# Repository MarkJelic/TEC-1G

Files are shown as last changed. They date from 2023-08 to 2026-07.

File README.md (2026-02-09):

## File Links
| File | Description | Version |
|---|---|---|
| [Errata](./Errata.md) | <b>*CRITICAL:*</b> The latest Errata announcements. **Read BEFORE assembly!** | 2/jun/2024 |
| [Assembly Instructions](./Documentation/Assembly/Readme.md) | Instructions on putting the TEC-1G together | 0.2 |
| [Component Overlay](./TEC-1G_Component_Overlay_v1-21.pdf) | Searchable PDF for component placement. | 1.21 |
| [Parts List](./TEC-1G_PartsList_v1-5.pdf) | (Out of date. Needs updating. Use with caution. Always follow schematic.) | 1.5 |
| [BOM Sourcing](./files/TEC-1G_BOM_v1.5.xlsx) | (Out of date. Needs updating. Use with caution. Always follow schematic.) | 1.5 |
| [Schematic](./TEC-1G_Schematic_v1-22.pdf) | See what makes the TEC-1G tick. | 1.22 |
| [PCB Gerbers](./TEC-1G_Gerbers_v1-50_SigEd.zip) | Gerbers of the PCB so you can print your own! | 1.50 |
| [Monitors / ROMs](./ROMs/) | Download and burn the ROMs for your TEC-1G from this link! | 1.6 |
| [MON3 User Guide](./MON3_User_Guide_v1-6.pdf) | The comprehensive User Guide to MON3 | 1.6 |
| [TEC Deck](./TEC-Deck/) | The TEC Deck has multiple Cards that add major functionalityto the TEC-1G! | 1.2 |
| [GPIO Modules](./GPIO/) | See what modules can be attached to the GPIO connector on the LHS of the TEC-1G | 1.0 |
| [TEC Expander](./Expander/) | The Expander finally has the 8x8 LED Array... And it's in RGB! | 1.0 |

## News & Developments

We have added a new section to the GitHub that agregates all the news and new items for the TEC-1G. [Follow this link](https://github.com/MarkJelic/TEC-1G/tree/main/News) for all the latest info.

# TEC-1G Introduction

TEC-1G - A Z80 based single board computer.

The TEC-1G is a direct descendant of the Talking Electronics Computer, known as the TEC-1, which was first published by the Australian electronics hobbyist magazine ["Talking Electronics"](https://www.talkingelectronics.com/te_interactive_index.html) (or simply TE), between 1981 and 1991.

The TEC-1 was developed as a learning computer, designed to teach the basics of how a microprocessor works at the fundamental hardware and software level, and offered the ability to create and run simple programs in Z80 machine code. TE magazine covered the TEC-1 in six installments, known as "Issue 10" to "Issue 15". These magazines can be downloaded freely from the TEC-1 GitHub, located at [tec1group/TE-Magazines](https://github.com/tec1group/TE-Magazines)

Interest in the TEC-1 declined following the winding down of TE through the 1990's, which reflected a general decline in electronics as a hobby in Australia. This, coupled with interest in more advanced 'single chip' microcontrollers saw TEC-1's put aside and the world moved on.

The TEC-1 was revived around 2018 with a release of a reproduction PCB and related peripherals on the Internet. Retro computing has become quite popular of late, and so a an active TEC community has (re)formed through [Facebook](https://www.facebook.com/groups/tec1z80) with new hardware designs, enhanced versions and various expansion options being offered by various contributors within the community.

The 1G builds on both the TEC-1's base and recent history to modernize the overall design, address various design limitations and integrate many of the excellent add-ons into to a single PCB for the first time.

The TEC-1G remains true to the original TE design goals: it is is built using only simple through-hole TTL logic chips so it is easily built and understood by the hobbyist. For the first time, the TEC-1G will also be fully free and open source, in both its hardware and software. The TEC-1G is the ultimate TEC-1!

The 1G has been developed by Mark Jelic with the input of the original designers, John Hardy and Ken Stone, ex-TE staff member Craig Hart, along with contributions from community members Brian Chiha and Ian McLean. Finally, the 1G has also been produced with the blessing of Colin Mitchell, Talking Electronics owner.

## Major Features

- Full TEC-1 hardware and software compatability; runs all previous MONitors without modification
- Flexible memory options; 32K RAM, 16k ROM in default configuration. Up to 64k RAM + 16k ROM supported.
- Support for multiple configuration options and memory types from 2k to 32k memory devices
- RAM write protection for improved software development
- Shadow Memory and bank switching capabilities
- 20x4 LCD screen as primary display device
- Diagnostic & LED bar indicator for system state
- Z80A CPU running at 4.0MHz; 'slow' clock support for older monitors retained
- Full QWERTY MATRIX keyboard & joystick options
- Upgraded key options for onboard hex keypad; supports Gateron Low Profile switches with optional backlighting, as well as standard 12mm tactile buttons
- Improved RESET circuit for reliable start up and system stability
- USB B or 9-12v AC/DC power sources
- Serial interface using an optional FTDI/FT232 adaptor for USB communication with a PC or terminal
- Future support for SD card mass storage interface
- Native Z-80 expansion bus connectors supporting a full range of peripherals
- 'TEC-Deck' expansion connectors for future daughterboards
- 'TEC Expander' port for compatability with existing TEC peripherals
- HALT status LED

## More Documentation [Coming Soon™](/Documentation/readme.md)

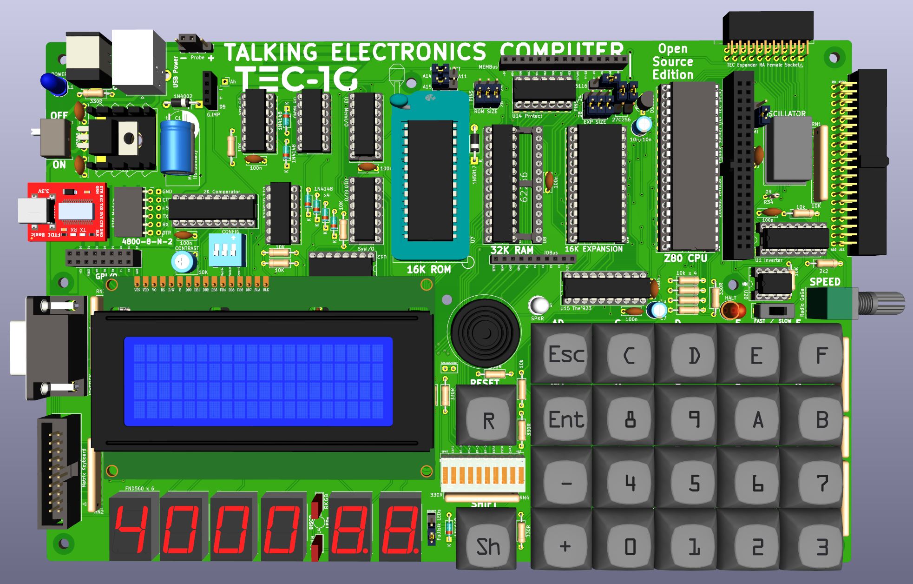
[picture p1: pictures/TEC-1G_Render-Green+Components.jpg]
TEC-1G Render - Gateron Keys


I'd like to thank PCBWay for sponsoring the ongoing development of modules that are being added to the TEC-1G ecosystem. I'm impressed how proactive they are in finding projects like this one and encourage and foster such development. Thank you, PCBWay!

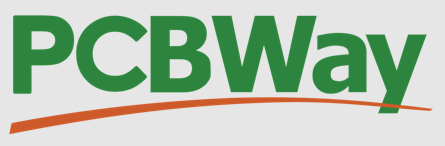
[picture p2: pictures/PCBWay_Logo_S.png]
PCBWay Logo


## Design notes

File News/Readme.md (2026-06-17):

# TEC-1G News
--------------------------------------------------------
## TMS9918 Video Card in Beta Testing (15/Jun/2026)
A video card based on the TMS9918 that sits on the TEC-Deck connectors has entered Beta. "Damian Damian" built it up quick smart and after some cutting and bodging, was able to show a couple of demos.
Check it out on this Facebook post:

https://www.facebook.com/share/v/1BiCaWHnK5/

More details can be had here where you can download the Gerbers and print your own PCB:

https://github.com/MarkJelic/TEC-1G/tree/main/TEC-Deck/TMS9918_Video

Kits for this add-on have not been planned for, at this stage.

--------------------------------------------------------
## 4Layer Version of Main PCB in Testing (21/May/2026)
The first ever 4 layer version of the TEC-1G PCB has arrived and going through testing.

Features include:
 - ability to use either through-hole or SMD versions of components like resistors, capacitors, diodes, transistors and IC sockets.
 - Four layers of copper, two of which are inside the PCB and a ground planes to provide shielding.
 - Thinner tracks and optomised routing since the GND traces are all but gone to the inner GND copper pour.

Once testing is complete, users will have the choice of the original 2 layer PCB which has proven to be pretty noisy for any audio amplfication, or the new 4 layer PCB, which does cost more, but has improved noise suppression.

Longer term plans include providing kits that have all the SMD components pre-installed, in the hopes of cutting the build time down from 3-4 hours, down to 20-30 minutes.

--------------------------------------------------------
## Official TEC-1G 3D Printable Case (10/March/2026)
The official TEC-1G case is made available. Purchase it in digital form for printing on your own #D printing machine or buy it on the Tindie Store which includes the brass heat insets.

https://www.tindie.com/products/tec1/tec-1g-official-case/

--------------------------------------------------------
## Update to Signature Edition PCB Released! (10/Feb/2026)
The Signature Edition PCB has been updated to v1.5 with a few minor quality of life (read: less soldering) changes.

https://www.facebook.com/groups/tec1z80/permalink/2288069601702076

--------------------------------------------------------
## Multi-Tasking on the TEC-1G! (27/Oct/2025)
Brian Chiha releases a video showing the TEC-1G doing effective multi-tasking!

https://youtu.be/tMYGlYO3v9U

--------------------------------------------------------
## A new version of the Tactile Matrix Keyboard! (19/Aug/2025)
A new version of the Tactile Matrix Keyboard has been release to give the user a better typing experience and move the connector to the side so that cable tangles are a thing of the past.  Stickers have also been developed and are available to buy on Tindie.

https://www.tindie.com/products/tec1/tec-1g-matrix-tactile-keyboard/

--------------------------------------------------------
## Signature Edition Gerbers Released! (15/Mar/2025)
The Signature Edition of the TEC-1G PCB is the final version of the TEC-1G PCB to be released.
The Gerbers can now be downloaded from the root directory of the Repo.

--------------------------------------------------------
## ODE to TEC-1G Song! (12/Mar/2025)
Ken Stone has applied his masterful Musical and AI-Wrangling skills to turn John's poem into a catchy song!

https://github.com/MarkJelic/TEC-1G/blob/main/News/ODE_to_TEC-1G_by_John_Melville_(Ken_Stone).m4a

--------------------------------------------------------
## ODE to TEC-1G by John Melville (11/Mar/2025)
John has penned a brilliant poem about the 1G. Check it out:

https://github.com/MarkJelic/TEC-1G/blob/main/News/Ode_to_1G.md

--------------------------------------------------------
## TEC-1G RGB 8x8 Display (10/Mar/2025)
The first add-on ever developed for the original TEC-1 was an LED 8x8 Matrix Display. 40 years later and the same idea has had new life breathed into it with a full colour RGB module in the tidiest PCB yet design for the 1G, that allows for up to 3 modules chained together. Check the details at<br>

https://github.com/MarkJelic/TEC-1G/tree/main/Expander/8x8

--------------------------------------------------------
## TEC-1G Font Identified! (24/Jun/2024)
The mystery of which font goes into making the iconic TEC-1G logo has been solved by James Elphick.  At first we thought it might have been Posterama 1984 but that is owned by one of the oldest font foundry, Monotype.  James soon found a very close competitor in Montserrat-Alt1 and it is an Open Font typeface.  So in aligning with our ethos, we must have used the Open Source version and we have copied it to this GitHub, in the \Assets folder off the root:<br>

https://github.com/MarkJelic/TEC-1G/tree/main/Assets

--------------------------------------------------------
## Fullisik Mechanical Matrix Keyboard Released! (18/Jun/2024)
Designed by James Elphick, following the design of the Tactile Matrix keyboard, the new Fullisik Mechanical Matrix Keyboard goes on sale today, and is sold out befor the weekend is done! Looks and feels fantastic.

--------------------------------------------------------

## MON3 version 1.5 (7/Jun/2024)
Monitor3 has been upgraded to version 1.5 by Brian Chiha. Get all the details here:<br>
https://github.com/MarkJelic/TEC-1G/tree/main/ROMs/MON3

--------------------------------------------------------
## 7 Segment Bezel by "Fred Nichols" (3/May/2024)

Now this is really cool! Fred Nichols has created a 3D printable Bezel that sits over the 7 segment displays. He has kindly released the STL files so you can download it and print it yourself or get a shop to do that for you. Either way, it makes the TEC-1G look really fancy! [Click on this link](https://github.com/turbo-gecko/TEC/tree/main/3D%20Printing/7%20Seg%20Bezel) to take you to his GitHub!

7Seg Bezel 3 Piece Lit

--------------------------------------------------------
## Dedicated TEC-1G Video Channel Launched (27/Apr/2024)
Yes, we know the documentation isn't complete, and even if it were, there are many amongst us that don't do well learning anything by reading text on a screen. Some of us (raises hand) are visual learners and so videos work well for seeing how things are put together.

And that is exactly what the channel will be about. We will announce new upcoming products, have demos of peripherals available for the TEC-1G, highlight any really cool code released by you, the users, and have documentary type videos showing exactly how any board is put together.

We look forward to your feedback and let us know what you would like to see.

https://www.youtube.com/@TEC-1G

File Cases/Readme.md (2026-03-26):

# Cases, Enclosures and Stands

Sick of having you TEC-1G lying on the cold hard bench, with all your tools and parts shorting the underside?

Want to display your beautiful TEC-1G in the best light possible so your friends and family will go "Ooh" and "Ahh" at your cleverness?

Have a 3D printer that has you wondering what you can do with it?

Question no more and pick your favourite design below, download the STL file and elevate your TEC-1G to the height it deserves!

## Stands & Cases Links
| File | Description | Preview |
|---|---|---|
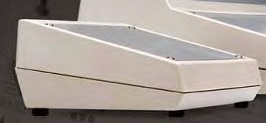
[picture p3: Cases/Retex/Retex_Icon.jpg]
Retex
| [Retex](./Retex/Readme.md) | The original case for the TEC-1 works on the TEC-1G and is still available! |  |
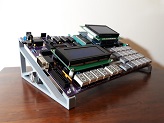
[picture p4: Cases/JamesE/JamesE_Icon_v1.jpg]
JamesE
| [JamesE](./JamesE/Readme.md) | A pair of Stands to elevate your TEC-1G to new heights |  |

If you have the superior brain-power required to create 3D models and have designed something for the TEC-1G,
why not share it with the greater community? You will get your own dedicated page on this GitHub, with full credit to you,
and a permenant place in the history of the TEC-1G. Get in touch with us via our [Facebook Forum](https://www.facebook.com/groups/tec1z80).

### NEWS FLASH:
There is now an OFFICIAL TEC-1G 3D printable case that looks the bees knees and can hold the UPS Battery Pack, as well!
Purchasable as both the physical, printed item delivered to your door, or as a Digital Download for personaly printing.
https://www.tindie.com/products/tec1/tec-1g-official-case/

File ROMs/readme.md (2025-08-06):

## File Links
| File | Description | Version |
|---|---|---|
| [Monitor 3](./MON3/) | The new main Monitor for the TEC-1G written by Brian Chiha| 1.6 |
| [Diagnostics](./DIAGs/) | Test the functionality of your TEC-1G, by Craig Hart | 1.1 |
| [BMON](./BMON/) | Run the first monitor that Brian Chiha adapted for the TEC-1 | 1.3 |
| [MON-1B](./MON1/) | The original, hand-coded monitor for the TEC-1 by John Hardy | 16K |

# ROMs for the TEC-1G

The file list above gives you links to the individual monitors that you can quickly copy to an NVRAM chip
and pop them into the TEC-1G, without having to play around with the ROM size switches.

You can also download the "combined images" that include:
 - 32k has MON-3 and DIAGs
 - 64k has MON-3, DIAGs and MON-1B. (16K is left blank for upgrades.)

## Older ROMs

The TEC-1G is perfectly backward compatible with previous monitors and the 2k/4k ROMs they came on.
To use an old TEC-1 ROM, since they were burnt to either a 2k or 4k ROM in a 24pin package, you simply plug the 24 pin ROM into the upper part of 28pin ZIF socket. See the picture below.
ROM_Select

To enable the 1G to use a 24 pin chip (in either the ROM ZIF, or in the EXPAND socket) you need to set the three Chip Size jumpers appropriately. Move all three jumpers to the top positions for 24 pin chips, and have the jumpers down for 28 pin chips.

The Hi/Lo switch works the same as the original TEC-1, allowing you to select the top half or bottom half of a 4k or 32k ROM.

The images for the 2k / 4k ROMs can be found here on GitHub, but since the 1G now has the space for 32k & 64k ROM chips, we have recompiled the old monitors into 16K file sizes that allows for easy "combining" on burners like the GQ-4x4.

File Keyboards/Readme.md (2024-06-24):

# Keyboards for the TEC-1G

## History
The TEC-1 came out in 1983 and I eagerly built it, and coded many of the samples and even made my own maze game all entered by hand on, lets face it, the crappy mushy keyboard with the terrible layout. 

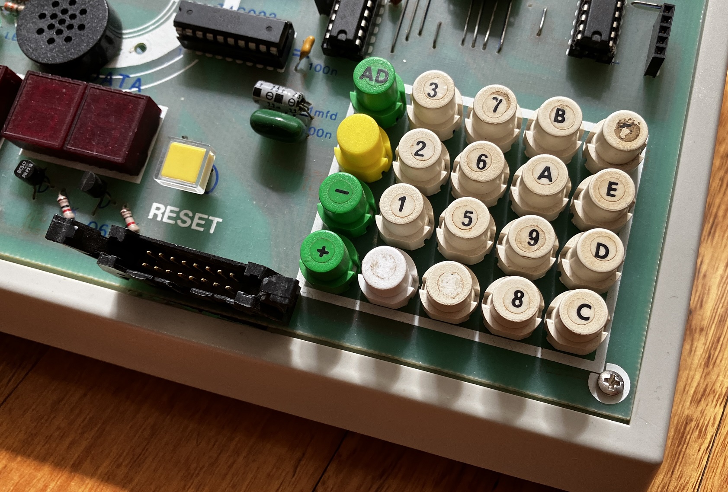
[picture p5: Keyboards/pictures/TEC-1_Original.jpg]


I didn't stand for it for too long before I made my own keyboard out of full sized keys, and hacked in a connector on the motherboard. Still only in hex, but man it made a difference!

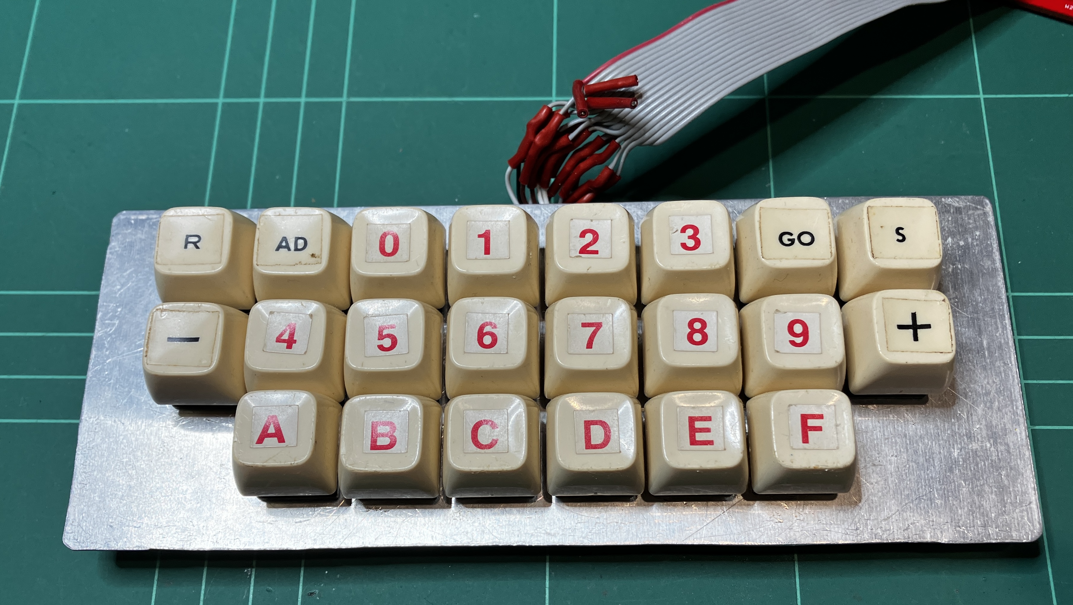
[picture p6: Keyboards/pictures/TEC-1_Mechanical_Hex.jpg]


Fast forward 40 years and the TEC-1G was NOT going to have crappy keys any longer! Discussions with another Keyboard officiando, Ian McLean came to making space on the TEC-1G motherboard to fit full-zized mechanical keys.  We chose to use the Gateron Low Profile 2.0 keys as they were a lot less obtrusive compared to the normal Cherry MX keys. Unfortunately the footprint of the Gateron Low Profiles is NOT the same as a standard MX key, so keep that in mind when buying your key switches.

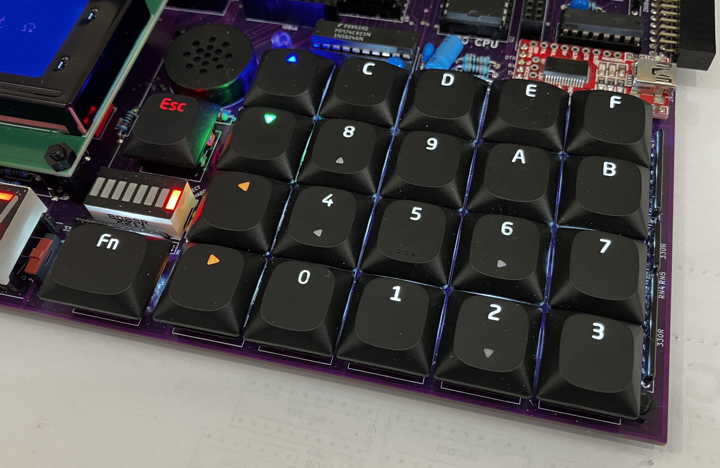
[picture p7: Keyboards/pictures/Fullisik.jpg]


You can purchase the Gateron LP Switches [direct from the Gateron site](https://www.gateron.com/products/gateron-ks-33-low-profile-switch-set?VariantsId=10265).

# QWERTY Keyboards
The TEC-1 never had a full qwerty keyboard option so with the TEC-1G development in mind, I set about finding a suitable interface and keyboard schematic that could be easily integrated into the TEC-1 and fit onto the base motherboard.

## Matrix Interface
The [Matrix Interface](https://github.com/MarkJelic/TEC-1_Hardware/tree/master/Z80Bus/Keyboard) made for the TEC-1 was essentially incorproated into the design of the TEC-1G. More details and code samples can be found on that page.

## The Tactile Keyboard
I created the Tactile version of the Matrix Keyboard that accepted 6mm and 12mm little tactile keys which aren't terrible and relatively cheap. You can get more details of how it was developed, and how to assemble it, [here](./Tactile/)

## The Mechanical Keyboard
The mechanical version of the matrix keyboard has been finished. Details, [here](./Mechanical/)

## Where to Buy
The Tactile Matrix Keyboard Kit can be found on the Tindie Store:  (https://www.tindie.com/products/tec1/tec-1g-matrix-tactile-keyboard/)

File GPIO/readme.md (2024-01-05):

# TEC-1G GPIO Connector

## Expansion Modules available for the GPIO Connector
| Module | Description | Version |
|---|---|---|
| [GPIO Protoboard](./Protoboard/) | The protoboard gerbers & design files - Use as a Template!  | 1.1 |
| [GPIO SD Card](./SD-Card/) | Micro SD-Card interface, as well as a general purpose 8Bit input/output board | 1.2 |
| [GPIO RTC](./RTC/) | Real Time Clock and Parameter RAM  | 1.1 |
| [GPIO Printer](./Printer/) | Parallel Printer Interface, and a general purpose 8Bit input/output board  | 1.1 |

Adding General Purpose Input/Output capabilities to the TEC-1G, easily.



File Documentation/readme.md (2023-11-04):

[Assembly Instructions](./Assembly/Readme.md)

# Full Documentation - Coming Soon™

When designing the TEC-1G, several principals were kept foremost in mind:

1. Must remain compatible with the Talking Electronics TEC family. Older MONitors must run, unchanged, on the new hardware.
2. Existing peripherals must work, where sensible to do so*. Peripherals such as the DAT board, RAM stack & Crystal Oscillator are now part of the base design, as is the MON select switch. The 8x8 LED display, speech module, relay driver board, and the input output module all work.
3. Must address design limitations inherent in older models e.g. memory wrap, lack of IO port selects, elminate 'flying wires', use robust connectors, offer modern interfacing and expansion options.
4. Must remain simple to understand. This forbade the use of fancy custom chips. Everything is built from simple 74xx series logic, that can be understood at the fundamental level.
5. Through-hole construction to be retained. Must be buildable by a hobbyist without specialist tools.
6. Must enable modern software development - adequate RAM, PC serial link, full QWERTY keyboard are must-haves.
7. Existing TEC software should run with as litte alteration as possible.
8. The whole machine will be produced under an open source licence, freely distributable. Source code, schematics, gerbers etc. will all be made available and fully documented. This represernts the first time TEC system software has been freely distributed.
9. The classic, look, feel, operation and overall "vibe" of the TEC heritage must remain obvious. This heritage has informed the PCB layout, for example.

We think we have achieved these goals and produced a TEC that will offer much more value and usability today, compared to the rather limited original machine.

> We decided not to support the EPROM burner or NVRAM add-ons. EPROMs are now largely replaced with EEPROMS and dedicated programmers like the TL866 are cheap and readily available, and do a much better job. The printer/plotter module no longer has the plotter hardware avilable. NVRAM can be plugged directly into the 1G, however we have not allowed for battery backup at this time. 

## Major Features

- Full TEC-1 hardware and software compatability; runs all previous MONitors without modification
- Flexible memory options; 32K RAM, 16k ROM in default configuration. Up to 64k RAM + 16k ROM supported.
- Support for multiple configuration options and memory types from 2k to 32k memory devices
- RAM write protection for improved software development
- Shadow Memory and bank switching capabilities
- 20x4 LCD screen as primary display device
- Diagnostic & LED bar indicator for system state
- Z80A CPU running at 4.0MHz; 'slow' clock support for older monitors retained
- Full QWERTY MATRIX keyboard & joystick options
- Upgraded key options for onboard hex keypad; supports Gateron Low Profile switches with optional backlighting, as well as standard 12mm tactile buttons
- Improved RESET circuit for reliable start up and system stability
- USB B or 9-12v AC/DC power sources
- Serial interface using an optional FTDI/FT232 adaptor for USB communication with a PC or terminal
- Future support for SD card mass storage interface
- Native Z-80 expansion bus connectors supporting a full range of peripherals
- 'TEC-Deck' expansion connectors for future daughterboards
- 'TEC Expander' port for compatability with existing TEC peripherals
- HALT status LED

## Documentation Files

[Circuit Functional Description](Functional%20Description.md)

[Z80 IO Ports](ioports.md)

[Memory Map](memmap.md)

[Expansion and Device Connectors](connectors.md)

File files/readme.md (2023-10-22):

General store of files, including ones that are "archived" (like the schematic) to have a history of changes over time.

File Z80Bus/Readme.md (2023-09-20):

# Z80Bus Expansion Options for the TEC-1G

With the release of the Z80Bus Standard, including the KiCAD footprints and Gerbers so people can print their own Z80Bus system board, modules for the TEC-1 can very quickly and easily be developed that allow the USER to choose how they wish to connect the modules to their machines.

Boards designed with the innovative <b>IDC<sup>2</sup></b> connector footprint allow the user to choose to go hippie and continue to use ugly IDC cables with a Vertical IDC Box Header, or with a Right Angled Box Header, they have the ultimate in freedom to connect using IDC cables, <b>Quick-Connect<sup>®</sup></b> direct to the TEC-1, or using the <b>X4 System</b> and have multiple expansions boards all working in unison.

## [Z80Bus X4 Board](X4/Readme.md)
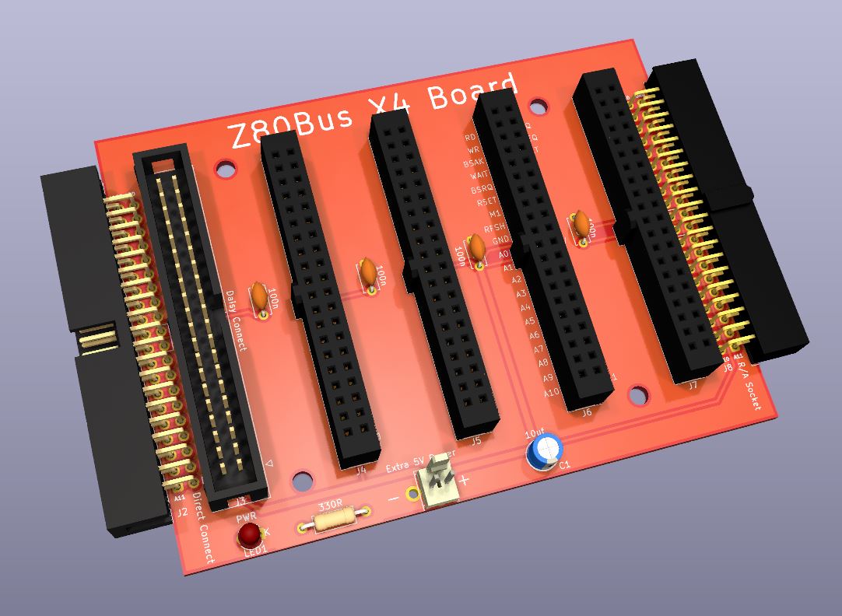
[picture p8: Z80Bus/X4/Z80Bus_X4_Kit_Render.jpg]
Render


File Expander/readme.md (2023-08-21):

# TEC Expander

The easy way to attach your favourite expansions.



## Coming Soon™
- 8x8 LED Matrix

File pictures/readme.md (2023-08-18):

Pictures of renders, prototypes and assembled versions of the TEC-1G.

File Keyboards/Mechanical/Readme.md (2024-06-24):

## Fullisik Mechancial Matrix QWERTY Keyboard

Designed by James Elphick

## File Links
| File | Description | Version |
|---|---|---|
| [BOM](TEC-1G_MechMatrix_BOM_v1.0.xlsx) | Bill of Materials |1.0|
| [Assembly Instructions](TEC-1G_Mechanical_Matrix_Keyboard_Build_Guide.docx) | Instructions on putting the keybaord together | 1.0 |

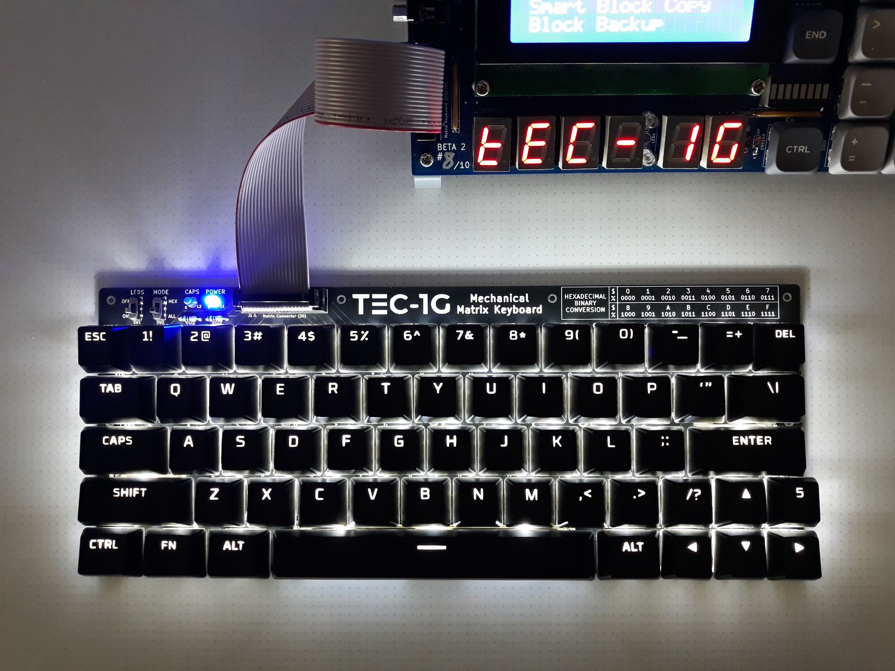
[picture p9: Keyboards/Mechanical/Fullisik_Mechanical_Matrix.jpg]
Mechanical Matrix


Kit is available on Tindie: https://www.tindie.com/products/tec1/tec-1g-matrix-mechanical-keyboard/

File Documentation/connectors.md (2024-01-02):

# TEC-1G Connectors
This is a list of TEC-1G expansion port connectors and their respective pin-outs.

A note on PCB connector orientation markings. Pin 1 is identified as the pin that is not within the solid connector outline on the silkscreen, but instead has a small L on one corner, or is individually outlined. Pin 1 also has a square solder pad, the other pins are round. Lastly, the label of the connector (eg. J1) is usually placed as close as possible to Pin 1.

## J1 - Z80 Bus Vertical Connector
Follows the Z80 CPU pinout i.e. pin 1 - A11, pin 2 - A12, etc. Except for one small difference; Pin 28 is NOT the usual Refresh pin, since that function is largely not used in any modernised Z80 computers. Pin 28 has instead been repurposed for the use of the GLCD as an Inverted RD line from the Z80. 

## J2 - Z80 Bus Horizontal Connector
Follows the Z80 CPU pinout i.e. pin 1 - A11, pin 2 - A12, etc.  This connector should ideally be a female connector to allow for direct connection of expansion cards, or the X4 Expansion Board, and IDC cables can still be connected if the user desires.

## J3 - TEC Expander
This 20 pin port is an extension of the 16 pin IO port of the Southern Cross Computer. Any peripherals made for the SCC can be plugged into the left (first 16) pins and work as intended.

The extra 4 pins have been added so peripherals like the Speech Board can be re-implemented fully, using only a single connector.

1 - +5v  
2- /RESET  
3 - 8x8 Port 05h select  
4 - 8x8 Port 06h select  
5 - Port F8h select  
6 - Port F9h select  
7 - GND  
8 - GND  
9 - D4  
10 - D3  
11 - D5  
12 - D2  
13 - D6  
14 - D1  
15 - D7  
16 - D0  
17 - /WR  
18 - /WAIT  
19 - CLK  
20 - /INT  

## J4 - MATRIX Keyboard
This port is for connecting the external Matrix Keyboard & Joysticks.

## J5 - FTDI
FTDI offers two options - pins orientated left-to-right, and right-to-left. This is because there are two common types of FTDI module - fit the connector that suits your type of FTDI module. Pin orientations are clearly maked on the PCB silkscreen.

DTR - not used<br>
RX - Receive Data<br>
TX - Transmit Data<br>
+5v - not used<br>
CTS - not used<br>
GND - Common Ground<br>

## J6 - IObus
Schematic Rev 1.6+

1 - GLCD-07 - Inverted Port 07h select - Reserved for future Graphical LCD<br>
2 - /PORT-F8 - Port F8h select<br>
3 - /PORT-F9 - Port F9h select<br>
4 - /PORT-FA - Port FAh select<br>
5 - /PORT-FB - Port FBh select<br>
6 - /PORT-FC - Port FCh select<br>
7 - /PORT-FD - Port FDh select<br>
8 - CART - CARTridge Detect<br>
9 - GIMP - General Input<br>
10 - /GLCD-07 - Port 07h select - Reserved for future Graphical LCD<br>

Ports F8h to FDh are free for any use by the user. Note that Ports F8h and F9h are also available on the TEC Expansder Connector.

## J7 - MEMbus
Schematic Rev 1.6+

1 - +5v
2 - /MS8 - Memory Bank 3 Select - does not observe SHADOW<br>
3 - /ROM_CS - Observes SHADOW - First 2K and Bank 3<br>
4 - /SHADOW<br>
5 - /MS2 - Memory Bank 0 Select - does not observe SHADOW<br>
6 - /MS4 - Memory Bank 1 Select - does not observe SHADOW<br>
7 - /RAM_CS - Observes SHADOW - Banks 0 and 1 only<br>
8 - PROTECT<br>
9 - /MS6 - Memory Bank 2 Select - does not observe SHADOW<br>
10 - EXPAND<br>
11 - FF-D3 - System Latch bit 3<br>
12 - FF-D4 - System Latch bit 4<br>
13 - FF-D5 - System Latch bit 5<br>
14 - FF-D6 - System Latch bit 6<br>
15 - GND<BR>

## J8 - G.INPUT
1 - GND<br>
2 - +5v<br>
3 - G.INPUT signal - SIMP-3 bit 5<br>

## J9 - JOYSTICK
The joystick port adheres to the ATARI joystick standard, supporting two fire buttons.

1 - Up<br>
2 - Down<br>
3 - Left<br>
4 - Right<br>
5 - <br>
6 - Button A<br>
7 - Button B<br>
8 - Common<br>
9 - <br>

## J10 - GPIO
This is where the SD Card, Real Rime Clock, and General Input/Output cards will be stacked.

## PROBE
This set of connectors have a 2 pronged purpose; The outer male pins are for connecting Oscilloscope or Multimeter probes to, for measuring and testing purposes. The pair of inner pins, fitted with a 2-pin female header, is used for alternate power delivery, as well as a power take-off point for the boards connected to the J10 - GPIO connector.

## LCD1
Connector for a standard HD44780 LCD display. TEC-1G expects a 20x4 display, but any HD44780 based screen will work.

1 - GND  
2 - +5v  
3 - Contrast (10k trimpot)  
4 - RS (A7)  
5 - R/W (RD)  
6 - E  
7 - D0  
8 - D1  
9 - D2  
10 - D3  
11 - D4  
12 - D5  
13 - D6  
14 - D7  
15 - Backlight A  
16 - Backlight K (GND)  

# Connector <-> IO Port assignment
This chart shows which Z-80 I/O port select lines are available on each I/O connector.

| Connector | 05h | 06h | F8h | F9h | FAh | FBh | FCh | FDh | FEh | FFh |
| -- | -- | -- | -- | -- | -- | -- | -- | -- | -- | -- |
| IObus |  -- | -- | YES | YES | YES | YES | YES | YES | -- | -- |
| TEC Expander |  YES | YES | YES | YES | -- | -- | -- | -- | -- | -- |
| GPIO |  -- | -- | -- | -- | -- | YES | YES | YES | -- | -- |
| TEC-1G |  -- | -- | -- | -- | -- | -- | -- | -- | YES* | YES* |

\* Used on the TEC-1G mainboard internally. Not available for expansion boards.

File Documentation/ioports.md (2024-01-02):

# TEC-1G Z80 I/O Ports

The following technical documentation describes the general layout of the TEC-1G's Z80 CPU I/O ports, as accessed by the IN and OUT instructions.

If you are looking for physical pinouts of the TEC-1G port connectors, please refer to other documentation from the index.

## TEC-1 Compatable IO Ports

** Note that the IO port decoder chip for ports $00 to $07 does not check bit D7 - hence I/O ports $00 to $07 are also available as ports $80 to $87. This is for various 2-port devices like the LCD and GLCD, as well as older model TEC compatability.

### Port 00 - Keyboard data input
 - bits 0-4 - binary keypressed value from the 74c923 chip
 - bit 5 - Shift key status
     - 0 = Shift Key Pressed  
 - bit 6 - not connected
 - bit 7 - not connected

### Port 01 - 7-seg display select & speaker output
 - bits 5-0 selects each 7-segment display, bit 5 = left, bit 0 = right
 - bit  6 - FTDI serial output
 - bit  7 - speaker output

### Port 02 - 7-seg segment select output
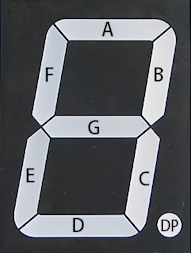
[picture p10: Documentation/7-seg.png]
7-Seg display segment layout


 - bit 0 - segment a
 - bit 1 - segment f
 - bit 2 - segment g
 - bit 3 - segment b
 - bit 4 - decimal point
 - bit 5 - segment c
 - bit 6 - segment e
 - bit 7 - segment d

### Port 03 - General SIMP Input
 - bit 0 - config bit 0 - Matrix
     - Matrix keyboard enabled for use in MON-3
 - bit 1 - config bit 1 - Protect
     - Memory protection enabled in MON-3
 - bit 2 - config bit 2 - Expand
     - Indicates which half of a 32k memory device installed in Bank 2, MON-3 should enable by default
 - bit 3 - EXPAND
     - Indicates which half of a 32k memory device installed in Bank 2 is presently selected
 - bit 4 - CART
     - 0 = a ROM/RAM cartridge is installed. Read from IOBUS connector
 - bit 5 - GIMP
     - General purpose input-bit, connected to G.INPUT pin
 - bit 6 - KDA
 -   - 0 = 74c923 key is pressed
 - bit 7 - FTDI serial input

### Port 04 - LCD Display command
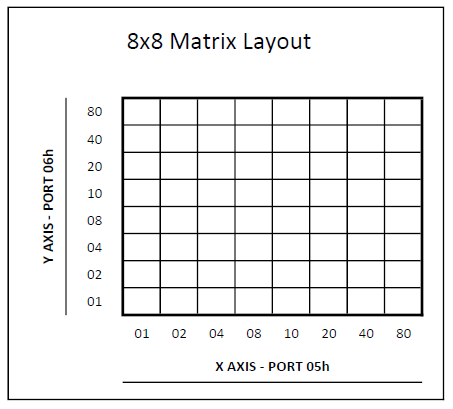
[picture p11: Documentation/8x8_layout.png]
8x8 display port layout

 - bits 0-7 - LCD command register

### Port 84h - LCD Display data
 - bits 0-7 - LCD data register

### Port 05 - 8x8 X axis display latch
X axis

Bit 0 is the left most column

### Port 06 - 8x8 Y axis display latch
Y axis

Bit 0 is the bottom most row

### Port 07 - GLCD port
 - Reserved for future 128x64 Graphic LCD

** Ports $80 to $87 are duplicates of ports $00 to $07.

## TEC-1G New Ports
These are new additions to the 1G, not found in previous TEC models.

### Port FCh - GPIO Real Time Clock
Reserved for DS1302 RTC chip

### Port FDh - GPIO SD Card
Default port for SD Card adaptor

### Port FEh - Matrix Keyboard Input
** This port is used to read the state of the matrix keyboard, to determine if a key is being pressed or not. See the section on the Matrix keyboard for more details on how to use port FEh correctly.

 - bits 0-7 - key state

### Port FFh - System Latch
** This register defaults to $00 at power-on and reset.
** this is a write-only register, however key status bits can be read from the SIMP input port to determine the current system configuration state.

** Each bit of this port is also represented on the LED STATUS bar, with bit 0 being rightmost. Note that bit 0, being active low, will be lit at power-on and reset.

 - bit 0 - /SHADOW
     - 0 = Shadow enabled. The first 2k of ROM at $C000 is also mapped to $0000 - $07FF for backwards compatibility with old MONitors.
     - 1 = Shadow disabled. The full 32k of RAM is avlilable from $0000 to $7FFF
 - bit 1 - PROTECT
     - 0 = RAM memory operates as normal read/write memory
     - 1 = Bank 1 of RAM memory ($4000 to $7FFF) is write-protected
 - bit 2 - EXPAND
     - controls which half of a 32k memory device installed in Bank 2 is presently selected. Defaults to the lower half at power on
 - bit 3 - FF-D3 - The next 4 bits are most likely going to be used for Paged Memory expansion, allowing for up to 512k extra memory.
 - bit 4 - FF-D4 - But they are open to be used as users see fit when designing TEC Decks.
 - bit 5 - FF-D5 - Possible Paged Memory use.
 - bit 6 - FF-D6 - Possible Paged Memory use.
 - bit 7 - CAPS
     - This bit relates to the Matrix keyboard
     - 0 - Caps lock is OFF
     - 1 - Caps lock is ON

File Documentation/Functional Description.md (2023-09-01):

# TEC-1G Functional Description

Also known as "how it works".

When designing the TEC-1G, several principals were kept foremost in mind:

1. Must remain compatible with the Talking Electronics TEC family. Older MONitors must run, unchanged, on the new hardware.
2. Existing peripherals must work, where sensible to do so*. Peripherals such as the DAT board, RAM stack & Crystal Oscillator are now part of the base design, as is the MON select switch. The 8x8 LED display, speech module, relay driver board, and the input output module all work.
3. Must address design limitations inherent in older models e.g. memory wrap, lack of IO port selects, elminate 'flying wires', use robust connectors, offer modern interfacing and expansion options.
4. Must remain simple to understand. This forbade the use of fancy custom chips. Everything is built from simple 74xx series logic, that can be understood at the fundamental level.
5. Through-hole construction to be retained. Must be buildable by a hobbyist without specialist tools.
6. Must enable modern software development - adequate RAM, PC serial link, full QWERTY keyboard are must-haves.
7. Existing TEC software should run with as litte alteration as possible.
8. The whole machine will be produced under an open source licence, freely distributable. Source code, schematics, gerbers etc. will all be made available and fully documented. This represernts the first time TEC system software has been freely distributed.
9. The classic, look, feel, operation and overall "vibe" of the TEC heritage must remain obvious. This heritage has informed the PCB layout, for example.

We think we have achieved these goals and produced a TEC that will offer much more value and usability today, compared to the rather limited original machine.

> We decided not to support the EPROM burner or NVRAM add-ons. EPROMs are now largely replaced with EEPROMS and dedicated programmers like the TL866 are cheap and readily available, and do a much better job. The printer/plotter module no longer has the plotter hardware avilable. NVRAM can be plugged directly into the 1G, however we have not allowed for battery backup at this time. 

# Hardware Design Building Blocks

The TEC-1G can be broken up into several sections or *building blocks*, and each considered individually as to how it plays its role in the overall system.

Together, each building block forms the complete TEC-1G. Some building blocks such as the Matrix Keyboard are optional whilst others are essential.

If your 1G does not work, check each section in the order given below.

A special diagnostic ROM is being produced to assist wih problem solving if your 1G doesn't work correctly when first built. Much like the Commodore 64 'Dead Test' cartridge, the diagnostics software will produce a useful output even wthout any RAM, keyboard chips or the LCD fitted. This will allow for easier troubleshooting and also gives a degree of insight into the machine's operation.

## Power Supply

The TEC-1G is designed to be powered by an external USB +5v source; a USB-B socket for power only, is therefore provided. A classic TEC-1 style linear 7805 based power supply has also been provided, however its use is depreciated.

Power is switched automatically from USB to linear using a switch built into the linear power input socket BJ1 - as long as a plug is inserted into BJ1, linear power mode is selected. BJ1 is centre positive, in keeping with the most common standard for small DC plugpacks.

**The TEC-1G is also designed for DC power input only.** D0, the 1N4002 power diode, is only designed to protect against reverse polarity, and not to act as an AC rectifier.

The power on/off switch and indicator LED complete the power supply section.

Note that we strongly suggest a heatsink on the 7805 and some monitoring of its temperature. The 1G has more chips to power vs. a classic TEC-1, so the current consumption will be higher. The 1G PCB is also more crammed full of goodness so there is also less space for copper fill heatsinking as well. Reducing the input voltage from 12v to 8v or 9v will lower the 7805 temperature noticably.

It is suggested that a drop-in 7805 equivilant switching regulator be considered if USB power is not viable.

The Probe connector supplies power for a logic probe, and serves as the GND hookup point for an oscilloscope or multimeter. Probe can also be used as a feed-in source of an external +5v supply if the 1G is to be powered by an external source.

## CPU Clock Generation

CPU Clock is generated either by a crystal oscillator module, or the classic TEC-1 variable speed oscillator, built around U1, a 4049 hex inverter.

Clock mode is selectable with slide switch SW2 - Slow being TEC-1 variable clock, and FAST being the Crystal module. The selected signal is fed to the Z80 on pin 6, and can be checked with a logic probe or oscilloscope.

MON-3 is written with a 4.0MHz crystal in mind - which is the maximum clock speed of the Z80A CPU. This speed defines the FTDI serial baud rate, 7-seg scanning rate, sound note pitch and duration, etc.

The 1G has not been tested above 4.0MHz but should work OK at up to 8MHz with a Z80H CPU; however FTDI serial, timing etc. will be affected.

## CPU RESET Signal

The traditional R-C network for CPU RESET is offered as standard, however the option exists for using a dedicated power monitor/reset chip - the Dallas DS1233. Further more, the latch chips that rely on the RESET are now driven by a buffered RESET signal, provided by U5D.

RESET is active low, so the signal should be low when the RESET button is pressed, and high at all other times. Reset is fed to pin 26 of the Z80, and via U5D to pin 1 of the 74xx273 latches U13, U16 and U17.

## Z80 CPU

The Z80 CPU, U2, is configured identially to the TEC-1 and is quite conventionally set up. Any Z80 rated to at least 4.0MHz will work - NMOS or CMOS types both work, so Z80A, Z80B, Z80H, Z84C00x parts in 40-pin 5v DIP package, are fine.

An LED - L2 has been added to the HALT signal as an aid to troubleshooting and to provide and easy to monitor output for debugging purposes. the HALT LED should normally NOT light up duing MON-3 opreration.

The programmer can insert HALT opcodes where possible program trouble exists, and if the LED comes on, you can know that program flow reached a HALT point. Pressing a 74c923 key typically resumes program flow. This can be handy for quickly troubleshooting conditional JPs, for example.

## IO Decoders

U10 duplicates the TEC-1's traditional 74LS138 IO decoder, decoding IO ports 00 to 07. However the 1G has the addition of a diode OR-gate formed from D3,D4,D5, D6 and R12. The OR-gate ensures that no unwanted IO address wrap-around occurs. 

U11a and U12 work to decode IO address range F8h to FFh, in support of new onboard peripherals and future expansion.

## Memory Decoder & Memory Managment Unit

### Memory Address Decoders

U3 acts as a memory address decoder, providng select lines for eech 16k memory block.

D1, D2 and R11 form a NOR gate to create a select signal to the MMU indicating the bottom 32k is being accessed.

U4 acts as a 7-input comparitor, detecting if the bottom 2k of memory is being accessed: A11 to A15 must be all low, but only when /SHADOW is also active (also low). This signal is used as another input to the MMU.

If /SHADOW is low, U4 outputs (on pin 19) a low whenever memory in the first 2k 000h to 07ffh is accessed. If /SHADOW is high, the output is always high.

### Memory Management Unit (MMU)

U5A, B & C and U6 A, B & D form a simple MMU controlling the Bank 0, 1 and 3 /Chip Select lines for the memory chips U7 and U8.

Note that Bank 2 is not part of the MMU and appears at address 8000h to BFFFh at all times.

<Insert MMU truth table here>

## Memory Protection

U14 detects memory writes to bank 1 in combination with the PROTECT signal, and either passes or blocks the /WR signal to the RAM chip.

If PROTECT is high, /WR is held high when bank 1 is accessed. If /PROTECT is low, /WR is passed to the memory chip normally.

## ROM and RAM

U7 is the system ROM containing MON-3 or any earlier TEC monitor. This can be any (E)EPROM from 2k to 32k in size, and it is mapped to bank 3 at all times; the first 2k is also mapped to the start of bank 0 (0000h to 07FFh) when shadow is active.

The ROM SIZE Jumpers map the various address lines and the Hi/Low switch allows for TEC-1 Hi/Lo (MON1B/2) selection when a 4k 2732 chip is used; when a 32k chip is used it selects which half of the chip is mapped into Bank 3 (the other half of the chip is inaccessible).

If burning your own ROM, place older monitors at the start of the ROM, from 0000h onwards, so that they will be SHADOWed to 0000h.

U8 is the primary system ram, mapped to banks 0 and 1, and subject to the above SHADOW and PROTECT controls.

U9 is the expansion memory socket, and is mapped always into bank 2. Any memory chip from 8k to 32k can be fitted here; if a 32k chip is fitted then bankswitching using the EXTEND signal selects which half of the memory is mapped into bank 2 (the other half is inaccessible ; flip EEXTEND to ge tto the other half).

EXTEND has no affect if a memory device of less than 32k in size is fitted at U9, or if U9 is left vacant.

## HexPad Encoder

This part of the 1G is unchanged from the TEC-1. The 74c923 scans a matrix of 20 keys and generates a high on KDA when a key is pressed. Keyboard support is also identical to the TEC-1 with DAT board - bit 6 of port 03h holds keypressed status, thus allowing software polled keybord support. for this reason, the famous JMON resistor is not required.

Shift key support functions identially to the TEC-1, with bit 5 of port 00 reading a 0 when Shift is pressed, and a 1 if not.

Fulisik LEDs is a new feature of the 1G - if using Gateron keyswitches, LEDs can be fitted to backlight the keys; JP5 controls the backlights on/off. Resistor packs RN4, RN5, RN6 and 330R resistors R5 and R15 complete the LED current limiting. Refer to the assembly guide for suggested LED colours for each switch.

Note that RN4,5,6 & R5 and 15 can be omitted if not using backlighting.

## 7 Segment Display Unit

This unit is also largely unchanged from the TEC-1.

Latch chips U16 and U17 drive the 7 segment displays in a software-driven, scanned fashion. Each individual display is briefly selected and it's segments illuminated. After a brief pause, software then moves to the next display and repeats the process until all are lit. A loop repeats the whole sequence for as long as required. The illusion of constantly lit displays relies on a fast scanning speed and human persistance of vision. 

U17 drives the individual segments, whilst U16 selects the digits and also drives the speaker and FTDI Serial Transmit.

A simple transistor buffer ensures each display has an equal brightness level; no current limiting resistors are required as the output current of the latch chips is not sufficient to over-drive the LEDs.

The speaker features an LED to indicate when a sund is being produced, and can also act as a simple visual status indicator when driven by software.

A new 1G featue, is that pin 1 of the latch chips is driven by the buffered RESET signal. This ensures the displays start up blank, and also blane when RESET is pressed.

## LCD Connector

The 1G uses a similar interface idea to the TE DAT board, with support for any HD44780 chipset based LCD screen. However, we have settled on using a 40x4 display instead of the DAT's 16x2. The larger size screen offers more display space and these days is less expensive than the original 16x2's were in the 1990's.

Backlight power is also supplied, but can be disbled by cutting a marked trace on the rear of the 1G PCB. 'solder blob' pads have been provided to restore power if you wish to un-do this decision later - just solder the pads back together with a small blob of solder.

At the design level, the 1G inverts the CPU's /RD signal to generate the R/W signal for the LCD. This results in more favourable timing vs. the DAT board's use of an R-C network and the /WR signal. The LCD is more reliably detected and less prone to corruption using this method. We borrow one spare 4049 inverter gate from U1 for this purpose.

MON-3 will work with ANY size LCD e.g. 16x1, 16x2, 20x2 etc. but we strongly suggest that a 40x4 is used to obtain full functionality.

JMON will work with a 16x2 or 40x4 connected, with no issues. The HD44780 chipset is designed such that it's memory layout is identical regardless of the physical screen size.

## System Latch Port

A new 1G feature, is the system latch. It is an 8-bit write-only port that supplies 8 individual control signals to various parts of the 1G mainboard. The system latch is reset to 00h on power up or RESET.

U13 - 74xx273 provides the System Latch functionality and is written to at IO port FFh

The System latch controls /SHADOW,  PROTECT and EXPAND signls, as well as Caps Lock status for the Matrix keyboard. The status of the System Latch is reflected at all times in hardware by the STATUS LED Bar. Note that bit 0 is active low.

MON-3 routines manage the latch for you, however you can write to port FFh direclty if so desired.

## System Input Port

Another enhanced 1G feature, is the System Input port. Like the System Latch, it is an 8 bit port, however this port is read-only.

U18 - 74xx373 provides the Input port functionality and is readable from IO port $03

The Sytem Input port is used to read the status of the critical bits of the System Latch, as well as read the config dipswitch, G.INPUT and FTDI Serial Receive bits, and to detect the presence of a Cartridge (future feature).

## FTDI Port

The FTDI port acceps a standard FTDI module (purchased separately) that converts TTL signals from the 1G into RS-232, or, USB. This provides a simple software driven interface to a PC or a terminal, for data transfer or creating a 'dumb terminal'.

FTDI replaces JMON's tape routines as a backup system; MON-3 supports data transfer using Intel HEX format files and can also provide a full blown RS-232 serial terminal interface.

FTDI speed is limited to 4800bps as it is entirely software-driven and also relies on a 4.0MHz CPU clock for timing purposes. FTDI will not work with the TEC-1 slow clock.

## Matrix Keyboard and Joystick

Also new to the 1G, is a software scanned full QWERTY keyboard and two button joystick port.

U19 - 74xx245 buffers(not latches!) the keyboard matrix and is readable at IO port FEh; the matrix is scanned by use of a clever trick using the Z80 OUT (C),A instruction. In reality that instruction also places the contents of the B register onto A8-A15, creating effectively a 16 bit port.

Transistor buffers Q8 through Q15 buffer the address lines into the matrix, and any pressed key transmits that signal into U19 latch. note that a keypress is read as a 0 in any bit. Resistor arrays RN2 and RN3 ensure the no-pressed state is read as a logic 1.

The matrix connector also has facility for the Caps Lock signal to light a LED, and the Reset signal for an external reset switch.

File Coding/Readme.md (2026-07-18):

# Development Options for the TEC-1G

If you are wanting to get the most out of your TEC-1G, then just playing with other people's software isn't all there is to it.

The whole purpose of the TEC-1, from it's inseption, was to be a "learning computer", that would teach the user how computers work, 
and how to take full control of them. Knowing how to put the hardware together is one part of the process, but learning how to 
program the TEC-1 is even more important, as it is with any computer system. Without software, the computer is just a hunk 
of metal and plastic that won't do anything.

## Common Terminology and Tools
1. $\color{green}{\textsf{Code Editor}}$ 
2. $\color{green}{\textsf{Assembler}}$ 
3. $\color{green}{\textsf{Serial Terminal}}$ 

You create your code in the $\color{green}{\textsf{Code Editor}}$ like you do any text file, but of course it needs to be formatted in the correct way, and you must use the language the Z80 will understand. Once you have your program all typed in, you convert the (relatively) human-readable Assembler Code into the bytes of Machine Code that the Z80 actually understands. This conversion is done by the $\color{green}{\textsf{Assembler}}$ which it saves these bytes into the Intel .HEX file format on your hard drive. Inside the .HEX file is just text, but it has some aditional information like where in memory are the bytes it holds to be placed in the TEC-1G. The last task is to transfer that HEX file using a $\color{green}{\textsf{Serial Terminal}}$ via a USB cable to the TEC-1G.

## Code Editor

You can use just about anything as your code editor, as Z80 Assembly language is nothing more than a text file but with a .Z80 or .ASM file extension. So you could, if you like to suffer, use Notepad or TextEdit or even Word... But there are much better alternatives out there and dispite Microsoft trying really hard to ruin it, VS Code is a preferred option amongst many coders in many programming languages.

One of the best parts of VS Code are the myriad of Extensions available for it, and the ones we want are:
- Z80 Assembly by Imanolea. This colours your code to make it more readable, AKA Syntax Highlighting.<br>
<br>
- Z80 Macro-Assembler by mborik. A great helper for when you assemble your code.<br>
<br>

## Assembler

This is where the options really broaden out and everyone will have a favourite and it will be the hill they die on! It also very much depends on which OS platfrom you are on, as most are not cross-platform and many only have Windows binaries, which is disapointing.

In an effort to simplify and unify this piece of the puzzle, so that code that is released on this site can be compiled on any platform, we have chosen to standardise on using ASM80. This compiler can be used in any Internet Browser on any platform by visiting www.asm80.com

It has an integrated Code Editor as well, but it won't take you long to realise this is a slow and cumbersome way to develop code and upload it to the TEC-1G.

Thankfully the developer has released the assembler engine as a Node.js applicaiton which means that ANY platform should be able to install it and then use it from the command line. This means it can be integrated into VS Code as a command line assembler that you can initiate with a single keystroke. Detailed instructions for each of the three main platforms are below.

CoolTerm Download

Please consider donating to the ASM80 project so development can continue.

## Serial Terminal

This is yet another polarising piece of the puzzle with everyone having their favorites but in an effort to make it possible for the community to help each other, we have chosen to support [CoolTerm](https://www.freeware.the-meiers.org) because once again, it is available on all the major plaforms.

The Serial Terminal Software allows you to send and receive files to and from the TEC-1G via the USB cable connected to the FTDI module.

## Pick Your Poison
So all three key ingredients (Editor, Assembler and Terminal) are available on all three platforms, but of course each takes a slightly different way to install it. Below are the detailed Installation instructions for each major Desktop Platform.  If any of the links are broken, please let us know, and in the meantime use AI to find the corrected/moved links.

## MacOS
*Code Editor* <br>
VS Code is downloaded from: https://code.visualstudio.com/Download<br>
Install it as per normal by finding it in your **Downloads** folder, double click and then simply drag the VS Code app into your **Applications** folder. (You gotta love how easy MacOS makes it!)

*Assembler - Part 1* <br>
Install Node.js: https://nodejs.org/en/download<br>
You can try the manual installation instructions but the Prebuilt version simplifies the process. Simply select your platform and type of processor and then select the "MacOS Installer (.pkg)". This will download the installer to your Downloads folder. Double click on it to start the install process.

At the end it will pop up is message:
"Make sure that /usr/local/bin is in your $PATH."  You do that in the **Terminal** with a simple command:

```console
echo $PATH
```
Search for '/usr/local/bin' and if it is there, you are golden. If not, ask Grok how to add it in.

*Assembler - Part 2* <br>
Now that Node.JS is installed, it is very easy to install the actual ASM80 Assembler. Keep **Terminal** open and enter in this command:

```console
sudo npm install -g asm80
```
It will ask you for your Mac password. Enter it to continue.  Once it is finished, test that it is working by entering:
```console
asm80 --help
```

*Serial Terminal* <br>
CoolTerm is is cross platform and easy to install on the Mac. Download it here: https://www.freeware.the-meiers.org/<br>
Open the DMG in your **Downloads** folder, drag and drop it into your **Applications** folder. Easy peasy.

### Linux
*Code Editor*<br>
Download the VS Code binary from:  https://code.visualstudio.com/Download <br>
Follow these instructions: https://code.visualstudio.com/docs/setup/linux <br>
Which tells you to:
1. Go to Downloads folder and Right Click blank area and select "Open in Terminal"
2. Enter "sudo apt install ./<filename.deb>"  (Yes, you really do have to put in the dot and the slash)
3. It will ask you for your password. Enter it to complete the install.
4. Open the Mint Menu and type "VS" to find VS Code. Right Click and "Add to Panel" so it is easy to find and Start.
5. Once VS Code is installed and running, add in the Extensions.

*Assembler*<br>
Install Node.JS - https://nodejs.org/en/download/package-manager<br>
- installs nvm (Node Version Manager)<br>
curl -o- https://raw.githubusercontent.com/nvm-sh/nvm/v0.39.7/install.sh | bash<br>
- download and install Node.js (you may need to restart the terminal)<br>
nvm install 20<br>

*Serial Terminal* <br>
Download CoolTerm from: https://www.freeware.the-meiers.org/<br>
Extract All to the Downloads folder. Go into that folder and then "Open in Terminal"<br>
Type in:  <br>
sudo mkdir /usr/bin/CoolTerm   (you will be asked for your password)<br>
sudo cp * /usr/bin/CoolTerm -r -f<br>
Close the Terminal window. Browse to the folder /usr/bin/CoolTerm<br>
Double click "coolterm" program<br>
Dialogue box asking to set preferences comes up. Do so (I did) or select Defaults.<br>
Once running, go to Mint Menu, type in "Cool". Right click on menu item and select "Add to Panel"<br>

### Windows
One day I'll get around to writing this bit, but I don't use Windows any more, so hopefully you can work it out or someone will do a PR and update this section. The VS Code part should be easy, as should CoolTerm. The tricky one might be installing ASM80 as a command line application, but I'm sure Google/Grok/YouTube can point you in the right direction. Take a look at the instructions below for Mac or Linux and they will be similar.

## Configuration

Each one of the above programs will need a little bit of tweaking and configuration to make it just the little bit easier to use. Let's go in the order of least to most tinkering, starting with ASM80.

For this, there really is only the task of checking that is is installed correctly

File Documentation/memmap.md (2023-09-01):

# TEC-1G Memory Map

## Hardware Memory System

The TEC-1G supports an extremely flexible memory map, which can be broken down into four major blocks or *Banks*, each 16k in size.

### Memory Banks

Bank 0 - $0000 to $03FF - 16k RAM with first 2k over-shadowed by the first 2k of bank 3 at power-up

Bank 1 - $4000 to $7FFF - 16k RAM which can be PROTECT write-protected

Bank 2 - $8000 to $BFFF - 16k Uncommitted. Can be ROM or RAM with EXPAND page switching. Future Cartridge port space.

Bank 3 - $C000 to $FFFF - 16k MON-3 ROM or other MONitor ROM (out of a possible 32k chip, that can be manually switched between hi/lo halves of 32k)

The above memory map is fully compatible at power-on with the TEC-1; therefore all older MONitors that run from a 2K EPROM (e.g. BMON, JMON, MON-2 and MON-1B) will all work without modification.

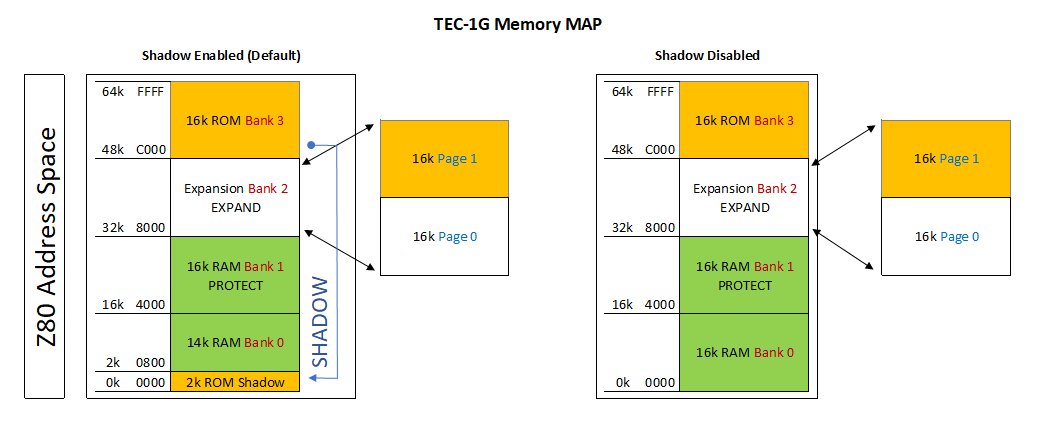
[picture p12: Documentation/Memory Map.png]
TEC-1G Memory Map Diagram


### Recommended Memory Configuration

The 'default' assumed configuration for a newly built TEC-1G, is:

- U7: 32k MON-3 ROM chip fitted. ROM Bank 3
- U8: 32k RAM fitted RAM Banks 0 and 1
- U9: left empty. Bank 2 unoccupied

Note that U7 can also accept a TEC-1 2k or 4k ROM with any previous MONitor if you wish to run older software.

### Memory Banks - Special Features

Each memory bank has certain unique special features, which are described below.

#### SHADOW Memory - Bank 0

To maintain TEC compatibility, the first 2K of Bank 0 is, at power on or RESET, is over-shadowed by the first 2k of bank 3. Hence, the first 2k of ROM appears at both $0000 and $C000 simultaneously.

Shadow can be turned off via the System Latch, giving a continuous 32k of RAM across banks 0 and 1.

#### PROTECT RAM Write Protect - Bank 1
Bank 1 by default behaves as normal RAM memory at power on and RESET.

By setting the PROTECT bit of the System Latch, Bank 1 can be made READ-ONLY. This allows a degree of protection for software or data in RAM against memory corruption due to e.g. buffer overflow, stack crash, etc.

If the Protect dip-switch is set by the user, MON-3 will set PROTECT when user code is launched, and un-select PROTECT while MON-3 is running. This allows seamless memory protection with no change to user code.

PROTECT is designed for programmers while developing code, to work in a 'safe' space and not loose your work while debugging.

#### EXPAND Page Switching & Cartridge - Bank 2
Bank 2 supports installing a RAM or ROM chip of up to 32k in size in the U9 position. However, because Bank 2 is only 16k in size, only half of a 32k chip can appear in Bank 2 at any time.

The highest address line of the 32k chip (A14) can be toggled using the System Latch under software control, to select which half of the chip appears in bank 3. Software is free to switch between chip halves at any time.

This software-selectable memory-chip control is also known in 1G language, as *page switching*.

It is planned that a 'game cartridge' type system will be made available for the TEC-1G - plugging in a cartridge will place it's onboard ROM in Bank 2, and on power up the cartridge's ROM code will execute instead of MON-3. *This is a future planned additon - more details will be added as this future project is developed further, and are of course subject to change.*

** If the device in U9 is 16k or less in size, or U9 is empty, EXPAND has no effect.

#### ROM Lo/Hi - Bank 3
The MON-3 MONitor ROM is designed to remain permanently fitted in bank 3. MON-3 provides system control and utility routines that user software can call upon using a standard software interface, or API.

To support a 32k ROM chip (or, a TEC-1 4k ROM), a ROM Lo/Hi swich is provided at SW6. This selects the upper or lower half of a 32k or 4K ROM chip, just like on the TEC-1.

** Note that the ROM SIZE jumpers must be set for the intended type of ROM chip - 24 pin (2k/4k) or 28 pin (8k to 32k).

### MON-3 Variables Memory Space

MON-3 sets aside $1000 bytes (2K0 of RAM from $0800 to $0FFF, for its internal purposes such as display buffering, keyboard state etc.

The contents of this RAM area are checked at startup, and if found to be corrupt or missing, overwritten with safe defaults. If a checksum test passes, the memory is left intact, meaning user settings and selections can survive a RESET.

## ROM Memory space

All of Bank 3 between $C000 and $FFFF is set aside as ROM space, and is occupied by MON-3 and associated software included in the ROM image (demos, games, etc)

## User Memory Space

User Program Memory occupies Bank 1, starting at $4000 and ending at $7FFF - providing 16k of write-Protected RAM. The PROTECT signal is used to write-protect the RAM memory space, but can be turned off in MON-3 by config dipswitch, and controlled by user software if so desired. Mon-3's default location for editing program code is $4000. This replaces the prior use of $0800 or $0900 in earlier monitors.

MON-3 variables and Stack are located in Bank 0 between $0800 and $0FFF. This area should not be accessed by user programs, however if corrupted, MON-3 will reload default values upon reset, to ensure that MON-3 can always restart to a usable condition. Earlier monitors placed the stack at undocumented locations. With MON-3, you always know where your stack is.

The Z80 'zero page' interupt vectors and MON-3 core startup code are located between $0000 and $07FF. This memory space can be configired as RAM and altered by software to support advanced features such as Z80 INT interrupt support, however newcomers to the TEC-1G should consider this memory area 'off limits'.

The balance of Bank 0 is user RAM memory space, located between $1000 and $3FFF. This space is suggested for use as user variables, data buffers and the like.

| Bank | Address | Size | Purpose |
|---|---|---|---|
| Bank 3 | $C000 | 16k |MON-3 ROM |
| Bank 2 | $8000 | 16k | EXPAND space - unoccupied |
| Bank 1 | $4000 | 16k | Protected User RAM - program code, constants |
| Bank 0 | $1000 | 12k | Unprotected User RAM - variables & data |
| Bank 0 | $0800 | 2k | MON-3 Variables & Stack |
| Bank 0 | $0000 | 2k | MON-3 Shadow ROM |

The TEC-1G ofers a more mature programmer's model, with Code and Data separated into their own distinct memory areas. PROTECT further assists programmers by ensuring your hard-entered code is not destroyed by an errant software bug. PROTECT works automatically and does not normally need any user program code to function.

## Other Memory Map Notes

U9 can accept an up to 32k ROM or RAM chip to extend system capacity via Bank 2. Note that future planned add-ons may also use Bank 2.

If a further 32k RAM chip is fitted to U9, the TEC-1 can support a full 64k of RAM, however only 48k is accessible without using EXPAND bankswitching.

## A note on CP/M

Careful consideration was given to the question of whether the TEC-1G should be able to run CP/M, or not.

It was decided NOT to <b>specifically</b> aim for CP/M compatability, for a number of reasons:

- There are many Z80 based CP/M machines on the market. The 1G should not simply become another Z80 'textbook design'. If you want a CP/M box, there are plenty to choose from. The TEc-1G isn't intended to be one of them
- CP/M is an advanced OS generally requring disk drives, terminals, a full 64k of RAM + additional bankswitched memory, and calls for a greater user skillset, both to get up and going, and to use effectively. This is contrary to the design goal of simplicity and ease of understanding
- Any attempt to do CP/M "well" would end up in so many compromises that the design goal of staying true and compatible with the TEC-1 family would be lost
- CP/M would not be practically usable on a hex keypad and 4-line LCD in any case

Having said all that, there is likely no reason that CP/M could not be adapted for the 1G, and we would certainly welcome any attempt to do so. We leave this as "An exercise left up to the reader" as so many good textbooks like to say.

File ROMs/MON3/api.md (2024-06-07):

# MON-3 API guide

### Please view the User Guide for updated API calls.  This document will not be maintained by the mon3 author.

## General Conventions
C register - holds API Call number.

Executing an RST 10H opcode calls the API.
```
        ld c,[API Call Number]
        rst 10H
```
- Any parameters are passed in the A, B, DE and/or HL registers, depending on the requirements of each call.

- Results are returned in various registers and/or by altering memory as shown within each call.

Note: if a register is marked as destroyed - that means the value of the register is altered in an undefined manner by the API call, and thus should not be relied upon to contain any specific value after the API call runs.
```
    Some Examples:

        ;Produce a short Beep from the speaker
        ld c,3      ;beep call number
        rst 10H

        ;Display the letter 'G' on the LCD Screen
        ld c,14     ;charToLCD call number
        ld a,"G"    ;parameter
        rst 10H

        ;Wait for a period of time
        ld c,33     ;timeDelay call number
        ld hl,3000H ;parameter
        rst 10H
```
---
## API Calls list - MON-3 1.0 (BC23-10 ROM Image)

| Routine | Call Number | Hex Number | MON-3 Version Supported |
| --- | :--: | :--: | :---: |
| [_softwareID](#_softwareid) | 0 | 00H | BC23-10 |
| [_versionID](#_versionid) | 1 | 01H | BC23-10 |
| [_preInit](#_preinit) | 2 | 02H | BC23-10 |
| [_beep](#_beep) | 3 | 03H | BC23-10 |
| [_convAToSeg](#_convatoseg) | 4 | 04H | BC23-10 |
| [_regAToASCII](#_regatoascii)  | 5 | 05H | BC23-10 |
| [_ASCIItoSegment](#_asciitosegment) | 6 | 06H | BC23-10 |
| [_stringCompare](#_stringcompare) | 7 | 07H | BC23-10 |
| [_HLToString](#_hltostring) | 8 | 08H | BC23-10 |
| [_AToString](#_atostring) | 9 | 09H | BC23-10 |
| [_scanSegments](#_scansegements) | 10 | 0AH | BC23-10 |
| [_displayError](#_displayerror) | 11 | 0BH | BC23-10 |
| [_LCDBusy](#_lcdbusy) | 12 | 0CH | BC23-10 |
| [_stringToLCD](#_stringtolcd) | 13 | 0DH | BC23-10 |
| [_charToLCD](#_chartolcd) | 14 | 0EH | BC23-10 |
| [_commandToLCD](#_commandtolcd) | 15 | 0FH | BC23-10 |
| [_scanKeys](#_scankeys) | 16 | 10H | BC23-10 |
| [_scanKeysWait](#_scankeyswait) | 17 | 11H | BC23-10 |
| [_matrixScan](#_matrixscan) | 18 | 12H | BC23-10 |
| [_joystickScan](#_joystickscan) | 19 | 13H | BC23-10 |
| [_serialEnable](#_serialenable) | 20 | 14H | BC23-10 |
| [_serialDisable](#_serialdisable) | 21 | 15H | BC23-10 |
| [_txByte](#_txbyte) | 22 | 16H | BC23-10 |
| [_rxByte](#_rxbyte) | 23 | 17H | BC23-10 |
| [_intelHexLoad](#_intelhexload) | 24 | 18H | BC23-10 |
| [_sendToSerial](#_sendtoserial) | 25 | 19H | BC23-10 |
| [_receiveFromSerial](#_receivefromserial) | 26 | 1AH | BC23-10 |
| [_sendAssembly](#_sendassembly) | 27 | 1BH | BC23-10 |
| [_sendHex](#_sendhex) | 28 | 1CH | BC23-10 |
| [_genDataDump](#_gendatadump) | 29 | 1DH | BC23-10 |
| [_checkStartEnd](#_checkstartend) | 30 | 1EH | BC23-10 |
| [_menuDriver](#_menudriver) | 31 | 1FH | BC23-10 |
| [_paramDriver](#_paramdriver) | 32 | 20H | BC23-10 |
| [_timeDelay](#_timedelay) | 33 | 21H | BC23-10 |
| [_playNote](#_playnote) | 34 | 22H | BC23-10 |
| [_playTune](#_playtune) | 35 | 23H | BC23-10 |
| [_playTuneMenu](#_playtunemenu) | 36 | 24H | BC23-10 |
| [_getCaps](#_getcaps) | 37 | 25H | BC23-10 |
| [_getShadow](#_getshadow) | 38 | 26H | BC23-10 |
| [_getProtect](#_getprotect) | 39 | 27H | BC23-10 |
| [_getExpand](#_getexpand) | 40 | 28H | BC23-10 |
| [_setCaps](#_setcaps) | 41 | 29H | BC23-10 |
| [_setShadow](#_setshadow) | 42 | 2AH | BC23-10 |
| [_setProtect](#_setprotect) | 43 | 2BH | BC23-10 |
| [_setExpand](#_setexpand) | 44 | 2CH | BC23-10 |
| [_stringToSerial](#_stringtoserial) | 45 | 2DH | BC24-14 |
| [_RTCAPI](#_rtcapi) | 46 | 2EH | BC24-14 |
| [_menuPop](#_menuPop) | 47 | 2FH | BC24-14 |
| [_toggleCaps](#_togglecaps) | 48 | 30H | BC24-14 |
| [_random](#_random) | 49 | 31H | BC23-11 |
| [_setDisStart](#_setDisStart) | 50 | 32H | BC23-12 |
| [_getDisNext](#_getDisNext) | 51 | 33H | BC23-12 |
| [_getDisassembly](#_getDisassembly) | 52 | 34H | BC23-12 |
| [_matrixScanASCII](#_matrixScanASCII) | 53 | 35H | BC23-12 |
| [_parseMatrixScan](#_parseMatrixScan) | 54 | 36H | BC24-15 |
| [_LCDConfirm](#_LCDConfirm) | 55 | 37H | BC24-15 |
| [_getGLCDTerm](#_getglcdterm) | 56 | 38H | BC24-15 |
| [_setGLCDTerm](#_setglcdterm) | 57 | 39H | BC24-15 |

Future MON-3 versions may introduce additional API calls - therefore code using calls not present in version MON-3 1.0 should first call _versionID to determine that the MON-3 version supports the calls being made.

----
### _softwareID 
Get Software ID String
```
Input: nothing
Return: HL = Pointer to SOFTWARE ASCIIZ String
Destroys: none
```
### _versionID
Get Version Number and Version String
```
Input: nothing
Return: HL = Pointer to Release ASCIIZ String
        BC = Release major version number
        DE = Release minor version number
Destroys: none
```
BC contains the binary value for the design year. MON-3 1.0 returns 07E7H for the year 2023. Future versions should carry the year of release.
DE contains the binary value for the design revision. MON-3 1.0 returns 0003H for design revison 3. Future versions should increment this value.
The ASCIIZ string is a concatenation of the above values. MON-3 1.0 returns "2023.03",0
### _preInit
Performs a hard boot, as if the TEC-1G had just been powered on. Returns to MON-3 in default state.

### _beep
Makes a short beep tone
```
Input: nothing
Destroys: A
```
### _convAToSeg
Convert register A to Seven Segment
```
Inputs: A = byte to convert
        DE = address to store segment values (2 bytes)
Destroys: BC
```
### _regAToASCII
Convert register A to ASCII. IE: 2CH -> "2C"
```
Input: A = byte to convert
Output: HL = two byte ASCII string
Destroys: A
```
### _ASCIItoSegment
ASCII to Segment.  Converts an ASCII character to Seven Segment character
```
Input: A = ASCII character
Return: A = Segment character or 0 if out of range
Destroys: none
```
### _stringCompare
Compare two string
```
Input: HL = source pointer
       DE = target pointer
       B = #bytes to compare (up to 256)
Output: Zero Flag Set = compare match
Destroys: HL, DE, A, BC
```
### _HLToString
Convert HL to ASCII string. IE: 2CH -> "2C"
```
Input: HL = value to convert
       DE = address of string destination
Output: DE = address one after last ASCII entry
Destroys: A
```
### _AToString
Convert register A to ASCII string
```
Input: A = byte to convert
       DE = address of string destination
Output: DE = address one after last ASCII entry
Destroys: A
```
### _scanSegements
Multiplex the Seven Segment displays with the contents of DE
```
Inputs: DE = 6 byte location of segment data
Destroys: A, B
```
### _displayError
Display ERROR on the 7Segs and wait for key press
```
Input: none
Destroys: all
```
### _LCDBusy
LCD busy check.  Checks the LCD busy flag and loops until LCD isn't busy
```
Input: nothing
Destroys: none
```
### _stringToLCD
ASCII string to LCD.  Writes a string to the current cursor location on the LCD
```
Input: HL = ASCII string terminated with zero byte
Destroys: A, HL (moves to end of list)
```
### _charToLCD
ASCII character to LCD.  Writes one character to the LCD at the current cursor location
```
Input: A = ASCII character
Destroys: none
```
### _commandToLCD
Command to LCD.  Sends an LCD instruction to the LCD
```
Input: B = Instruction byte
Destroys: none
```
### _scanKeys
Universal Key input detection routine. Supports HexPad and Matrix. Does not wait for a key press - returns immediately.
```
Return: A = key value (if following are met)
    zero flag set if a key is pressed
    carry flag set if press detected of a new key
    carry flag not set for key pressed and held
Destroys: DE if using Matrix Keyboard
```
### _scanKeysWait
Generic Key input detection routine. Supports HexPad and Matrix. Waits until a key is pressed.
```
Return: A = key value (if following are met)
    zero flag set if key is pressed
Destroys: DE if using Matrix Keyboard
```
### _matrixScan
Key scan routine for the Matrix Keyboard.  This routine detects up to two key presses at the same time.  Key values stored in DE.  Routine must be called repetitively.
```
Input: None
Output: E = Key pressed between 00H-3FH (0-64)
        D = Second key, FF=no key, 00=shift, 01=Ctrl, 02=Fn
        zero flag set if a key is pressed or combination valid
```
### _joystickScan
Joystick port scan routines.  This routine will return a value based on the movement / button of the joystick or any combination: IE: UP+DOWN = 03H, Routine must be called repetitively.
```
Input: None
Output: A = Joystick return value between 00H-5FH (0-95)
      01H = Up        10H = Fire 2
      02H = Down      20H = Comm2 (Pin 9)
      04H = Left      40H = Fire 1
      08H = Right     80H = Fire 3
        zero flag set if no joystick value returned
Destroys: none
```
### _serialEnable
Activates the BitBang serial port for serial transfer.  Disco LED's glow blue to indicate ready status.
```
Input: none
Destroys: A
```
### _serialDisable
Deactivates the BitBang serial port for serial transfer.  Disco LEDs turn off.
```
Input: none
Destroys: A
```
### _txByte
Bit Bang FTDI USB transmit routine.  Transmit one byte via the FTDI USB serial connection.  It assumes a UART connection of 4800-8-N-2.
```
Input: A = byte to transmit
Output: nothing
Destroys: none
```
### _rxByte
Bit Bang FTDI USB receive routine.  Receive one byte via the FTDI USB serial connection.  It assumes a UART connection of 4800-8-N-2.  Note routine will wait until a bit is detected.
```
Input: nothing
Return: A = byte received
Destroys: none
```
### _intelHexLoad
Load an Intel Hex file via the FTDI USB serial connection.  Displays file progress on the segments and PASS or FAIL at the end of the load.  Intel Hex file format is a string of ASCII with the following parts:
```
:10200000210621CD7D20CD98203A00213C320021AF <- EXAMPLE LINE
```
| MARK | LENGTH | ADDRESS | RECORD TYPE | DATA | CHECKSUM |
| :-: | :--: | :----: | :--: | :---: | :--: |
|:|10|2000|00|210621CD7D20CD98203A00213C320021|AF|

MARK is a colon character, LENGTH is the number of DATA bytes per line,  ADDRESS is the 2 byte address of where the data is to be stored.  RECORD TYPE is 00 for Data and 01 for EOF.  DATA is the bytes to be stored.  CHECKSUM is the addition of all bytes in the one line modulo 256, and taking the two's compliment.
```
Input: nothing
Output: nothing
Destroys: HL,DE,BC,A
```
### _sendToSerial
SIO Binary Dump.  Transfer data on the TEC to a serial terminal.  From and To address data is needed and input.
```
Input: 2 byte from address = Stored in RAM at address 08C0H
       2 byte to address = Stored in RAM at address 08C2H
Destroys: A,HL,DE,BC
```
### _receiveFromSerial
SIO receive binary data.  Receive binary data from FTDI.  From and To address data is needed and input.
```
Input: 2 byte from address = Stored in RAM at address 08C0H
       2 byte to address = Stored in RAM at address 08C2H
Destroys: A,HL,DE,BC
```
### _sendAssembly
Send Assembly instructions to the serial port.  Print out code disassembly.  Receive binary data from FTDI.  From and To address data is needed and input.
```
Input: 2 byte from address = Stored in RAM at address 08C0H
       2 byte to address = Stored in RAM at address 08C2H
Destroys: A,HL,DE,BC
```
### _sendHex
Send a traditional HEX dump as text to the serial terminal.  Upto 16 bytes are displayed per line.    From and To address data is needed and input.
```
Input: 2 byte from address = Stored in RAM at address 08C0H
       2 byte to address = Stored in RAM at address 08C2H
Destroys: A,HL,DE,BC
```
### _genDataDump
Generate data dump in ASCII.  Print Address and then C number of bytes
```
Input: B = number of bytes to display
       HL = start address of data dump
       DE = address of string destination
Output: DE = zero terminated address one after last ASCII entry
          IE: "4000: 23 34 45 56 78 9A BC DE",0
Destroys: A, HL (moves to next address after last byte)
```
### _checkStartEnd
Check start and end address difference.
```
Input: HL = address location of START value
       HL+2 = address location of END value
Output: HL = start address
        BC = length of end-start
        Carry = set if end is less than start
Destroys: DE
```
### _menuDriver
Menu driver for external applications.  Creates a selectable custom menu.  Keys: Go = Select menu item, AD = Exit Menu, +/- = Navigate menu
```
Input: HL = Pointer to Menu configuration. (See Note)
Destroys: A, HL

Note: Menu configuration is as follows.  All strings are ZERO terminated!
<Menu Entries>, <Menu Text Title>, [<Menu Text Label>, <Menu Routine Address>]+
  EG: .db 2                 ;Two menu items
      .db "Games",0         ;Menu title
      .db "TEC Invaders",0  ;Text and Routine
      .dw invaders
      .db "TEC Maze",0      ;Text and routine
      .dw maze
```
### _paramDriver
Parameter data entry driver.  Creates a list of editable two byte parameters.  Keys: Go = Continue, AD = Exit, +/- = Navigate, 0-F = enter values
```
Input: HL = Pointer to Parameter configuration. (See Note)
Note: Parameter configuration is as follows.  All strings are ZERO terminated!  Parameter text can be no longer than 14 characters
<No. of Entries>, <Parameter Title Text>, [<Param Text Label>, <Param RAM Address>]+
  EG: .db 3                         ;Three parameters
      .db "= Enter Parameters =",0  ;Parameter title
      .db "Start Address:",0        ;Text and Address
      .dw COPY_START
      .db "End Address:",0          ;Text and Address
      .dw COPY_END
      .db "Dest. Address:",0        ;Text and Address
      .dw COPY_DEST
```
### _timeDelay
A 16 bit delay routine.
```
Input: HL = delay amount
Destroys: none
``` 
### _playNote
Play a note.  Play a note with a given frequency and wavelength
```
Input: HL = frequency (01-7F)
       B = wavelength (00-FF)
Destroys: HL, BC, A
```
### _playTune
Play a series of notes.  To play a note use a reference between 01H and 18H.  Where 01H is the lowest and 18h is the highest.  Use 00H to make a pause and any value greater then 18H to exit.

Note reference table is as follows:
|Note |Value|
|-----|-----|
|  G  | 01H |
|  G# | 02H |
|  A  | 03H |
|  A# | 04H |
|  B  | 05H |
|  C  | 06H |
|  C# | 07H |
|  D  | 08H |
|  D# | 09H |
|  E  | 0AH |
|  F  | 0BH |
|  F# | 0CH |
|  G  | 0DH |
|  G# | 0EH |
|  A  | 0FH |
|  A# | 10H |
|  B  | 11H |
|  C  | 12H |
|  C# | 13H |
|  D  | 14H |
|  D# | 15H |
|  E  | 16H |
|  F  | 17H |
|  F# | 18H |

```
Input: DE = Address of first note
Destroys: A,B,DE,HL
```
### _playTuneMenu
Play tune routine above but address of notes is set via a parameter menu.
### _getCaps
Get Caps lock state
```
Input: none
Output: A = caps lock state; 0 = off, 80H = on
```
### _getShadow
Get SHADOW state
```
Input: none
Output: A = shadow state; 0 = off, 01H = on
```
### _getProtect
Get PROTECT state
```
Input: none
Output: A = protect state; 0 = off, 02H = on
```
### _getExpand
Get EXPAND state
```
Input: none
Output: A = expand state; 0 = off, 04H = on
```
### _setCaps
Set Caps lock state
```
Input: A = Desired caps lock state; 0 = off, 80H = on
Destroys: A
```
### _setShadow
Set Shadow state
```
Input: A = Desired shadow state; 0 = off, 01H = on
Destroys: A
```
### _setProtect
Set Protect state
```
Input: A = Desired protect state; 0 = off, 02H = on
Destroys: A
```
### _setExpand
Set Expand state
```
Input: A = Desired expand state; 0 = off, 04H = on
Destroys: A
```
### _toggleCaps
Toggle Caps Lock state
```
Input: none
Destroys: A
```
### _random
Generate a Pseudo Random number between 00-FF
```
Input: none
Output: A = random byte
Destroys: B
```
### _setDisStart
Set Disassembly start address.  Set the first address for disassembly output 
```
Input: HL = start address
Output: none
Destroy: none
```
### _getDisNext
Get Disassembly next address.  The new start address for the next output.  
```
Input: none
Output: HL = start address
Destroy: none
```
### _getDisassembly
Generate Disassembly line.  Must call setDisStart prior.  Only need to call setDisStart once as the next address is automatically increased.
```
Input: none
Output: HL = pointer to disassembly ASCII, zero terminated
Destroy: none
```
### _matrixScanASCII
Convert the output of the matrixScan routine to ASCII.  matrixScan returns values between 0 and 64, these represent key presses on the keyboard.  This routine will convert the output of matrixScan DE, to the actual key pressed in ASCII.  If key doesn't map to an ASCII character then the matrix key value is returned.
```
Input: DE = value return from matrixScan.
   E = key, D = Secondary key
Output: A = key pressed in ASCII
Destroy: BC, HL
```
---
## Breakpoints and Debugger

Executing an RST 30H opcode calls the built-in Debugger. The message CPU bP is also displayed on the 7-seg displays to indicate that a Breakpoint is active.

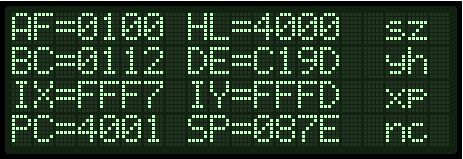
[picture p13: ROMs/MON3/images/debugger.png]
Debugger Screenshot


As this is a single-byte (opcode F7H), it becomes very simple to insert this opcode into your program wherever a breakpoint is needed. Later on the opcode can be removed or simply replaced with NOP (opcode 00H) when no longer required.

The debugger shows the state of the primary Z80 registers and the flags. If the flag letter is a capital, the flag is set; if lower case, flag is clear. x and y represent the two undefined bits of the flags register. Flags are shown in register-bit-order, bit 7 (sign) down to bit 0 (Carry).

| Letter | Flag |
| - | ---- |
| s | Sign |
| z | Zero |
| y | (undefined) |
| h | Half Carry |
| x | (undefined) |
| p | Parity/Overflow |
| n | Add/Subtract |
| c | Carry |

At this time the Z80 alternate registers (AF', BC' etc.) are not shown, this feature may be added in a future MON-3 release.

### Debugger navigation keys

**GO** key exits the debugger and returns to the next instruction.

**ADDR** key exits the debugger and returns to MON-3.

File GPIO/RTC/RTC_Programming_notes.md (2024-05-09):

# DS1302 Clock, Calendar and PRAM notes for Programmers

The DS1302 register set presents certain ambiguous choices, which this document seeks to clarify, as well as to document the format of the PRAM area.

## RTC Clock and Calendar

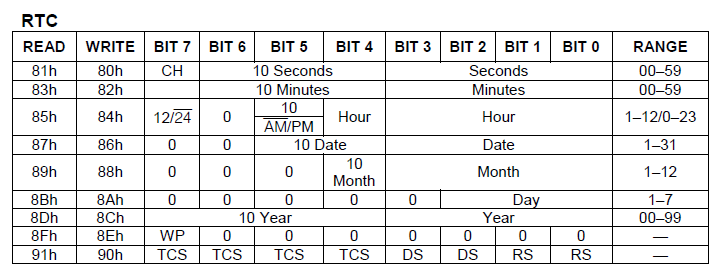
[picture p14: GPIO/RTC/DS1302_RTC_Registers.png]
DS1302 RTC egisters!


---

When initially accessing the DS1302, Register 8Eh needs to be written with the value 00h. Until this is done, the DS1307 is considered read-only and no changes can be made. Set bit 7 to a 1 to write-protect the DS1302.

Similarly, register 90h should be written with 00h to suit the hardware design of the GPIO RTC board (no trickle charging).

---

The TEC-1G supports both 12 and 24 hour time formats. The register layout makes this a little difficult to understand; this is how it works.

The hours are either 01..12 (12 hour) or 00..23 (24 hour).

Bit 7 of the hour register is a 1 if 12 hour mode is selected
bit 5 of the hour register is a 1 if it is PM (12 hour mode), or part of the hour (24 hour mode)

---

The Year register only supports 2 digits with value range of 00 too 99; hence only a 100 year span is available. This means that a 'base year' needs to be added to the Year value read from the RTC, to arrive at a Calendar year.

TEC-1G designers have determined that 2000 will be the base year. Hence, **CalendarYear = 2000 + RTCYear**

| DS1302 Year | Calendar Year |
| :--: | :----: |
| 00 | 2023 |
| 01 | 2024 |
| 02 | 2025 |
| .. | .... |
| 99 | 2122 |

We wish future TEC-1G users all the best in resolving what happens in 2122 :)

---

The day of week register supports the range 1 to 7; as we know however the actual day that corresponds to any given date varies based on time zone. Therefore, the DS1302 simply incrmeents this value at midnight, but has no knolwege of timezones or what is 'correct'.

TEC-1G designers have followed ISO8601 which defines Moday as the first day of the week. Therefore:

Day 1 = Monday

....

Day 7 = Sunday

---

# PRAM Memory

The DS1302 has 31 bytes of static RAM, which the TEC-1G Designers have named the **P**aramemter **RAM**, or PRAM for short.

Part of the PRAM is set aside for MON3's use. 14 User Bytes are free for software authors to put to any use they see fit.

| PRAM Byte | Purpose |
| :--: | ----- |
|01| Fn-1 Editing Address |
|03| Fn-2 Editing Address |
|05| Fn-3 Editing Address |
|07| Quick Backup - Start address |
|09| Quick Backup - End address |
|11| Quick Backup - Destination address |
|12| Mon3 Reserved |
|13| Mon3 Reserved |
|14| Mon3 Reserved |
|15| Mon3 Reserved |
|16| User Byte |
|17| User Byte |
|18| User Byte |
|19| User Byte |
|20| User Byte |
|21| User Byte |
|22| User Byte |
|23| User Byte |
|24| User Byte |
|25| User Byte |
|26| User Byte |
|27| User Byte |
|28| User Byte |
|29| User Byte |
|30| User Byte |
|31| nnh - Checksum (Two's compliment of MON3 controlled bytes) |

The Checksum is used to verify that the PRAM contents used by MON3 are valid and not corrupted.

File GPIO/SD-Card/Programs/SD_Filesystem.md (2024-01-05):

# SD Card File System Structure - TEC-FS

The TEC-FS disk format / file system is proprietory to the TEC and not compatible with FAT or CP/M. This was done for simplicity and efficiency; it is very complex to implement a full file system; this "minimal" system TEC-FS is more than adequate for normal use in saving, loading and managing files.

The file system will work on any "block" type device that supports 512 byte sectors. The initial implementation has been built around SD cards, however there is no reason that CompactFlash could not also work, for example. We will use the term "SD Card" here, but any block device applies equally.

The file system requires around 8 megabytes of total storage -- modern SD Cards of course hold many gigabytes; therefore most of the card's space is "unused".

Note: This code is written for "type 02" or SDHC cards. Using very, very old SD cards (<2Gb) is not supported. A 16Gb SD card can be purchased for around ten to fifteen dollars. Attempting to support older cards simply does not make good sense.

## Basic Features
- Supports up to 128 files per SD card
- Any file length (up to maximum supported)
- Maximum of 64k in any single file
- Can save & load any contiguous area of TEC memory
- up to 20 character filenames
- Files are date/timestamped (future feature, requires GPIO RTC card)

## Disk Structure
The disk structure is designed to keep minimal compatability with windows computers, such that if the SD Card is plugged into a PC, nothing "bad" will happen to either the PC or the data. At this stage, inserting the SD card will prompt Windows to format the SD - simply choose cancel.

Files are also stored (starting) at fixed sector locations. This makes the need for a PC style FAT not necessary - it is not as efficient, but as noted earlier we are using only a tiny percentage of available space, in any case.

| Sector  | Purpose  |
| --- | --- |
| 0 | MBR |
| 63 | not used |
| 64..79  | FCB |
| 80..127 | not used |
| 128 | file #1  |
| 256 | file #2  |
| 384 | file #3  |
| 512 | File n |

## MBR Structure
The signature is used to verify that the SD Card is formatted to suit TEC-1G/MON3.

| offset | length | Field | Type | Value |
| --- | --- | --- | --- | --- |
| 0 | 6 | signature | string | "TEC-1G" |
| 6 | 20 | volume label | ASCIIZ | "SD Card Storage 000",0 |
| 26 | 7 | date & time | DS1302 | 00,00,01,01,01,01,00 |
| 33 | 1 | filename sectors | binary | 16 |
| 34 | 412 | spare | binary | all 00 |
| 446 | 64 | partiton table | binary | all 00 |
| 510 | 2 | signature | binary | 55 AA |
| | 512 | total bytes | | |

## FCB Structure
An FCB is a File Control Block - used to keep track of each file's attributes.

A start address of FFFF indicates the file is not in use.

Table Version is to be incremented as new FCB parameters are added, so future software can identify the save version accordingly.

The expand byte is for future use - indicates if the EXPAND memory is what has been saved. An Expand save would be 32k; TEC bank 2/Expand=0 followed by TEC bank 2/Expand=1

| offset | length | File FCB entry | Type | Value |
| --- | --- | --- | --- | --- |
| 0 | 20 | Filename | ASCIIZ | "FILE NUMBER 0000000",0 |
| 20 | 2 | start address | binary | FFFFh |
| 22 | 2 | length | binary | 0000h |
| 24 | 1 | expand | binary | 0 |
| 25 | 7 | date & time | DS1302 | 00,00,01,01,01,01,00 |
| 32 | 4 | start SD Sector  | binary | 00000000 |
| 36 | 2 | \# of SD Sectors | binary | 0000 |
| 38 | 25 | spare | binary | all 00 |
| 63 | 1 | table version | binary | 00 |
| | 64 | total bytes | | |

## The Math
512 bytes per sector - SD Cards (and virtually all block based storage media) all support this sector size by default.

1 MBR sector

64 bytes per FCB Entry; 512/64 = 8 FCBs per sector

128 files per device

128/8 = 16 FCB sectors required

64k per file (maximum)

64k/512 = 128 sectors per file (maximum)

63+48=111 spare sectors

total storage capacity required: 1 + 63 + 16 + 48 + (128*128) = 16512 sectors needed

** just over 8Mb of space required **

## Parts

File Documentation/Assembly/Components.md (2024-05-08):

# Components and Identifiers

## The RGB LEDs
The long leg of the RGB LED is the Cathode.<br>
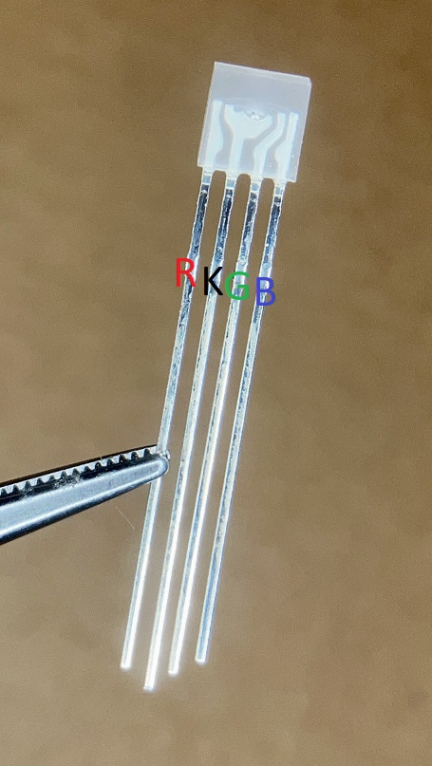
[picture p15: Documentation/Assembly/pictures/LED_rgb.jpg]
RGB LED
<br>

## Standard LEDs
The short leg is the Cathode.<br>
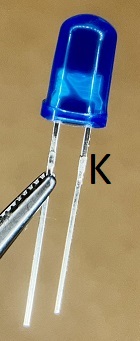
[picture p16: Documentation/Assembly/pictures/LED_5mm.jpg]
Standard LEDs
<br>

## Network Resistors
The leg with the DOT above it is pin 1. The numbers after it give you the resistance value.<br>
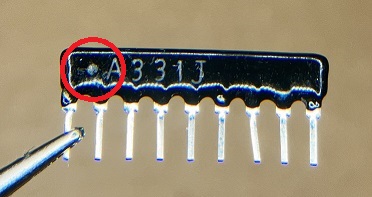
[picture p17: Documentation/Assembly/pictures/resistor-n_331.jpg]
<br>

## Diodes
Diodes of all kinds have a solid band printed around one end. This indicates the Cathode. (I think of the band as the upright of the letter K)<br>
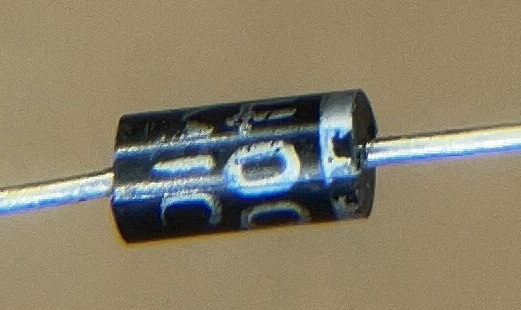
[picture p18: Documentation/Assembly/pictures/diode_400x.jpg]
<br>

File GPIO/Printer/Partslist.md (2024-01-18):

# TEC-1G GPIO Parallel Printer Port
### Parts List

| QTY | Part # | Description |
|---|---|---|
| 1 | PCB | TEC-1G GPIO Printer Port PCB |
| 1 | 74HCT32 | Quad OR Gates |
| 1 | 74HCT245 | Octal 3-State Buffer |
| 1 | 74HCT373 | Octal Transparent Latch |
| 1 | 100n | Capacitor |
| 1 | 14 pin | DIP Socket |
| 3 | 20 pin | DIP Socket |
| 1 | 2x8 pin | Long Legged Female Header |
| 1 | 1x2 pin | Long Legged Female Header |
| 1 | 10K x 9 pin | Resistor Network |
| 1 | 330R | Resistor |
| 1 | 3mm LED | Green |
| 1 | 2x10pin | Female Header, Horizontal |
| 1 | 25pin D-Type | Parallel Port Connector |
| 2 | 12mm Standoff | M3 Nylon |
| 1 | Screw | M3 Nylon |
| 1 | Nut | M3 Nylon |

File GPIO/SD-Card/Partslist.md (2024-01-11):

# TEC-1G GPIO SD-Card & 8Bit Input/Output
## Parts List
### Base Parts
| QTY | Part # | Description |
|---|---|---|
| 1 | PCB | TEC-1G GPIO SD-Card Printed Circuit Board |
| 1 | 74HCT32 | Quad OR Gates |
| 1 | 74HCT245 | Octal Buffer |
| 1 | 74HCT273 | Octal D-Type Latch with Clear |
| 1 | 100n | Capacitor |
| 1 | 330R | Resistor |
| 1 | LED | 3mm RED |
| 1 | 14 pin | DIP Socket |
| 2 | 20 pin | DIP Socket |
| 1 | 2x8 pin | Long Legged Female Header |
| 1 | 1x2 pin | Long Legged Female Header |
| 1 | 2x3 pin | 6pin header for selecting Port # (Port $FD for SD Card Use) |
| 1 | Jumper | Port Selection Jumper |
| 2 | 12mm Standoff | M3 Nylon |
| 1 | Screw | M3 Nylon |
| 1 | Nut | M3 Nylon |

Depending on how you wish to use the GPIO, here are the additional parts.

### Additional for use as general 8 Bit Input/Output board
| QTY | Part # | Description |
|---|---|---|
| 2 | 10 pin Female Header Socket, Horizontal | Used to plug in both input and output devices. |
* Two are supplied in the Kit.

### Additional for use as Micro SD Card drive
| QTY | Part # | Description |
|---|---|---|
| 1 | SD Module | Two sorts can be accomodated. See notes below. |
| 1 | 10 pin Female Header Socket, Horizontal | *Optional, to see activity while using SD Card |

Two types of Micro SD Card modules can be used on this board. One is from Sparkfun #13743 (Red module, beliow)
and the other is a generic module found on eBay (in Blue), etc.

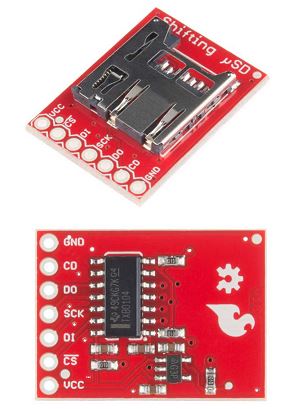
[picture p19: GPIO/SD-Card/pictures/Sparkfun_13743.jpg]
Sparkfun Module
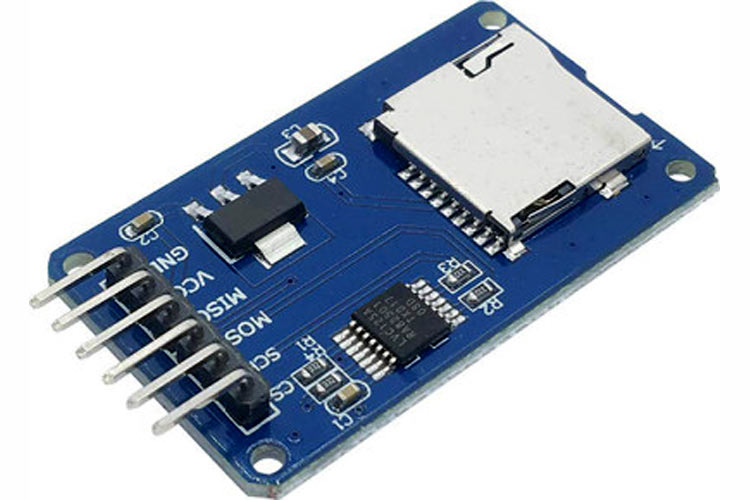
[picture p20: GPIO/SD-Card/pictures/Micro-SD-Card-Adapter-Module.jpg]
generic Module


* The generic module is supplied in the Kit.

Kits can be purchased from [Tindie](https://www.tindie.com/products/tec1/tec-1g-micro-sd-card-general-inputoutput-kit/)

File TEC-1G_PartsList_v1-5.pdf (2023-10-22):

### Version 1.5

Qty | Reference | Value | Description | Notes
1 | PCB | TEC-1G
7 | R1, R5, R9, R13, R14, R18, R33 | 330R | 1/4 watt metal film 1% Resistor 330R
3 | R2, R15, R31 | 2k2 | 1/4 watt metal film 1% Resistor 2k2
14 R10-R12, R26- | R30, R32 | 10k | 1/4 watt metal film 1% Resistor 10k
8 | R16, R19-25 | 1k | 1/4 watt metal film 1% Resistor 1k
1 | R17 | 100R | 1/4 watt metal film 1% Resistor 100R
1 | R34 | 0R | 1/4 watt metal film 1% Resistor 0R OR wire link
2 | RN1, RN3 | 10k | SIP9 8 resistor network 10k
1 | RN2 | 4k7 | SIP9 8 resistor network 4k7
3 | RN4, RN5, RN7 | 330R | SIP9 8 resistor network 330R | RN5 and RN7 only required if mounting Fulisik LEDs
1 | RN6 | 330R | SIP5 4 resistor network 330R | RN6 only required if mounting Fulisik LEDs for Gateron MX LP key switches
1 | VR1 | 500k | Potentiometer, cermet 500k
1 | VR1/SW13 | 500k | SPST switching potentiometer, horizontal | Optional switched horizontal mount pot for Radio GaGa
1 | VR2 | 10k | Potentiometer, cermet, 10k
1 | C1 | 1000uF Electro | Polarised radial electrolytic capacitor, pitch 5.0mm
3 | C2, C3, C6 | 100n | Unpolarised decoupling capacitors, pitch 5.0mm
1 | C4 | 100p | Unpolarised ceramic capacitor, pitch 5.0mm
1 | C5 | 10n | Unpolarised decoupling capacitors, pitch 5.0mm | Only use 10n if using DS1233 power/reset management IC
1 | C5 | 10uF Electro | Polarised radial electrolytic capacitor, pitch 5.0mm | Only use 10u if NOT using DS1233 power/reset management IC
9 | DC1-DC9 | 100n | Unpolarised decoupling capacitors, pitch 5.0mm
1 | C7 | 1uF Electro | Polarised radial electrolytic capacitor, pitch 2.5mm
1 | BAR1 | 8/10 segment BAR graph | LED Bar Graph 8 or 10 segment block | Note: Standard 8 Bar LEDs are NOT wired as required. Check schematic for Pinouts.
6 | DIG1-DIG6 | FND560 | 7 Segment LED, FND560 compatible | Common Cathode
1 | D0 | 1N4001-7 | 100V 1A General Purpose Rectifier Diode, DO-41 | Can be any from 1N4001 to 1N4007
7 | D1-D7 | 1N4148 | 100V 0.15A standard switching diode, DO-35
1 | L5 | 5mm LED | Speaker indicator, 5mm white LED | DO NOT mount Speaker indicator LED if using 10 segment Status LED bar
1 | L1 | 5mm LED | Power indicator, 5mm blue LED
1 | L2 | 5mm LED | Halt indicator, 5mm red LED | DO NOT mount Halt indicator LED if using 10 segment Status LED bar
2 | L3, L4 | 5mm RGB LED | "Disco LEDs", 5mm RGB LED (Round or Rectangular) | Use either round or rectangular RGB leds. Common Cathode
1 | PM1 | DS1233 | Power Monitor & Reset, TO-92 | This is optional but recommended.
8 | Q1-Q8 | BC547 | 0.1A Ic, 45V Vce, Small Signal NPN Transistor, TO-92
8 | Q9-Q16 | BC557 | 0.1A Ic, 45V Vce, PNP Small Signal Transistor, TO-92
1 | SD1 | 1N5817 | 20V 1A Schottky Barrier Rectifier Diode
1 | X1 | 4MHz XTAL | 4 Mhz Crystal Oscillator Package (8 or 14 DIP)
1 | REG1 | L7805 | Positive 1.5A 35V Linear Regulator | Output 5V, TO-220
1 | LCD1 | HD44780 20x4 Char LCD | 20x4 Character LCD, HD44780 compatible
1 | U1 | CD4049 | Hex inverter
1 | U2 | Z80A | Z80 CPU >= 4MHz
3 | U3, U10, U12 | 74HCT138 | 3 to 8 Decoder, active low
1 | U4 | 74HCT688 | 8-input comparator
1 | U5 | 74HCT86 | Quad 2-input XOR
2 | U6, U14 | 74HCT00 | Quad 2-input NAND
1 | U7 | 27c512/28c256/27c256 | UV/E EPROM 256Kb (32k), or UV 512Kb (64k), DIP-28
1 | U8 | MC62256 | 256kB (32k x 8) static RAM, DIP-28 wide or skinny
| U9 | Various | Memory expansion socket
1 | U11 | 74HCT30 | 8-input NAND
3 | U13, U16, U17 | 74HCT273 | 8-bit D-Type flip-flop with reset
1 | U15 | MM74C923 | 20-key encoder
1 | U18 | 74HCT373 | 8-bit latch, tri-state
1 | U19 | 74HCT245 | Octal bus tranceivers, tri-state
1 | U20 | MAX4544 | SPDT Analog switch | Analog switch only required if using Radio Ga Ga switched potentiometer
1 | FTDI Module | FTDI Module | USB to UART USB 2.0 UART Interface Module
1 8 pin or 14 pin DIP crystal socket
1 8 pin DIP socket
4 14 pin DIP socket
4 16 pin DIP socket
7 20 pin DIP socket
2 28 pin skinny DIP socket 2 28 pin DIP socket
1 28 pin ZIF socket
1 40 pin DIP socket
1 | BJ1 | Power Jack | DC Barrel Jack with an internal switch
1 | HS1 | Heatsink | TO-220 Heatsink
1 | J1 | Z80Bus_Socket | IDC 40pin Female Socket, vertical
1 | J2 | Z80Bus_Socket | IDC 40pin Female Socket, horizontal
1 | J3 | TEC Expander | Female connector, 02x10, horizontal
1 | J4 | Matrix Keyboard | IDC Male Header, 02x10, vertical
2 | J5 | FTDI_Module | Female connector, 01x06, vertical
1 | J6 | IOBus | Female connector, 01x10, vertical
1 | J7 | MEMBus | Female connector, 01x15, vertical
1 | J8 | G.Inp | Female connector, 01x04, vertical
1 | J9 | Joystick | 9-pin male D-SUB connector
1 | J10 | TEC GPIO | Female connector, 02x08, vertical
1 | USB1 | USB_B_OST_USB-B1HSxx | USB Type B connector | *See important notes on USB1 below
1 | J14 | GPIO Power | Pin Header, 01x02, vertical
2 | J15 | Test Points | 2x Male Jumper pins
1 | JP1 | Jumper, 3 pin | Shunted, Default "KB" (KB/HALT)
1 | JP2 | Jumper, 2 pin | Speaker jumper, Pin Header, 01x02, vertical | Only use speaker jumper pins if severing "Groundwalker" board link
7 | JP3 - JP9 | Jumper, 3 pin | 3 Pin Header (EPROM/Expansion size select)
11 | JP1-JP9, SW5 | 2 pin jumper shunts | To bridge the option selected
1 | LCD1 | LCD Header | Female connector, 01x16, vertical

## TEC-1G Parts List

1 | SP1 | Speaker | 8 ohm mini speaker
1 | SW1 | Power | DPDT Right Angled Slide Switch
1 | SW2 | Speed | SPDT Slide Switch | Only use SW2 if NOT using Radio Ga Ga analog switch and switched potentiometer
2 | SW3, SW4 | ROM Hi/Lo | SPDT Micro Slide Switch or Shunted 3 Pin Jumpers
2 | SW5 | Expansion ROM 27c256/Other | 2x 3 Pin Headers or Micro DPDT Slide Switch
1 | DIP1 | CONFIG | 3x DIP Switch SPST switch
Tactile switch key pad option
22 | MX0 - MX21 | Key Switches | 12mm tactile key switches
22 | | Key Caps | 12mm tactile key caps
Gateron MX LP mechanical switch key pad option
22 | MX0 - MX21 | Key Switches | Gateron MX low profile key switches
22 | MX0 - MX21 | Key Caps | Any key caps with Cherry MX compatible stems
17 | | Key Switch LEDs | Fulisik LEDs - White | Fulisik LEDs option only for Gateron MX LP mechanical key switches
2 Fulisik LEDs - Yellow
1 Fulisik LEDs - Green
1 Fulisik LEDs - Blue
1 Fulisik LEDs - Red
1 | SW6 | Fulisik Switch | Shunted, Default "ON" (Fulisik LEDs)

NOTE
Items highlighted in yellow are optional components.
Whilst IC sockets are optional they are recommended. It is highly recommended that at least sockets are installed for the Z80 CPU, ROM, RAM, and Expansion sockets.

*IMPORTANT NOTES ON USB1 - CAUTION!
The TEC-1G is more demanding on power than previous models, mostly due to its increased complexity and chip count.
A larger LCD with backlight, higher LED count on board, eg. if using Fulisik LEDs, and the optional GLCD with backlight also contribute to the increased power demand.
1. If using USB1 for power, you must install the DC Barrel Jack, or short two of the three pads on the board with a link
under where the power jack would mount. i.e. the two non-earthed connection points for the DC power jack.
2. Testing during the beta phase has found that most USB Chargers do not deliver enough current to satisfy the TEC-1G!
If using a USB-B socket for power, you must ensure that the USB power supply you are using can comfortably deliver 1.5A. Also note that most USB Chargers by default will limit there current delivery well below there rated current capacity!
The first signs of power delivery issues particularly with USB power will be corruption and instability on the 20x4 LCD display.

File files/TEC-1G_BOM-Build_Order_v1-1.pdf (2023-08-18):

## (Yellow = Optional)

Qty | Reference | Value | Description
| Step 1 Test Power Switchover (DC to USB) and Distribution
1 J13 | | USB_B_OST_USB-B1HSxx | USB Type B connector (Omit if using Barrel Jack only.)
1 BJ1 | | Power Jack | DC Barrel Jack w/ internal switch (join pins 2-3 if USB only)
1 D0 | | 1N4002 | 100V 1A General Purpose Rectifier Diode, DO-41 (Omit if USB only)
2 C2, C3 | | 100n | Unpolarised decoupling capacitors, pitch 5.0mm
1 L1 | | 5mm LED | Power indicator, Blue
1 REG1 | | L7805 (TO-220) | 5V Linear Regulator (Not required if using only USB power)
1 R1 | | 330R | 1/4 watt metal film 1% Resistor
1 SW1 | | Slide Switch | SPDT Slide or Toggle Switch

TEST

| Step 2 If Using mechanical keys with LED under-lighting
21 | 1.8mm LED | White | Shift key, and alpha numeric keys
2 1.8mm LED | | Yellow | Plus / minus keys
1 1.8mm LED | | Red | Reset key
1 1.8mm LED | | Green | GO key
1 1.8mm LED | | Blue | AD key
2 RN4, RN6 | | 330R | SIP9 8 resistor network
1 RN5 | | 330R | SIP5 4 resistor network
1 JP5 | | Jumper, 3 pole | Shunted, Default "ON"

TEST

| Step 3 Test Soldering Skillz & Clock
7 D1 - D7 | | 1N4148 | 100V 0.15A standard switching diode, DO-35
5 R5, R9, R14, R15, R19 | | 330R | 1/4 watt metal film 1% Resistor
1 R2 | | 2k2 | 1/4 watt metal film 1% Resistor
13 | R3 - R8, R10 - R12, R26 - R30 | 10k | 1/4 watt metal film 1% Resistor
2 R16, R31 | | 2K2 | 1/4 watt metal film 1% Resistor
7 R17, R20 - R25 | | 1K | 1/4 watt metal film 1% Resistor
1 C9 | | 100n | Unpolarised decoupling capacitors, pitch 5.0mm
1 C4 | | 10u/10n | 10u if no DS1233 / 10n with Power Manager
1 C6 | | 100p | Unpolarised decoupling capacitors, pitch 5.0mm
1 C10 | | 10u | Polarised radial electrolytic capacitor, pitch 2.5mm
5 X1, U5, U6, U11, U14 | | Socket | 14 pin DIP Socket
4 U1, U3, U10, U12 | | Socket | 16 pin DIP Socket
7 U4, U13, U15, U16, U17, U18, U19 | | Socket | 20 Pin Socket
1 U8 | | Socket | 28 pin skinny DIP Socket
1 U9 | | Socket | 28 pin wide DIP Socket
1 U7 | | Socket | 28 pin ZIF socket
1 U2 | | Socket | 40 pin DIP socket
1 X1 | | ACO-400MHz | 4 Mhz Crystal Oscillator Package (8 or 14 DIP)
2 SW2, SW6 | | Slide Switch | SPDT Slide or Toggle Switch

TEST

## TEC-1G Bill of Materials - In Build Order

LED lights up and confirm output at all power IC pads measure 5v with multimeter.

Re-Confirm output at all power IC pads measure 5v with multimeter, and check Pin 6 of Z80 for Clock Signal

Test Fulisik LEDs light up and switch off with JP5.

## (Yellow = Optional)

Qty | Reference | Value | Description
| Step 4 Test Soldering Skillz, Part 2
1 BAR1 | | Status BlinkenLites | LED Bar Graph 8 segment block
1 C9 | | 100n | Unpolarised capacitor, pitch 5.0mm
1 C4 | | 10u/10n | 10u if no DS1233 / 10n with Power Manager
1 C6 | | 100p | Unpolarised capacitor, pitch 5.0mm
1 C10 | | 10u | Polarised radial electrolytic capacitor, pitch 2.5mm
10 | DC1 - DC10 | 100n | Unpolarised decoupling capacitors, pitch 5.0mm
1 HS1 | | Heatsink | TO220 Horizontal (Only required with many peripherals)
1 JP3 | | Jumper, 3 pole | Shunted, Default "KB"
1 L2 | | 3mm LED | HALT indicator, Red
1 L3 | | 5mm LED | Speaker indicator, White
1 LCD1 | | LCD Header | Female connector, 01x16, vertical
1 PM1 | | DS1233 | Power Monitor & Reset, TO-92 (C4 is 10n if this is installed)
7 Q1 - Q7 | | BC547 | 0.1A Ic, 45V Vce, Small Signal NPN Transistor, TO-92
8 Q8 - Q15 | | BC557 | 0.1A Ic, 45V Vce, PNP Small Signal Transistor, TO-92
1 R18 | | 100R | 1/4 watt metal film 1% Resistor
1 RN1 | | 47K | SIP9 8 resistor network
1 RN7 | | 330R | SIP9 8 resistor network (Status BlinkenLites)
1 SD1 | | 1N5817 | 20V 1A Schottky Barrier Rectifier Diode
1 SP1 | | Speaker | 8 ohm
3 SW3, SW4, SW5 | | Jumper, 3 pole | 3 Pin Header with Shunt (EPROM size select)
1 SW8 | | CONFIG | 3x DIP Switch, Single Pole Single Throw (SPST) switch
1 VR1 | | 100K | Potentiometer, small, vertical
1 VR2 | | 10K | Potentiometer, small, vertical
1 C1 | | 1000U | Polarised radial electrolytic capacitor, pitch 5.0mm

## TEC-1G Bill of Materials - In Build Order

TEST

| Step 5 For TEC-1G Expandability, include the following
1 J1 | | TEC Deck Connector | IDC 40pin Female Socket, vertical
1 J2 | | Z80Bus Connector | IDC 40pin Female Socket, horizontal
1 J3 | | TEC Expander | Female Socket, 2x10, horizontal
1 J5 | | FTDI Module | Female Socket, 1x06, horizontal
1 J6 | | IOBus | Female Socket, 1x10, vertical
1 J7 | | MEMBus | Female Socket, 1x15, vertical
1 J8 | | GIMP Connector | Female Socket, 1x03, vertical
1 J12 | | GPIO Card Mount | Female Socket, 2x08, vertical
1 J14 | | GPIO Power | Female Socket, 1x02, vertical
2 J15 | | Test Points | Male Jumper Pin, 1x01, vertical
1 RN2 | | 4.7k | SIP9 8 resistor network
1 RN3 | | 10k | SIP9 8 resistor network
1 J11 | | Joystick | 9-pin male D-SUB connector
1 J4 | | Matrix Keyboard | IDC Male Header, 02x10, vertical

TEST

Power Cycle Test. Check power LED lights up.

Ensure all sockets are plumb and square. Solder 1 pin, check and adjust. Solder 2nd pin. Check and adjust. Solder rest of pins

## (Yellow = Optional)

Qty | Reference | Value | Description
| Step 6 Insert all chips
1 U1 | | CD4049 | Hex inverter
1 U2 | | Z80A | Z80 CPU with min clock 4Mhz
3 U3, U10, U12 | | 74HCT138 | Decoder 3 to 8 active low outputs
1 U4 | | 74HCT688 | 8 input comparator
1 U5 | | 74HCT86 | Quad 2-input XOR
1 U6 | | 74HCT00 | Quad 2-input NAND gate
1 U14 | | 74HCT00 | Quad 2-input NAND gate (memory protection)
1 U7 | | 27C256 or 28C256 | UV/E EPROM 256Kb (32K x 8), DIP-28
1 U8 | | MC62256 | 256Kb (32K x 8), DIP-28, wide or skinny
1 U11 | | 74HCT30 | 8-input NAND
3 U13, U16, U17 | | 74HCT273 | 8-bit D Flip-Flop, reset
1 U15 | | MM74C923 | 20-key encoder
1 U18 | | 74HCT373 | 8-bit Latch, 3-state outputs
1 U19 | | 74HCT245 | Octal BUS Transceivers, 3-State outputs (Matrix keyboard)
6 DIG1 - DIG6 | | FND560 | 7 Segment Display (suggest using pin sockets for these)

## TEC-1G Bill of Materials - In Build Order

TEST

| Step 7 Finishing UI Elements
22 | MX0 - MX21 | Key Switches | 12mm Tactile or Gateron MX (Low Profile, preferred)
1 LCD | | LCD | 20 x 4 Character LCD Module

TEST

| Step 8 For Serial Communications
1 FTDI Module
| Step 9 For extra ROM/RAM
1 U9 | | 2k, 4k, 8k, 16k or 32k | EXTRA ROM/RAM (optional)

Fire the TEC-1 up. Should get a beep and text on the LCD. Welcome to the TEC-1G!!

Fire the TEC-1 up. Should get a beep and numbers on the 7 segment digits. Welcome to the TEC-1D.

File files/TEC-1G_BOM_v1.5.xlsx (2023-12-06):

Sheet: TEC-1G_BOM_v1.4
TEC-1G Bill of Materials |  |  |  | Version 1.5
Part No. | Part | Description | Supplier | Supplier/Manufacter No. | Supplier Description | Supplier No. | AUD each | Qty | AUD Total | Notes
Resistors
R1, R5, R9, R13, R14, R18, R33 | 330R | 1/4 watt metal film 1% Resistor 330R | Mouser | MF1/4DCT52R3300F | Metal Film Resistors - Through Hole 1/4W 330 ohm 1% | 660-MF1/4DCT52R3300F | $0.18 | 7 | $1.25
R2, R15, R31 | 2k2 | 1/4 watt metal film 1% Resistor 2k2 | Mouser | MF1/4DCT52R2201F | Metal Film Resistors - Through Hole 1/4W 2.2K ohm 1% | 660-MF1/4DCT52R2201F | $0.23 | 3 | $0.68
R3, R4, R6-R8, R10-R12, R26-R30, R32 | 10k | 1/4 watt metal film 1% Resistor 10k | Mouser | MF1/4CCT52R1002F | Metal Film Resistors - Through Hole 10K 1% 50PPM | 660-MF1/4CCT52R1002F | $0.26 | 14 | $3.65 | *Bulk pricing on 10+ from Mouser
R16, R19-25 | 1k | 1/4 watt metal film 1% Resistor 1k | Mouser | MF1/4DCT52R1001F | Metal Film Resistors - Through Hole 1Kohms 1% 100PPM | 660-MF1/4DCT52R1001F | $0.21 | 8 | $1.69
R17 | 100R | 1/4 watt metal film 1% Resistor 100R | Mouser | MF1/4DCT52R1000F2 | Metal Film Resistors - Through Hole 100ohms 1% 100PPM | 660-MF1/4DCT52R1000F | $0.23 | 1 | $0.23
R34 | 0R | 1/4 watt metal film 1% Resistor 0R OR wire link | Mouser | 603-MF0207FTE52-0R | Metal Film Resistors - Through Hole 0 Ohms 600 mW 1 % | 603-MF0207FTE52-0R | $0.21 | 1 | $0.21
Resistor Networks
RN1, RN3 | 10k | SIP9 8 resistor network 10k | Mouser | 4609X-101-103LF | Resistor Networks & Arrays 9pins 47Kohms Bussed | 652-4609X-1LF-10K | $0.71 | 2 | $1.43
RN2 | 4k7 | SIP9 8 resistor network 4k7 | Mouser | 4609H-101-472LF | Resistor Networks & Arrays 9pins 4.7Kohms Bussed | 652-4609X-1LF-4.7K | $0.63 | 1 | $0.63
RN4, RN5, RN7 | 330R | SIP9 8 resistor network 330R | Mouser | 4609X-101-331LF | Resistor Networks & Arrays 9pins 330 OHMS Bussed | 652-4609X-1LF-330 | $0.74 | 3 | $2.23
RN6 | 330R | SIP5 4 resistor network 330R | Mouser | 4605X-101-331LF | Resistor Networks & Arrays 5pins 330 OHMS Bussed | 652-4605X-1LF-330 | $0.50 | 1 | $0.50
Variable Resistors
VR1 | 500k | Potentiometer, cermet 500k | Mouser | 3362H-1-504LF | Trimmer Resistors - Through Hole 1/4"SQ 500KOHMS 10% 0.5WATTS | 652-3362H-1-504LF | $2.87 | 1 | $2.87
VR1 (optional) | 500k | Potentiometer, horizontal, PCB Mount | AliExpress | RK097N | RK097N 500K Audio Amplifier Sealed Linear Volume Potentiometer Resistor 15mm Shaft 3 pins | https://www.aliexpress.com/item/1005002466299305.html?scm_id=1007.40000.327270.0&scm-url=1007.40000.327270.0 | $4.81 | 1 | $4.81 | *Comes in pack of 5, only 1 required
VR1/SW11 (optional - Radio Ga Ga) | 500k | SPST switching potentiometer, horizontal, PCB Mount | AliExpress | RV097NS | RV097NS Potentiometer 500K With A Switch Audio 5Pin Shaft 15mm Amplifier Sealing | https://www.aliexpress.com/item/1005003523748492.html | $3.65 | 1 | $3.65 | *Comes in pack of 5, only 1 required
VR2 | 10k | Potentiometer, cermet, 10k | Mouser | 3362H-1-103LF | Trimmer Resistors - Through Hole 1/4"SQ 10KOHMS 10% 0.5WATTS | 652-3362H-1-103LF | $3.03 | 1 | $3.03
Capacitors
C2, C3, C6 | 100n | Unpolarised decoupling capacitors, pitch 5.0mm | Mouser | K104K15X7RF53H5 | Multilayer Ceramic Capacitors MLCC - Leaded 0.1uF 50volts 10% X7R 5mm LS | 594-K104K15X7RF53H5 | $0.26 | 3 | $0.78
C4 | 100p | Unpolarised ceramic capacitor, pitch 5.0mm | Jaycar | RC5324 | 100pF 50VDC Ceramic Capacitors (x2) | RC5324 | $0.38 | 1 | $0.38 | *Comes in pack of 2, only 1 required
C5 | 10n | Unpolarised decoupling capacitors, pitch 5.0mm | Mouser | K103K10X7RF53H5 | Multilayer Ceramic Capacitors MLCC - Leaded 10000pF 50V 10% X7R 5mm LS | 594-K103K10X7RF53H5 | $0.29 | 1 | $0.29
DC1-DC9 | 100n | Unpolarised decoupling capacitors, pitch 5.0mm | Mouser | K104K15X7RF53H5 | Multilayer Ceramic Capacitors MLCC - Leaded 0.1uF 50volts 10% X7R 5mm LS | 594-K104K15X7RF53H5 | $0.26 | 9 | $2.33
Polarised Capacitors
C1 | 1000uF Electro | Polarised radial electrolytic capacitor, pitch 5.0mm | Mouser | UVK1E102MPD1TD | Aluminium Electrolytic Capacitors - Radial Leaded 1000uF 25 Volts 20% | 647-UVK1E102MPD1TD | $1.15 | 1 | $1.15
C5 | 10uF Electro | Polarised radial electrolytic capacitor, pitch 5.0mm | Mouser | ECA-1CM100 | Aluminium Electrolytic Capacitors - Radial Leaded 10uF 16V | 667-ECA-1CM100 | $0.32 | 1 | $0.32
C7 | 1uF Electro | Polarised radial electrolytic capacitor, pitch 2.5mm | Mouser | 50YXJ1M5X11 | Aluminium Electrolytic Capacitors - Radial Leaded LOW IMPEDANCE ELECTROLYTIC CAPACITORS | 232-50YXJ1M5X11 | $0.39 | 1 | $0.39
Semiconductors
BAR1 | 8 segment BAR graph (see note 1) | LED Bar Graph 8 segment block - Status Blinkenlights | AliExpress | B8R | LED Display 8 Segment Bar Graph Red | https://www.aliexpress.com/item/32914669443.html | $3.93 | 1 | $3.93 | CAUTION: 8 bar LEDs often have a different pin configuration than what's required! Note: First LED must be on pins 1&16 NOT 1&2.
BAR1 (optional) | 10 segment BAR graph | LED Bar Graph 10 segment block - Status Blinkenlights | Jaycar | ZD1704 | DIL LED Bar Graph - 10 x Red LEDS | ZD1704 | $2.95 | 1 | $2.95
DIG1-DIG6 | FND560 | 7 Segment LED, FND560 compatible | Jaycar | ZD1855 | FND500/LTS543R/S505RWB Common Cathode 7 Segment Display | ZD1855 | $3.50 | 6 | $21.00
D0 | 1N4002 | 100V 1A General Purpose Rectifier Diode, DO-41 | Mouser | 1N4002-T | Rectifiers 1A 100V | 583-1N4002-T | $0.34 | 1 | $0.34
D1-D7 | 1N4148 | 100V 0.15A standard switching diode, DO-35 | Mouser | 1N4148 | Diodes - General Purpose, Power, Switching 100V Io/200mA | 512-1N4148 | $0.16 | 7 | $1.13
L1 | 5mm LED | Power indicator, 5mm blue LED | Jaycar | ZD0185 | Blue 5mm LED 350mcd Round Diffused | ZD0185 | $0.95 | 1 | $0.95
L2 | 3mm LED | Halt indicator, 3mm red LED | Jaycar | ZD0100 | Red 3mm LED 40mcd Round Diffused | ZD0100 | $0.30 | 1 | $0.30
L3, L4 | 5mm RGB LED (see note 2) | "Disco LEDs", 5mm RGB LED | LEDsales | 5MM_RGB_WC_CC_14MIL | Big chip water clear 4 pin 5mm RGB LED - common cathode | 5MM_RGB_WC_CC_14MIL | $0.40 | 2 | $5.80 | https://www.ledsales.com.au/index.php?main_page=product_info&cPath=148_187&products_id=2764
L3, L4 (optional) | 5mm RGB LEDS Rectangular | "Disco LEDs", RGB LED Rectangular | AliExpress | SONGXIN Light | LEDs 255 Diode RGB LED Diffused Common CATHODE Square 2*5*5mm | https://www.aliexpress.com/item/4001163157378.html | $4.84 | 2 | $4.84 | *Comes in pack of 50 but only 2 required
L5 | 5mm LED | Speaker indicator, 5mm white LED | Jaycar | ZD0190 | White 5mm LED 4000mcd Round Clear | ZD0190 | $1.15 | 1 | $1.15
PM1 | DS1233 | Power Monitor & Reset, TO-92 | Mouser | DS1233-15+ | Supervisory Circuits 5V EconoReset | 700-DS1233-15 | $2.92 | 1 | $2.92
Q1-Q8 | BC547 | 0.1A Ic, 45V Vce, Small Signal NPN Transistor, TO-92 | Mouser | BC547B | Bipolar Transistors - BJT NPN 45V 100mA HFE/45 | 512-BC547B | $0.71 | 8 | $5.70
Q9-Q16 | BC557 | 0.1A Ic, 45V Vce, PNP Small Signal Transistor, TO-92 | Mouser | BC557B | Bipolar Transistors - BJT BJT, TO-92, 45V, 100mA, PNP | 637-BC557B | $0.39 | 8 | $3.11
SD1 | 1N5817 | 20V 1A Schottky Barrier Rectifier Diode | Mouser | 1N5817 | Schottky Diodes & Rectifiers Vr/20V Io/1A | 511-1N5817 | $0.52 | 1 | $0.52
X1 | 4MHz XTAL | 4 Mhz Crystal Oscillator Package (8 or 14 DIP) | Mouser | ECS-100AX-040 | Standard Clock Oscillators DIP-14 5V 4MHz | 520-TCF400-X | $4.97 | 1 | $4.97
REG1 | L7805 | Positive 1.5A 35V Linear Regulator, Output 5V, TO-220 | Jaycar | ZV1505 | 7805 +5V 1A Voltage Regulator TO-220 | ZV1505 | $1.95 | 1 | $1.95
LCD1 | HD44780 20x4 Char LCD | 20x4 Character LCD, HD44780 compatible | Mouser | LCD-20x4B | Display Development Tools 20X4 CHARACTER BLUE LCD W/BACKLIGHT | 992-LCD-20X4B | $29.08 | 1 | $29.08
Integrated Circuits
U1 | CD4049 | Hex inverter | Mouser | CD4049UBE | Buffers & Line Drivers Hex Inverting | 595-CD4049UBE | $1.13 | 1 | $1.13 | Do NOT use Fairchild part. TI part as listed is reliable.
U2 | Z80A | Z80 CPU >= 4MHz | Mouser | Z84C0010PEG | Microprocessors - MPU 10MHz CMOS CPU XTEMP | 692-Z84C0010PEG | $14.21 | 1 | $14.21
U3, U10, U12 | 74HCT138 | 3 to 8 Decoder, active low | Mouser | SN74HCT138N | Encoders, Decoders, Multiplexers & Demultiplexers Line Decoder | 595-SN74HCT138N | $1.23 | 3 | $3.69
U4 | 74HCT688 | 8-input comparator | Mouser | CD74HCT688E | Logic Comparators 8-Bit Magnitude | 595-CD74HCT688E | $1.57 | 1 | $1.57
U5 | 74HCT86 | Quad 2-input XOR | Mouser | CD74HC86E | Logic Gates Quad 2 Input XOR | 595-CD74HC86E | $1.44 | 1 | $1.44
U6, U14 | 74HCT00 | Quad 2-input NAND | Mouser | SN74HCT00N | Logic Gates Quad 2-Input NAND | 595-SN74HCT00N | $1.18 | 2 | $2.36
U7 | 27c256 | UV 256K (32k x 8) EPROM, DIP-28 | Jaycar | FM27C256 | Jaycar: 27C256 256K (32K x 8) Eprom IC | ZZ8471 | $14.95 | 1 | $14.95
U8 | MC62256 | 256kB (32k x 8) static RAM, DIP-28 wide or skinny | Mouser | AS6C62256-55PCN | SRAM 256K, 2.7-5.5V, 55ns 32K x 8 Asynch SRAM | 913-AS6C62256-55PCN | $5.73 | 1 | $5.73
U9 (optional) | Various (see note 4) | Memory expansion socket
U11 | 74HCT30 | 8-input NAND | Mouser | CD74HCT30E | Logic Gates 8-Input NAND | 595-CD74HCT30E | $0.88 | 1 | $0.88
U13, U16, U17 | 74HCT273 | 8-bit D-Type flip-flop with reset | Mouser | SN74HCT273N | Flip-Flops Octal w/ Clear | 595-SN74HCT273N | $1.52 | 3 | $4.56
U15 | MM74C923 | 20-key encoder |  |  |  |  |  | 1
U18 | 74HCT373 | 8-bit latch, tri-state | Mouser | SN74HCT373N | Latches Tri-St Octal D-Type | 595-SN74HCT373N | $2.53 | 1 | $2.53
U19 | 74HCT245 | Octal bus tranceivers, tri-state | Mouser | SN74HCT245N | Bus Transceivers Tri-State Octal Bus | 595-SN74HCT245N | $1.17 | 1 | $1.17
U20 | MAX4544 | SPDT Analog switch | Mouser | MAX4544CPA+ | Analogue Switch ICs Low-Voltage, Single-Supply Dual SPST/SPDT Analog Switches | 700-MAX4544CPA | $4.55 | 1 | $4.55
FTDI Module | FTDI Module | USB Bridge, USB to UART USB 2.0 UART Interface Module | Digikey | 284 | USB Bridge, USB to UART USB 2.0 UART Interface Module | 1528-1644-ND | $23.93 | 1 | $23.93
IC Sockets
 |  | 8 pin or 14 pin DIP crystal socket | Jaycar | PI6454 | 14 Pin Gold Insert Machined Pin IC Socket | PI6454 | $1.65 | 1 | $1.65
 |  | 8 pin DIP socket | Jaycar | PI6500 | 8 Pin Production (Low Cost) IC Socket | PI6500 | $0.45 | 1 | $0.45
 |  | 14 pin DIP socket | Jaycar | PI6501 | 14 Pin Production (Low Cost) IC Socket | PI6501 | $0.50 | 4 | $2.00
 |  | 16 pin DIP socket | Jaycar | PI6502 | 16 Pin Production (Low Cost) IC Socket | PI6502 | $0.55 | 4 | $2.20
 |  | 20 pin DIP socket | Jaycar | PI6504 | 20 Pin Production (Low Cost) IC Socket | PI6504 | $0.65 | 7 | $4.55
 |  | 28 pin skinny DIP socket | Jaycar | PI6510 | 28 Pin Production (Low Cost) IC Socket | PI6510 | $0.95 | 2 | $1.90
 |  | 28 pin DIP socket | Jaycar | PI6507 | 28 Pin Production (Low Cost) IC Socket | PI6507 | $0.95 | 2 | $1.90
 |  | 28 pin ZIF socket | Jaycar | PI6483 | ZIF Sockets - 28 Pins | PI6483 | $5.95 | 1 | $5.95
 |  | 40 pin DIP socket | Jaycar | PI6508 | 40 Pin Production (Low Cost) IC Socket | PI6508 | $1.20 | 1 | $1.20
Switches, Jumpers, Connectors
BJ1 | Power Jack | DC Barrel Jack with an internal switch | Mouser | CON-SOCJ-2155 | DC Power Connectors Power Jack/Connector 2.1mm x 5.5mm | 992-CON-SOCJ-2155 | $1.62 | 1 | $1.62
HS1 | Heatsink | TO-220 Heatsink | Digikey | 507302B00000G | HEATSINK TO-220 2.5W LOW PROFILE | HS115-ND | $0.49 | 1 | $0.49
J1 | Z80Bus_Socket | IDC 40pin Female Socket, vertical | Digikey | SFH11-PBPC-D20-ST-BK | 40 Position Header Connector 0.100" (2.54mm) Through Hole Gold | S9200-ND | $3.18 | 1 | $3.18
J2 | Z80Bus_Socket | IDC 40pin Female Socket, horizontal | Digikey | SFH11-PBPC-D20-RA-BK | 40 Position Header Connector 0.100" (2.54mm) Through Hole, Right Angle Gold | S9208-ND | $3.94 | 1 | $3.94
J3 | TEC Expander | Female connector, 02x10, horizontal | Digikey | SFH11-PBPC-D10-RA-BK | 20 Position Header Connector 0.100" (2.54mm) Through Hole, Right Angle Gold | S9205-ND | $2.27 | 1 | $2.27
J4 | Matrix Keyboard | IDC Male Header, 02x10, vertical | Mouser | TSS-110-02-S-D | Headers & Wire Housings .100" Shrouded Elevated Terminal Strip | 200-TSS11002SD | $9.64 | 1 | $9.64
J5 | FTDI_Module | Female connector, 01x06, vertical |  | ** | ** Female 1x connectors can be made from cutting back 40pin female header strips to fit | HM3230 | $2.95 | 2 | $5.90
J6 | IOBus | Female connector, 01x10, vertical |  | ** | ** Available from Jaycar: HM3230 @ $2.95 each x 2 will cover all 5 connectors marked with **
J7 | MEMBus | Female connector, 01x15, vertical |  | **
J8 | G.Inp | Female connector, 01x04, vertical |  | **
J9 | Joystick | 9-pin male D-SUB connector | Mouser | 182-009-113R161 | D-Sub Standard Connectors 9P Male Right Angle inside ground straps | 636-182-009-113R161 | $3.71 | 1 | $3.71
J10 | TEC GPIO | Female connector, 02x08, vertical | Digikey | PPTC082LFBN-RC | 16 Position Header Connector 0.100" (2.54mm) Through Hole Tin | S7076-ND | $1.61 | 1 | $1.61
USB1 (see note 5) | USB_B_OST_USB-B1HSxx | USB Type B connector | Mouser | 897-43-004-90-000000 | USB Connectors TYPE B SINGLE 43 PLATING | 575-8974349 | $2.75 | 1 | $2.75
J14 | GPIO Power | Pin Header, 01x02, vertical |  | * | * Pin headers and jumper pins can be made by cutting back a 40 pin header terminal strips | HM3212 | $1.45 | 1 | $1.45
J15 | Test Points | 2x Male Jumper pins |  | * | * Available from Jaycar: HM3212 @$1.45 each. Two will cover 6 parts entries marked with * |  |  | 2
JP1 | Jumper, 3 pin | Shunted, Default "KB" (KB/HALT) |  | * |  | 2223-MSS-102559-14A-D-ND |  | 1
JP2 | Jumper, 2 pin | Speaker jumper ("Groundwalker"), Pin header, 01x02, vertical |  | * |  |  |  | 1
JP3 - JP9 | Jumper, 3 pin | 3 Pin Header (EPROM/Expansion size select) |  | * |  |  |  | 7
JP1-JP9, SW5 | 2 pin jumper socket | 2-pin jumpers (EPROM/Expansion size select, Spkr, Kb/Halt) | Digikey | SPC02SYAN | 2 (1 x 2) Position Shunt Connector Black Closed Top 0.100" (2.54mm) Gold | S9001-ND | $0.15 | 11 | $1.65
LCD1 | LCD Header | Female connector, 01x16, vertical |  | ** |  |  |  | 1
SP1 | Speaker | 8 ohm mini speaker | Mouser | CVS-1708 | Speakers & Transducers Speakers | 490-CVS-1708 | $5.01 | 1 | $5.01
SW1 | Power | DPDT Right Angled Slide Switch | AliExpress | SK-22F39(SK-22F24) | 2P2T 2-Gear Handle Height 5mm Toggle Switch 6-Pin Without Fixed Pin Horizontal Sliding Switch | https://www.aliexpress.com/item/1005005956548601.html | $6.84 | 1 | $6.84 | *Comes in pack of 10, only 1 required
SW2 | Speed | SPDT Slide Switch | Digikey | SLW-1276864-4A-D | Slide Switch SPDT Through Hole | 2223-SLW-1276864-4A-D-ND | $1.28 | 1 | $1.28
SW3, SW4 | ROM Hi/Lo | SPDT Micro Slide Switch | Digikey | MSS-102559-14A-D | SPDT Micro Slide Switch | 2223-MSS-102559-14A-D-ND | $1.40 | 2 | $2.80
SW5 | Expansion ROM 27c256/Other | 2x 3 Pin Headers |  | * |  |  |  | 2
SW5 (optional) | Expansion ROM 27c256/Other | Micro PCB mount DPDT Slide Switch | Digikey | JS202011CQN | Slide Switch DPDT Through Hole | 401-2001-ND | $0.97 | 1 | $0.97
DIP1 | CONFIG | 3x DIP Switch, Single Pole Single Throw (SPST) switch | Jaycar | SM1013 | 3-Way DIL Switch | SM1013 | $2.25 | 1 | $2.25
MX0 - MX21 | Key Switches | 12mm tactile key switches | Digikey | PTS125SJK73-2 LFS | Tactile Switch SPST-NO Top Actuated Through Hole | CKN9142-ND | $0.65 | 22 | $14.19 | Bulk pricing on 10+ @ $0.645 each
 | Key Caps | 12mm tactile key caps | Digikey | B32-1360 | Square Tactile Switch Cap White Slip On | SW259-ND | $0.54 | 22 | $11.90
Keypad option - Gateron MX low profile mechanical keys
MX0 - MX21 | Key Switches | Gateron MX LP key switches | Gateron | KS-33 | Gateron KS-33 Low Profile 2.0 Mechanical Switch Set (Red) (x 35) | KS-33 | $21.98 | 1 | $21.98 | Gateron sell a 35 key set, of which 22 are required
 |  |  |  |  |  |  |  |  |  | https://www.gateron.com/products/gateron-ks-33-low-profile-20-switch-set?VariantsId=10706
 | Key Switch LEDs (option) | Fulisik LEDs | AliExpress |  | 100PCS/lot 1.8mm LED Diode Light Diffused Assorted Kit Green Blue White Yellow Red | https://www.aliexpress.com/item/1005004999517487.html | $5.56 | 1 | $5.56 | Mixed pack of 100 option provides enough of every colour required
 | Key Switch LEDs | Fulisik LEDs - White |  |  |  |  |  | 17
 |  | Fulisik LEDs - Yellow | Digikey | LTL-709Y | Yellow 588nm LED Indication - Discrete 2.1V Radial | 160-1085-ND | $0.63 | 2 | $1.26
 |  | Fulisik LEDs - Green | Digikey | LTL-709L | Green 561nm LED Indication - Discrete 2.1V Radial | 160-1086-ND | $0.81 | 1 | $0.81
 |  | Fulisik LEDs - Blue |  |  |  |  |  | 1
 |  | Fulisik LEDs - Red | Digikey | LTL-709E | Red 623nm LED Indication - Discrete 2V Radial | 160-1084-ND | $0.63 | 1 | $0.63
SW6 | Fulisik Switch | Shunted, Default "ON" (Fulisik LEDs) | Digikey | MSS-102559-14A-D | SPDT Micro Slide Switch | 2223-MSS-102559-14A-D-ND | $1.31 | 1 | $1.31
Parts to source | Part | Description | Qty
U15 | MM74C923 | 20-key encoder | 1 |  |  | Approx. | $10.00
 | Key Caps | For Gateron MX LP mechanical keypad option only* | 22 |  |  | Approx. | $30.00
 |  | * Must be low profile keycaps with Cherry MX compatible stems. Double shot key caps with translucent characters preferred for Fulisik LED illumination. |  |  |  | Total cost: 12mm tactile keypad option |  |  | $321.10 | *Total costs will be lower due to duplication with optional parts. Final cost will depend on parts options chosen.
NOTES |  |  |  |  |  | Total cost: Gateron MX mechanical keypad option |  |  | $356.56
1. BAR1 | Can be 8 segment Bar LED or 10 segment Bar LED. Caution: 8 segment bar LEDs are often not wired in the correct configuration! If using 10 segment bar LEDs, which are easier to obtain, DO NOT mount Halt and Speaker LEDs!
2. L3, L4 | Can be round or rectangular 5mm RGB LEDS. Both options provided. Round RGB LEDs easier to obtain from major suppliers.
3. U7 | ROMs for current monitors can be of type 27c256 (available from Jaycar), 28c256 (getting hard to source), or 27c512 (only available via Schenzen markets). Also supports older 2/4K ROMS 2716 and 2732A for old TEC monitors.
4. U9 (Various) | Expansion socket is optional to populate. Recommend 32k NVRAM option (e.g. Dallas DS1230Y) for saving work. Can also hold RAM or ROM - 6116, 62256, 2716, 2732A, 27c256 or 28c256.
5. USB1 | It is recommended NOT to use the USB connector for power supply and will be deleted from future versions of the PCB, as it interferes with GPIO boards mounted above it.
**Shipping is not included in parts cost from major suppliers, as free shipping can be obtained if your order is of enough value. Shipping included for AliExpress items, RGB LEDs, and Gateron LP key switches only.

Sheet: Document History
Document History
Date | Action | Board Revision | Description | Author
2023-08-03 | Initial BOM Released | Beta 1 | Initial short form BOM released to TEC-1 Z80 Computer Group for pre-release parts list. | Mark Jelic
2023-08-11 | Detailed BOM Prepared | Beta 1 | To source components and provide an easy list to order from for everyone not buying a full kit. | Ian McLean
 |  |  | Inspiration comes from the BOM supplied with the Amiga 500++ reproduction board.
 |  |  | Suppliers kept to a minimum, only major suppliers (Mouser, Digikey and Jaycar).
 |  |  | All parts checked and in stock from respective suppliers at time of Detailed BOM release.
 |  |  | Cheapest prices used within reason of not doing a prohibitively exhaustive search.
 |  |  | i.e. Cheaper prices may be found!
2023-08-12 | Checked | Beta 1 | Detailed BOM draft checked for errors and omissions. | Mark Jelic
 |  |  | Cheaper micro slide switches from Digikey.
 |  |  | Better suited toggle slide switches for SW1, SW2, SW6.
 |  |  | Change SW3, SW4, SW5 (ROM select) from micro slide switches to jumpers.
 |  |  | (Micro slide switches wont fit on layout).
 |  |  | Add 2-pin jumpers for ROM select to BOM.
 |  |  | Add Gateron MX keys and Fulisik LEDs option.
2023-08-12 | Updated | Beta 1 | Detailed BOM updated with changes from Mark Jelic. | Ian McLean
2023-08-13 | Detailed BOM Released | Beta 1 | Detailed BOM v1 released to TEC-1 Z80 Computer Group. | Ian McLean
2023-08-14 | Change C10 from 10uF -> 1uF | Beta 1 | On the original TEC this cap was changed from 1u to 10u when the crystal oscillator board was | Mark Jelic
 |  |  | installed to introduce an approx 100ms delay between when a key was pressed on the keypad
 |  |  | and when the 74C923 generated an NMI to the CPU. This was to prevent key bounces at faster
 |  |  | clock speeds.
 |  |  | However, it has been discovered through testing that newer faster responding tactile keys and
 |  |  | now especially with super responsive mechanical keys that a noticeable delay is introduced when
 |  |  | a key is pressed. This delay was not noticeable on the old original round push button keys.
 |  |  | Changed back to 1u to remove the delay. Key bounce is unlikely to be as much an issue with
 |  |  | modern responsive keys and tactile switches.
2023-08-14 | Updated BOM Released | Beta 1 (5 boards released to testers) | Updated detailed BOM v1.1 released to TEC-1 Z80 Computer Group | Ian McLean
2023-09-02 | Updated BOM Prepared | Beta 2 | Updated BOM to v1.2. Changes made for Beta 2 board release | Ian McLean
2023-09-26 | Changes to BOM | Beta 2 | Updated BOM to v1.3. Changes made to BOM through beta2 testing | Ian McLean
 |  |  | 1. Mistake in resistor numbering. R15 was listed twice, first instance should be R14. | With thanks to:
 |  |  | 2. U20 analog switch part number changed from TS5A3159DCKR to TS5A3159DBVRE4. | Mark Jelic
 |  |  | Original part is an SC-70-6 package but the footprint on the board is for a SOT-23-6. | Craig Hart
 |  |  | Seeing as a SOT-23-06 was intended in the first place, the footprint remains and the part has | James Elphick
 |  |  | been changed to a suitable equivalent, and much easier to solder SOT-23-6 package!
 |  |  | 3. The 8 bar status led BAR1 was an incorrect part. Through testing it was dicovered that 8 bar LEDs
 |  |  | commonly sold through major suppliers do not conform to the same internal pin layout.
 |  |  | The part in the BOM is a now 10 bar as they are available, where as 8 bar with the correct
 |  |  | configuration are not easily available. It means leaving off two LEDs hanging off to one side.
 |  |  | 4. RN1 changed from 47k to 10k. It was discovered through testing that weaker 47k pullups on the
 |  |  | data lines was causing issues on the D5 data line, where the shift key is connected. This issue
 |  |  | only affects one older monitor, mon-2, in 2K mode, with fast clock and the LCD not attached.
2023-10-09 | Final Production BOM Prepared | Production | Updated BOM to v1.4 for production release. Changed made from Beta2 -> Production: | Ian McLean
 |  |  | 1. ROM jumpers configured to allow 64K 27c512 for ROM socket. | With thanks to:
 |  |  | 2. ROM jumpers changed to allow for proper support of 27c256 in both ROM and expansion sockets. | Mark Jelic
 |  |  | 3. ROM jumper added to allow 6116 RAM in expansion socket | James Elphick
 |  |  | 4. Analog switch changed from SOT23-6 to DIP8 MAX4544 package after issues with clock signal | Dev Team
 |  |  | cross-talk in beta testing with SMD analog switch. | Beta testers
 |  |  | 5. 8 bar status LED changed to allow option of easier to obtain 10 bar status LED
 |  |  | 6. Resistor R33 added to lower brightness on RGB LEDs
 |  |  | 7. R34 added for future testing with analog switch - to be jumpered initially or 0R resistor fitted.
 |  |  | 8. Optional speaker on/off jumper added
 |  |  | 9. L3, L4 RGB LEDS part change to cheaper local supplier. These also follow the correct pinout for
 |  |  | the TEC-1G, which is RKGB. The previous part from Mouser, HV-5RGB60, used the pinout BKRG.
 |  |  | 10. Final component renumbering

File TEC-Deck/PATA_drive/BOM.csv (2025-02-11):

Reference | Value | Notes
D1 | 3mm Red LED
J1 | 02x20 Female Header | 2.54mm Pitch, Long Pins
J2 | 02x22 Male Header | 2.00mm Pitch (IDE)
J3 | 01x10 Female Header | 2.54mm Pitch, Long Pins
J4 | 01x15 Female Header | 2.54mm Pitch, Long Pins
J5 | 02x07 Male Header | 2.54mm Pitch
R1,R3 | 10K
R2 | 330R
R4,R5 | 1K
U1 | 74HCT08 | http://www.ti.com/lit/gpn/sn74HCT08
U2,U6 | 74HCT574 | http://www.ti.com/lit/gpn/sn74HCT574
U3 | 74HCT139 | http://www.ti.com/lit/gpn/sn74HCT139
U4 | 74HCT32 | http://www.ti.com/lit/gpn/sn74HCT32
U5 | 74HCT74 | http://www.ti.com/lit/gpn/sn74HCT74
U7 | 74HCT245 | http://www.ti.com/lit/gpn/sn74HCT245
U8 | 74HCT138 | http://www.ti.com/lit/gpn/sn74HCT138
IC Sockets | DIP-14 | x3
IC Sockets | DIP-16 | x2
IC Sockets | DIP-20 | x3
Connector | 02x22 2mm IDC Cable | 2mm Pitch Connectors and Ribbon
Connector | PATA to USB 2.0 | https://www.ebay.com.au/itm/195287884573
HDD | PATA Drive | https://www.ebay.com.au/itm/151955808319
For Compact Flash instead of a hard drive use:
Connector | CF to IDE | https://www.ebay.com.au/itm/395749524762
Adaptor | CF to USB 3.0 | https://www.ebay.com.au/itm/373440358351
CF | CF Card | https://www.ebay.com.au/itm/305537726616

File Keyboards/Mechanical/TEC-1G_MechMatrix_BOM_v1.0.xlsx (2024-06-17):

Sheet: Cherry
TEC-1G Mechanical Matrix Keyboard (Cherry) Bill of Materials |  |  |  | Version 1.0
Part No. | Part | Description | Supplier | Supplier/Manufacter No. | Supplier Description | Supplier No. | AUD each | Qty | AUD Total | Notes
PCB
PCB | Keyboard PCB | Matrix Mechanical Keyboard for TEC-1G - PCB Only | mjelic - Ebay | - | - | - | $20.00 | 1 | $20.00
Resistors
R1, R2 | 330R | 1/4 Watt Metal Film 1% Resistor 330R | Mouser | MF1/4DCT52R3300F | Metal Film Resistors - Through Hole 1/4W 330 ohm 1% | 660-MF1/4DCT52R3300F | $0.22 | 2 | $0.44 | Order QTY of 10 costs $0.77
Semiconductors
L1, L2 | 3mm LED | Power Indicator and Caps Lock Indicator | LEDSales | 3mmBLUE5000 | Blue 3mm Superbright LED 5000mcd Round Clear | 3mmBLUE5000 | $0.15 | 5 | $0.75 | Minimum order QTY of 5 1.8mm LEDs may be substituted
Switches, Jumpers, Connectors
MX1 - MX60 | Key Switch | Cherry MX 5-Pin Linear/Tactile/Clicky Switch (**Note 1) | PC Case Gear | 6925758625166 | Akko Cream Blue Pro V3 Switches 45 Pack (Tactile) | 6925758625166 | $19.00 | 2 | $38.00
STB1 - STB3 | Stabiliser | Cherry-Compatible PCB Screw-In Stabilisers | PC Case Gear | 6925758616515 | Akko Screw-In Stabiliser White | 6925758616515 | $15.00 | 1 | $15.00 | 2 x 2U and 1 x 6.25U required from this pack
J1 | Matrix Keyboard | IDC Male Header, 02x10, Vertical | Mouser | BHR-20-VUA | Headers & Wire Housings 20P Straight Header | 737-BHR-20-VUA | $0.64 | 1 | $0.64
KC1 - KC60 | Key Caps | Cherry Stem Compatible Shinethrough Keycaps | PC Case Gear | GLO-KC-ABS-USKIT-B | Glorious ABS Doubleshot V2 Keycaps Black | GLO-KC-ABS-USKIT-B | $39.00 | 1 | $39.00 | Any Cherry-compatible keycap set may be substituted
Optional LED lighting
R3 - R64 | 330R | 1/4 Watt 0805 SMD 5% Resistor 330R (**Note 2) | Mouser | RK73B2ATTD331J | Thick Film Resistors - SMD 1/4 Watts 330ohms 5% | 660-RK73B2ATTD331J | $0.01 | 100 | $1.40 | QTY of 62 required, strongly recommend order QTY of 100
L3 - L64 | 1.8mm LED | FullisikTM Backlight LEDs | LEDSales | 1.8WHT | White Superbright 1.8mm LED | 1.8WHT | $0.12 | 100 | $12.00 | QTY of 62 required, strongly recommend order QTY of 100 Part number for white LED provided but other colours including red, blue, green or yellow may be substituted
SW1, SW2 | LED Switch | FullisikTM LED Lighting Power/Mode Switches | Mouser | EG1271A | E-Switch SPDT Slide Switch 30VDC 0.3A | 612-EG1271A | $1.37 | 2 | $2.74
 |  |  |  |  |  | Total cost: Standard Cherry MX |  |  | $113.83
NOTES |  |  |  |  |  | Total cost: Cherry MX + optional LED lighting |  |  | $129.97
1. MX1 - MX60 | 5-pin switches are HIGHLY recommended as they are self-aligning. LED builds require compatibility with 1.8mm LEDs (installed on top-side or underside) and shine-through switch housing.
2. R3 - R64 | SMD SOLDERING REQUIRED IF NOT PRE-POPULATED! Advanced skills required if using standard soldering iron. Hotplate or hot-air soldering with SMD solder paste is preferred method.
**Shipping is not included in parts cost from major suppliers, as free shipping can be obtained if your order is of enough value.

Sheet: Gateron
TEC-1G Mechanical Matrix Keyboard (Gateron LP) Bill of Materials |  |  |  | Version 1.0
Part No. | Part | Description | Supplier | Supplier/Manufacter No. | Supplier Description | Supplier No. | AUD each | Qty | AUD Total | Notes
PCB
PCB | Keyboard PCB | Matrix Mechanical Keyboard for TEC-1G - PCB Only | mjelic - Ebay | - | - | - | $20.00 | 1 | $20.00
Plate
Plate | Keyboard Plate | Matrix Mechanical Plate for TEC-1G | mjelic - Ebay | - | - | - | $20.00 | 1 | $20.00
Resistors
R1, R2 | 330R | 1/4 Watt Metal Film 1% Resistor 330R | Mouser | MF1/4DCT52R3300F | Metal Film Resistors - Through Hole 1/4W 330 ohm 1% | 660-MF1/4DCT52R3300F | $0.22 | 2 | $0.44 | Order QTY of 10 costs $0.77
Semiconductors
L1, L2 | 3mm LED | Power Indicator and Caps Lock Indicator | LEDSales | 3mmBLUE5000 | Blue 3mm Superbright LED 5000mcd Round Clear | 3mmBLUE5000 | $0.15 | 5 | $0.75 | Minimum order QTY of 5 1.8mm LEDs may be substituted
Switches, Jumpers, Connectors
GL1 - GL60 | Key Switch | Gateron KS-33 Low Profile Linear/Tactile/Clicky Switch | PC Case Gear | ACCNPLPSWRD | Gateron Low-Profile 2.0 Switch Set Lubed 100 Pack Red (NuPhy) | ACCNPLPSWRD | $39.00 | 1 | $39.00 | Can be Gateron KS-33 linear, tactile or clicky switch
STB1 - STB3 | Stabiliser | Gateron Low Profile PCB Screw-In Stabilisers | GATERON Official Store - Aliexpress | 4-2U 1-6.25U | GATERON Low Profile Stabilizer Plated Mounted Black Customized 6.25u 2u Low Profile Switch DIY Hotswap Available For Keyboard | 4-2U 1-6.25U | $18.26 | 1 | $18.26 | 2 x 2U and 1 x 6.25U required from this pack
J1 | Matrix Keyboard | IDC Male Header, 02x10, Vertical | Mouser | BHR-20-VUA | Headers & Wire Housings 20P Straight Header | 737-BHR-20-VUA | $0.64 | 1 | $0.64
KC1 - KC60 | Key Caps | Gateron Low Profile Compatible Shinethrough Keycaps | N/A | N/A | N/A | N/A | $40.00 | 1 | $40.00 | TBA, estimated price
Optional LED lighting
R3 - R64 | 330R | 1/4 Watt 0805 SMD 5% Resistor 330R (**Note 1) | Mouser | RK73B2ATTD331J | Thick Film Resistors - SMD 1/4 Watts 330ohms 5% | 660-RK73B2ATTD331J | $0.01 | 100 | $1.40 | QTY of 62 required, strongly recommend order QTY of 100
L3 - L64 | 1.8mm LED | FullisikTM Backlight LEDs | LEDSales | 1.8WHT | White Superbright 1.8mm LED | 1.8WHT | $0.12 | 100 | $12.00 | QTY of 62 required, strongly recommend order QTY of 100 Part number for white LED provided but other colours including red, blue, green or yellow may be substituted
SW1, SW2 | LED Switch | FullisikTM LED Lighting Power/Mode Switches | Mouser | EG1271A | E-Switch SPDT Slide Switch 30VDC 0.3A | 612-EG1271A | $1.37 | 2 | $2.74
 |  |  |  |  |  | Total cost: Standard Gateron LP |  |  | $139.09
NOTES |  |  |  |  |  | Total cost: Cherry MX + optional LED lighting |  |  | $155.23
1. R3 - R64 | SMD SOLDERING REQUIRED IF NOT PRE-POPULATED! Advanced skills required if using standard soldering iron. Hotplate or hot-air soldering with SMD solder paste is preferred method.
**Shipping is not included in parts cost from major suppliers, as free shipping can be obtained if your order is of enough value.

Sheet: Document History
Document History
Date | Action | Board Revision | Description | Author
2024-06-11 | Initial BOM Released | Production Rev 1 | Initial BOM released for Revision 1 board. | James Elphick

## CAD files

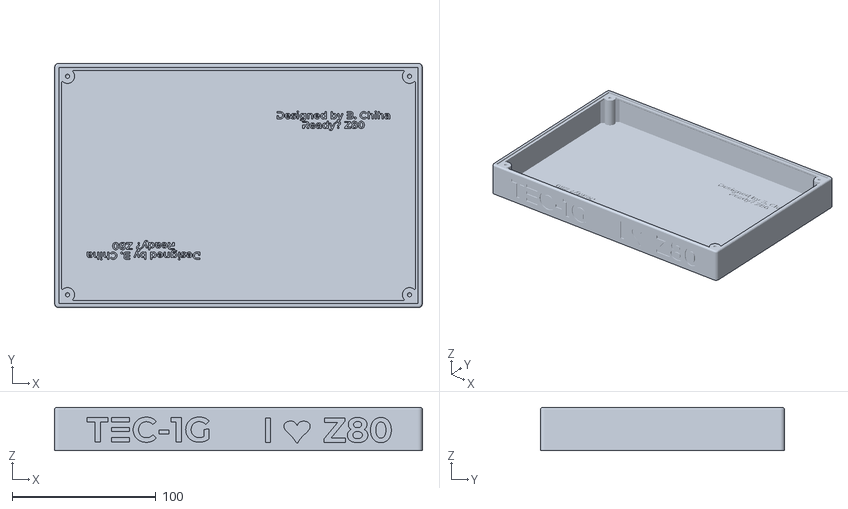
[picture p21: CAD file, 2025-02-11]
Cases/BrianC/TEC-1G_Box_Full.stl
256.0 x 170.0 x 30.0

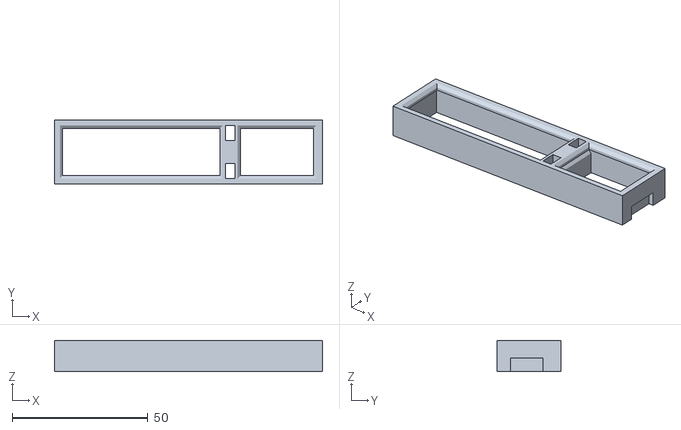
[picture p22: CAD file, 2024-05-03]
Cases/7Segs/TEC-1G_7Seg-Bezel-LightCutout.stl
98.8 x 23.5 x 11.5

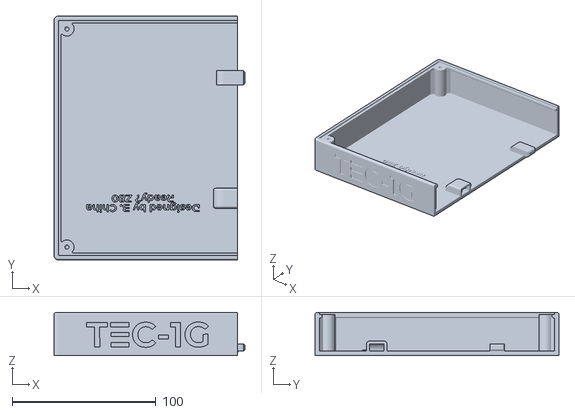
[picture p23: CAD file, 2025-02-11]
Cases/BrianC/TEC-1G_Box_Half.stl
133.0 x 170.0 x 30.0

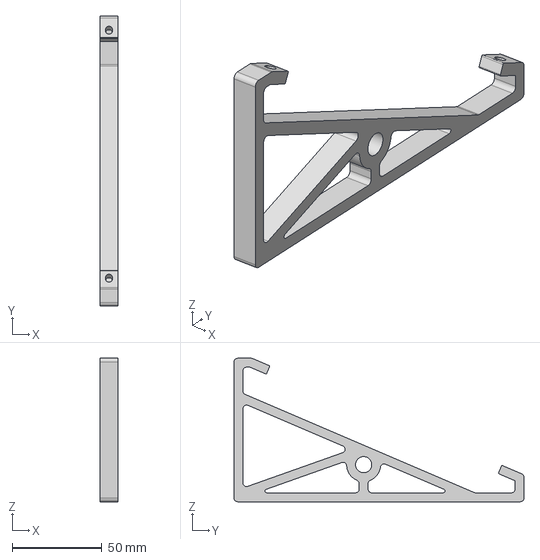
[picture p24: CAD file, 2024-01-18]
Cases/JamesE/JamesE_TEC-1G-Stands_v1.step
10.0 x 161.7 x 80.0 mm

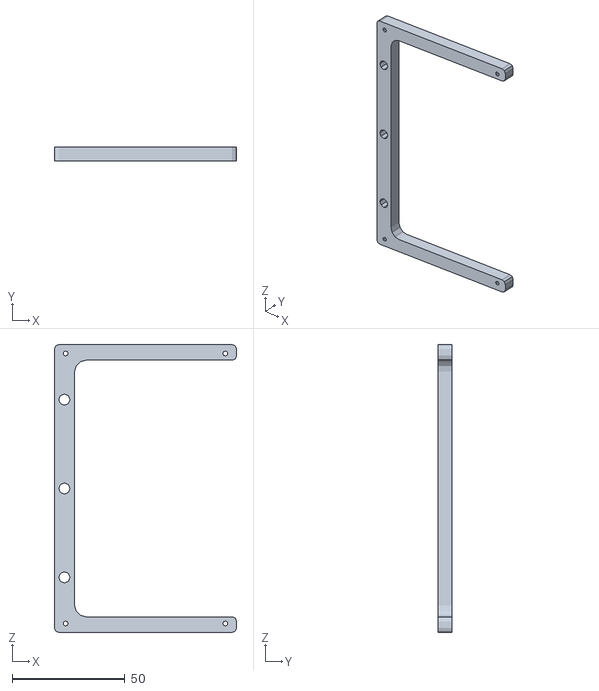
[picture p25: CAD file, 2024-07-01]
Keyboards/Mechanical/JamesE_PlateStand_LHS.stl
81.0 x 6.40 x 128.0

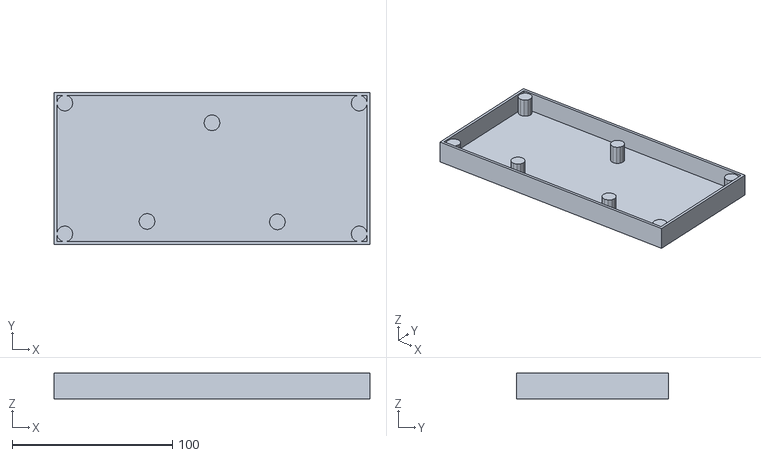
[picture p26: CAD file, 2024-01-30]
Keyboards/Tactile/Charlie_12mm_Matrix_Keyboard_Case_v1.stl
197.0 x 95.0 x 16.0

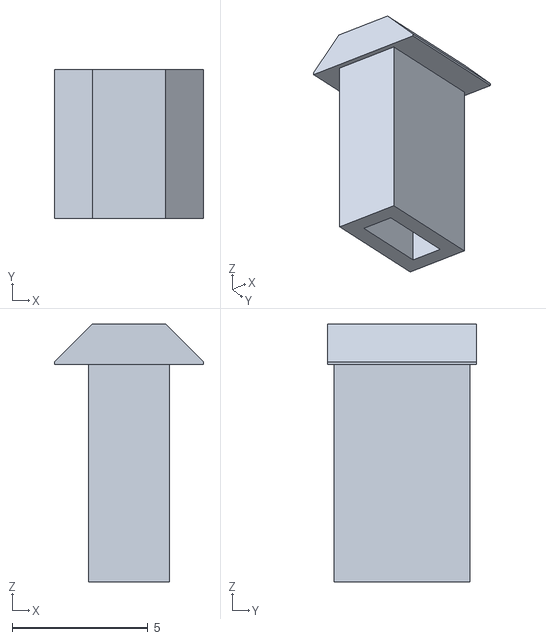
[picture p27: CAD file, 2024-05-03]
Cases/7Segs/TEC-1G_7Seg-Bezel-LightPipe.stl
5.50 x 5.50 x 9.50

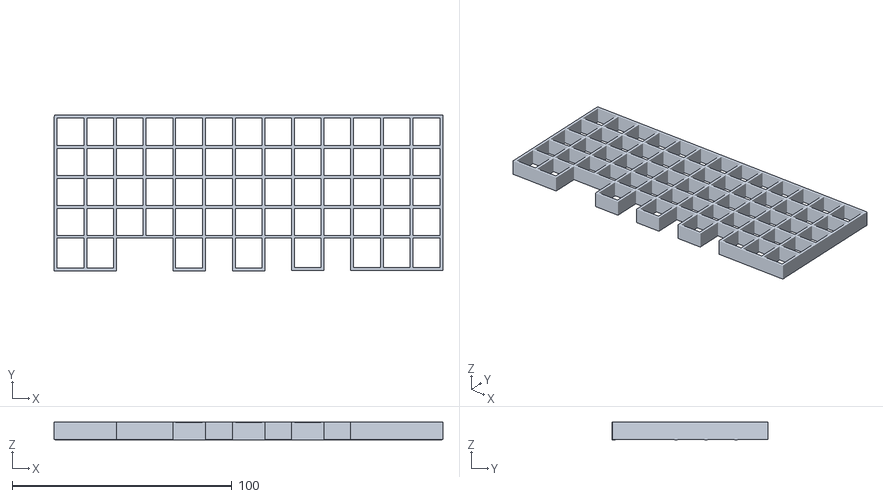
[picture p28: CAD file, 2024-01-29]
Keyboards/Tactile/12mm_Matrix_Frame_v1-0.stl
177.2 x 71.2 x 8.05

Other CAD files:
Cases/JamesE/JamesE_TEC-1G-Stands_v1.stl

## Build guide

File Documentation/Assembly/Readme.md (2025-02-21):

# Assembly Instructions
The following is a compiled set of instructions for assembling the TEC-1G, along with tests you should do along the way to ensure you have a successful build.

Building the 1G is not complex, but it should not be rushed and there is an ideal order of assembly. Allow yourself at least 6 hours to go through all the soldering and tests.

The parts are all readily available through many suppliers as detailed in the Bill of Materials, but there will also be a Kit available for purchase on eBay, **Coming Soon®**

## 1. [Required and Suggested Tools and Materials](./Tools.md)
This part is obvious and you probably have everything you need if you have an interest in this kind of hobby.

## 2. [Compononents & Identifiers](./Components.md)
Some components can be hard to identify, and most are critical in the orientation required to install them. Here is a quick overview.

## 3. [The Power Circuit](./Power.md)
The most critcal part of any circuit is stable power, so this is the next part we focus on so that all the subsequesnt soldering you do can be tested for shorts and the like.

## 4. [The Fullisik Keyboard](./Fullisik.md)
If you have opted to have the most luxurious typing experince ever designed for a Z80 SBC, and want to have the maximum amount of envy from all the other hobbyist plebs, then you will have opted for the Fullisik Mechanical Keyboard, bro!  The very pretty but fiddly little LEDs need to be installed and tested first.

If you have opted for the pedestrian-level keyboard using the 12mm Tactiles, then this step can be skipped, with the keys (both Tactile and Mechanical) soldered on last.

## 13. [Jumpers & Switches](./Jumpers+Switches.md)
Skipping ahead a little... You've finished soldering it all up, and you want to power it on... But what do all the Jumpers and Switches do?

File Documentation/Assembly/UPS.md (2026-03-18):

## Powering the TEC-1G with a UPS Battery Pack

Late in 2025, we found a great little UPS battery pack that with just two lithium batteries, 
was able to power the 1G, with all lights and sounds blazing, for up to 6 hours! The UPS uses a USB-C
cable to charge it and passes power through as well, so you have no need for a 9v power pack. The UPS
supplies a very smooth 5V direct to the power rails, so you don't even need a regulator or heatsink.

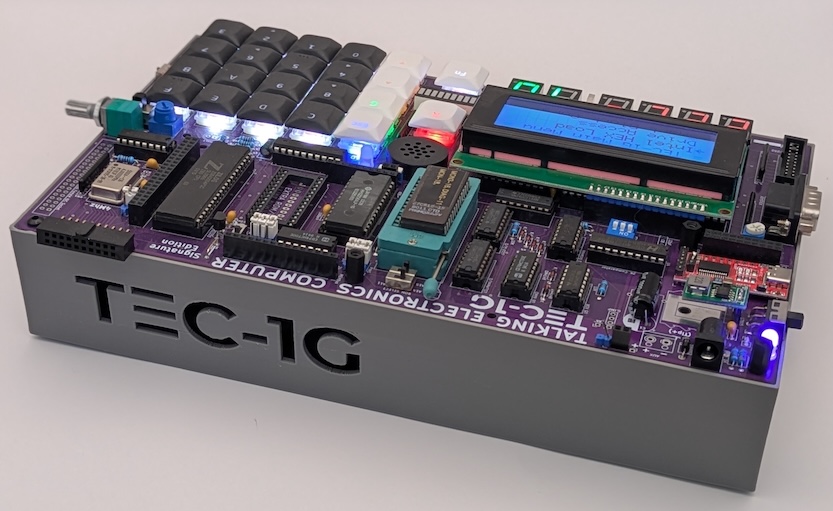
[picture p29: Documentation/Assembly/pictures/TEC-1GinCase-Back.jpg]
Portable TEC-1G


Oh, and did I mention that it makes your TEC-1G totally portable!  Couple it with the Official TEC-1G
3D Printed Case, and you have one very slick Z80 machine.

Here are the links to the Tindie Store if you want to get your hands on either product.
https://www.tindie.com/stores/tec1/

The UPS kit is a very simple one, with the UPS module that manages all the smarts of converting USB-C
into a smooth 5v, charging the two 3.7v lithium batteries, and continuing to supply power 
even if the USB-C cable is pulled out! The kit also comes with a couple of JST conectors 
so you can disconnect the Battery Pack safely if needed, and lastly comes with a bunch of 
standoffs to mount the UPS to the main PCB and have a balancing leg of standoffs on the other corner.

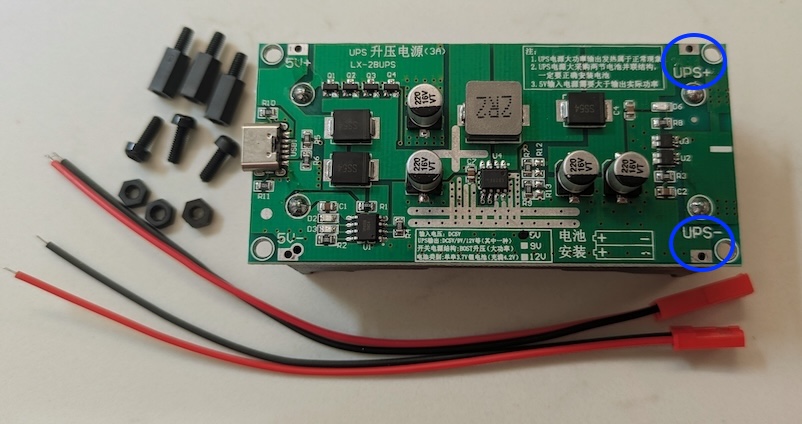
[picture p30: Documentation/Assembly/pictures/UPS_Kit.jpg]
UPS Kit


Please note that if you are installing this into the official TEC-1G Case, you don't need the
standoffs as the UPS is mounted inside the case, not to the PCB directly. The JST connectors
make it easy to have either of the mounting options.

Speaking of those connectors, you solder one of those (I use the Male on the supply and 
Female on the Device, being the 1G) is to the rectangular solder pads to the right of the Battery Pack pcb,
just next to the mounting holes, marked as UPS+ (red wire) and UPS- (black wire). These are circled in blue
in the picture above. No other connections to the UPS are required, other than the USB-C cable to 
charge up the batteries.

### Installation Guide

From version 1.2 Signature Edition of the PCB, there is a dedicated set of solder points
you use for the UPS, but previous boards can also make use of it, but you have to solder it to
a different location. The important thing to remember is that you have to be able to switch
the power off, and that means the power connections of the UPS have to be before the power switch.

For PCBs that had the (failed) USB-A connection, you can use the pads as shown in the picture. 
Pin 1 for Positive and Pin 4 for Ground.

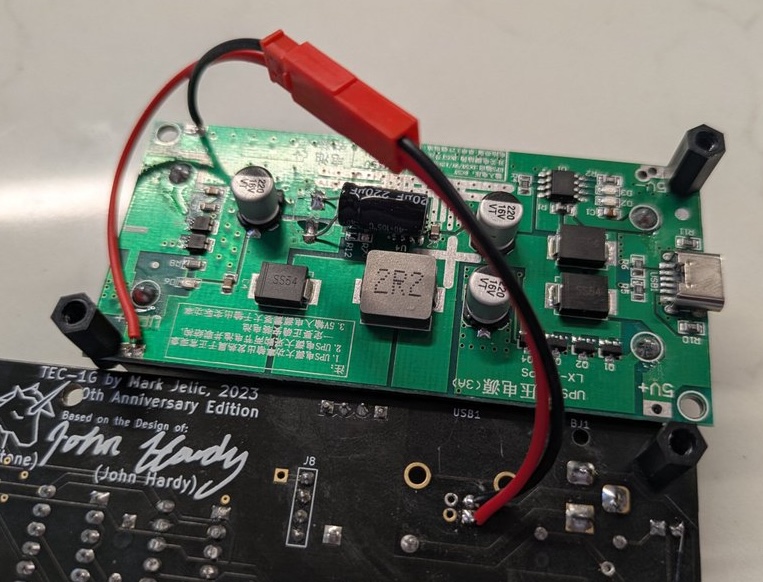
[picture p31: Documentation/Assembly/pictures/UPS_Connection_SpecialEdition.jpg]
Special Edition


** More to come. But this should get most people going **

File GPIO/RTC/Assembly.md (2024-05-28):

# TEC-1G GPIO RTC Assembly Instructions

Coming Soon®...

But while you wait, you can watch the Build Video on YouTube: https://www.youtube.com/watch?v=rAuSyqJuico
Its a long video but the important part is the last 5 minutes, about Initialising the RTC.

https://youtu.be/rAuSyqJuico

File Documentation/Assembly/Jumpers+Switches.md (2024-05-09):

# TEC-1G - Jumpers & Switches

## EPROM - Pin 1
Make sure Pin 1 of the EPROM (whether it is the 28 or the 24 pin package) is situated at the bottom Right.<br>
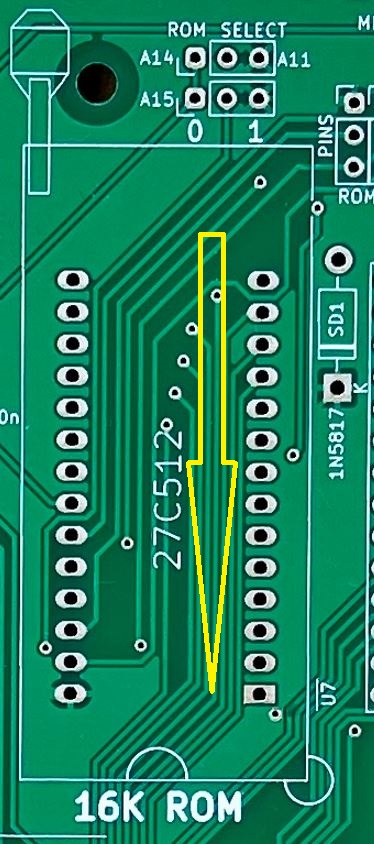
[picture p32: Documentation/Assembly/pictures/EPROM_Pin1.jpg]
EPROM ZIF Socket
<br>

## EPROM Jumpers
The highlighted positions (three jumpers down on the "28 pin") will configure the chip to run MON3. Use the A14 and A15 switches/jumpers to switch between the monitors.<br>
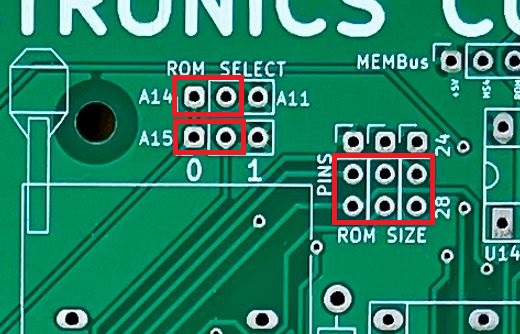
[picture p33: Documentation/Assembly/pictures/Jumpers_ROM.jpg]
EPROM
<br>

## EXPAND Jumpers
For 32K chips like the 62256 or the upcoming 32K FRAM, the highlighted jumpers or switches need to be set.<br>
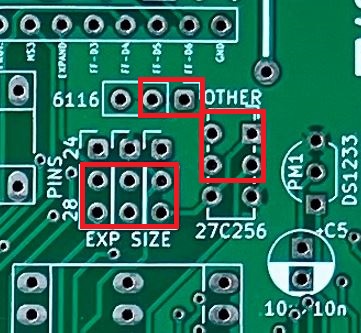
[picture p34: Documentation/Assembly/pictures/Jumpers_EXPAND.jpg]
EXPAND
<br>

## NMI Jumper & Wire Link
To enable the 923 doing an NMI (as done in MON1 and MON2), this jumper needs to connect pins as highlighted. Also, don't forget the wire link you need for clock signal.<br>
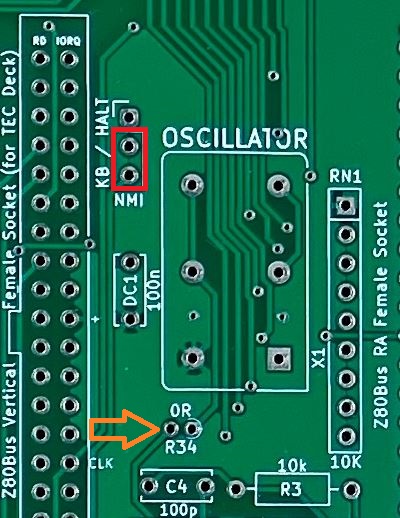
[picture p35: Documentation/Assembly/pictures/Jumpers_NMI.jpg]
NMI
<br>

## Speed Switch
You CANNOT have both the SPEED switch and the Max4544 chip installed.<br>
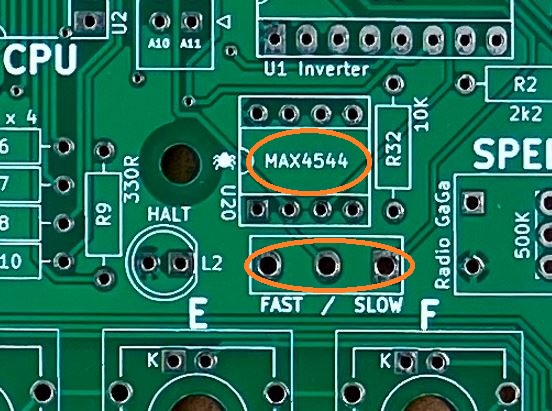
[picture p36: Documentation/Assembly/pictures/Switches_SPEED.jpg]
Speed
<br>

## Speaker Jumper & LEDs<br>
No need to place a shunt on the Groundwalker jumper, unless you have cut the track on the bottom of the PCB.<br>
You CANNOT have a 10Bar LED for the Status LEDs, and have the individual Speaker and Halt LEDs installed. It's one or the other. If you want the individual LEDs, use the 8Bar provided in the kit, or use a 10Bar and cut the legs off the outside ones.<br>
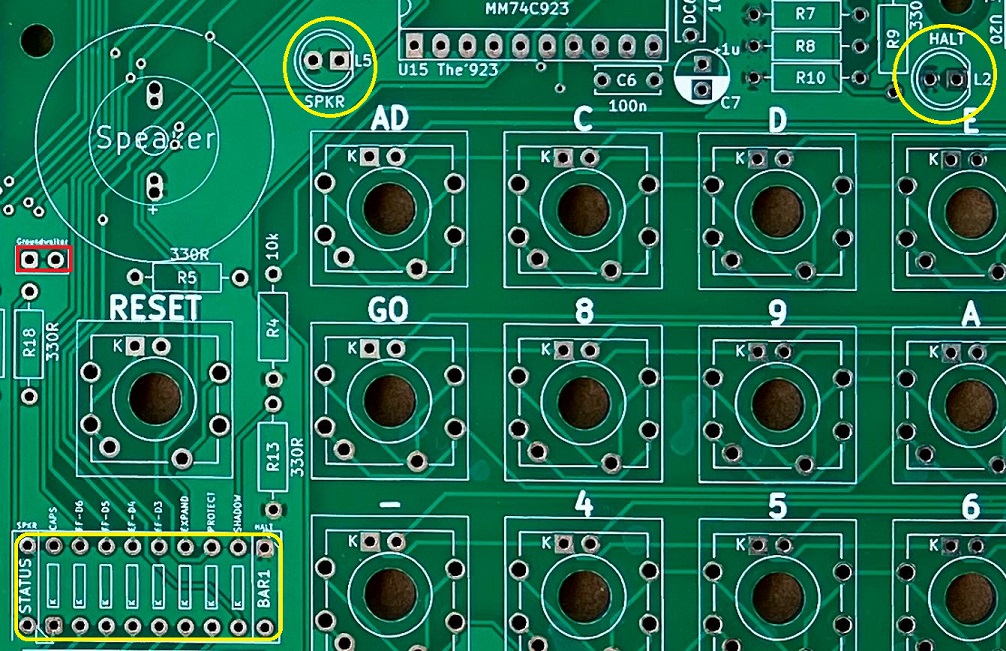
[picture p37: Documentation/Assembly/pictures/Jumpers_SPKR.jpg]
<br>

## Config Switch
These are the recommended settings. These are explained in the MON3 User Guide.<br>
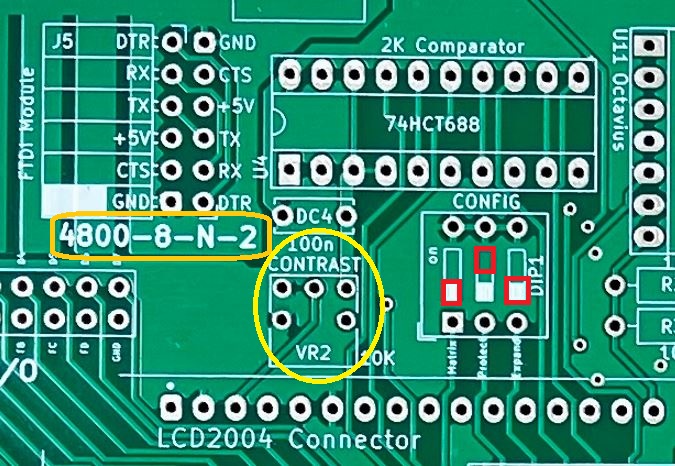
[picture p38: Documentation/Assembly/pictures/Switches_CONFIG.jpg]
<br>

## G.IMP
Shorting the highlighted pins makes the Break Point routine skip through as if you pressed the Go button.<br>
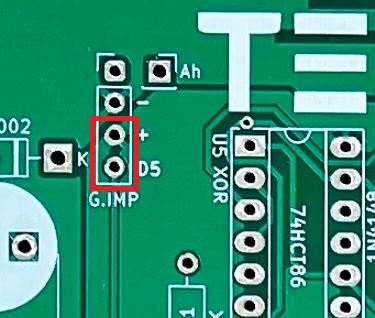
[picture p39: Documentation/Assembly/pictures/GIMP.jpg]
GIMP
<br>

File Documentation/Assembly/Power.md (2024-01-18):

# Assembly Instructions

## 3. The Power Delivery Circuit
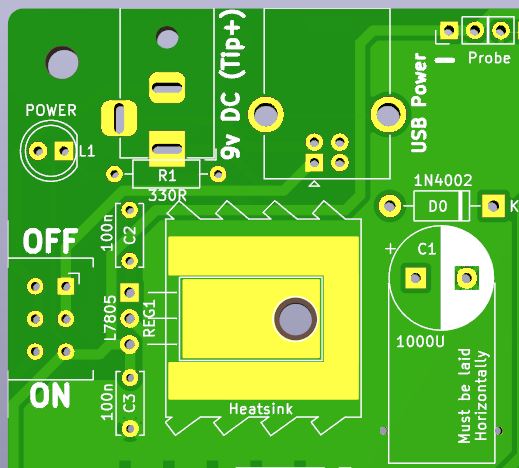
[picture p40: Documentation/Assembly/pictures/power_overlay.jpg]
Overlay
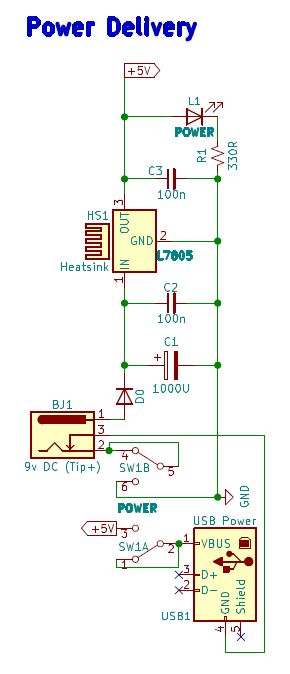
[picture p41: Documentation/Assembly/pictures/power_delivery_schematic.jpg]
Schematic
 

With only nine (9) components to install in this section, this may seem too short to write up separately, but this is one of the most crucial parts of the build.
Here is the list of parts you need:

| Ref# | Part | Value |
|---|---|---|
| BJ1 | Barrel Jack | Socket 2.1mm|
|SW1 | Power Switch | DPDT Slide|
|D0 | Rectifying Diode | 1N4001-7|
|C1 | Electrolytic Capacitor | 1000uf|
|C2 | Smoothing Capacitor | 100n|
|C3 | Smoothing Capacitor | 100n|
|REG1 | 5V Regulator | L7805|
|R1 | Resistor | 330R|
|L1 | Power LED | Blue 5mm|
|USB1 | USB-B Socket | (Optional - See Notes Below)|

As with any building (the real ones we live in), you must have a solid foundation that you can rely on and be 100% certain is the bedrock of your build; so it is the same with a proper power circuit that is tested to work and delivers power correctly to where it needs to go and not where it shouldn't.

### The 7805 Regulator
The TEC-1G, as with most other Z80 machines of the time, works on a single 5v power supply. We could get a power pack and feed 5v directly into system, but those are not always easy to come by and you might find you have a 9v pack instead. Accidentally plug one of those in and you can kiss goodbye any number of chips. Hence, since the first days of the TEC-1, they have had a 5v regulator by means of the 7805.

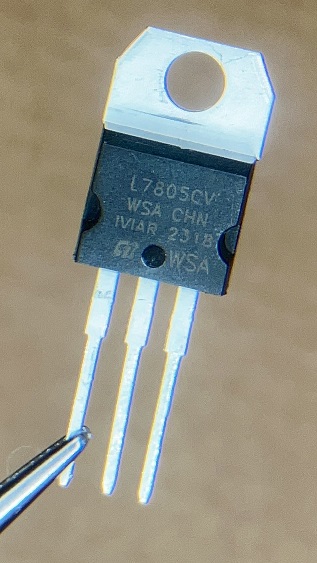
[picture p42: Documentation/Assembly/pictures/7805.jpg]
7805 5v Regulator


These regulators work very reliably, up to 1.0 to 1.5 amps as long as you have edequate heat dispersal. They can generate quite a bit or heat if put them under heavy load or have to deal with a high input voltage. But they also need a high enough input voltage before they operate correctly. So overall, they are not very efficient and can make a lot of heat that did cause problems with enclosed systems like the ZX Spectrum.

To help with heat disipation, the TEC-1G has a largish flow of copper on the top of the board that will help in that regard. Make sure you use some heatsink compound (nowhere near as much as in the photo; half that would have been enough) between the board to make a better thermal contact. Then use a 3mm bolt and nut to secure it to the board.

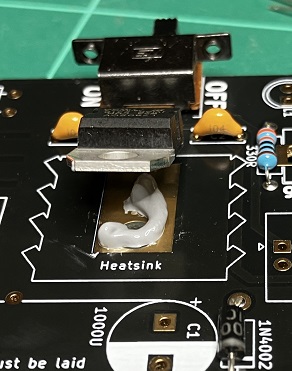
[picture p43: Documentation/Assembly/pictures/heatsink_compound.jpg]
Too much heatsink compound!


When the full build is complete, keep an eye (finger) on the heat coming off the 7805 and if it is too warm to the touch, try decreasing your input voltage (minimum 7v) or you can also insert a small heatsink between the 7805 and the board. Again, use heatsink compound on any surface that touches and needs to tranfer heat, and bolt it tightly together.

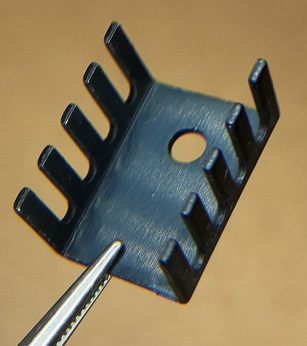
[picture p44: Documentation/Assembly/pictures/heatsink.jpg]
Heatsink


### Buck Regulators
Now there is a new kid on the block that might be of interest and if you find the heat coming off the 7805 and heatsink is too great (you should be able to keep your finger comfortably on the regulator for at least 3 seconds) then you may want to try a "Buck Regulator". These operate at much higher efficiency (something you may want to keep in mind if you ever run the TEC-1G off batteries) of around 95%, generate next to no heat at all and are available in 1A to 3A in small form factors that are no bigger than the 7805. Worth the $5 or so you will pay for one.

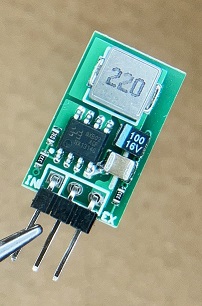
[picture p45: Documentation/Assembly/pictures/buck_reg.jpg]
Buck Regulator


### Build Order

As with Any PCB assembly, start with the components with the least height, so that when you flip the board over to actually solder, gravity is helping keep the component pressed against the board. Don't forget to use the "One Pin Method" if you have OCD like me. (Don't judge me!)
1. Solder in the 330 ohm resistor
   
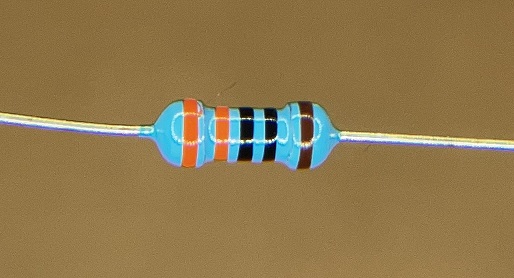
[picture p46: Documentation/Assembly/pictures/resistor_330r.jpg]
330ohm Resistor


2. Next comes the Rectifying Diode. Make sure you orient this the right way, lining up the band on the diode to the band indicated on the board. Get this wrong and the diode will block rather than pass through any power. (This diode also protects the TEC-1G from accidental reverse polarity plugs.)

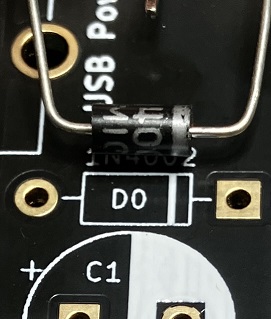
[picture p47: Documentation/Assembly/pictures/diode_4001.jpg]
4001_Diode


3. The L7805 regulator is next. You need to bend the pins 90 degress (just where the pins get skinny) so that the hole in the upper metal tab lines up with the hole in the PCB. After it is soldered in place, add a small dab of heatsink compound and bolt it down the PCB. If you have the heatsink, add that in later in the build, as one of the last things due to the height it adds to the board. Don't forget to add heatsink compound to both the heatsink surfaces then bolt it all together. Clean up any excess compound with a tissue.

4. Solder in the two little 100n (104) smoothing capacitors.

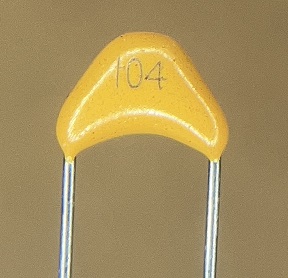
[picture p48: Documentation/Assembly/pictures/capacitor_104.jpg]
Smoothing Capacitor4001_Diode


5. The Power Switch can be next. Make sure you press it in firmly before begenning to solder.

6. The Blue LED can go next, keeping in mind the orientation of the Cathode.

Blue LED

7. Next on the height line is the large 1000uf electrolytic capacitor. Keep in mind there is a polarity which has to be followed, and in this case, the capacitor has to be laid over horizontally, to keep it low enough to allow GPIO boards to be installed over the top of that section of the PCB.

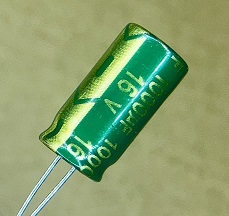
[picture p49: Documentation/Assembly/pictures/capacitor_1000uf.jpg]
1000uf


8. Then the Barrel Jack socket can go in next. Don't skimp on the solder at this item, as it has to sustain power jacks being pushed and pulled out of it.

9. Last of all, the optional USB-B connector which is not supplied in the TEC-1G Kit. Read on...

### Testing
Time to crack out the multimeter!

If you have a Bench Power Supply, it would be good to use that as your power source so you can monitor how much power usage is being drawn through the 7805. If you don't, that's fine, you can still do all the tests with just a multimeter.

First up, switch her on and see if the Blue Power LED comes on. If it doesn't, check your power supply for orientation on the barrel jack. The Tip needs to be positive and the voltage really needs to be 7.5v minimum.

Leaving the power on, do some spot checking of the voltage at various ICs around the board (you will need to look up which pin is GND and which is +5v) as well as brushing the probe along non-power pins to see if there are any spurious connections to pins that should not have power.

This sort of "Testing the Power" needs to be done at the end of any big soldering session, to ensure you have not inadvertently made any shorts and the power is still stable.

The last test is to leave the board powerted up for 30 minutes or so and see if the 7805 gets warm. With just one little LED running, the 7805 should remain totally cool. Once you have all the chips installed and running, monitoring the heat of the 7805 is wise.

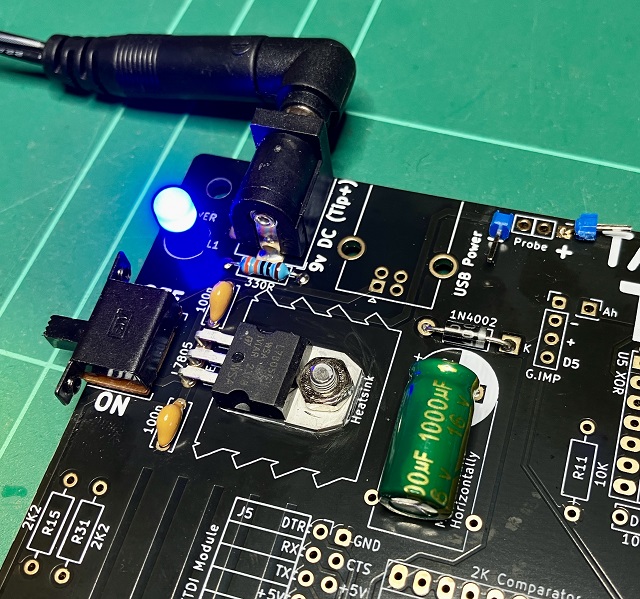
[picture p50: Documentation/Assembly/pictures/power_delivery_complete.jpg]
Power Delivery


### The USB-B Connector

Who doesn't have a USB port within 1m of them at any given moment in 2023? Not many in this day and age and thus it simply makes sense that rather than wasting time in soldering the parts listed above, you just use a pretty ubiquitous USB cable to plug directly into the TEC-1G and away you go, right?

During testing of the BETA boards, it was found that the current draw the 1G pulls exceeds what most USB ports are designed or willing to give, which caused very erratic behaviour on the 1G. In fact, the USB-B socket was very close to being removed.

If you are to use the USB-B socket as a power delivery, remember there is NO SUPPORT for this method AND if you accidentally get the polarity of voltage wrong, there is NO PROTECTION for your components at all. You best know what you are doing!

(EDIT: In the next release of the PCB, we have decided to remove the USB Socket and replace it with a generic terminal bock so the likes of the 8x8 can be powered from the motherboard. It is suggested to NOT install a USB Socket.)

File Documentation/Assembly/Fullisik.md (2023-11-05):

# Assembly Instructions

## 2. The Fullisik Keyboard
So you've opted for the top of the line, sexiest keyboard to ever grace a Single Board Computer. I don't blame you. 
Back when the TEC-1 was... just a 1... I bought the kit from Talking Electronics and it came with the spongiest, most
unresponsive and bouncy keys I had ever had the misfortune of touching.

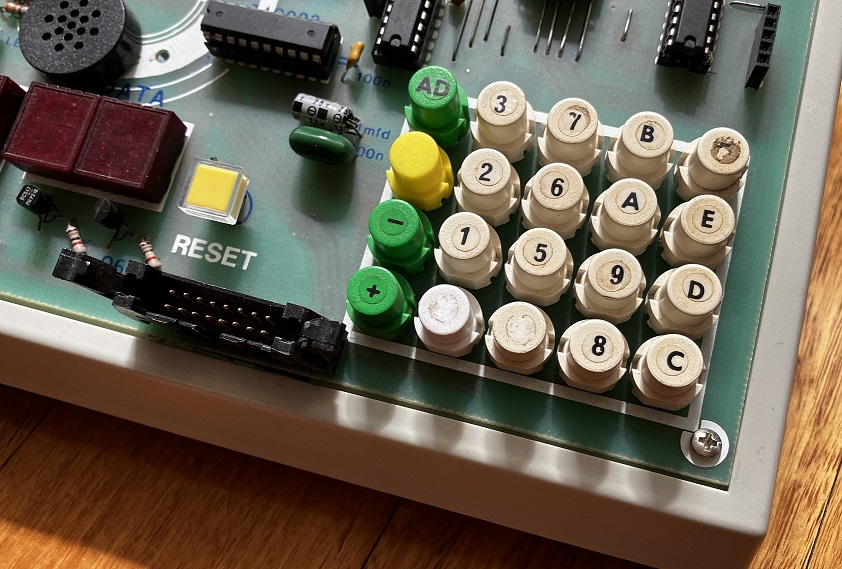
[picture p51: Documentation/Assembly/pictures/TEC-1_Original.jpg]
Original TEC-1 Keyboard


It took me about 13.2 seconds to decide that this would not do and set about making a mechanical keyboard of my own, all the way back then.

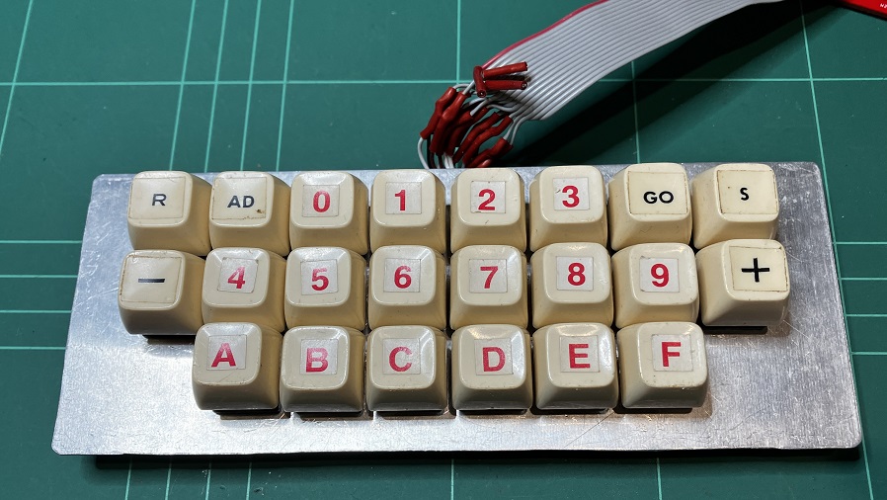
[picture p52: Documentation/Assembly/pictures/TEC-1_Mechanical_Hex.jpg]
TEC-1 Mechanical Keys


When designing the TEC-1G, there was no way I would go backwards from what I had back in 1983, so of course I had to add under-body LEDs to make it Fully Sick, bro!

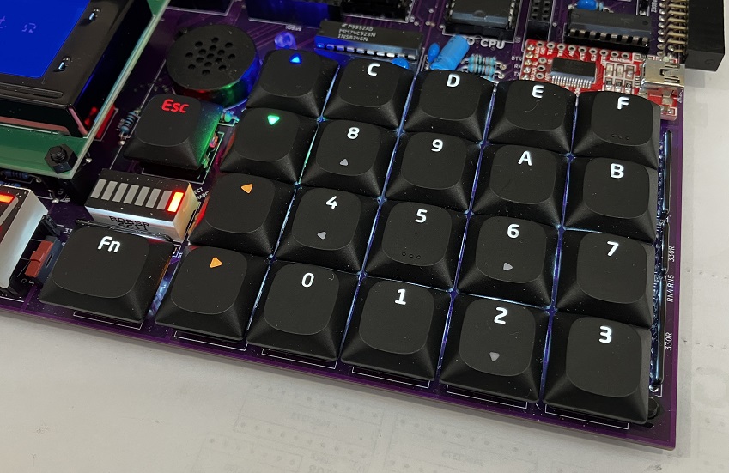
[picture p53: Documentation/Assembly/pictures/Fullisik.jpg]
TEC-1G is Fullisik


OK, enough history... Onto the assembly...

---

### Step 1. Power Supply
You might as well crack out the bench power supply early as you will be needing it very shortly.
Set it to 5.0 volts and connect it to the Probe connector at the top left of the board. You might want to do as I did
and solder in two temporary pins to allow easy connection with alligator clips. Power up your Power Supply and make sure
there are no shorts and that you do indeed have the correct polarity coming out of the supply.

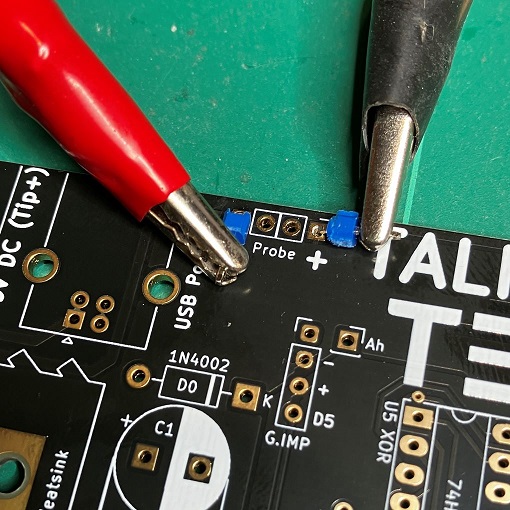
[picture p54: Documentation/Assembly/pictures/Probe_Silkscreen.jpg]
Silkscreen Error


(Note that on the Anniversary Editions of the board, the silkscreen is incorrect as well as other issues.
See the Errata page for things you need to do to the board **BEFORE** starting assembly.)

### Step 2. Soldering
There are two 330 ohm Resistors that are connected to the tiny 1.8mm LEDs, one (R5) above the Reset switch
and the other (R14) to the right of the Shift (Function) key.  These need to be soldered in first.

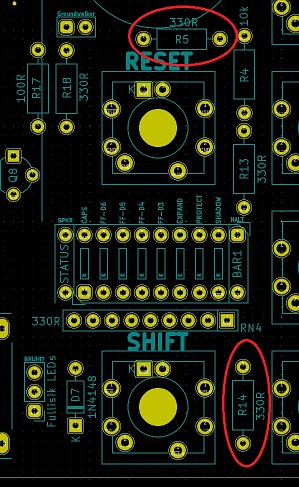
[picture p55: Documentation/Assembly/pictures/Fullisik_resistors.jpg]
Resistor Locations
 330ohm Resistors

Once you have the resistors soldered in place, you can solder in the tiny LEDs, of which the orientation of them is critical!
On the PCB there is a small K and the solder pad is square. This indicates where the Cathode of the diode should go.
Which is the Cathode on those tiny LEDs? The short leg is the Cathode and the other way you can tell is
the larger metal part inside the plastic lens is usually the Cathode.

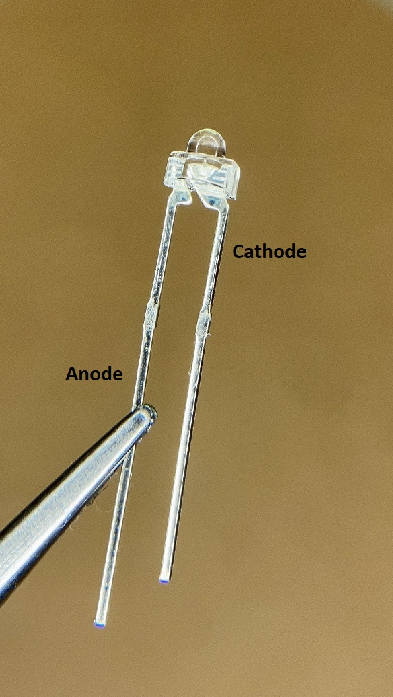
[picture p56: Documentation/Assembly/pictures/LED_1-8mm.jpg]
1.8mm LEDs


These little things can be tricky to get plumb and square to the PCB, which is a must, as the Gateron Low Profile
keys have to slip over the LEDs to sit flat. So this is the best time for me to give you my technique for
soldering all components. I call it my One Pin Method.

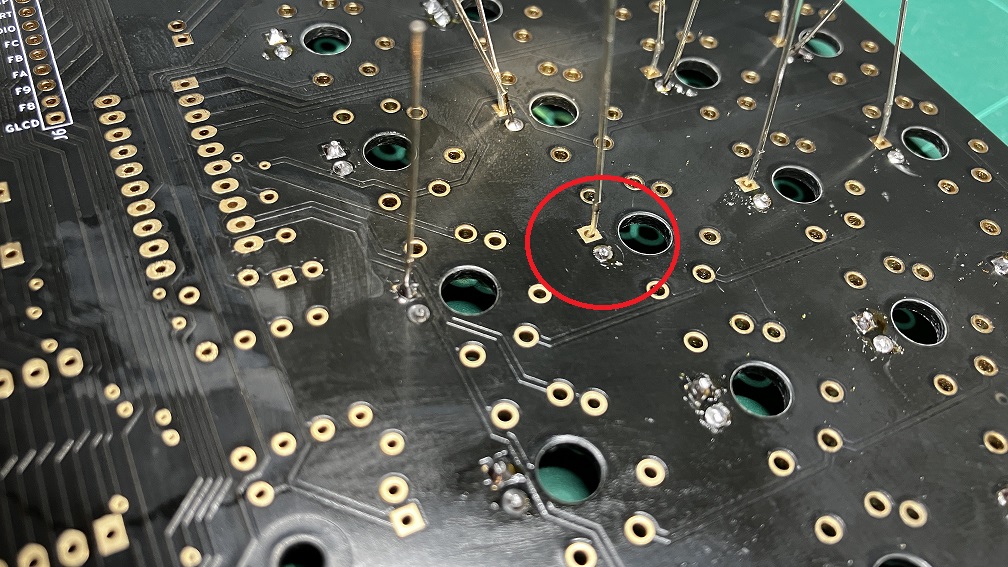
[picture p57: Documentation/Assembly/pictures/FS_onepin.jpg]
One Pin Method


### One Pin Method of Soldering (for the OCD in all of us)
```
When you insert a through-hole component, I always bend the legs out a little
to keep the item in place while I flip the board over. Once flipped though,
if you have followed the Golden Rule of "lowest components first" then
the component should be pressed down to the PCB fairly well, so you can straighten
one of the legs that you will solder first. Go ahead and do so.

**BUT**... Do not solder the other leg, just yet. Now you have to do some gymnastics
with the board. (And I'll try to make a video of this at some point.)

Flip the board over and you will likely see the component you just soldered
the single leg of is often NOT sitting flush with the PCB, or in the case of these
micro LEDs, it may be leaning over in the X or Y axis.

What you need to do is then turn the PCB on its edge, so that you can push
(with your finger of your non-soldering hand) on the component that is askew,
WHILE you touch on the one soldered pin/pad, just enough to melt it and allow you
to move the component in place; either making it flat to the PCB
or lining up the micro LED to be upright and square. You may need to repeat this a few times
to get it right. Practice makes perfect.

Once you have it perfect (and feel free to do a trial fit on an actual key over the LED)
then you can solder the other pin(s) of the components to get a perfect, OCD-free finish.
```
I use a RED coloured LED for the Reset button, and a WHITE coloured one for the Function key.

The final thing to install before testing is the micro slide switch. Once again, use the One Pin Method to 
make sure the switch is straight and perpendicular. (Unfortunately this breaks the Golden Rule of soldering
because it is taller than the components you will be installing, soon. Oh well, rules are made to be broken, right?)

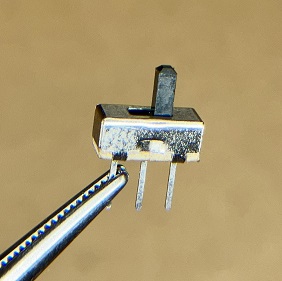
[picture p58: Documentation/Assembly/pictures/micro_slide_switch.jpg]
Micro Switch


### Step 3. Testing!
Do a quick test by connecting your bench power supply, to ensure you have the correct resistors selected,
and the polarity of the LEDs correct. Flick the Fullisik switch and if they light up, NICE!
If not, check your power first, then check the soldering on those four components, and lastly, 
you might still have flipped the LED around. Desolder it carefully, flip them around and solder them again.
Test it again. Keep checking everything until you get the result below.

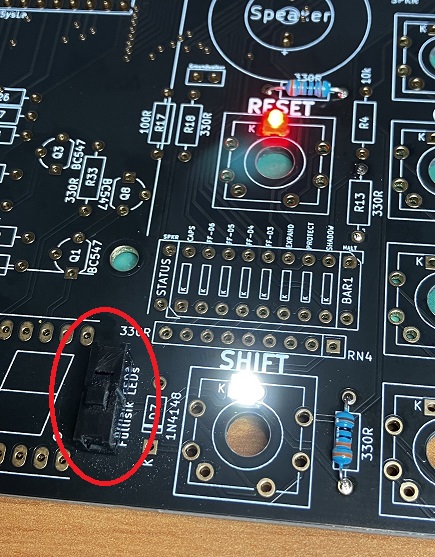
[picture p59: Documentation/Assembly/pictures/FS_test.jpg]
Test #1


### Step 4. More Soldering
All the rest of the LEDs can now be soldered in, again, being careful with the orientation of the Cathode 
and fussy about the alignment of positioning of the LEDs and ensuring the keys can slip over them.

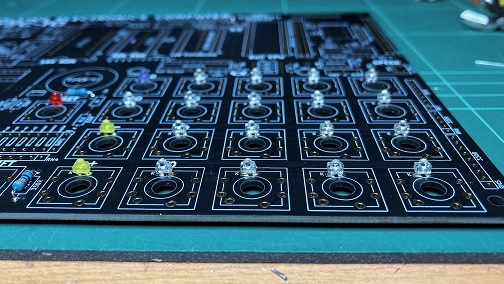
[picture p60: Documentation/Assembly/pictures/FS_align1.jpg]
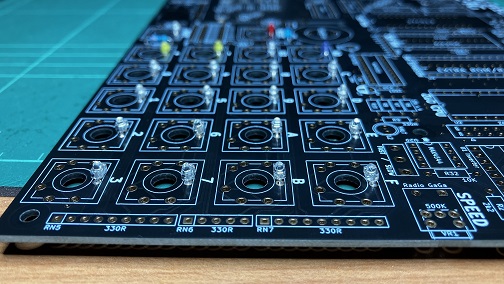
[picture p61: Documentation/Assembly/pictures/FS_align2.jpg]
 

I suggest doing them one column at a time, for sanity's sake.  White LEDs for the alphanumeric keys,
Yellow for the Plus (right) and Minus (left) keys. Green for GO (Enter) and Blue for AD (ESC).

With all those done, the Resistor Networks need to go in last. Use the ones printed with 331 (330 ohms) on them.
The end that has the dot on it is the end that is Pin 1, marked on the PCB silkscreen with a square around the pin.

330ohm Resistor Network

Use the One Pin Method, tacking in one pin of the network, lining it up
(they like to flop around) and then soldering the rest of the pins.

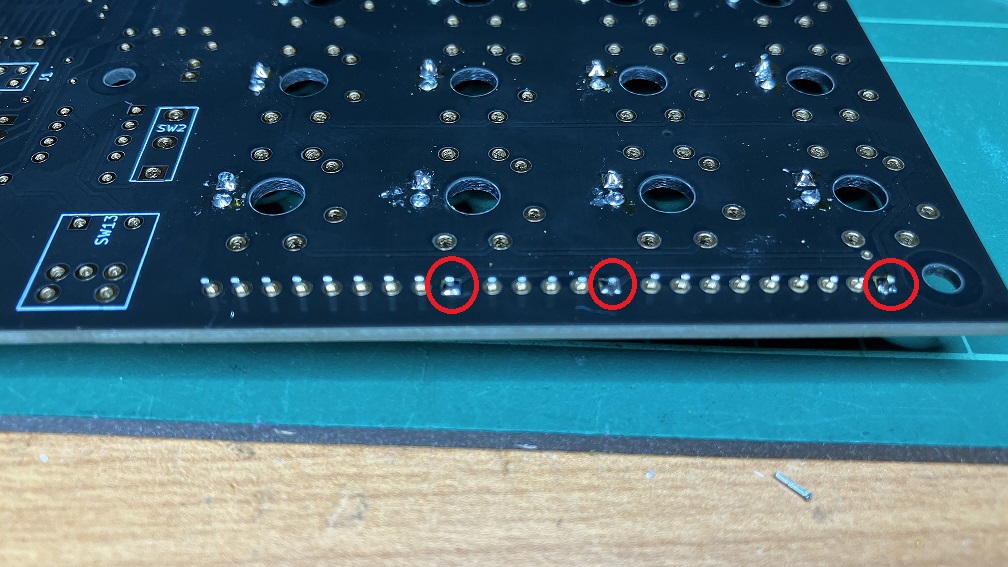
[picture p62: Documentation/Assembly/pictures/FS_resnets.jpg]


### Step 5. More Testing
With all the soldering for this section complete, connect up your bench power supply again, and flick the Fullisik
switch on. You should get a warm sensation in your stomach, and a cheesy grin on your face, knowing
you have made the world a better place, by making it Fullisik, Bro!

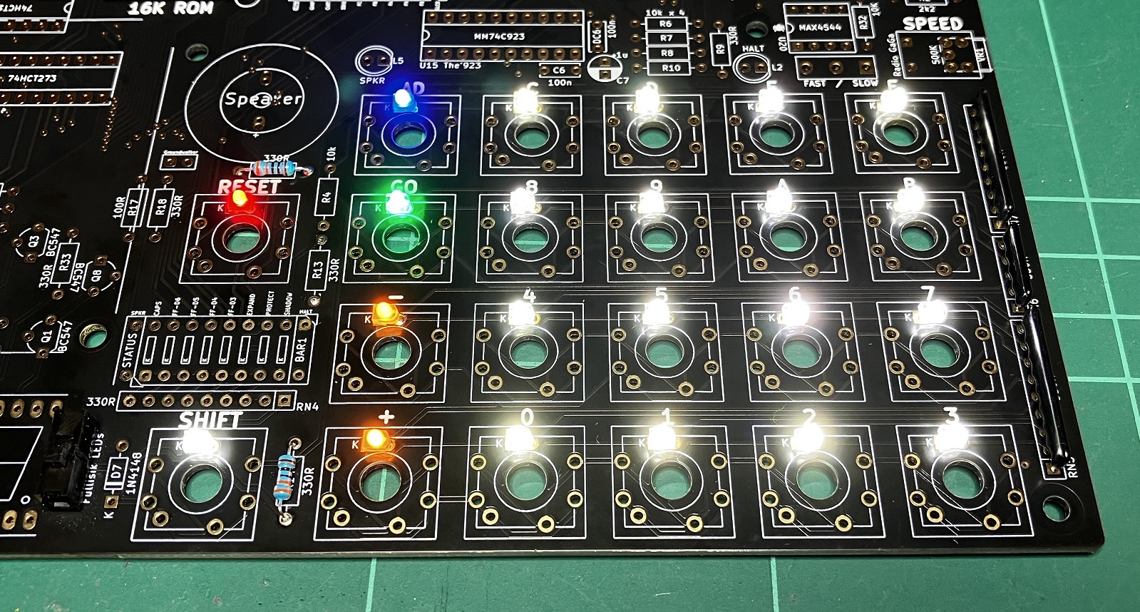
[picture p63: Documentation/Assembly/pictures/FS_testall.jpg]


---

OK, looking great! Now let's get onto [The Power Circuit](./Power.md)

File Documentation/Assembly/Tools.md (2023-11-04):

# Assembly Instructions

## 1. Required and Suggested Tools and Materials
Essential to making the TEC-1G is a good, fine-tipped soldering iron, preferably one you can control the temperature of. Try to keep the temperature under 350°C.
Make sure you have a damp sponge or a brass tip cleaning ball to keep your soldering iron clean and shiny.

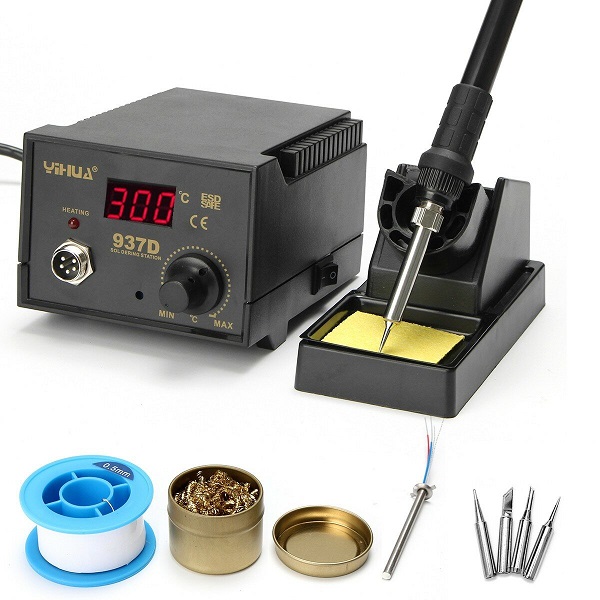
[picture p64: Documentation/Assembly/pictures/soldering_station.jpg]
Soldering Station


Fine solder, between .5 to .75mm with a resin flux core is ideal. Many health conscious would like to use lead-free solder but I find this doesn't flow as well as leaded.

Whether you're young or old, a magnifiying light make the precise soldering required a little easier.

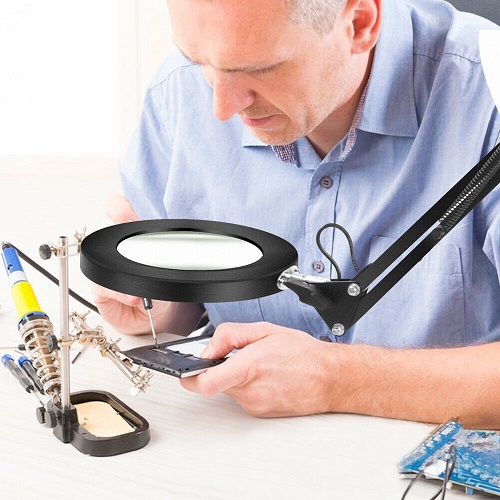
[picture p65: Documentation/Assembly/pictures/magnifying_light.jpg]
Magnifying Light


Some people swear by proper silicone soldering mats with an anti-static strap, but I've never had one and never fried anything. 

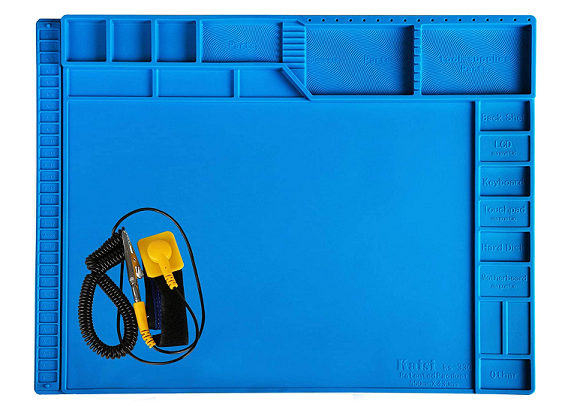
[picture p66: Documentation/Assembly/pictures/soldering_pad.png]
Soldering_Pad
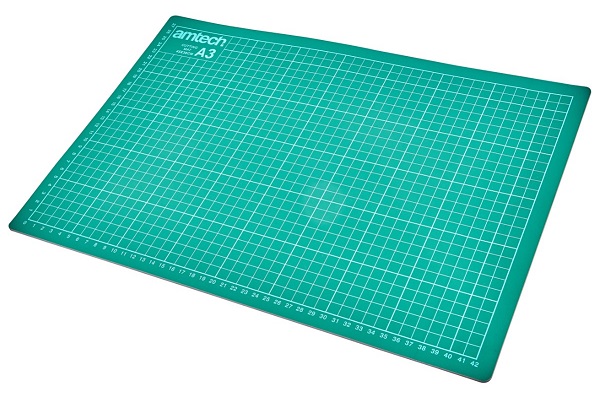
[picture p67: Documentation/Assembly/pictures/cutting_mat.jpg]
Cutting Mat
 

But protecting the surface of your bench is a good idea, so I use one of those green cutting mats that every YouTuber seems to have to have.

We're all human and as such make mistakes, so it's good to have a solder sucker, or better, a desoldering station handy.

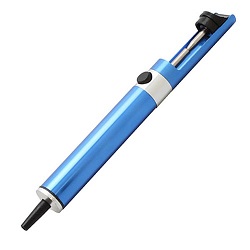
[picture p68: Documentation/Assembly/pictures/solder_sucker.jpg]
Solder Sucker
 De-Soldering Station

And finally for testing, you will need an inexpensive multimeter.

Multimeter

---

With all those tools in hand, let's assemble [The Fullisik Keyboard](./Fullisik.md)

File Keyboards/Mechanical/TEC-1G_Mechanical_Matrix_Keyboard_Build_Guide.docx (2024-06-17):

IMPORTANT: Never make ANY assumptions about parts or the build process! Read through this doc first before making any build plans!!

Mechanical Keyboard Overview

The TEC-1G Mechanical Matrix Keyboard is electrically compatible with the Tactile Matrix Keyboard design while adding both mechanical switches (including full-sized stabilised Space, Enter and Shift keys) for comfortable typing and LED lighting circuits for customisation. It also features two Reset switches wired in series to prevent accidental resets.


The PCB can be built into two very different configurations:

1) Cherry-MX switches with Cherry screw-in stabilisers and optional LED lighting, or

2) Gateron Low-Profile (LP) plate-mounted switches with plate-mounted Gateron L.P. stabilisers and optional LED lighting.

Both of these variants have separate sections to highlight important warnings and build advice. Please read the respective section for the version you plan to build.

1. Cherry Variant

The Cherry variant is a more standard and affordable mechanical keyboard, designed to be built with:

- Any 5-pin(**Note 1.1) Cherry-compatible mechanical switch (tactile, linear or clicky)
- Cherry-compatible PCB screw-in stabilisers
- Any Cherry-compatible keycap set

Most off-the-shelf mechanical keyboards are Cherry-compatible, allowing users to borrow keycaps from other keyboards for more customisation and cost reduction.

NOT ALL CHERRY (OR CHERRY CLONE) SWITCHES ARE COMPATIBLE WITH THROUGH-HOLE LEDS!! Here are some examples of switch variations that may affect LED compatibility. Note that the first two switches won’t work because they are designed strictly for use with SMD LEDs only:


(NOTE: 3-pin switches shown, but the comparison here is regarding LED compatibility)

The appropriate build steps for a Cherry variant keyboard are:

1. Solder on the R3 – R64 0805 SMD resistors on the back of the PCB (ONLY if adding the optional LEDs).

NOTE: This is preferably done with a hotplate or hot-air station. However if using a standard soldering iron, this is done by holding the SMD resistor with tweezers and dabbing solder on one end, then soldering the other end when it is securely held in place.

2. Solder in the two through-hole resistors, matrix 20-pin connector and LED Power/Mode switches.
3. PRO TIP: Test all your LEDs now! By applying +5V/GND to the board, you can one-by-one loosely position each LED in place and check they lights up. Put them aside and don’t solder them just yet! Also use this technique to verify that the SMD resistors and mode switches are all working properly.
4. Position and solder all switches EXCEPT the Shift, Enter and Space switches (which coincidentally use stabilisers).
5. Screw in the stabilisers(**Note 1.2).
6. Use the stabilised keycaps to locate and solder in the Shift, Enter and Space switches. This is to ensure these switches are aligned properly and don’t have “sticking” issues.
7. Solder in the through-hole LEDs from the top side of the switches.
8. Plug in the keyboard and check that the switches and LED lights are working.
9. Finally, add the complete keycap set.

**NOTE 1.1 – 3-pin switches may be substituted however they are very difficult to position individually due to intentionally very wide design tolerances.

**NOTE 1.2 – Lubricating your stabilisers is optional, but can significantly reduce rattle. Some stabilisers may be supplied with inadequate lubricant, or even none at all. Many guides are available online that discuss what lube is most suitable and how to apply it. Even if your keyboard is already built, screw-in stabilisers can be easily removed and lubed afterwards.

2. Gateron Low-Profile Variant

The Gateron LP variant is a higher-end low profile keyboard, designed to be built with:

- Gateron KS-33 low profile switches (tactile, linear or clicky)
- Gateron low profile plate-mounted stabilisers
- The TEC-1G mechanical matrix keyboard plate (specifically for Gateron LP variant)
- Gateron LP compatible keycaps

Users MUST be aware that the Gateron LP variant is both higher cost and more difficult to build/repair, as such it is less suitable for beginners, however it provides the benefits of a low-profile design and a higher-end plate-mounted typing experience.

The appropriate build steps for a Gateron LP variant keyboard are:

1. Remove the PCB stabiliser cutouts by clipping the mousebites and removing the inserts as shown. This mod is done so that the stabiliser housings can protrude through the PCB (test fitting as shown to check clearances is recommended).


2. Solder on the R3 – R64 0805 SMD resistors on the back of the PCB (ONLY if adding the optional LEDs).

NOTE: This is preferably done with a hotplate or hot-air station. However if using a standard soldering iron, this is done by holding the SMD resistor with tweezers and dabbing solder on one end, then soldering the other end when it is securely held in place.


3. Solder in the two through-hole resistors, matrix 20-pin connector and LED Power/Mode switches.
4. PRO TIP: Test all your LEDs now! By applying +5V/GND to the board, you can one-by-one loosely position each LED in place and check they lights up. Put them aside and don’t solder them just yet! Also use this technique to verify that the SMD resistors and mode switches are all working properly.
5. Clip the three plate-mount Gateron LP stabilisers into the plate.

NOTE – The stabilisers will not be coming back out again after this step!!! It is highly recommended that you do any stabiliser modifications (including lubricating) BEFORE the plate is in position over the PCB. Once the switches are soldered, the stabilisers are no longer accessible without desoldering at least the stabilised switch.

6. Solder in one switch (with LED) at each corner to hold the plate into its final position.
7. Doing one LED + switch at a time, snap in and solder each switch into position.

NOTE – Solder all switches EXCEPT the Shift, Enter and Space switches (which use stabilisers).

8. Install the stabilised keycaps and solder in the Shift, Enter and Space switches. This is to ensure these switches are aligned properly and don’t have “sticking” issues.
9. Plug in the keyboard and check that the switches and LED lights are working.
10. Finally, add the complete keycap set.

Pro Tips For Best Results:

- Top-mounted LEDs are more effective at making keycap characters shine bright. Under-switch LEDs will still work but the contrast isn’t as strong.
- Spend plenty of time making sure the switches are aligned perfectly before soldering, since any slight rotation will become obvious with the keycap clearances.
- Cheap keycaps often have very inconsistent clearances, which can still make the keys look misaligned even if the switches are perfectly aligned.

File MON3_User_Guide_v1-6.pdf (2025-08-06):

## User Guide


By Brian Chiha v1.6

Mon3 (Talking Electronics Computer Monitor version 3) is custom-built for the TEC-1G Single Board Z80 Computer. Mon3 is the heart of the TEC-1G. It brings the hardware to life. Consider it an Operating System that provides the ability to program the TEC. The monitor is jam-packed with features, designed for beginners who are just learning to code Z80 and rich enough for the advanced software developer.

## Table of Contents

The version of this document matches the monitor's binary file version. IE: Version 1.2 of this document is for file MON3-1G_BC23-12.bin. The 12 at the end of the file is the version number.

## Basic Operation

With the monitor loaded into the ROM socket and all the jumpers set correctly for the ROM used. Turn the TEC on. If it loads, a welcome banner will be displayed on the LCD, and a short tune will be heard.

## Cold Reset

When the TEC turns on after being powered down, a Cold Reset occurs. A Cold Reset signified with the display of the welcome banner and a short tune. A Cold Reset will configure the Monitor for first-time use after powering it on. It will default Monitor variables and configure the LCD for first use.

If the TEC isn’t responding normally or something “weird” is occurring, a manual Cold Reset can be performed. Programs loaded in RAM will be retained when a manual Cold Reset is done. To do a manual Cold Reset, while pressing and releasing the RESET key, hold the Fn key down. The distinctive LCD Banner and music tone will indicate that the Cold Reset was successful. A manual Cold Reset on the HexPad will still work if the Matrix Keyboard is in use.

## Warm Reset

A Warm Reset occurs when pressing and releasing the RESET key. A warm reset returns the TEC to its initial editing location on a Cold Reset. It's a quick way to go back to the start of a code block or break code execution.

## Main Menu

A menu is provided on the LCD screen to help navigate some of the built-in routines within the monitor. The menu will appear on a Cold Reset.

Navigating the menu should be intuitive. Press the Plus or Minus keys to scroll down and up. Press GO to run the selected routine. A right-facing Arrow indicates which menu item is currently selected. Something that might not be obvious is how to exit the menu and change into Data Entry mode. This is achieved by pressing the AD key. Once this is known, it's hard to forget it. Menus can be nested up to 3 deep. Pressing the AD key will exit to the parent menu or enter Data Entry mode if at the main menu.


The current items on the menu are:

Menu Text | Description
Intel HEX Load | Receive data in Intel Hex File format via the FTDI connector
Drive Access | Catalog and load files from PATA or SD Card Expansion boards. Save and restore the session.
Smart Block Copy | Move a block of code AND update all 2-byte addresses that are within the block
Block Backup | Move a block of code
Export Z80 Assembly | Display Z80 Assembly to a Serial terminal via the FTDI connector
Export Raw Data | Send binary data via the FTDI connector

Export Hex Dump | Display a 16-byte per line HEX dump to a Serial terminal via the FTDI connector
Import Binary File | Receive data in binary format via the FTDI connector
Music Routine | Play musical notes at a given address
Settings | Update monitor settings
Credits | Display the people who made the TEC-1G

## Intel HEX Load

Intel created a text file format that contains information on loading bytes into memory. When this routine is run, the TEC seven segments will go blank and wait for a file to be received. This is done via the FTDI connector and serial terminal. When data is transmitted, the rightmost segment will illuminate in a pattern. This indicates data is being read. Once the file has fully loaded, the letters “PASS” will display on the seven segments. This means that the load was successful. Press any key to exit. If the segments display the word “FAIL”, then there is something wrong with the file or your serial connection.

## Drive Access

With a PATA drive or Micro SD card expansion boards installed, access the files on the drive and load them to the TEC. For more information refer to the Hard Drive Access section for detailed usage information.

## Smart Block Copy

This clever routine shifts a program from one memory location to another and changes all absolute jumps and calls. Memory pointers are also altered if the memory pointers are within the start and end address of the program being relocated. Any reference to a location outside the start and end range is not altered.

The block copy treats Data bytes as instructions and might change data bytes. IE: .db C3, 23, 01 could be seen as a JP 0123 instruction.

When this routine is run, it will ask for a START, END and DESTINATION address. Type in the 16-bit address via the HEX PAD and use the Plus or Minus keys to change the selected parameter. Press GO to run the routine.

Here is an example of copying 4000H-4009H to location 2000H

Original | After Copy
4000 11 09 40 LD DE,4009 4003 E7 RST 20 4004 FE 13 CP 13 4006 C2 00 40 JP NZ,4000 4009 C9 RET | 2000 11 09 20 LD DE,2009 2003 E7 RST 20 2004 FE 13 CP 13 2006 C2 00 20 JP NZ,2000 2009 C9 RET

## Block Backup

This routine simply copies a data block from one address location to another. No bytes are altered during this copy routine.. This routine is useful to copy data reference tables, like music data, for the music routine.

When this routine is run, it will ask for a START, END and DESTINATION address. Type in the 16-bit address via the HEX PAD and use the Plus or Minus keys to change the selected parameter. Press GO to run the routine.

Here is an example of copying 4000H-4009H to location 2000H

Original | After Copy
4000 11 09 40 LD DE,4009 4003 E7 RST 20 4004 FE 13 CP 13 4006 C2 00 40 JP NZ,4000 4009 C9 RET | 2000 11 09 40 LD DE,4009 2003 E7 RST 20 2004 FE 13 CP 13 2006 C2 00 40 JP NZ,4000 2009 C9 RET

## Export Z80 Assembly

If the TEC is connected to a serial terminal via an FTDI to USB adaptor, code that is stored or written on the TEC can be disassembled and sent to the terminal. This is a great way to view the code that is on the TEC in a readable format and could be passed into a Z80 compiler on a PC.

When this routine is run, it will ask for a START and END address. Type in the 16-bit address via the HEX PAD and use the Plus or Minus keys to change the selected parameter. Press GO to run the routine.

Here is an example of its output.
4000 3E 3F | LD A,3F
4002 D3 01 | OUT (02),A
4004 3E 04 | LD A,04
4006 D3 02 | OUT (02),A
4008 CF | RST 08
4009 C9 | RET

## Export Raw Data

This routine will send TEC binary data to a serial connection. It’s a way to save code written on the TEC to a PC. As binary data is being sent, the data can only be properly viewed through a HEX file viewer or HEX dump routine.

When this routine is run, it will ask for a START and END address. Type in the 16-bit address via the HEX PAD and use the Plus or Minus keys to change the selected parameter. Press GO to run the routine.

## Export Hex Dump

This routine displays binary data in a readable format to a serial terminal connected via an FTDI to USB adaptor. It will display up to 16 bytes per line.

When this routine is run, it will ask for a START and END address. Type in the 16-bit address via the HEX PAD and use the Plus or Minus keys to change the selected parameter. Press GO to run the routine.

Here is an example of its output.

C100: 31 80 08 21 00 40 CD FC C5 AF D3 05 D3 06 DB 03 C110: 47 E6 10 C2 00 80 3A 9F 08 E6 04 0E 01 B1 D3 FF C120: 32 9D 08 78 E6 02 32 9E 08 3A 9D 08 E6 01 28 0B C130: 21 00 C0 11 00 00 01 00 01 ED B0 21 00 40 22 86 C140: 08 22 A0 08 DB 03 0F 38 06 DB 00 E6 20 18 08 CD

## Import Binary File

This routine will upload a binary file from a PC onto the TEC via an FTDI to USB adaptor. This is the opposite of the Export Raw Data routine and will load binary data to a given address on the TEC.

When this routine is executed, it will ask for a START and END address. This address range must match the size of the binary file being sent. Type in the 16-bit address via the HEX PAD and use the Plus or Minus keys to change the selected parameter. Press GO to run the routine. The TEC will wait for data to be received and will end when END-START+1 bytes are received.

## Music Routine

Use this routine to play some notes to the TEC speaker. It is based on John Hardy’s Mon1 routine adjusted for a 4 MHz clock speed. The routine uses similar input codes, making it suitable for existing tunes to be used.

When this routine is executed, it will ask for a START address of the music data—type in the 16-bit address via the HEX PAD. Press GO to run the routine.

Two octaves are playable. Here is a reference to the note code and its musical note. A Pause is represented by 00, and any other note code that isn’t listed will exit the routine.

Note | Code | Note | Code | Note | Code | Note | Code
G | 01 | C# | 07 | G | 0D | C# | 13
G# | 02 | D | 08 | G# | 0E | D | 14
A | 03 | D# | 09 | A | 0F | D# | 15
A# | 04 | E | 0A | A# | 10 | E | 16
B | 05 | F | 0B | B | 11 | F | 17
C | 06 | F# | 0C | C | 12 | F# | 18

The following page contains examples tunes that can be typed in a played

Bealach
06, 06, 0A, 0D, 06, 0D, 0A, 0D, 12, 16, 14, 12, 0F, 11, 12, 0F 0D, 0D, 0D, 0A, 12, 0F, 0D, 0A, 08, 06, 08, 0A, 0F, 0A, 0D, 0F 06, 06, 0A, 0D, 06, 0D, 0A, 0D, 12, 16, 14, 12, 0F, 11, 12, 0F 0D, 0D, 0D, 0A, 12, 0F, 0D, 0A, 08, 06, 08, 0A, 06, 12, 00, 1F

Angels On High
0F, 0F, 0F, 0F, 0F, 0F, 12, 12, 12, 12, 12, 10, 0F, 0F, 0F, 0F 0F, 0F, 0D, 0D, 0F, 0F, 12, 12, 0F, 0F, 0F, 0D, 0B, 0B, 0B, 0B 0F, 0F, 0F, 0F, 0F, 0F, 12, 12, 12, 12, 12, 10, 0F, 0F, 0F, 0F 0F, 0F, 0D, 0D, 0F, 0F, 12, 12, 0F, 0F, 0F, 0D, 0B, 0B, 0B, 0B 12, 12, 12, 12, 14, 12, 10, 0F, 10, 10, 10, 10, 12, 10, 0F, 0D 0F, 0F, 0F, 0F, 10, 0F, 0D, 0B, 0D, 0D, 0D, 06, 06, 06, 06, 06 0B, 0B, 0D, 0D, 0F, 0F, 10, 10, 0F, 0F, 0F, 0F, 0D, 0D, 00, 00 00, 12, 12, 12, 12, 14, 12, 10, 0F, 10, 10, 10, 10, 12, 10, 0F 0D, 0F, 0F, 0F, 0F, 10, 0F, 0D, 0B, 0D, 0D, 0D, 06, 06, 06, 06 06, 0B, 0B, 0D, 0D, 0F, 0F, 10, 10, 0F, 0F, 0F, 0F, 0D, 0D, 0D 0D, 0B, 0B, 0B, 0B, 0B, 0B, 0B, 0B, 00, 00, 00, 00, 00, 00, 1F

TEC-1G with 3D printed stand and supports. Credit: Gerald M Eberhardt


## Settings

The settings allow the user to configure the monitor. Powering off the TEC will return these settings to their default state. Some settings will be retained if an RTC Add-on board is connected with battery backup.

- Toggle Key Beep - Turn the keypress ‘beep’ indication on or off.
- Set Baud Rate - Modify the Baud rate for serial transmission.
- Toggle GLCD Term - Use the GLCD (if fitted) as a terminal
- Toggle Address Inc - Turn the automatic address increase after a byte has been keyed on or off.
- Configure RTC - Set Time/Date of RTC (if RTC Add-on is connected).
- Reset RTC & PRAM - Reset RTC for initial use and initialise NVRAM.
- Toggle EXPAND - software controlled the expansion socket to toggle between lower and upper 16Kb memory for a 32Kb ROM/RAM chip.

## Credits

Display the people who developed and tested the TEC-1G
- Mark Jelic - Designer of the TEC-1G
- Brian Chiha - Mon3 Programmer 🥚
- Craig Hart - TECnical Expert
- Ian McLean - Tester and QA
- James Elphick - Tester and QA
- John Hardy & Ken Stone - The original designers


## Memory Map

The table below outlines how the full 64Kb of address space is allocated on the TEC-1G.

Address | Contents | Type
0000H-00FFH | Reserved for Z80 instructions | RAM
0100H-07FFH | PATA/SD Drive area or Free RAM | RAM
0800H-087FH | Reserved for Hardware Stack | RAM
0880H-0FFFH | Reserved for Monitor RAM | RAM
1000H-3FFFH | Free RAM | RAM
4000H-7FFFH | Free RAM (Protected) | RAM
8000H-BFFFH | Expansion Socket | RAM/ROM
C000H-FFFFH | Monitor ROM | ROM

Some things to be considered are:
- Any RAM location can be updated, but it is highly recommended not to update Monitor Reserved RAM locations. This can/will cause undesirable effects on the running of the TEC. A Cold Reset will restore the TEC to its default running state (hopefully).
- The address range between 4000H-7FFFH is a special area that can be made READ ONLY. This is called a Protected area. Protect mode can be switched on using the configuration 3-DIP switch. If protect is enabled and code is being executed. No RAM update can be done in this range. This feature is designed to protect keyed-in code from being inadvertently erased by a rogue routine.
- The Expansion Socket on the TEC can have a 32Kb ROM or RAM inserted. Only 16Kb can be accessed at one time. To switch between high and low memory use the Expand switch on the configuration 3-DIP switch. The switch can also be overridden in software by toggling the Expand flag in the Settings menu or pressing Fn-E.
- If the monitor ROM is a legacy monitor, IE: Mon1, Mon2, JMon or BMon, The address range 0000H-07FFH will be READ ONLY and will emulate the same addressing that is used for that particular ROM. Shadow mode will be active by default and will be indicated by an illuminated LED segment on the system latch BAR component.

## Data Entry Mode

Data Entry Mode allows the user to enter Z80 Op Codes directly into the TEC. To access Data Entry Mode from the Main Menu, simply press the AD key. In this mode, the 4 left seven-segment displays will show the current editing address, and the 2 right segments will display the byte at that address.


Address | Data

The decimal place LED on the segments indicates which part, Address or Data, is currently enabled for direct updates. In the picture above, the dots are on the Data segments.

The initial starting address is 4000H. This address was chosen as it's within the Protect RAM area.

## Basic Operation

To update a byte at an address, simply use the 0-F keys on the keypad. After the byte has been entered, by default when the next byte is keyed, the current editing address will automatically move to the next address location. This saves the user from pressing the Plus key after each byte is added. This option can be switched off in the Settings menu.

To navigate to another address, press the Plus or Minus key. Or press the AD key. When using the AD key, the decimal place dots will move to the address segments, indicating that the address field is updatable. Key a new 16-bit address using the 0-F keys. Press the AD key to move back to data updating mode.

And finally, to execute code, navigate to the address where the code starts and press the GO key. Protect mode will be honoured if switched on. If the code ends with a RET instruction (C9), execution will cleanly exit back to the monitor. The LCD screen will display the code start address while running.

One thing to note is that while data is being entered, the decimal place LED on the data segments will change from displaying two lights to one. The one light will indicate which Nibble (half byte) has been entered. This will help know if the whole byte has been entered or not.

If a mistake is made during data entry and the byte is to be re-entered. To stop the address from automatically incrementing, press the AD key twice. This will reset the Nibble counter and allow a new byte to be entered.

If any key is held down, after a short period, the key will automatically repeat. This is mostly useful while holding down the Plus or Minus key to quickly move to a new address. But can also be used to populate memory with 00 or FF or anything else.

## LCD Screen

In Data Entry Mode, the LCD Screen will display 12 bytes of data. 4 bytes before the current editing location and 8 bytes from the current editing location. These bytes are displayed in groups of 4 (3 lines). A right arrow indicates the byte at the current editing location.

Displayed on the right side of the screen is the current edit mode, da=Data, ad=Address, the current byte in LCD ASCII and the Nibble Counter. The picture below shows: The current address is 4000, Data mode, “>” = 3E in ASCII and 0 nibble count.

On the 4th line of the LCD, the Z80 Assembly of the current OP Code(s) is shown. This can be useful to see what instruction is currently being keyed.

By displaying a range of bytes on the LCD, the user can check if the correct bytes have been entered without individually moving to each address.


## Function Keys

Various extra options can be selected via the Function Key. To use these functions, hold the Fn key down and press any other key.

The routines attached to the Function Key are:
- Fn-AD - Display the Main Menu
- Fn-0 - Save Current Address. Press 1,2 or 3 to save the current editing address in RAM to quickly jump to this location later. Three addresses can be saved. This is useful if your code is in a location other than 4000H and the Reset button has been pressed. Press AD to exit the routine. The initial default address is 4000H.
- Fn-1,2,3 - Quick jump to Address. This will move the monitor's current editing location to the saved address set by Fn-0 above.
- Fn-4 - Intel Hex Load. This is a shortcut to the Main Menu routine.
- Fn-5 - Toggle GLCD Term. Use the GLCD as a terminal.
- Fn-6 - Save session. Save all RAM to disk. Requires the PATA Drive or Micro SD Card Expansion boards. See Hard Drive Access for more information.
- Fn-7 - Restore Session. Load session from disk. Requires the PATA Drive or Micro SD Card Expansion boards. See Hard Drive Access for more information.
- Fn-8 - Fill with NOP’s Fill a selected area of memory with NOP instruction 00H. Provide a from and to address and confirm by pressing ‘C‘.

- Fn-A - Restore from Backup. This is the reverse of Fn-B routine and defaults the To/From/Dest addresses to copy back from backup. Values can still be modified if necessary.
- Fn-B - Block Backup. This is a shortcut to the Main Menu routine.
- Fn-C - Smart Block Copy. This is a shortcut to the Main Menu routine.
- Fn-D - Switch between Data Entry View and Disassembly View. Disassembly View displays the next 4 Assembly instructions. To move through the instructions press the Plus or Minus keys. Data entry can still be done in this mode if desired.


- Fn-E - Toggle the Expansion Socket Expand flag. This will switch between the upper and lower memory of the 32Kb ROM/RAM in the expansion socket.
- Fn-F - Catalog the Drive and list files for loading. Requires the PATA Drive or Micro SD Card Expansion boards.
- Fn-Plus - Insert an NOP instruction at the current editing location AND move all bytes up to max RAM by one address upwards. It will also do a Smart Block Copy to all moved bytes. This routine can add a Breakpoint (F7) or missing opcodes to an existing program.
- Fn-Minus - Delete a byte from the current editing location AND move all bytes down by one address. It will also do a Smart Block Copy to all moved bytes.
- Fn-Reset - Perform a Cold Reset. This will reset the TEC to its default state.

## Matrix Keyboard

Mon3 will work with the TEC QWERTY or Mechanical Matrix Keyboard Add-on. The Keyboard is connected to the Keyboard Socket on the lower left of the PCB. How your Keyboard PCB is designed might affect which pins can be connected. Please view the TEC-1G Schematic for information on pin configuration.


To activate the Keyboard, The Matrix switch on the 3-DIP switch is to be turned on. This activates the Matrix Keyboard and disables the onboard Hex Keypad (except Reset). Mon3 only maps keys present on the TEC-1G to the Matrix Keyboard.

The Keyboard map to Hex Keypad is as follows:
- AD - Esc
- Plus - Right Arrow
- 0-F, Fn - 0-F, Fn keys
- GO - Enter
- Minus - Left Arrow
- Reset - Reset key if connected The full range of keys can be accessed and converted when developing programs via the matrixScan and matrixToASCII API routines.

## Debugging Programs

Breakpoints can be inserted within a program which can help with viewing the state of the CPU registers. To break the execution of your code, insert RST 30H or F7 at the current address where the break should occur.

An easy way to insert a byte into an existing program is to press Fn-Plus. This will insert a NOP instruction at the current address. Then change this byte to F7.

When the execution of code is interrupted with a breakpoint, the TEC will pause and display register information on the LCD screen.


The contents of the Z80 CPU registers AF, HL, BC, DE, IX, IY, the Program Counter and Stack Pointer are displayed. CPU Flags are also displayed. Flags that are set are in Capitals. To continue code execution press the GO key and to quit execution and return to the Monitor press the AD key. Finally, to remove an inserted Breakpoint press Fn-Minus at the address where the Breakpoint is. This will remove the breakpoint and adjust the code to its original state. Note: Breakpoints will be ignored if a connection is made between the + and the D5 pins on the G.IMP header. Warning: Do not connect the + to the - pin on the G.IMP header!!! This will short out the TEC!

## Tiny Basic

Tiny Basic has been removed from Mon3 as of v1.6 but it can be loaded as a stand-alone program. See the GitHub for source files.

Tiny Basic is an easy-to-use BASIC programming language. Tiny Basic by default uses the FTDI to USB serial terminal connection. If a GLCD Add-On board is installed, the GLCD can be used as a terminal along with a Matrix Keyboard. Go to Settings -> Toggle GLCD Term to enable. Some additional commands have been implemented to interact with the TEC-1G hardware. Tiny Basic will use RAM address 0900H-3FFFH

Functionality has been added to the Mon3 version to make it more useful for the TEC-1G. Here is a list of language additions.

Syntax | Description
PEEK(n) | Return the contents of memory at location `n`. Value is in decimal
OUT p,n | Output `n` to Port `p` on the TEC
XOFF, XON | Turn the Serial terminal output off and on. Used if outputting to the Seven Segments
PRINT extensions | Placed in `PRINT` statements and preceding a number: IE: PRINT &255,%12,$65 outputs ‘FF . A’ ● `&` - Output number as Hexadecimal. Works for all numbers. ● `%` - Output number as an ASCII character (Print `.` for non-printable characters) ● `$` - Output number as an ASCII character (Print all characters)

Ctrl-D Exits back to monitor and Ctrl-Z clears the whole line

Here are some Tiny Basic Example programs Display the first 22 Fibonacci Numbers
5 REM ** FIBONACCI SEQUENCE **
10 PRINT "FIBONACCI SEQUENCE"
20 FOR I=1 TO 22
30 GOSUB 70
40 PRINT "F",I,F
50 NEXT I
60 STOP
70 LET A=0; LET B=1
80 FOR J=1 TO I
90 LET T=A+B; LET A=B; LET B=T 100 NEXT J
110 LET F=A
120 RETURN
Display the Factors of a given number 5 REM ** FACTORS OF N **
10 INPUT "GIVE ME A NUMBER" I 20 LET C=1
30 PRINT "FACTORS OF ",#3,I,":" 40 IF I/C*C=I PRINT C
50 C=C+1
60 IF C<=I GOTO 40
70 GOTO 10
Output the numbers 0 to 9 on the TEC-1G Seven Segment Display 5 REM ** SEGMENT OUTPUT DEMO **
10 @(0)=235;@(1)=40;@(2)=205;@(3)=173;@(4)=46
20 @(5)=167;@(6)=231;@(7)=41;@(8)=239;@(9)=175
30 XOFF
40 OUT 1,1
50 FOR I=0 TO 9
60 OUT 2,@(I)
70 FOR J=1 TO 1000;NEXT J
80 NEXT I
90 XON
Print All ASCII Characters
10 REM ** PRINT ASCII CHARACTERS ** 20 FOR I=32 TO 255
30 PRINT #1,&I+32,$32,$I+32,$32, 40 IF (I+1)/10*10=(I+1) PRINT
50 NEXT I

## Terminal Monitor

TMON has been removed from Mon3 as of v1.5 but it can be loaded as a stand-alone program. See the GitHub for source files.
The Terminal Monitor (TMON) is a complete serial port-based monitor for the TEG-1G, designed for users who prefer to interact with the TEC-1G via a terminal.

## Starting up TMON

Connect a serial terminal to the TEC-1G via the FTDI to USB connector. Then, select Terminal Monitor from the main menu by pressing GO and look at the serial terminal.

TMON for TEC-1G Version 1.0
MON-3 Version: 2023.11
RAM Found between 0000h and 3FFFh - 16384 bytes 1000 >

## Using TMON

TMON is an interactive tool that works with a serial terminal e.g. PuTTY or Tera Term on a PC, or a 'real' VT100 serial terminal such as a Wyse WY-60. The TEC-1G keypad and 7-seg displays are not used once the program starts, and do not do anything (except for the testing routines documented below).

Interactions with TMON are via the serial console. The user types
commands interactively and the results are displayed on the terminal.

All interactions with TMON use HEX format - so a byte is 00 to FF, etc. The "h" or "0x" is omitted for brevity.

Typically, the ADDR key exits any interactive command, or by entering "Q" from the terminal.

The above text is the default display when TMON first starts. TMON is now awaiting input and commands from the Available Commands list can be entered.

## The Command Prompt

1000 >

The 1000 represents the CURRENT ADDRESS in HEX. Many commands default to their actions interacting with memory at this address. The CURRENT ADDRESS changes as with certain commands. e.g. inputting code and data, and can be set by the ADDR command. By default, TMON points to itself.

The command input editor is very simple. Invalid inputs are typically ignored and result in the user simply being returned to the command prompt. The maximum command length accepted is 40 characters, however, presently the longest valid command possible is 9 characters in length. When the user's input exceeds the maximum command length, the TEC will emit a beep tone to indicate this condition has been reached. Backspace is supported, to correct typos.

All data entered at all times is assumed to be HEX - 4 bytes for addresses, 2 bytes for data. Invalid data input is ignored.

## DATA mode

When the DATA command is given, TMON switches to interactive data entry mode. This is signified by the prompt changing as follows:

XXXX nn :

XXXX continues to represent the CURRENT ADDRESS however the nn represents the HEX byte stored at that address, which you are presently editing.
- Enter a HEX byte and it will be written to memory at CADDR; CURRENT ADDR is then incremented by one.
- ENTER increments CURRENT ADDRESS by one and leaves the existing value as-is. This way, any bytes that don’t need altering are skipped over.
- - decrements the CURRENT ADDRESS by one. This allows for correcting input errors by going back one address after erroneous input.
- Q exits data entry mode.

Invalid entries will be ignored.

The DATA entry system is very simple and will continue to be improved in future versions.

## TMON Commands

HELP | ? | EXIT
INTEL | BEEP | BELL
VER | STATE | CLS
RAMCHK | GO [xxxx] | DUMP [xxxx]
ADDR [xxxx] | DATA [xxxx] | INC
7SEG | SMON | HALT
DEBUG | KEYTEST | FILL xxxx yyyy nn

PRINT

Parameters marked with square brackets e.g. \[xxxx\] are optional.

HELP
Displays help text

?
Display the list of commands

EXIT
Reboots the 1G back to MON3

INTEL
Calls the Intel Hex file transfer routine built into MON-3

BEEP
Beeps the 1G speaker

BELL
Sents the BELL command to the remote console

VER
Displays the version number of TMON and MON-3

STATE
Displays the state of the 1G system - SHADOW, PROTECT, EXPAND, CAPS LOCK

CLS
Sens a clear screen sequence to the remote console

RAMCHK
Runs a simple test to determine how much RAM is installed, and at what momentary address(e)s. Uses whichever bank EXPAND is set to, but does not alter the EXPAND state. Supports multiple discontinuous RAM blocks, if fitted.

GO xxxx
Executes code from the CURRENT ADDRESS, or from xxxx if supplied.

DUMP xxxx
DUMP the contents of 64 bytes of memory; provides HEX and ASCII outputs so memory can be examined.

DUMP pauses at completion - space repeats the command (CADDR continues to increment if auto-increment is on; otherwise the same block repeats). This allows you to quickly run through larger blocks without needing to type commands repeatedly.

Q quits and returns to the command prompt.

ADDR xxxx
Set the CURRENT ADDRESS. If no address is supplied, display the CADDR instead.

DATA xxxx
Interactively Input data into memory. Input one hex byte at a time; the value input is stored in the CADDR memory location.

Enter Q to quit input mode. See full description of DATA mode, above.

INC ON/OFF
Set auto-increment mode of CADDR. No parameter supplied = Display the current auto-increment mode. Sometimes turning auto-increment off is helpful for debugging or monitoring.

7SEG
Displays CADDR and memory byte on TEC 7-seg displays. + and - keys increment/decrement CADDR. Pressing the ADDR key exits to TMON.

SMON
Serial data stream monitor. Accepts serial input from the terminal and displays the HEX bytes received on screen. Great for debugging terminal comms and understanding control codes received from the PC (e.g. VT100 sequences). This is a crude implementation but does display the limitations of the bit-bang serial in not being able to adequately buffer incoming bytes in real time (try pressing an arrow key or a PC function key).

Enter Q (capital) to exit SMON back to TMON.

If a terminal program such as Tera Term is used to add a small delay (e.g 20ms) between bytes transmitted from the PC, SMON can accurately show VT100 control codes such as a PC arrow or function key. Without the delay, the bit-bang serial normally gets the first byte only, or perhaps the first and fourth or fifth byte, hence demonstrating the limitations of the bit-bang interface.

HALT
Executes a CPU HALT instruction - on TEC-1F, press any key to resume.

DEBUG
Calls the MON-3 debugger/breakpoint tool to examine register contents.

KEYTEST
Tests the selected keyboard - the last pressed key's scancode will appear on the 7-segment displays. Fn is displayed with bit 5 set. Matrix keypad keys supported by MON3 (NOT the full matrix keyset) will be returned if MATRIX mode is enabled. Pressing the ADDR key exits to TMON.

FILL xxxx yyyy nn
Fill memory between address xxxx and yyyy with data nn. note: Fill range must be at least 2 bytes long. No checks for safety are done - use with caution, as any area of memory, including the stack, program code or data could be overwritten. This does not apply if Protect Mode is on.

PRINT your-text-here
your-text-here is echoed back to the serial terminal.


## TEC Magazine Code on the TEC-1G

A great way to learn how to use the TEC-1G is to key in programs presented in the TE Magazines Issues 10 to 15. If the programs are keyed in directly, they probably won’t work! This is because they usually start at addresses 0800H or 0900H. These addresses are reserved for Mon3. To get the code working, simply update all 2-byte address references to match the address location of the code on the 1G.

Keypad interactions are a bit more complicated. The old monitors use the register I and the NMI (Non-Maskable Interrupt) to trigger and save a keypad press. Mon3 uses ‘Polling’ instead and RST/API calls to do keypad reading. See the next chapter for more information on RST and API calls.

Below is a conversion table to help convert older code to work on Mon3 when a keypad press is required.
Old Command | Mon3 Replacement | Reason
HALT | RST 08H | RST 08H simulates a HALT command and sets register A with the key value pressed.
LD A,I | LD C,10H RST 10H | A LD A,I by itself is ‘polling’ for a key press. Call the scanKey API routine (10H) which sets register A with the key value pressed. If LD A,I is immediately after a HALT instruction, then just use RST 08H as described above.

Here is an example of magazine code at 0800H with key input converted to use Mon3 at RAM address 4000H. The code in RED has been modified.

LD A,80H | 4000 | 3E 80
OUT (2),A | 4002 | D3 02
LD B,03H | 4004 | 06 03
LD A,B | 4006 | 78
OUT (1),A | 4007 | D3 01
RST 08H | 4009 | CF
CP 10H | 400A | FE 10
JP NZ,4014H | 400C | C2 14 40
RLC B | 400F | CB 00
JP 4006H | 4011 | C3 06 40
CP 0CH | 4014 | FE 0C
JP NZ,4009H | 4016 | C2 09 40
RRC B | 4019 | CB 08
JP 4006H | 401B | C3 06 40


## Advanced Programming

To assist when developing Z80 programs, Mon3 contains built-in functionality that makes it easy to interface with the TEC-1G hardware.

## RST (Restart) commands

RST commands on the Z80 are one-byte call commands that execute code at certain address locations defined by the Z80. The following table outlines the routines.

Command | Op Code | Description
RST 00H | C7 | Software monitor reset.
RST 08H | CF | Key wait and press routine. This simulates a HALT command where the TEC will wait for a key to be pressed and continue execution. If a key is currently being held down, the routine will wait first until the key is released and then detect the next key. The key that has been pressed will be stored in register A. EG: RST 08H ; Wait for keypress LD B,A ; Load key to register B
RST 10H | D7 | API entry call. Executes a monitor routine. See the API calls section below for details.
RST 18H | DF | API 2 entry call. Graphical LCD routine entry. See the GLCD section below for details.
RST 20H | E7 | Scan Seven Segments and Keys. Multiplex the seven-segment displays and check for a key press. It can be used to display information on the seven segments and check for a key to be pressed. It must be called in a loop until a key is pressed to maintain 7-segment persistence.. Returns Zero flag set when a key is pressed and Register A with the key value. Register DE points to the seven-segment data. See the first program in the Quick Start Programs chapter for an example. Registers DE,A and B will be modified with this routine.

RST 28H | EF | LCD Busy Check. To be called before sending a command to the LCD if directly communicating with the LCD. The routine will only exit when the LCD Busy flag is not set. EG: RST 28H ; Check LCD busy flag LD A,01H ; Load A with a clear screen OUT (04),A ; Send instruction to LCD
RST 30H | F7 | Breakpoint entry. Break code execution at the current address location. See the Debugging Programs chapter for details.
RST 38H | FF | Maskable interrupt handler. Jumps here with Interrupts Enabled (EI), Interrupt Mode 1 (IM 1) and when the INT pin on the CPU goes low. Mon3 will do nothing when this happens. However, a user-defined routine can be used. See the Interrupt section below on how to do this.

## Interrupts

The Z80 CPU has the ability to interrupt the execution of code, handle the interrupt and then resume code execution. This is done in software with Interrupts Enabled (EI) and Interrupt Mode 1 (IM 1) and by hardware when the INT line on the CPU goes low. Mon3 ignores interrupts, but a user-defined routine can be provided to handle the interrupt. To do this, the address of the interrupt routine is to be placed at RAM address 0892H.

ei | ; Enable interrupts
im 1 | ; Interrupt mode 1
ld hl,myINT | ; Interrupt routine
ld (0892H),hl ; Save address in 0892H … continue

myINT:
ld c,03H | ; Bell routine
rst 10H | ; Call API
reti | ; Exit Int routine

This code will sound a bell tone in the speaker when an interrupt occurs.

## NMI (Non-Maskable Interrupts)

Non-Maskable Interrupts occur when the NMI line on the CPU goes low. These interrupts will always trigger. Mon3 ignores the NMI line, but a user-defined routine can be provided to handle the interrupt. To do this, the address of the interrupt routine is to be placed at RAM address 0894H.

ld hl,myNMI ; NMI routine
ld (0894H),hl ; Save address in 0894H … continue

myNMI:
ld c,03H | ; Bell routine
rst 10H | ; Call API
retn | ; Exit NMI routine

This code will sound a bell tone in the speaker when an NMI occurs. The TEC-1G has an NMI jumper that can set NMI to trigger on a Keypad press, a HALT instruction or externally (no jumper).


Credit: Ken Stone

API (Application Programming Interface) commands.

The API on Mon3 exposes routines used by Mon3 which can be used in your own programs. No need to rewrite the world! But more importantly, it makes writing code quicker and easier with most of the complicated stuff removed.

General conventions
The register C holds the API Call number. All other registers except the IX register can be used as parameters if needed. Executing a RST 10H or D7 calls the API.

General Interface

ld c,[API Call Number]
rst 10H

Some Examples

;Produce a short Beep from the speaker
0E 03 | ld c,3 | ;beep call number
D7 | rst 10H

;Display the letter 'G' on the LCD Screen
0E 0E | ld c,14 | ;charToLCD call number
3E 47 | ld a,"G" | ;parameter
D7 | rst 10H

;Wait for a period of time
0E 21 | ld c,33 | ;timeDelay call number
21 00 30 ld hl,3000H ;parameter
D7 | rst 10H

To assist with API call number references, the file api_includes.z80, in the GitHub repository, contains the API Call Number with its Text equivalent for use with your own code.

See https://github.com/MarkJelic/TEC-1G/tree/main/ROMs/MON3/source

API Call List

Utility Calls | # | 0x | Serial Calls | # | 0x | System Latch Call | # | 0x
softwareID | 0 | 0 | serialEnable | 20 | 14 | getCaps | 37 | 25
versionID | 1 | 01 | serialDisable | 21 | 15 | getShadow | 38 | 26
preInit | 2 | 02 | txByte | 22 | 16 | getProtect | 39 | 27
beep | 3 | 03 | rxByte | 23 | 17 | getExpand | 40 | 28
convAToSeg | 4 | 04 | intexHexLoad | 24 | 18 | setCaps | 41 | 29
regAToASCII | 5 | 05 | sendToSerial | 25 | 19 | setShadow | 42 | 2A
ASCIIToSegment | 6 | 06 | receiveFromSerial | 26 | 1A | setProtect | 43 | 2B
stringCompare | 7 | 07 | sendAssembly | 27 | 1B | setExpand | 44 | 2C
HLToString_ | 8 | 08 | sendHex | 28 | 1C | toggleCaps | 48 | 30
AToString | 9 | 09 | genDataDump | 29 | 1D | Misc. Calls | # | 0x
scanSegments | 10 | 0A | stringToSerial | 45 | 2D | timeDelay | 33 | 21
displayError | 11 | 0B | | | | RTCAPI | 46 | 2E
checkStartEnd | 30 | 1E | Input Calls | # | 0x | random | 49 | 31
| | | scanKeys | 16 | 10 | setDisStart | 50 | 32
LCD Calls | # | 0x | scanKeysWait | 17 | 11 | getDisNext | 51 | 33
LCDBusy | 12 | 0C | matrixScan | 18 | 12 | getDisassembly | 52 | 34
stringToLCD | 13 | 0D | joystickScan | 19 | 13 | LCDConfirm | 55 | 37
charToLCD | 14 | 0E | matrixScanASCII | 53 | 35 | getGLCDTerm | 56 | 38
commandToLCD | 15 | 0F | parseMatrixScan | 54 | 36 | setGLCDTerm | 57 | 39
| | | | | | loadFromDisk | 58 | 3A
Menu Calls | # | 0x | Sound Calls | # | 0x | openFile | 59 | 3B
menuDriver | 31 | 1F | playNote | 34 | 22 | readSector | 60 | 3C
paramDriver | 32 | 20 | playTune | 35 | 23 | writeSector | 61 | 3D
menuPop | 47 | 2F | playTuneMenu | 36 | 24 | RGBScan | 62 | 3E

API Utility Calls
softwareID #0 (00H)
Get Software ID String
- Input: nothing
- Return: HL = Pointer to SOFTWARE ASCII String
- Destroy: none

versionID #1 (01H)
Get Version Number and Version String
- Input: nothing
- Return: HL = Pointer to Release ASCII String BC = Release major version number DE = Release minor version number
- Destroys: none

preInit #2 (02H)
Performs a cold reset as if the TEC-1G had just been powered on. Returns to MON3 to its default state.

beep #3 (03H)
Makes a short beep tone to the TEC Speaker
- Input: nothing
- Destroys: A

convAToSeg #4 (04H)
Convert register A to Seven Segment display format
- Inputs: A = byte to convert
DE = address to store segment values (2 bytes)
- Destroys: BC

regAToASCII #5 (05H)
Convert register A to ASCII. IE: 2CH -> "2C"
- Input: A = byte to convert
- Output: HL = two-byte ASCII string
- Destroys: A

ASCIItoSegment #6 (06H)
ASCII to Segment. Converts an ASCII character to Seven Segment display format
- Input: A = ASCII character
- Return: A = Segment character or 0 if out of range
- Destroys: none

stringCompare #7 (07H)
Compare two string
- Input: HL = source pointer
DE = target pointer
B = #bytes to compare (up to 256)
- Output: Zero Flag Set = compare match
- Destroys: HL, DE, A, BC

HLToString #8 (08H)
Convert HL to ASCII string. IE: 2C0FH -> "2C0F"
- Input: HL = value to convert
DE = address of string destination (4 bytes)
- Output: DE = address one after last ASCII entry
- Destroys: A

AToString #9 (09H)
Convert register A to ASCII string. IE: 2CH -> "2C"
- Input: A = byte to convert
DE = address of string destination (2 bytes)
- Output: DE = address one after last ASCII entry
- Destroys: A

scanSegments #10 (0AH)
Multiplex the Seven Segment displays with the contents of DE. Must be called repetitively for segments to stay persistent.
- Inputs: DE = pointer to 6-byte location of segment data
- Destroys: A, B, DE = DE + 6

displayError #11 (0BH)
Display ERROR on the Seven Segments and wait for keypress
- Input: none
- Destroys: all

checkStartEnd #30 (1EH)
Check start and end address differences.
- Input: HL = address location of START value HL+2 = address location of END value
- Output: HL = start address
BC = length of end-start
Carry = set if end is less than start
- Destroys: DE

API LCD Calls
LCDBusy #12 (0CH)
LCD busy check. Checks the LCD busy flag and loops until LCD isn't busy
- Input: nothing
- Destroys: none

stringToLCD #13 (0DH)
ASCII string to LCD. Writes a string (text) to the current cursor location on the LCD
- Input: HL = ASCII string terminated with a zero byte
- Destroy: A, HL (moves to end of the list)

TEXT: .db “HELLO TEC!”,0

ld hl,TEXT
ld c,13
rst 10h

charToLCD #14 (0EH)
ASCII character to LCD. Writes one character to the LCD at the current cursor location
- Input: A = ASCII character
- Destroy: none

ld a,”G”
ld c,14
rst 10h

commandToLCD #15 (0FH)
Command to LCD. Sends an LCD instruction to the LCD
- Input: B = Instruction byte
- Destroy: none

ld b,01 ;clear LCD
ld c,15
rst 10h

API Input Calls
scanKeys #16 (10H)
Universal Key input detection routine. Supports HexPad and Matrix. The routine does not wait for a key press the returns immediately. Only Hexpad keys are detected if using the Matrix Keyboard.
- Return: A = key value (if the following is met)
zero flag set if a key is pressed
carry flag set if press detected of a new key carry flag not set for a key pressed and held or if no key has been pressed
- Destroys: DE if using Matrix Keyboard Key mapping returned in register A
0-F | = 00-0F
Plus | = 10
Minus | = 11
GO | = 12
AD | = 13
Fn-0-F | = 20-2F (Bit 5 set)
Fn-Plus = 30
Fn-Minus = 31
Fn-GO | = 32
Fn-AD | = 33

scanKeysWait #17 (11H)
Generic Key input detection routine. Supports HexPad and Matrix. Waits until a key is pressed. The routine will only detect a key if all keys are released first. Only Hexpad keys are detected if using the Matrix Keyboard.
- Return: A = key value (if following are met)
- zero flag set if a key is pressed
- Destroys: DE if using Matrix Keyboard
See table above for return values in register A

joystickScan #19 (13H)
Joystick port scan routines. This routine will return a value based on the movement/button of the joystick or any combination: IE: UP+DOWN = 03H, Routine must be called repetitively.
- Input: None
- Output: A = Joystick return value between 00H-5FH (0-95)
01H = Up | 10H = Fire 2
02H = Down | 20H = Comm2 (Pin 9)
04H = Left | 40H = Fire 1
08H = Right | 80H = Fire 3
zero flag set if no joystick value returned
- Destroy: none

matrixScan #18 (12H)
Key scan routine for the Matrix Keyboard. This routine detects up to two key presses at the same time. Key values stored in DE. The routine must be called repetitively.
- Input: None
- Output: E = Key pressed between 00H-3FH (0-63)
D = Second key, FF=no key,00=shift,01=Ctrl,02=Fn zero flag set if a key is pressed or combination valid

Key mapping returned in register E (note: some gaps are present) Shift = 00
Ctrl = 01
Fn | = 02
Up | = 03
Down = 04
Left = 05
Right = 06
Caps = 07
Del | = 08
Tab | = 09
Enter = 0A
Esc | = 0C
Space | = 0D
Single Qt = 0E
Comma | = 0F
Minus | = 10
F.Stop | = 11
/ | = 12
0 | = 13
1 | = 14
2 | = 15
3 | = 16

4 = 17
5 = 18
6 = 19
7 = 1A
8 = 1B
9 = 1C
; = 1E
= = 20
A = 24
B = 25
C = 26

D = 27
E = 28
F = 29
G = 2A
H = 2B
I = 2C
J = 2D
K = 2E
L = 2F
M = 30
N = 31

O = 32
P = 33
Q = 34
R = 35
S = 36
T = 37
U = 38
V = 39
W = 3A
X = 3B
Y = 3C

Z = 3D
\ = 3F

matrixScanASCII #53 (35H)
Convert the output of the matrixScan routine to ASCII. matrixScan returns values between 0 and 63 (3Fh). These represent key presses on the keyboard. This routine will convert the output of matrixScan DE, to the actual key pressed in ASCII. If the key doesn't map to an ASCII character then the matrix key value is returned.
Shift+Key will return the capital or secondary characters, Ctrl+Key will return the control code. IE: Ctrl-C will return 03.
- Input: DE = value return from matrixScan.
E = key, D = Secondary key
- Output: A = key pressed in ASCII
- Destroy: BC, HL

Example code on using matrixScanASCII can be found in the Quick Start Programs chapter below.

parseMatrixScan #54 (36H)
Parse matrix keyboard input. This routine checks the key(s) pressed on the Matrix Keyboard and either returns the key pressed in ASCII or handles special cases. The special cases are Key Bounce/Repeat and Caps lock. This routine includes a call to matrixScanASCII and is designed to come directly after matrixScan. As this routine also scans the keyboard, it needs to be included in a Scan loop.
- Input: DE = value return from matrixScan.
E = key, D = Secondary key
Zero Flag = Set if key pressed (from matrixScan)
- Output: A = key pressed in ASCII
Carry Flag = Set if ASCII returned
Carry Flag = Not Set if special case and no ASCII returned
- Destroy: BC, HL

scan_loop:
ld c,18 | ;matrixScan
rst 10h | ;API call
ld c,54 | ;parseMatrixScan
rst 10h | ;API call
jr nc,scan_loop
ld c,22 | ;txByte Send to FTDI
rst 10h | ;API call

API Serial Data Transfer Calls
serialEnable #20 (14H)
Enable BitBang serial port for serial transmit. Disco LED's glow blue to indicate ready status.
- Input: none
- Destroy: A

serialDisable #21 (15H)
Disable BitBang serial port for serial transmit. Disco LEDs turn off.
- Input: none
- Destroy: A

txByte #22 (16H)
Bit Bang FTDI USB transmit routine. Send one byte over FTDI USB serial connection. It assumes a UART connection of 4800-8-N-2.
- Input: A = byte to transmit
- Output: nothing
- Destroy: none

rxByte #23 (17H)
Bit Bang FTDI USB receive routine. Receive one byte via the FTDI USB serial connection. It assumes a UART connection of 4800-8-N-2. Note routine will wait until a bit is detected.
- Input: nothing
- Return: A = byte received
- Destroy: none

intelHexLoad #24 (18H)
Load an Intel Hex file via the FTDI USB serial connection. Displays file progress on the segments and PASS or FAIL at the end of the load. Intel Hex file format is a string of ASCII with the following parts:
MARK | LENGTH | ADDRESS | RECORD TYPE | DATA | CHECKSUM
:10200000210621CD7D20CD98203A00213C320021AF <- EXAMPLE LINE

MARK is a colon character, LENGTH is the number of bytes per line, ADDRESS is the 2-byte address of where the data is to be stored. RECORD TYPE is 00 for Data and 01 for EOF. DATA is the bytes to be stored. CHECKSUM is the addition of all bytes in one line.

- Input: nothing
- Output: nothing
- Destroy: HL,DE,BC,A

sendToSerial #25 (19H)
SIO Binary Dump. Transfer TEC data to a serial terminal. From address and Length of data is needed for input. Use checkStartEnd to get length if using From/To address.
- Input: HL = start address
DE = length in bytes of data to send
- Destroys: A,HL,DE,BC

receiveFromSerial #26 (1AH)
SIO receives binary data. Receive binary data from FTDI. From address and Length of data is needed for input. Use checkStartEnd to get length if using From/To address.
- Input: HL = start address
DE = length in bytes of data to receive
- Destroys: A,HL,DE,BC

sendAssembly #27 (1BH)
Send Assembly instructions to the serial port. Print out the disassembled code that is on the TEC in readable assembly language on the serial terminal. From address and Length of data is needed for input. Use checkStartEnd to get length if using From/To address.
- Input: HL = start address
DE = length in bytes of data to disassemble
- Destroys: A,HL,DE,BC

sendHex #28 (1CH)
Send a traditional HEX dump as text to the serial terminal. Up to 16 bytes are displayed per line. From address and Length of data is needed for input. Use checkStartEnd to get length if using From/To address.
- Input: HL = start address
DE = length in bytes of data to send as Hex
- Destroys: A,HL,DE,BC

genDataDump #29 (1DH)
Generate data dump in ASCII. Print the Address and then B number of bytes. This routine is a subroutine in the _sendHex routine.
- Input: B = number of bytes to display
- HL = start address of data dump
- DE = address of string destination
- Output: DE = zero terminated address one after last ASCII entry
IE: "4000: 23 34 45 56 78 9A BC DE",0
- Destroys: A, HL (moves to next address after last byte)

stringToSerial #45 (2DH)
ASCII string to FTDI Serial Port. Writes a string (text) to the serial port
- Input: HL = ASCII string terminated with a zero byte
- Destroy: A, HL (moves to end of the list)

TEXT: .db “HELLO TEC!”,0

ld hl,TEXT
ld c,55
rst 10h

API Menu & Parameter Calls
menuDriver #31 (1FH)
Menu driver for user programs. Creates a selectable custom menu/list. Keys: Go = Select menu item, AD = Exit Menu, Plus/Minus = Navigate menu. If a menu item is selected by pressing Go, a jump is performed to the
menu routine address (see example below). If the user routine ends with a RET instruction, control will be brought back to the menu. There is no need to call the menuDriver again after the routine returns.

When an item is selected, the routine that is associated with the menu entry will be called. The selected menu item number will be stored at RAM address 0897H. Items start from 0.

If after the RET the menu is to be removed or popped off, then call the menuPop routine prior to the RET. This will return control to the previous menu or enter Data Entry mode.

The menu can also be used as a selectable List. Use menuPop to close the list once the item has been selected. See an example below on how to do this.

- Input: HL = Pointer to Menu configuration.
- Destroys: A, HL

All strings are ZERO terminated! Except the 7 Segment Text must be ASCII of exactly 6 bytes. Menu configuration is as follows.

<# Menu Entries>, <7 Segment Text>, <Menu Text Title>, [<Menu Text Label>, <Menu Routine Address>]+
EG: .db 2 | ; Two menu items
.db "MyGame" | ; 7 segment text (6 bytes)
.db "Games",0 | ; Menu title
.db "TEC Invaders",0 ; Text and Routine
.dw invaders
.db "TEC Maze",0 ; Text and routine .dw maze

paramDriver #32 (20H)
Parameter data entry driver. Creates a list of editable two-byte parameters. Keys: Go = Continue, AD = Exit, Plus/Minus = Navigate, 0-F = enter values
- Input: HL = Pointer to Parameter configuration.

Once the Go key is pressed, code will continue after the API call. The parameter view on the LCD will automatically be removed and the LCD will display the prior view to the parameter call. There is no need to call menuPop to restore the previous LCD view.

Parameter text can be no longer than 14 characters. Parameters entered will be stored in the Param RAM Address locations of two-bytes each. All strings are ZERO terminated! Except the 7 Segment Text must be ASCII of exactly 6 bytes. Parameter configuration is as follows.

<No. of Entries>, <7 Segment Text>, <Parameter Title Text>, [<Param Text Label>, <Param RAM Address>]+
EG: .db 3 | ; Three parameters
.db "Params" | ; 7 segment text (6 bytes)
.db "= Enter Parameters =",0 ; Parameter title
.db "Start Address:",0 | ; Text and Address
.dw RAM_LOC_1
.db "End Address:",0 | ; Text and Address
.dw RAM_LOC_2
.db "Dest. Address:",0 | ; Text and Address
.dw RAM_LOC_3

menuPop #47 (2FH)
Replace the current menu with its parent menu if any. If menus have been nested, the parent menu will become the active menu. This is the same as pressing the AD key but done in software. If no parent menu exists then the Monitor mode is changed to Data Entry View. Useful if using the menu as a Select List where execution of code is to be continued.
- Input: none.
- Destroys: A

Menu and Parameter Driver Example
Create a Menu with 3 items. The first item jumps to a routine which is the standard way to use the menu. The second item displays a selectable list that saves a value in RAM and returns to the menu. The last item will create a parameter entry list of four 2-byte items.

MENUDRIVER .EQU 1FH ;Menu API
PARAMDRIVER .EQU 20H ;Param API
MENUPOP | .EQU 2FH ;Menu Pop API
PROGRAM1 | .EQU 1000H ;Program 1
BAUD | .EQU 2008H ;Baud value
PARAM1 | .EQU 2000H ;two bytes
PARAM2 | .EQU 2002H ;per param
PARAM3 | .EQU 2004H
PARAM4 | .EQU 2006H

;Create Menu
0E 1F ld c,MENUDRIVER
21 00 30 ld hl,menuCFG ;config
D7 | rst 10H ;API call
;Code continues in menu routines

;Create Selectable List
setBaud:
0E 1F ld c,MENUDRIVER
21 00 30 ld hl,baudCFG ;config
D7 | rst 10H ;API call
;Code continues in menu routines

;Baud rate saving code
baud12:
21 00 12 ld hl,1200H ;baud rate 18 0D jr saveBaud ;cont..
baud24:
21 00 24 ld hl,2400H ;baud rate 18 08 jr saveBaud ;cont..
baud48:
21 00 48 ld hl,4800H ;baud rate 18 03 jr saveBaud ;cont..
baud96:
21 00 96 ld hl,9600H ;baud rate saveBaud:
22 08 20 ld (BAUD),hl ;save baud
0E 2F | ld c,MENUPOP
D7 | rst 10H ;API call
C9 | ret ;Return to Main Menu

;Create Parameter Entry
createParam:
0E 20 ld c,PARAMDRIVER
21 80 30 ld hl,paramCFG ;config
D7 | rst 10H ;API call
...Parameter code continues
C9 | ret ;Return to Main Menu

;Main Menu Configuration
menuCFG:
.db 3 ;three entries
.db "-Menu-"
.db "= MENU TITLE =",0
.db "Run Program",0
.dw PROGRAM1
.db "Set Baud Rate",0
.dw setBaud
.db "Parameters",0
.dw createParam

;Selectable List Configuration baudCFG:
.db 4 ;four entries
.db "BAUDrt"
.db "= Select Baud =",0
.db "1200",0
.dw baud12
.db "2400",0
.dw baud24
.db "4800",0
.dw baud48
.db "9600",0
.dw baud96

;Parameter Entry Configuration paramCFG:
.db 4 ;four entries
.db "Input "
.db "= PARAM TITLE =",0
.db "Start Address",0
.dw PARAM1
.db "End Address",0
.dw PARAM2
.db "Copy Address",0
.dw PARAM3
.db "Backup Address",0
.dw PARAM4

API Sound Calls
playNote #34 (22H)
Play a note. Play a note with a given frequency and wavelength
- Input: HL = frequency (01-7F)
B = wavelength (00-FF)
- Destroys: HL, BC, A

playTune #35 (23H)
Play a series of notes. To play a note use a reference between 01H and 18H. Where 01H is the lowest frequency and 18H is the highest frequency. Use 00H for a pause and any value above 18H to exit. A single pause can be used to separate notes.

Note reference table is as follows:
G | 01H | C# | 07H | G | 0DH | C# | 13H
G# | 02H | D | 08H | G# | 0EH | D | 14H
A | 03H | D# | 09H | A | 0FH | D# | 15H
A# | 04H | E | 0AH | A# | 10H | E | 16H
B | 05H | F | 0BH | B | 11H | F | 17H
C | 06H | F# | 0CH | C | 12H | F# | 18H
- Input: DE = Address of first note
- Destroy: A,B,DE,HL

playTuneMenu #36 (24H)
Play a series of notes with the _playTune routine, but the address of the first note is selected via a parameter menu.
- Input: none
- Destroy: A,B,DE,HL

API System Latch Calls
getCaps #37 (25H)
Get Caps lock state
- Input: none
- Output: A = caps lock state; 0 = off, 80H = on

getShadow #38 (26H)
Get SHADOW state
- Input: none
- Output: A = shadow state; 0 = off, 01H = on

getProtect #39 (27H)
Get PROTECT state
- Input: none
- Output: A = protect state; 0 = off, 02H = on

getExpand #40 (28H)
Get EXPAND state
- Input: none
- Output: A = expand state; 0 = off, 04H = on

setCaps #41 (29H)
Set Caps lock state
- Input: A = Desired caps lock state; 0 = off, 80H = on
- Destroy: A

setShadow #42 (2AH)
Set Shadow state
- Input: A = Desired shadow state; 0 = off, 01H = on
- Destroy: A

setProtect #43 (2BH)
Set Protect state
- Input: A = Desired protect state; 0 = off, 02H = on
- Destroy: A

setExpand #44 (2CH)
Set Expand state
- Input: A = Desired expand state; 0 = off, 04H = on
- Destroy: A

toggleCaps #48 (30H)
Toggle Caps Lock state. On/Off or vice versa
- Input: none
- Destroy: A

Miscellaneous Calls
timeDelay #33 (21H)
A 16-bit delay routine. An input delay of 2000H is approximately 50ms.
- Input: HL = delay amount
- Destroys: none

random #49 (31H)
Random number generator. Return a random number between 00H-FFH
- Input: none
- Output: A = pseudo-random number
- Destroy: B

setDisStart #50 (32H)
Set Disassembly start address. Set the first address for disassembly output
- Input: HL = start address
- Output: none
- Destroy: none

getDisNext #51 (33H)
Get Disassembly next address. The new start address for the next output.
- Input: none
- Output: HL = start address
- Destroy: none

getDisassembly #52 (34H)
Generate Disassembly line. Must call setDisStart prior. Only need to call setDisStart once as the next address is automatically increased.
- Input: none
- Output: HL = pointer to disassembly ASCII, zero terminated
- Destroy: none

RCTAPI #46 (2EH)
Call a Real Time Clock (RTI) routine for the RTC add on board. See the RTC chapter below for details on this add-on.
- Input: B = RTC routine number
Other = Depends on the RTC routine

LCDConfirm #55 (37H)
Ask a confirmation message on the LCD before proceeding. Press ‘C’ to confirm or any other key to not confirm.
- Input: none
- Output: Zero Flag = set == confirmed or ‘C’ pressed
- Destroy: A,HL

getGLCDTerm #56 (38H)
Get GLCDTERM state. Check if using the GLCD as a Terminal
- Input: none
- Output: A = GLCD Terminal state; 0 = off, FF = on

setGLCDTerm #57 (39H)
Set GLCD Terminal state
- Input: A = Desired GLCD Terminal state; 0 = off, FF = on
- Destroy: A

loadFromDisk #58 (3AH), openFile #59 (3BH), readFile #60 (3CH), writeFile #61 (3DH)
See the Hard Drive Access section for details of these routines.

RGBScan #62 (3EH)
Multiplex the 8x8 RGB Board with 3 colours, Red, Green and Blue. Need to be called in a loop. The Row data is from top to bottom.
- Input: IY = 24 Bytes of Row Data (8 Red, 8 Green, 8 Blue) LOOP:

← This is whats displayed; rst 10h; with the data below; jr LOOP

ld iy,RGBDATA

RGBDATA: .db 00h,00h,24h,00h,18h,00h,00h,00h ; RED Data .db 24h,3Ch,5Ah,0FFh,0FFh,0BDh,42h,24h ; GREEN Data .db 00h,00h,00h,00h,18h,00h,00h,00h ; BLUE Data

## Real Time Clock (RTC) Add-On Interface

A RTC add-on board that connects to the General Purpose IO port on the TEC-1G can be interfaced with Mon3. The board uses the DS1302 Real Time Clock chip. The RTC chip is designed to respond on port FCH.

The DS1302 supports 12 and 24 hour
clock modes, a 100 year calendar
(2000-2099) with leap year support,


and 31 bytes of general purpose nonvolatile RAM. The TEC Designers have called the NVRAM, “Parameter RAM” or PRAM.

To initially set the RTC, a convenient RTC Setup routine has been provided in the Settings item in the Main Menu. Select “Configure RTC”. Press the following keys to update the time/date: 0 = Hour, 1 = Minute, 2 = Second, 3 = 12/24h, 4 = Day of week, 5 = Day, 6 = Month, 7 = Year, 8 = View RTC PRAM, F = Reset RTC, AD = Exit. When viewing RTC PRAM data, Plus = Move Down, Minus = Move Up, AD = Exit back to RTC Setup.

Mon3 will
automatically utilise
the internal PRAM to
retain some settings
when the TEC-1G is
powered down. 14
Free bytes are

available to be used by the user. The reserved Mon3 PRAM slots are:

Slot | Reserved for | Slot | Reserved for | Slot | Reserved for
0-5 | Quick Jump Addresses | 12-13 | Baud Rate | 16-29 | User Free RAM
6-11 | Start/End/Dest Addresses | 14-15 | Addr. Inc. / Beep | 30 | Mon3 Checksum

When the RTC board is first used, TEC-1G settings are saved to the PRAM during power on. Manual resetting of the PRAM can also be achieved by selecting the “Reset RTC & PRAM” option in the Settings item in the Main Menu. This will reset the time/date and Mon3 reserved values.

RTC API Calls
The RTC API uses the standard rst 10H call with the addition of the B register to specify which RTC API function is required. This way, all RTC functions only occupy a single Mon3 API call.

General Interface

| ld c,2EH | ;RTC API call number
ld b,[RTC Call Number]
| rst 10H

Some Examples

;Get the current time
01 2E 02 ld bc,022EH | ;getTime + RTC API
D7 | rst 10H

;Set the current time to 10:24:46
01 2E 03 ld bc,032EH | ;setTime + RTC API
21 00 30 ld hl,1024H | ;10 hours, 24 minutes
16 46 | ld d,46H | ;46 seconds
D7 | rst 10H

;Write a byte to the RTC NV Ram
01 2E 0C ld bc,0C2EH | ;writeRTCbyte + RTC API
11 FF 02 ld de,02FFH | ;Save FF in position 02
D7 | rst 10H
RTC Routine | # | 0x | RTC Routine | # | 0x | RTC Routine | # | 0x
checkDS1302 | 0 | 0 | setDay | 7 | 07 | BCDToBin | 14 | 0E
resetDS1302 | 1 | 01 | get1224Mode | 8 | 08 | binToBCD | 15 | 0F
getTime | 2 | 02 | set12HrMode | 9 | 09 | formatTime | 16 | 10
setTime | 3 | 03 | set24HrMode | 10 | 0A | formatDate | 17 | 11
getDate | 4 | 04 | readRTCByte | 11 | 0B | RTCSetup | 18 | 12
setDate | 5 | 05 | writeRTCByte | 12 | 0C
getDay | 6 | 06 | burstRTCRead | 13 | 0D

checkDS1302 #0 (00H)
Check if a DS1302 is detectable, by verifying that the DS1302's registers return expected results.
- Input: none
- Output: Carry flag set = no RTC add-on board present
- Destroy: A

resetDS1302 #1 (01H)
Resets the DS1302 to a known state - clears existing Time and Calendar. Does not clear RTC RAM. Sets DS1302 to 01:00.00 AM, 01/01/2000.
- Input: none
- Destroy: none
Note: To be used only when the RTC requires a settings reset e.g. if it's not "ticking". Use checkDS1302 to "reset" the DS1302 to a ready state, as part of program initialization.

getTime #2 (02H)
Get time from RTC. Time is formatted in either 12 or 24 hour mode, depending on selected mode.
- Input: none
- Output: H = hour, bit 5=am/pm flag (in 12hr mode). 1=PM L = minute
D = second
- Destroy: A

Note that all returned registers are BCD coded, so 10:24:36 results in HL=1024h, D=36h

setTime #3 (03H)
Sets the time in the RTC chip. Time is formatted in either 12 or 24 hour mode, depending on selected mode.
- Input: H = hour, bit 5=am/pm flag (in 12hr mode). 1=PM L = minute
D = second
- Destroy: A,E

The 12/24 hour mode flag is preserved. Note that all registers are BCD coded, so 10:24:36 is formatted as HL=1024h, D=36h

getDate #4 (04H)
Returns the present Calendar date, month, year.
- Input: none
- Output: H = date
L = month
DE = year
- Destroy: A

Note that values returned are BCD coded.

setDate #5 (05H)
Sets the Calendar to a specified date/month/year. Invalid dates may be accepted e.g. 30 February as the DS1302 does not validate dates as programmed; it simply rolls over at midnight.
- Input: H = date
L = month
DE = year 2000-2099, D is assumed to be 20h
- Destroy: A

Note that values returned are BCD coded.

getDay #6 (06H)
Gets the Day of the week i.e. "Monday", "Tuesday", etc. 01 = Monday, 07 = Sunday.
- Input: none
- Output: D = 01-07 (Day of week)
HL = address of zero terminated DOW string
- Destroy: A

The names of the days of the week are stored in the Mon3 ROM; HL points to the correct string for that day.

setDay #7 (07H)
Sets the Day of the week. 01 = Monday, 07 = Sunday.
- Input: D = 01-07 (Day of week)
- Output: Carry Flag set = invalid value supplied
- Destroy: A

get1224Mode #8 (08H)
Reports if the RTC is currently in 12 or 24 hour mode.

- Input: none
- Output: A = 00H (24hr), 80H (12hr), Zero flag set
- Destroy: none

set12HrMode #9 (09H)
Set RTC to 12 hour mode. That is, the hour is subsequently returned as 01-12, and an AM/PM flag.
- Input: none
- Output: Carry Flag set = already in 12 hr mode
- Destroy: A,D

set24HrMode #10 (0AH)
Set RTC to 24 hour mode (also known as Military Time). That is, the hour is subsequently returned as 00-23.
- Input: none
- Output: Carry Flag set = already in 24 hr mode
- Destroy: A,D

readRTCByte #11 (0BH)
Reads a byte from the RTC PRAM.
- Input: D = memory slot to return 0–30
- Output: A = value stored in memory
- Destroy: none

writeRTCByte #12 (0CH)
Writes a byte to the RTC PRAM.
- Input: D = memory slot to write to 0–30 E = value to store
- Destroy: A

burstRTCRead #13 (0DH)
Reads all 31 RTC PRAM bytes and fills a user-supplied buffer with that data. The user buffer should be 31 bytes long.
- Input: HL = location to write to (31 bytes)
- Output: HL = moved to address after last byte
- Destroy: A

binToBcd #14 (0EH)
Converts the value in register A from BCD encoded, to binary. i.e. "23h" becomes "23" decimal.

- Input: A = BCD Value to convert
- Output: A = Binary value of BCD
- Destroy: none

bcdToBin #15 (0FH)
Converts the value in register A from binary to BCD. i.e. "52" decimal becomes "52h".
- Input: A = Binary Value to convert
- Output: A = BCD value of Binary
- Destroy: none

formatTime #16 (10H)
Takes a time and fills a user-supplied buffer with an ASCIIZ string formatted as human-readable text. The user-supplied buffer should be at least 12 bytes long.

Bits 7 and 5 of the hour is used to format the time, if it is a 12hr mode timestamp - AM or PM is appended accordingly.
- Input: H = hour (bit 7 = 12/24hr, 1=12hr mode) (bit 5 = am/pm flag, 1=PM) L = minute
D = second
IY = address of user supplied buffer
- Output: IY = moved to address after last byte
- Destroy: A

formatDate #17 (11H)
Takes a date and fills a user-supplied buffer with an ASCIIZ string formatted as human-readable text. The user-supplied buffer should be at least 11 bytes long.
Dates are output as DD/MM/YYYY
- Input: H = Date
L = Month
DE = Year (2000 - 2099)
IY = address of user supplied buffer
- Output: IY = moved to address after last byte
- Destroy: A

RTCSetup #18 (12H)
Standalone application that assists with configuring the RTC for initial use. The LCD displays the current RTC time and date with the instructions.

Keys: 0 = Hour, 1 = Minute, 2 = Second, 3 = 12/24h, 4 = Day of week, 5 = Day, 6 = Month, 7 = Year, 8 = View RTC PRAM, F = Reset RTC, AD = Exit.

When viewing RTC RAM data, Plus = Move Down, Minus = Move Up, AD = Exit back to RTC Setup.

A TEC-1G with various add-on boards. Credit: Andrew McRae


## Graphical LCD Add-On Interface


Mon3 includes a Graphical LCD (GLCD) library that will work with the TEC-DECK Graphical LCD PCB Add-On. If the Graphical LCD is installed on the TEC-1G via the TEC-DECK headers, special GLCD API calls can be used to interface with the GLCD. The library is for GLCDs with the ST7920 chip.

The GLCD library contains a variety of routines that can produce simple shapes and lines. These include text, lines, rectangles, circles and pixels.

General Conventions
The register A holds the API Call number. All other registers except the IX register can be used as parameters if needed. Executing a RST 18H or DF calls the GLCD API.

General Interface

ld a,[API Call Number]
rst 18H

The following code will draw a box and write text to the GLCD

; Initialise and set to Graphics Mode
3E 00 | ld a,0 | ; Initialise GLCD
DF | rst 18H
3E 04 | ld a,4 | ; Graphics Mode
DF | rst 18H

; Draw Box - Box Outline Example
01 20 00 ld bc,0020H | ; X0, Y0
11 3F 7F ld de,7F3FH | ; X1, Y1
3E 06 | ld a,6 ; Draw a outline box from X0,Y0 to X1,Y1
DF | rst 18H

; Plot Graphics to LCD Screen (must do)
3E 0C | ld a,12 | ; Plot To LCD
DF | rst 18H

;Write Text to the Screen
3E 05 | ld a,5 | ; Text Mode
DF | rst 18H
0E 01 | ld c,01H | ; Row 1
3E 0D | ld a,13 | ; Print String
DF | rst 18H
54 45 43 2D 31 47 00 .db "TEC-1G",0

initLCD must be called at the start of every program. The GLCD has two modes, Text and Graphics. Both Text and Graphics can be displayed at the same time. These modes must be selected before the drawing or text routine. Also, plotToLCD must be called to display any graphics drawn to the screen. The above example adheres to these principles.

GLCD API Calls list

Routine | # | 0x | Routine | # | 0x
initLCD | 0 | 0 | setBufClear | 17 | 11
clearGBUF | 1 | 01 | setBufNoClear | 18 | 12
clearGrLCD | 2 | 02 | clearPixel | 19 | 13
clearTxtLCD | 3 | 03 | flipPixel | 20 | 14
setGrMode | 4 | 04 | drawGraphic | 21 | 15
setTxtMode | 5 | 05 | invGraphic | 22 | 16
drawBox | 6 | 06 | initTerminal | 23 | 17
drawLine | 7 | 07 | sendCharToLCD | 24 | 18
drawCircle | 8 | 08 | sendStringToLCD | 25 | 19
drawPixel | 9 | 09 | sendRegToLCD | 26 | 1A
fillBox | 10 | 0A | sendHLToLCD | 27 | 1B
fillCircle | 11 | 0B | setCursor | 28 | 1C
plotToLCD | 12 | 0C | getCursor | 29 | 1D
printString | 13 | 0D | displayCursor | 30 | 1E
printChars | 14 | 0E | autoLF | 31 | 1F
delayUS | 15 | 0F | underline | 32 | 20
delayMS | 16 | 10 | plotAlways | 33 | 21

GLCD API Configure Calls
initLCD #0 (00H)
Initialise the LCD Screen. This routine is to be called before any other routine.
- Input: nothing
- Destroy: All

clearGBUF #1 (01H)
Clear the Graphics Buffer. The Graphics Buffer or GBUF is the internal memory area that contains pixel data for the LCD. The drawing routines write data to the GBUF. Once all pixels are set, this buffer is then plotted to the LCD with the plotToLCD Routine. Clearing the GBUF is a good way to ensure the pixel area is empty.
- Input: nothing
- Destroy: All

clearGrLCD #2 (02H)
Clear the Graphics LCD Screen. This routine clears the GDRAM or Graphics screen on the LCD.
- Input: nothing
- Destroy: All

clearTxtLCD #3 (03H)
Clear the Text LCD Screen. This routine clears the DDRAM or Text screen on the LCD.
- Input: nothing
- Destroy: All

setGrMode #4 (04H)
Set the LCD to Graphics Mode. This routine puts the LCD in Graphics mode (Extended Instructions). Any further instructions to the LCD will be for the graphics screen. It only needs to be called once if multiple graphics routines are used.
- Input: nothing
- Destroy: AF,DE

setTxtMode #5 (05H)
Set the LCD to Text Mode. This routine puts the LCD in Text mode (Basic Instructions). Any further instructions to the LCD will be for the text screen. It only needs to be called once if multiple text routines are used.
- Input: nothing
- Destroy: AF,DE

GLCD API Graphics Calls
drawBox #6 (06H)
Draws a single-line rectangle between two points X1, Y1 and X2, Y2.
- Input: B = X1-coordinate (0-127)
C = Y1-coordinate (0-63)
D = X2-coordinate (0-127)
E = Y2-coordinate (0-63)
- Destroy: AF,HL
ld bc,0020H | ;X0, Y0
ld de,7F3FH | ;X1, Y1
ld a,6 | ;drawBox
rst 18H

drawLine #7 (07H)
Draws a straight line between X1, Y1 and X2, Y2. Uses the Bresenham Line drawing algorithm. http://members.chello.at/~easyfilter/bresenham.html
- Input: B = X1-coordinate (0-127)
C = Y1-coordinate (0-63)
D = X2-coordinate (0-127)
E = Y2-coordinate (0-63)
- Destroy: All
ld bc,0010H | ;X0, Y0
ld de,7F30H | ;X1, Y1
ld a,7 | ;drawLine
rst 18H

drawCircle #8 (08H)
Draw a circle from midpoint to radius.
- Input: B = Mid-X-coordinate (0-127) C = Mid-Y-coordinate (0-63) E = Radius (1-63)
- Destroy: All
ld bc,0818H | ;Mid X, Mid Y
ld e,08H | ;Radius
ld a,8 | ;drawCircle
rst 18H

drawPixel #9 (09H)
Draws a single Pixel.
- Input: B = X-coordinate (0-127) C = Y-coordinate (0-63)
- Destroy: AF,HL
ld bc,4020H | ;X,Y
ld a,9 | ;drawPixel
rst 18H

fillBox #10 (0AH)
Draws a filled rectangle between X1, Y1 and X2, Y2.
- Input: B = X1-coordinate (0-127)
C = Y1-coordinate (0-63)
D = X2-coordinate (0-127)
E = Y2-coordinate (0-63)
- Destroy: AF,HL
ld bc,0020H | ;X0, Y0
ld de,7F3FH | ;X1, Y1
ld a,10 | ;fillBox
rst 18H

fillCircle #11 (0BH)
Draws a filled circle from a midpoint to a radius. This routine iteratively calls the drawCircle routine increasing the radius until it equals the register E. There might be gaps in the filled circle, but hey it looks just like what you get on a BASIC program.
- Input: B = Mid-X-coordinate (0-127)
C = Mid-Y-coordinate (0-63) E = Radius (1-63)
- Destroy: All
ld bc,1018H | ;Mid X, Mid Y
ld e,08H | ;Radius
ld a,11 | ;fillCircle
rst 18H

plotToLCD #12 (0CH)
This routine draws the Graphics Buffer or GBUF to the Graphics LCD screen. It is usually called after one of the drawing routines is called. This routine must be called for any graphics to appear on the GLCD. After plotting the GBUF is cleared. Use setBufNoClear to retain the GBUF.
- Input: nothing
- Destroy: All

GLCD API Text Calls
printString #13 (0DH)
Prints ASCII text on a given row. There are 4 text rows on the LCD screen. The text is to be defined directly after the RST 18H routine and is to be terminated with a zero.
- Input: C = row number (0-3)
Text = "String" on the next line, terminate with 0
- Destroy: All
ld c,02H | ;Row 2
ld a,13 | ;printString
rst 18H
.db 02H, " This Text ", 1BH ,00H


There are 128 characters that are available from 00H-7FH. Conveniently, Alphanumeric characters align with the ASCII table.

printChars #14 (0EH)
Print Characters on the screen in a given row and column. This routine is similar to the one above but character row and column placement can be made. Characters to be printed are to be terminated with a zero.

Even though there are 16 columns, only every second column can be written to and two characters are to be printed. IE: if one character is to be printed in column 2, then set B=0 and print " x", putting a space before the character.
- Input: B = column (0-7)
C = row (0-3)
HL = start address of text data
- Destroy: All. (HL will be at the end of the text data)

ld hl,TEXT_DATA
ld bc,0102H | ;Column 1, Row 2
ld a,14 | ;printChars
rst 18H
TEXT_DATA:
.db "Hello!",0

GLCD API Utility Calls
delayUS #15 (0FH)
Delay loop for LCD to complete its instruction. Every time a command is sent to the LDC, it requires a small amount of time to complete that operation. IE: setting extended instruction mode. The time needed for most operations is defined in the LDC specification. It is usually around 72us. This routine is used internally, but can also be used directly. The delay time depends on how fast the CPU is running.
- Input: nothing
- Destroy: AF,DE

ld a,02H ;Home instruction
out (07),a ;send instruction to GLCD ld a,15 ;delayUS
rst 18H

delayMS #16 (10H)
This is the same as the above routine, but the delay can be software controlled.
- Input: DE = delay value
- Destroy: AF,DE

ld a,01H ;Clear instruction
out (07),a ;send instruction to GLCD ld de,0050H ;longer delay
ld a,16 ;delayMS
rst 18H

setBufClear #17 (11H)
On every plotToLCD call, clear the graphics buffer GBUF. Calling this routine will clear the graphics buffer on every draw to the LCD. This is useful if doing animation that requires a new drawing to be displayed on every plot or frame.
- Input: none
- Destroy: AF

setBufNoClear #18 (12H)
Do not clear the graphics buffer on every plotToLCD. Calling this routine will not clear the graphics buffer on every draw to LCD. This is useful for adding graphics data to an existing drawing.
- Input: none
- Destroy: AF

clearPixel #19 (13H)
Removes or clears a single Pixel from the LCD.
- Input: B = X-coordinate (0-127) C = Y-coordinate (0-63)
- Destroy: AF,HL
ld bc,4020H | ;X,Y
ld a,19 | ;clearPixel
rst 18H

flipPixel #20 (14H)
Inverts a single Pixel. If the Pixel is on, it will turn off. If the Pixel is off, it will turn on.
- Input: B = X-coordinate (0-127)
C = Y-coordinate (0-63)
- Destroy: AF,HL
ld bc,4020H | ;X,Y
ld a,20 | ;flipPixel
rst 18H

GLCD API Drawing Calls
drawGraphic #21 (15H)
Draw an ASCII character or Sprite to the GLCD at the current cursor. ASCII characters are 6x6 or 5x5 Pixels and most have a gap to the right and bottom for spacing. plotToLCD is still required to be called after all graphics have been drawn.

Graphics data is in the format of up to 16 bytes across and 64 bytes down, where a BIT set will indicate a pixel to be drawn. If graphics are less than 8 bits wide, then bits are read from the least significant bit.
- Input: D = ASCII number or
D = 0 then:
HL = Address of graphic data
B = width of graphic in pixels (1-128) C = height of graphic in pixels (1-64)
- Destroy: All
ld a,00H | ;Custom graphic
ld hl,picture | ;Data table address
ld b,16 | ;B=16 pixels wide
ld c,8 | ;C=8 pixels down
ld a,21 | ;drawGraphic
rst 18H
ld a,12 | ;plotToLCD
rst 18H

<cont...>


picture:
.db 10000011b,11000001b
.db 10000100b,00100001b
.db 10001010b,01010001b
.db 10001000b,00010001b
.db 10001010b,01010001b
.db 10001001b,10010001b
.db 10000100b,00100001b
.db 10000011b,11000001b

This example will display this image from the current cursor position

Here is the complete list of ASCII characters 00H-FFH that can be displayed. Each character is up to 6 x 6 pixels and is numbered left to right, top to bottom. The characters align with the standard ASCII Table.

invGraphic #22 (16H)
Inverse graphics printing. Calling this routine will TOGGLE the inverse drawing flag. The initial state is normal. If in inverse mode, a pixel drawn using the drawGraphic routine is displayed if a BIT is not set.
- Input: none
- Output: none
- Destroy: A

underline #32 (20H)
Underline the graphics printing. Calling this routine will TOGGLE the underline drawing flag. The initial state is off. If in underline mode, the last pixel row will be set as on. Only applicable when using the drawGraphic routine.
- Input: none
- Output: none
- Destroy: A

The TEC Frogger game uses the GLCD and its API routines.

GLCD API Terminal Emulator Calls
initTerminal #23 (17H)
Initialise the GLCD for terminal emulation. This routine is to be called before any TERMINAL routine is called. It will set graphics and scroll buffers. It also Clears the GBUF, sets the cursor to top left and displays the cursor. This routine will also call initLCD.
- Input: none
- Output: none
- Destroy: All

autoLF #31 (1FH)
Automatic Line Feed when the cursor reaches the end of the row. When the cursor passes the last column, character entered via the sendCharToLCD will either wrap around, or start on a new line.
- Input: C = 0, Auto LF set, C <> 0, not set
- Output: none
- Destroy: A

plotAlways #33 (21H)
When sendCharToLCD is called, determine if the character should be sent immediately to the GLCD or be held in a buffer. If held in a buffer, call plotToLCD to update the GLCD. The default is ON and characters will be sent immediately. Turning this flag OFF can speed up the output if multiple characters are sent to the screen. Once sent, characters can be plotted all at once. If displaying characters directly from a keyboard input, this flag should be set ON.
- Input: C = 0, Plot Always set, C non zero, not set
- Output: none
- Destroy: A

sendCharToLCD #24 (18H)
Send or handle ASCII characters to the GLCD screen. This routine displays ASCII characters to the GLCD screen and handles some special control characters. It also handles scrolling history of 10 lines. Characters are drawn at the current cursor position. The Cursor will increment when a character is drawn. Characters will automatically be displayed on the LCD. Some special characters are:
- CR / 0DH = will move the cursor down and reset it column
- LF / 0AH = is ignored
- FF / 0CH = clear the terminal and scroll buffer (destroy AF,BC,DE,HL)
- BS / 08H = will delete the character at the cursor and move cursor back one
- HT / 09H = will TAB 4 spaces
- UP / 05H = will scroll up one line if any
- DN / 06H = will scroll down one line if any
- Input: C = ASCII character to send to the LCD screen or C = 0 then draw the cursor only
- Destroy: ALL
ld c,65 | ;ASCII ‘A’
ld a,24 | ;sendCharToLCD
rst 18H
ld c,0DH | ;Carriage Return
ld a,24 | ;sendCharToLCD
rst 18H

sendStringToLCD #25 (19H)
Send a string of characters to the GLCD. Prints a string pointed by DE at the current cursor. It stops printing and returns when either a CR is printed or when the next byte is the same as what is in register C.
- Input: C = Character to stop printing string
DE = address of string to print
- Destroy: ALL
ld de,text | ;Text to display
ld c,0 | ;terminate on zero
ld a,25 | ;sendStringToLCD
rst 18H
text: .db “Hello TEC-1G!”,0

sendRegToLCD #26 (1AH)
Display a byte or register in ASCII on the GLCD at the current cursor
- Input: C = byte to convert and display
- Destroy: ALL
ld c,a | ;display register A
ld a,26 | ;sendRegToLCD
rst 18H
ld c,7BH | ;display ‘7B’
ld a,26 | ;sendRegToLCD
rst 18H
sendHLToLCD #27 (1BH)
Display the register HL in ASCII on the GLCD at the current cursor
- Input: HL = 2-byte register to convert and display
- Destroy: ALL
ld hl,0A6CH | ;display ‘0A6C’
ld a,27 | ;sendHLToLCD
rst 18H
setCursor #28 (1CH)
Set the Graphic cursor position for Terminal Emulation. Update is ignored if either X,Y input is out of bounds.
- Input: B = X position in pixels (0-127)
C = Y position in pixels (0-63)
- Destroy: A
ld bc,4020H | ;cursor at X=64, Y=32 (middle of screen)
ld a,28 | ;setCursor
rst 18H

getCursor #29 (1DH)
Get the current cursor position
- Input: none
- Output: B = X position in pixels (0-127) C = Y position in pixels (0-63)

displayCursor #30 (1EH)
Turn the cursor ON or OFF. Default is Cursor ON
- Input: C = 0, Turn cursor on, C=non zero, turn cursor off
- Destroy: ALL

GLCD Examples
Provided in the TEC-1G GitHub repository are three GLCD programs. The programs have already been converted to Intel Hex files and are ready to load onto the TEC. All programs start at address 2000H. Source code for all programs are provided and can be changed and studied.

The TEC-1G GitHub account is here: https://github.com/MarkJelic/TEC-1G and the GLCD examples are in the TEC-Deck/Graphical_LCD directory.

lcd_3d_demo
Draw 3D wireframe graphics and rotate them. This program requires keypad input to rotate the objects. Buttons 4,8 and C rotate the object in the 3-axis. Plus and Minus will zoom the object in and out. 0 will return to the main menu. Pressing GO will exit the program

lcd_mad_program
Draw Alfred E. Neuman's face. This program draws lines between two points and creates the face of the Mad Magazine mascot. It draws one line at a time, similar to how it would display on an Apple ][. But if the program is run at 2022H it will generate instantly. https://meatfighter.com/mad/

lcd_maze_gen
Create a maze. This program generates a maze using a recursive backtracking algorithm. Watch the maze slowly generate before your eyes.

Some easy-to-type examples have also been provided in the Quick Start Programs chapter below.


## Hard Drive Access

Mon3 has the ability to read and write to files from certain Hard Drives and Solid State cards with Add-On boards. There are two boards that will give access to these drives, The GPIO/SD board and the PATA board. The GPIO board connects a Micro SD card and uses the General Purpose IO port. The PATA board connects a PATA laptop hard drive or a Compact Flash card and uses the TEC Deck connector.


In terms of the particular medium used to store files, there are a few things to note:
- FAT32 (File Allocation Table) is the only file system Mon3 recognises. The drive must be formatted using FAT32 and be on the first MBR Partition.
- Mon3 looks at the Root (top level) directory for files. A maximum of 49 files can read from the drive.
- Only short name files are displayed. Short file names use up to 8 characters for the file name and 3 for the extension. IE: “INVADERS.HEX”. If a file has a longer name, the FAT32


system automatically creates a shortened version.

With FAT32, files can be seamlessly copied from your PC/MAC to the drive. A USB to drive reader is required, which can be easily found.

If both GPIO and PATA boards are connected to the TEC, Mon3 will prioritise the GPIO board then the PATA board. Details of the Add-on Boards can be found in the TEC-1G GitHub repository.

Mon3 can only Read or Write to existing files. There is no ability to create new files from the TEC to the drive. To transfer code from the TEC to the drive, first, use the EXPORT RAW DATA menu option to transfer the code via Serial to your PC/MAC. Then copy the binary from your PC/MAC to the drive via a USB to SD/PATA/CF adaptor.

## Access to the Drive

In the Main Menu, select DRIVE ACCESS. A menu will be displayed with three options. Catalog, Save Session and Load Session. These options also have shortcuts in Data Entry mode.

Catalog


Catalog will display a list of readable files in the root directory of the drive. Catalog can also be access by from Data Entry mode by pressing Fn-F. If Mon3 finds files on the drive, they will be displayed on the LCD screen.

Use Plus/Minus to select the file to load and GO to load the file. AD will exit back to the Menu. If the file has the extension *.HEX, it is assumed that this file is in Intel Hex format and it will automatically convert the file to binary prior to loading. Any other extension will ask for a Start Address as to where the file is to be loaded at.


See the Useful Links section below on how to load your drive with ready to run TEC-1G files.

Save / Load Session
The entire contents of RAM can be saved to a file and loaded back to the TEC. This is an equivalent to saving/restoring a session. It replaces any need to use Non-Volitile RAM. It can be used prior to powering down to save any unfinished work. Then be able to access the same machine state later on.

As Mon3 can’t create files, the session file must be created on your PC/MAC. The filename must be called “MYDATA.TEC” and be exactly 64 Kb in size. The file can be easily created using the following command line statements.

O/S | Command
MS Windows | >fsutil file createnew MYDATA.TEC 65536
MAC OSX | $dd if=/dev/zero of=MYDATA.TEC bs=65536 count=1

A File Not Found error will appear if Mon3 can’t find the MYDATA.TEC file on your drive.

Save Session will save normal RAM between 0000H-BFFFH and Expansion RAM if any between 8000H-BFFFH. Save Session can also be access in Data Entry mode by pressing Fn-6.

Load Session does the reverse of Save Session. It will ask to Confirm this task as it will overwrite all existing RAM data. Load Session can also be access in Data Entry mode by pressing Fn-7.

While the drive is being accessed, the LCD will display the current progress.


Error Messages
If any errors occur while accessing the drive, an error message will be displayed on the LCD and the code will exit after a key is pressed.

Error messages descriptions are below:

Message | Description
Disk Timeout | No Communication with PATA drive
Data Not Ready | Read data request failed
IDE ERR IO Bad | Data transfer error
Can’t read MBR | Couldn’t read sector 0 of drive
MBR Illegal | Malformed MBR record
BPB Read Fail | Bios Parameter Block of FAT32 not found
Byt/Sec != 512 | FAT32 Bytes per Sector is not 512
Root Dir Read | FAT lookup of sector failed
File Not Found | File selected not found in menu configuration
Bad Checksum | HEX file is corrupt
No SD Card | SD Card not found
OCR Read Fail | SD Addressing mode illegal
Invalid SDCard | SD Card can’t be used
CMD16 Failed | SD Block size can’t be set to 512
Addr. Too Big | Read Sector address greater then file size

## Drive Access API Calls

Special API calls have been created to help with opening, reading and writing to files within your own code. The details of these calls and their limitations are described below.

loadFromDisk #58 (3AH)
Catalog the files on the disk and display them on the LCD Display for loading. This is the same as selecting CATALOG from the main menu or Fn-F from data entry mode.
- Input: None
- Destroy: ALL
ld c,58 | ;loadFromDisk
rst 10H

openFile #59 (3BH)
Open a file for reading or writing. The routine will exit cleanly if success or an error will be displayed if file isn’t found. The filename is case sensitive and must match exactly. The file must already be existing on the drive.
- Input: HL = Pointer to zero terminated File name
- Destroy: ALL
ld hl,filename | ;address of file text
ld c,59 | ;openFile
rst 10H

filename: .db “TBASIC.HEX”,0

readSector #60 (3CH)
Load a sector from the opened file. Requires openFile to be called prior but only once. A sector, which is 512 bytes, will be loaded at address 0600H-07FFH. The input is the byte address in the file. The entire sector where that byte is will be returned. An error will display if the input byte is bigger than actual file size.
- Input: HLDE = address in bytes of block to read
- Destroy: ALL
ld hl,0001H | ;upper byte
ld de,2575H | ;lower byte
ld c,60 | ;readSector
rst 10H

This example will read the sector that contains the byte 12575H and place that sector in address 0600H-07FFH.

writeSector #61 (3DH)
Write a sector to an opened file. Requires a readSector to be called first. The sector will be saved back to the same position in the file from the readSector routine. To use this routine, firstly call the readSector routine. Data at address 0600H-07FFH can then be altered and a writeSector can be called to save the modifications back to the file.
- Input: None
- Destroy: ALL
ld hl,0001H | ;upper byte
ld de,2575H | ;lower byte
ld c,60 | ;readSector first
rst 10H
; | ** Modify data at 0600H-07FFH here
ld c,61 | ;writeSector
rst 10H

This example will read a sector first, make some modifications and then write it back to the file.

## Quick Start Programs

Who wants the TEC-1G to say Hello? Here are three ways TEC can do this. Only a summary of the programs has been provided, making the examples a good exercise for learning how they work. The programs utilise Mon3 API routines as discussed in the Advanced Programming chapter.

This routine is the shortest. It will
display the data at 4009 using RST
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

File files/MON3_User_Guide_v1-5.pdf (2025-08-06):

## User Guide


By Brian Chiha v1.5

Mon3 (Talking Electronics Computer Monitor version 3) is custom-built for the TEC-1G Single Board Z80 Computer. Mon3 is the heart of the TEC-1G. It brings the hardware to life. Consider it an Operating System that provides the ability to program the TEC. The monitor is jam-packed with features, designed for beginners who are just learning to code Z80 and rich enough for the advanced software developer.

## Table of Contents

The version of this document corresponds to the version of the monitor binary file. IE: Version 1.2 of this document is for file MON3-1G_BC23-12.bin. The 12 at the end of the file is the version number.

## Basic Operation

With the monitor loaded into the ROM socket and all the jumpers set correctly for the ROM used. Turn the TEC on. If all is working well, a welcome banner will be displayed on the LCD and a short tune will be heard.


## Cold Reset

When the TEC turns on after being powered down, a Cold Reset occurs. A Cold Reset signified with the display of the welcome banner and the short tune. A Cold Reset will configure the monitor for first-time use after powering it on. It will default monitor variables and configure the LCD for first use.

If the TEC isn’t responding normally or something “weird” is occurring, a manual Cold Reset can be performed. Programs loaded in RAM will be retained when a manual Cold Reset is done. To do a manual Cold Reset, while pressing and releasing the RESET key, hold the Fn key down. The distinctive LCD Banner and music tone will indicate that the Cold Reset was successful. A manual Cold Reset on the HexPad will still work if the Matrix Keyboard is in use.

## Warm Reset

A Warm Reset occurs when pressing and releasing the RESET key. A warm reset returns the TEC to its initial editing location on a Cold Reset. It's a quick way to get back to the start of a code block.

## Main Menu

A menu is provided on the LCD screen to help with navigating the inbuilt routines that the monitor comes with. A menu will appear on Cold Reset.

Navigating the menu should be intuitive. Press the Plus or Minus keys to scroll down and up. Press GO to run the selected routine. A right-facing Arrow indicates which menu item is currently selected. One thing that might not be obvious is how to exit the menu and move into Data Entry mode. This is achieved by pressing the AD key. Once this is known, it's hard to forget it. Menus can be nested up to 3 deep. Pressing the AD key will exit to the parent menu or Data Entry mode if at the main menu.


The current items on the menu are

Menu Text | Description
Intel HEX Load | Receive data in Intel Hex File format via the FTDI connector
Smart Block Copy | Move a block of code AND update all 2-byte addresses that are within the block
Block Backup | Move a block of code
Export Z80 Assembly | Display Z80 Assembly to a Serial terminal via the FTDI connector
Export Raw Data | Send binary data via the FTDI connector
Export Hex Dump | Display a 16-byte per line HEX dump to a Serial terminal via the FTDI connector
Import Binary File | Receive data in binary format via the FTDI

| connector
Tiny Basic | Run Tiny Basic on a Serial terminal or GLCD
Music Routine | Play musical notes at a given address
Settings | Update monitor settings
Credit | Display the people who made the TEC-1G

## Intel HEX Load

Intel created a text file format that contains information on loading bytes into memory. When this routine is run, the TEC seven segments will go blank and wait for a file to be received. This is done via the FTDI connector and serial terminal. When data is transmitted, the rightmost segment will illuminate in a pattern. This indicates data is being read. Once the file has fully loaded, the letters “PASS” will display on the seven segments. This means that the load was successful. Press any key to exit. If the segments display the word “FAIL”, then there is something wrong with the file or your serial connection.

## Smart Block Copy

This very clever routine shifts a program from one spot in memory to another and changes all absolute jumps and calls. Memory pointers are also altered if the memory pointers are within the start and end address of the program being relocated. Any reference to a location outside the start and end range is not altered.

The block copy treats Data bytes as instructions and might change data bytes as well. IE: .db C3, 23, 01 could be seen as a JP 0123 instruction.

When this routine is run, it will ask for a START, END and DESTINATION address. Type in the 16-bit address via the HEX PAD and use the Plus or Minus keys to change the selected parameter. Press GO to run the routine.

Here is an example of copying 4000H-4009H to location 2000H

Original | After Copy
4000 11 09 40 LD DE,4009 4003 E7 RST 20 4004 FE 13 CP 13 4006 C2 00 40 JP NZ,4000 4009 C9 RET | 2000 11 09 20 LD DE,2009 2003 E7 RST 20 2004 FE 13 CP 13 2006 C2 00 20 JP NZ,2000 2009 C9 RET

## Block Backup

This routine simply copies a data block from one address location to another. No bytes are altered when the copy is performed. This routine is also useful to copy data reference tables like music data for the music routine.

When this routine is run, it will ask for a START, END and DESTINATION address. Type in the 16-bit address via the HEX PAD and use the Plus or Minus keys to change the selected parameter. Press GO to run the routine.

Here is an example of copying 4000H-4009H to location 2000H

Original | After Copy
4000 11 09 40 LD DE,4009 4003 E7 RST 20 4004 FE 13 CP 13 4006 C2 00 40 JP NZ,4000 4009 C9 RET | 2000 11 09 40 LD DE,4009 2003 E7 RST 20 2004 FE 13 CP 13 2006 C2 00 40 JP NZ,4000 2009 C9 RET

## Export Z80 Assembly

If the TEC is connected to a serial terminal via an FTDI to USB adaptor, code that is stored or written on the TEC can be disassembled and sent to the terminal. This is a great way to view the code that is on the TEC in a readable format and could be passed into a Z80 compiler on a PC.

When this routine is run, it will ask for a START and END address. Type in the 16-bit address via the HEX PAD and use the Plus or Minus keys to change the selected parameter. Press GO to run the routine.

Here is an example of its output.
4000 3E 3F | LD A,3F
4002 D3 01 | OUT (02),A
4004 3E 04 | LD A,04
4006 D3 02 | OUT (02),A
4008 CF | RST 08
4009 C9 | RET

## Export Raw Data

This routine will send binary data from the TEC to a serial connection. It’s a way of saving the code written on the TEC to a PC. As binary data is being sent, the data can only be properly viewed through a HEX file viewer or HEX dump routine.

When this routine is run, it will ask for a START and END address. Type in the 16-bit address via the HEX PAD and use the Plus or Minus keys to change the selected parameter. Press GO to run the routine.

## Export Hex Dump

This routine will display binary data in a readable format to a serial terminal connected via an FTDI to USB adaptor. It will display up to 16 bytes per line.

When this routine is run, it will ask for a START and END address. Type in the 16-bit address via the HEX PAD and use the Plus or Minus keys to change the selected parameter. Press GO to run the routine.

Here is an example of its output.

C100: 31 80 08 21 00 40 CD FC C5 AF D3 05 D3 06 DB 03 C110: 47 E6 10 C2 00 80 3A 9F 08 E6 04 0E 01 B1 D3 FF C120: 32 9D 08 78 E6 02 32 9E 08 3A 9D 08 E6 01 28 0B C130: 21 00 C0 11 00 00 01 00 01 ED B0 21 00 40 22 86 C140: 08 22 A0 08 DB 03 0F 38 06 DB 00 E6 20 18 08 CD

## Import Binary File

This routine will upload a binary file from a PC onto the TEC via an FTDI to USB adaptor. This is the opposite of the Export Raw Data routine and will load binary data to a given address on the TEC.

When this routine is executed, it will ask for a START and END address. This address range must match the size of the binary file being sent. Type in the 16-bit address via the HEX PAD and use the Plus or Minus keys to change the selected parameter. Press GO to run the routine. The TEC will wait for data to be received and will end when END-START+1 bytes are received.

## Tiny Basic

Tiny Basic is an easy-to-use BASIC programming language. Tiny Basic by default uses the FTDI to USB serial terminal connection. If a GLCD Add-On board is installed, the GLCD can be used as a terminal in conjunction with a Matrix Keyboard. Go to Settings -> Toggle GLCD Term to enable. Some extra commands have been implemented to interact with the TEC-1G hardware. Tiny Basic will use RAM address 0900H-3FFFH

Functionality has been added to the Mon3 version to make it more useful for the TEC-1G. Here is a list of additions to the language.
Syntax | Description
PEEK(n) | Return the contents of memory at location `n`. Value is in decimal
OUT p,n | Output `n` to Port `p` on the TEC
XOFF, XON | Turn Serial terminal output off and on. Used if outputting to the Seven Segments
PRINT extensions | Placed in `PRINT` statements and preceding a number: IE: PRINT &255,%12,$65 outputs ‘FF . A’ ● `&` - Output number as Hexadecimal. Works for all numbers. ● `%` - Output number as an ASCII character (Print `.` for non printable character) ● `$` - Output number as an ASCII character (Print all characters)

Ctrl-D Exits back to monitor and Ctrl-Z clears the whole line

Here are some Tiny Basic Example programs Display the first 22 Fibonacci Numbers
5 REM ** FIBONACCI SEQUENCE **
10 PRINT "FIBONACCI SEQUENCE"
20 FOR I=1 TO 22
30 GOSUB 70
40 PRINT "F",I,F
50 NEXT I
60 STOP
70 LET A=0; LET B=1
80 FOR J=1 TO I
90 LET T=A+B; LET A=B; LET B=T 100 NEXT J
110 LET F=A
120 RETURN
Display the Factors of a given number 5 REM ** FACTORS OF N **
10 INPUT "GIVE ME A NUMBER" I 20 LET C=1
30 PRINT "FACTORS OF ",#3,I,":" 40 IF I/C*C=I PRINT C
50 C=C+1
60 IF C<=I GOTO 40
70 GOTO 10
Output the numbers 0 to 9 on the TEC-1G Seven Segment Display 5 REM ** SEGMENT OUTPUT DEMO **
10 @(0)=235;@(1)=40;@(2)=205;@(3)=173;@(4)=46
20 @(5)=167;@(6)=231;@(7)=41;@(8)=239;@(9)=175
30 XOFF
40 OUT 1,1
50 FOR I=0 TO 9
60 OUT 2,@(I)
70 FOR J=1 TO 1000;NEXT J
80 NEXT I
90 XON
Print All ASCII Characters
10 REM ** PRINT ASCII CHARACTERS ** 20 FOR I=32 TO 255
30 PRINT #1,&I+32,$32,$I+32,$32, 40 IF (I+1)/10*10=(I+1) PRINT
50 NEXT I

## Music Routine

Use this routine to play some notes to the TEC speaker. It is based on John Hardy’s Mon1 routine adjusted for a 4 Mhz clock speed. The routine uses similar input codes making it suitable for existing tunes to be used.

When this routine is executed, it will ask for a START address of the music data—type in the 16-bit address via the HEX PAD. Press GO to run the routine.

Two octaves are playable. Here is a reference to the note code and its musical note. A Pause is represented by 00 and any other note code that isn’t listed will exit the routine.
Note | Code | Note | Code | Note | Code | Note | Code
G | 01 | C# | 07 | G | 0D | C# | 13
G# | 02 | D | 08 | G# | 0E | D | 14
A | 03 | D# | 09 | A | 0F | D# | 15
A# | 04 | E | 0A | A# | 10 | E | 16
B | 05 | F | 0B | B | 11 | F | 17
C | 06 | F# | 0C | C | 12 | F# | 18

Here are some examples tunes that can be typed in a played
Bealach
06, 06, 0A, 0D, 06, 0D, 0A, 0D, 12, 16, 14, 12, 0F, 11, 12, 0F 0D, 0D, 0D, 0A, 12, 0F, 0D, 0A, 08, 06, 08, 0A, 0F, 0A, 0D, 0F 06, 06, 0A, 0D, 06, 0D, 0A, 0D, 12, 16, 14, 12, 0F, 11, 12, 0F 0D, 0D, 0D, 0A, 12, 0F, 0D, 0A, 08, 06, 08, 0A, 06, 12, 00, 1F Angels On High
0F, 0F, 0F, 0F, 0F, 0F, 12, 12, 12, 12, 12, 10, 0F, 0F, 0F, 0F 0F, 0F, 0D, 0D, 0F, 0F, 12, 12, 0F, 0F, 0F, 0D, 0B, 0B, 0B, 0B 0F, 0F, 0F, 0F, 0F, 0F, 12, 12, 12, 12, 12, 10, 0F, 0F, 0F, 0F 0F, 0F, 0D, 0D, 0F, 0F, 12, 12, 0F, 0F, 0F, 0D, 0B, 0B, 0B, 0B 12, 12, 12, 12, 14, 12, 10, 0F, 10, 10, 10, 10, 12, 10, 0F, 0D 0F, 0F, 0F, 0F, 10, 0F, 0D, 0B, 0D, 0D, 0D, 06, 06, 06, 06, 06 0B, 0B, 0D, 0D, 0F, 0F, 10, 10, 0F, 0F, 0F, 0F, 0D, 0D, 00, 00 00, 12, 12, 12, 12, 14, 12, 10, 0F, 10, 10, 10, 10, 12, 10, 0F 0D, 0F, 0F, 0F, 0F, 10, 0F, 0D, 0B, 0D, 0D, 0D, 06, 06, 06, 06 06, 0B, 0B, 0D, 0D, 0F, 0F, 10, 10, 0F, 0F, 0F, 0F, 0D, 0D, 0D 0D, 0B, 0B, 0B, 0B, 0B, 0B, 0B, 0B, 00, 00, 00, 00, 00, 00, 1F

## Settings

The settings allow the user to configure the monitor. Turning the power off from the TEC will return these settings to their default state. Some settings will be retained if an RTC Add-on board is connected with battery backup.

- Toggle Key Beep - Turn the keypress ‘beep’ indication on or off.
- Toggle Address Inc - Turn the automatic address increase after a byte has been keyed on or off.
- Toggle GLCD Term - Use the GLCD (if fitted) as a terminal
- Configure RTC - Set Time/Date of RTC (if RTC Add-on is connected).
- Reset RTC & PRAM - Reset RTC for initial use and initialise NVRAM.
- Toggle EXPAND - software controlled the expansion socket to toggle between lower and upper 16Kb memory for a 32Kb ROM/RAM chip.

## Credits

Display the people who developed and tested the TEC-1G
- Mark Jelic - Designer of the TEC-1G
- Brian Chiha - Mon3 Programmer
- Craig Hart - TECnical Expert
- Ian McLean - Tester and QA
- James Elphick - Tester and QA
- John Hardy & Ken Stone - The original designers


## Memory Map

The table below outlines how the full 64Kb of address space is allocated on the TEC-1G.

Address | Contents | Type
0000H-00FFH | Reserved for Z80 instructions | RAM
0100H-07FFH | Free RAM | RAM
0800H-087FH | Reserved for Hardware Stack | RAM
0880H-0FFFH | Reserved for Monitor RAM | RAM
1000H-3FFFH | Free RAM | RAM
4000H-7FFFH | Free RAM (Protected) | RAM
8000H-BFFFH | Expansion Socket | RAM/ROM
C000H-FFFFH | Monitor ROM | ROM

Some things to be considered are:
- Any RAM location can be updated, but it is highly recommended not to update Monitor Reserved RAM locations. This can/will cause undesirable effects on the running of the TEC. A Cold Reset will restore the TEC to its default running state (hopefully).
- The address range between 4000H-7FFFH is a special area that can be made READ ONLY. This is called a Protected area. Protect mode can be switched on using the configuration 3-DIP switch. If protect is enabled and code is being executed. No RAM update can be done in this range. This feature is designed to protect keyed-in code from being inadvertently erased by a rogue routine.
- The Expansion Socket on the TEC can have a 32Kb ROM or RAM inserted. Only 16kb can be accessed at one time. To switch between high and low memory use the Expand switch on the configuration 3-DIP switch. The switch can also be overridden in software by toggling the Expand flag in the Settings menu or pressing Fn-E.
- If the monitor ROM is a legacy monitor, IE: Mon1, Mon2, JMon or BMon, The address range 0000H-07FFH will be READ ONLY and will emulate the same addressing that is used for that particular ROM. Shadow mode will be active by default and will be indicated by an illuminated LED segment on the system latch BAR component.

## Data Entry Mode

Data Entry Mode allows the user to enter Z80 Op Codes directly into the TEC. To access Data Entry Mode from the Main Menu simply press the AD key. In this mode, the 4 left seven-segment displays will show the current editing address and the 2 right segments will display the byte at that address.


Address | Data

The decimal place LED on the segments indicates which part, Address or Data is currently enabled for direct updates. In the picture above, the dots are on the Data segments.

The initial starting address is 4000H. This address was chosen as it's within the Protect RAM area.

## Basic Operation

To update a byte at an address, simply use the 0-F keys on the keypad. After the byte has been entered, by default when the next byte is keyed, the current editing address will automatically move to the next address location. This saves the user from pressing the Plus key after each byte is added. This option can be switched off in the Settings menu.

To navigate to another address, press the Plus or Minus key. Or press the AD key. The decimal place dots will move to the address segments indicating that the address field is updatable. Key in a new 16-bit address by using the 0-F keys. Press the AD key to move back to data updating mode.

And finally, to execute code, navigate to the address where the code starts and press the GO key. Protect mode will be honoured if switched on. If the code ends with a RET instruction (C9), execution will cleanly exit back to the monitor. The LCD screen will display the code start address while running.

One thing to note is that while data is being entered, the decimal place LED on the data segments will change from displaying two lights to one. The one light will indicate which Nibble (half byte) has been entered. This will assist in knowing if the whole byte has been entered or not.

If a mistake is made during data entry and the byte is to be re-entered. To stop the address from automatically incrementing, press the AD key twice. This will reset the Nibble counter and allow a new byte to be entered.

If any key is held down, after a short period, the key will automatically repeat. This is mostly useful while holding down the Plus or Minus key to quickly move to a new address. But can also be used to populate memory with 00 or FF or anything else.

## LCD Screen

In Data Entry Mode the LCD Screen will display 12 bytes of data. 4 bytes before the current editing location and 8 bytes from the current editing location. These bytes are displayed in groups of 4 (3 lines). A right arrow indicates the byte at the current editing location.

Displayed on the right side of the screen is the current edit mode, da=Data, ad=Address, the current byte in LCD ASCII and the Nibble Counter. The picture below is showing: The current address is 4000, Data mode, “>” = 3E in ASCII and 0 nibble count.

On the 4th line of the LCD, the Z80 Assembly of the current OP Code(s) is shown. This can be useful to see what instruction is currently being keyed.

By displaying a range of bytes on the LCD, the user can check if the correct bytes have been entered without individually moving to each address.


## Function Keys

Various extra options can be selected via the Function Key. To use these functions, hold the Fn key down and press one of the 0-F keys.

The routines attached to the Function Key are:
- Fn-AD - Display the Main Menu
- Fn-0 - Save Current Address. Press 1,2 or 3 to save the current editing address in RAM to quickly jump to this location later. Three addresses can be saved. This is useful if code is in a location other than 4000H and the Reset button has been pressed. Press AD to exit the routine. The initial default address is 4000H.


- Fn-1,2,3 - Quick jump to Address. This will move the monitor's current editing location to the saved address set by Fn-0 above.
- Fn-4 - Intel Hex Load. This is a shortcut to the Main Menu routine.
- Fn-5 - Toggle GLCD Term. Use the GLCD as a terminal.
- Fn-8 - Fill with NOP’s Fill a selected area of memory with NOP instruction 00H. Provide a from and to address and confirm by pressing ‘C‘.
- Fn-A - Restore from Backup. This is the reverse of Fn-B routine and defaults the To/From/Dest addresses to copy back from backup. Values can still be modified if necessary.
- Fn-B - Block Backup. This is a shortcut to the Main Menu routine.
- Fn-C - Smart Block Copy. This is a shortcut to the Main Menu routine.

- Fn-D - Switch between Data Entry View and Disassembly View. Disassembly View displays the next 4 Assembly instructions. To move through the instructions press the Plus or Minus keys. Data entry can still be done in this mode if desired.


- Fn-E - Toggle the Expansion Socket Expand flag. This will switch between the upper and lower memory of the 32Kb ROM/RAM in the expansion socket.
- Fn-Plus - Insert an NOP instruction at the current editing location AND move all bytes up to max RAM by one address upwards. It will also do a Smart Block Copy to all moved bytes. This routine can add a Breakpoint (F7) or missing opcodes to an existing program.
- Fn-Minus - Delete a byte from the current editing location AND move all bytes down by one address. It will also do a Smart Block Copy to all moved bytes.
- Fn-Reset - Perform a Cold Reset. This will reset the TEC to its default state.

## Matrix Keyboard

Mon3 will work with the TEC QWERTY or Mechanical Matrix Keyboard Add-on. The Keyboard is connected to the Keyboard Socket on the lower left of the PCB. How your Keyboard PCB is designed might affect which pins can be connected. Please view the TEC-1G Schematic for information on pin configuration.


To activate the Keyboard, The Matrix switch on the 3-DIP switch is to be turned on. This activates the Matrix Keyboard and disables the onboard Hex Keypad (except Reset). Mon3 only maps keys present on the TEC-1G to the Matrix Keyboard.

The Keyboard map to Hex Keypad is as follows:
- AD - Esc
- Plus - Right Arrow
- 0-F, Fn - 0-F, Fn keys
- GO - Enter
- Minus - Left Arrow
- Reset - Reset key if connected The full range of keys can be accessed and converted when developing programs via the matrixScan and matrixToASCII API routines.

## Debugging Programs

Breakpoints can be inserted within a program which can help with viewing the state of the CPU registers. To break the execution of your code, insert a RST 30H or F7 at the current address where the break should occur.

An easy way to insert a byte into an existing program is to press Fn-Plus. This will insert a NOP instruction at the current address. Then change this byte to F7.

When the execution of code is interrupted with a breakpoint, the TEC will pause and display register information on the LCD screen.


The contents of the Z80 CPU registers AF, HL, BC, DE, IX, IY, the Program Counter and Stack Pointer are displayed. CPU Flags are also displayed. Flags that are set are in Capitals. To continue code execution press the GO key and to quit execution and return to the Monitor press the AD key. Finally, to remove an inserted Breakpoint press Fn-Minus at the address where the Breakpoint is. This will remove the breakpoint and adjust the code to its original state. Note: Breakpoints will be ignored if a connection is made between the + and the D5 pins on the G.IMP header. Warning: Do not connect the + to the - pin on the G.IMP header!!! This will short out the TEC!

## Terminal Monitor

TMON has been removed from Mon3 as of v1.5 but it can be loaded as a stand alone program. See the GitHub for source files.
The Terminal Monitor (TMON) is a complete serial port-based monitor for the TEG-1G, designed for users who prefer to interact with the TEC-1G via a terminal.

## Starting up TMON

Connect a serial terminal to the TEC-1G via the FTDI to USB connector. Then, select Terminal Monitor from the main menu by pressing GO and look at the serial terminal.

TMON for TEC-1G Version 1.0
MON-3 Version: 2023.11
RAM Found between 0000h and 3FFFh - 16384 bytes 1000 >
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

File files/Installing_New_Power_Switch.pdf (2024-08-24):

## Fitting the New Power Switch

1. If you are building up a new TEC-1G kit, skip ahead to Step 3.
2. If your TEC-1G already has the old 2 pole power switch, then this needs to be desoldered carefully, leaving the 6 holes clean and clear of old solder. You also need to remove the 100nf smoothing capacitor labelled C2, just above the 7805 regulator. Lastly, the diode marked D0 (just above the big 1000uf capacitor) must be flipped and connected to a new location. See Step 8 for details, but for now, just desolder the CATHODE (right side of the diode).
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

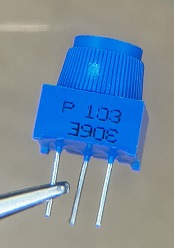
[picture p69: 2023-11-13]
Documentation/Assembly/pictures/resistor-v_103.jpg

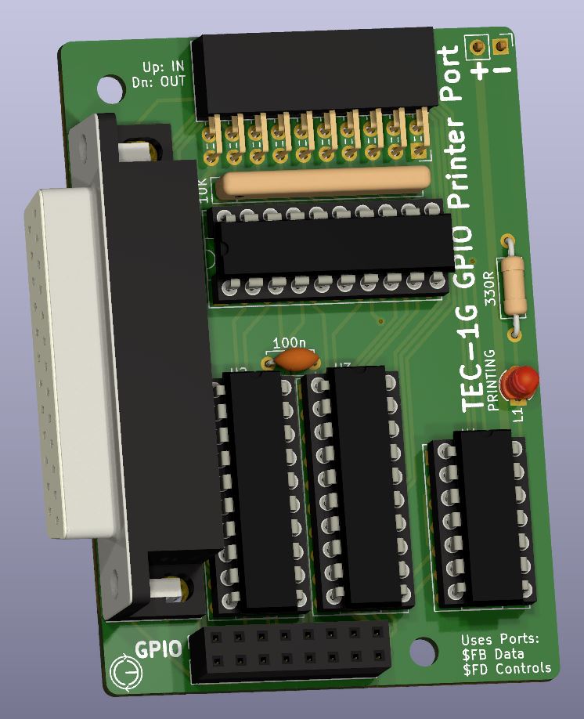
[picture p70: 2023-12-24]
GPIO/Printer/pictures/TEC-1G_GPIO_Printer-Render.jpg

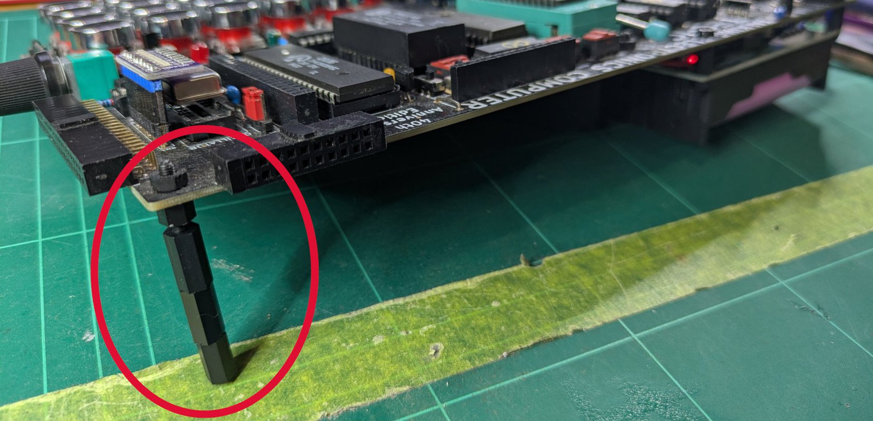
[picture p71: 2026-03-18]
Documentation/Assembly/pictures/UPS_SpacerStand.jpg

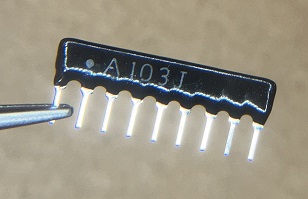
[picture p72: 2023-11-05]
Documentation/Assembly/pictures/resistor-n_103.jpg

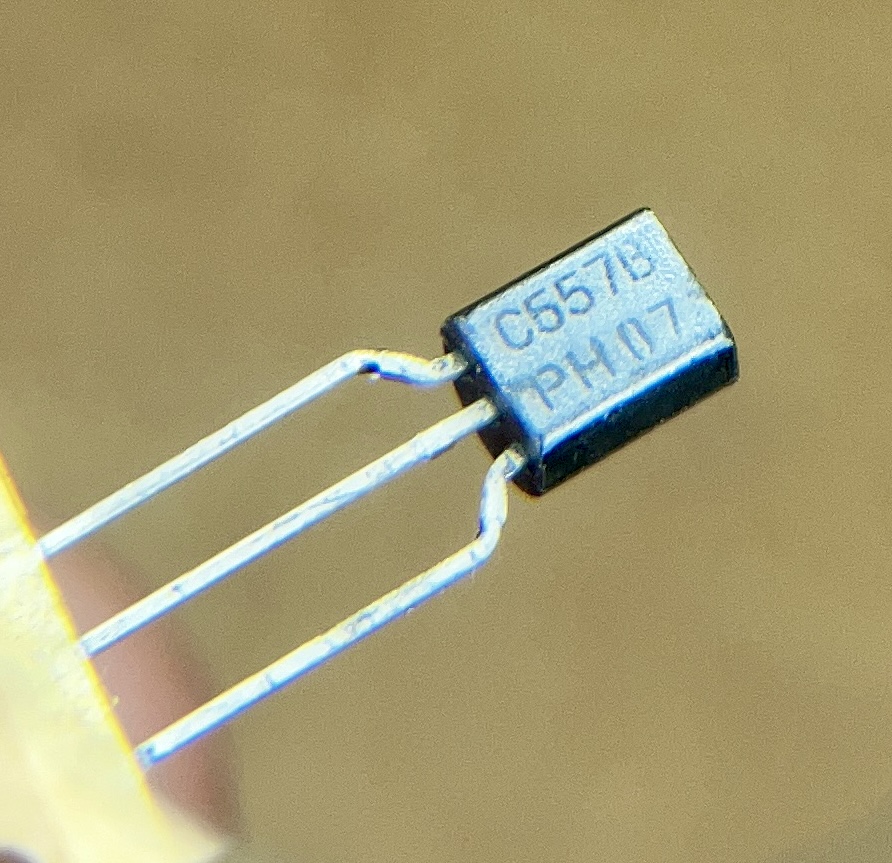
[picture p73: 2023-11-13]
Documentation/Assembly/pictures/tranny_557.jpg

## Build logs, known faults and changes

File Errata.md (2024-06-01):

# Errata

## TEC-1G Full Kit - Z80Bus Headers
2/Jun/2024: We have had a rethink on the right-most Z80Bus connector, found on the right edge of the PCB. I used to supply a right-angled version of that connector, allowing you to plug in directly any Z80Bus cards and have them parallel to the main PCB... Which is fine if you keep the TEC-1G flat on a table. But with the advent of cases being 3D printed to elevate and ange the PCB to face you, having a Z80Bus card floating out to the right, unsupported, was not a good idea. Hence, we changed it to a Vertical style of IDC connector. This still allows you to plug in a Z80Bus card directly, without the strain of gravity on the pins. Also, if you are using an X4 Board, then you can easily use an IDC cable to connect the two PCBs, and have the X4 lay flat on the table.

Also, the Z80Bus connector set next to the Z80 does not need to be an IDC socket as such, but the outer edge one *does*, to ensure firm connections of cards or cables. The inner one is only used for TEC Deck cards which use simple pin headers. Hence, please install the 40 pin headers supplied in the kit, as pictured below.

The silkscreen on the board will be updated in future print runs of the PCB.

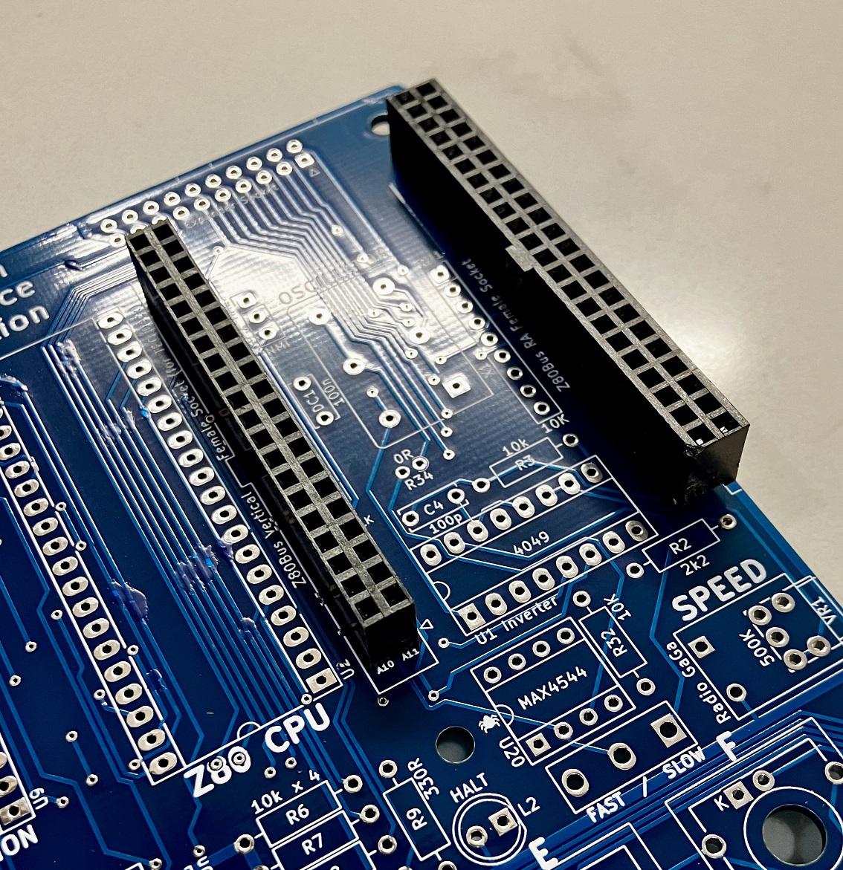
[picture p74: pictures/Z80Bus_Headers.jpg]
Z80Bus Headers


## TEC-1G Full Kit - FTDI Module
5/May/2024: The FTDI Module that provides serial via USB connection to your personal computer, is able to be used in both 3.3v and 5v systems with just a simple change of jumper settings on the module. It has come to light that these are by default jumpered to 3.3v and if installed on the TEC-1G in 3.3v mode, communications will be garbled and could damege the FTDI module. Please change those jumpers over to the 5v option before attaching it to the TEC-1G.

I recommend you hard-solder the module into place by first desoldering the installed RA pins, then soldering a new set of straight through pins on the underside, then attaching it to the TEC-1G main board. I also recommend hard-coupling the 5v option with little jumper wires. See the photo below for clarity. You should also cut off the 6 pins that allow programming of the FTDI module, to ensure clearance from any GPIO board installed above it.
FTDI_Module-Installed

## (1) Anniversary (Blue, Purple and Black) & Open Source (v1.01 Green) Editions
1/Nov/2023: Unfortunately a mistaken connection in the schematic (from v1.09 to v1.12) has made its way through to the PCBs which will stop the LCD from being operable. This was found by Tony Leff which I appreciate him finding it so quickly.

It would have been a relatively easy fix... But the +5v flood fill on the front of the PCB makes it more tricky and it is CRITICAL that the fix is done in the following order.

1. U6 Pin 8, front of board: Cut 3 traces as circled
2. LCD pin 6, front of board: Cut 2 traces as circled
3. LCD pin 6, back of board: Cut 1 trace as circled
NOTE: For Open Source (v1.01 Green) Editions, these traces will have been cut for you before being shipped out.)

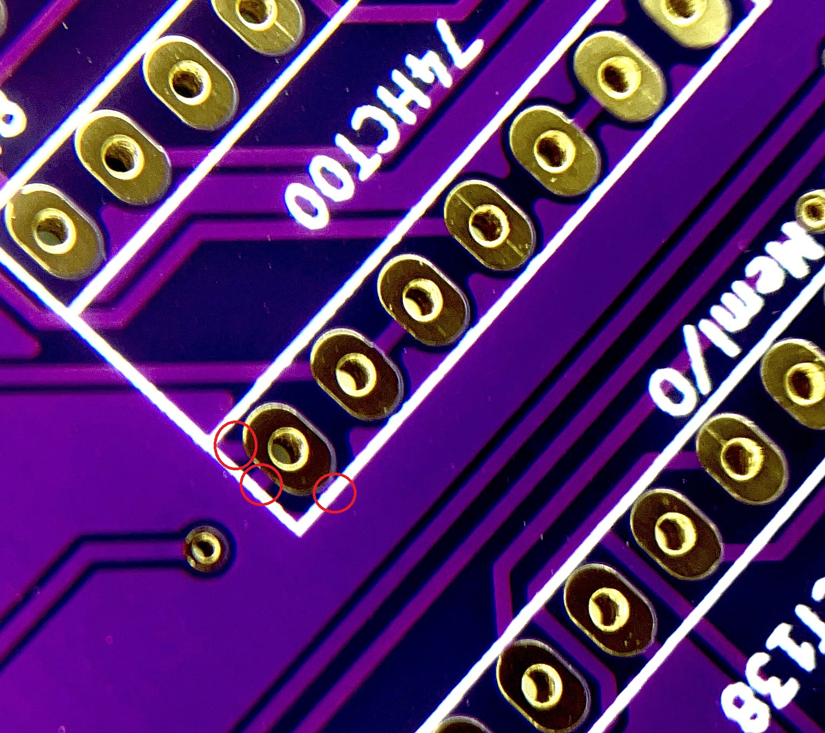
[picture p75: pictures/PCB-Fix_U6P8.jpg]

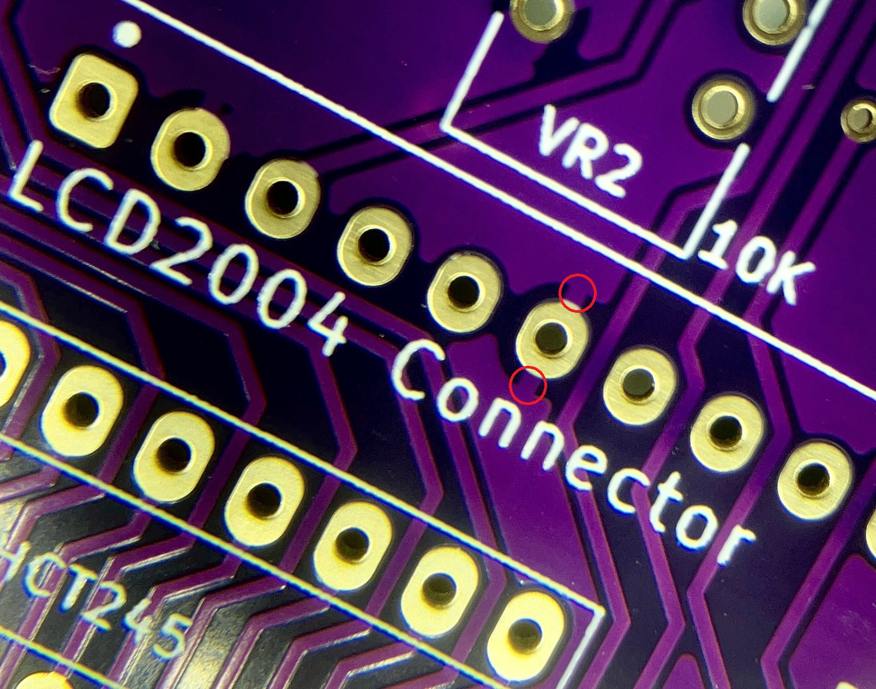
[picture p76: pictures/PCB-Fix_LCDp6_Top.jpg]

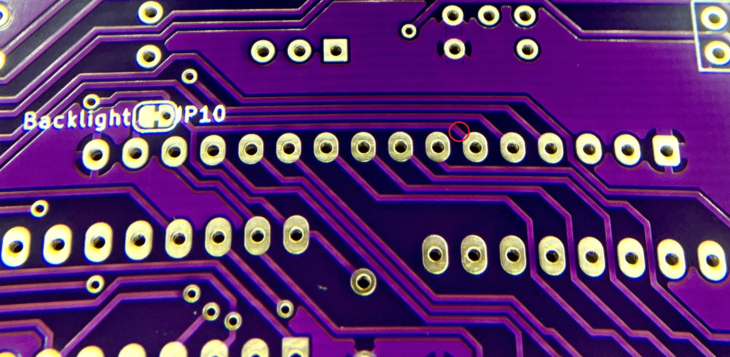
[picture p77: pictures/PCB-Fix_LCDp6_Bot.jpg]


4. Test there are NO connections from U6pin8 and LCDpin6 to +5v
5. Assemble TEC-1G as normal
6. After socket is in U6 and header is in LCD, solder a longer wire (shown in BLUE) between Pin 8 of U6 NAND and Pin 6 of the LCD connector.
NOTE: As of 15/Dec/2023, a length of Kynar wire is supplied with all Open Source (v1.01 Green) PCBs.

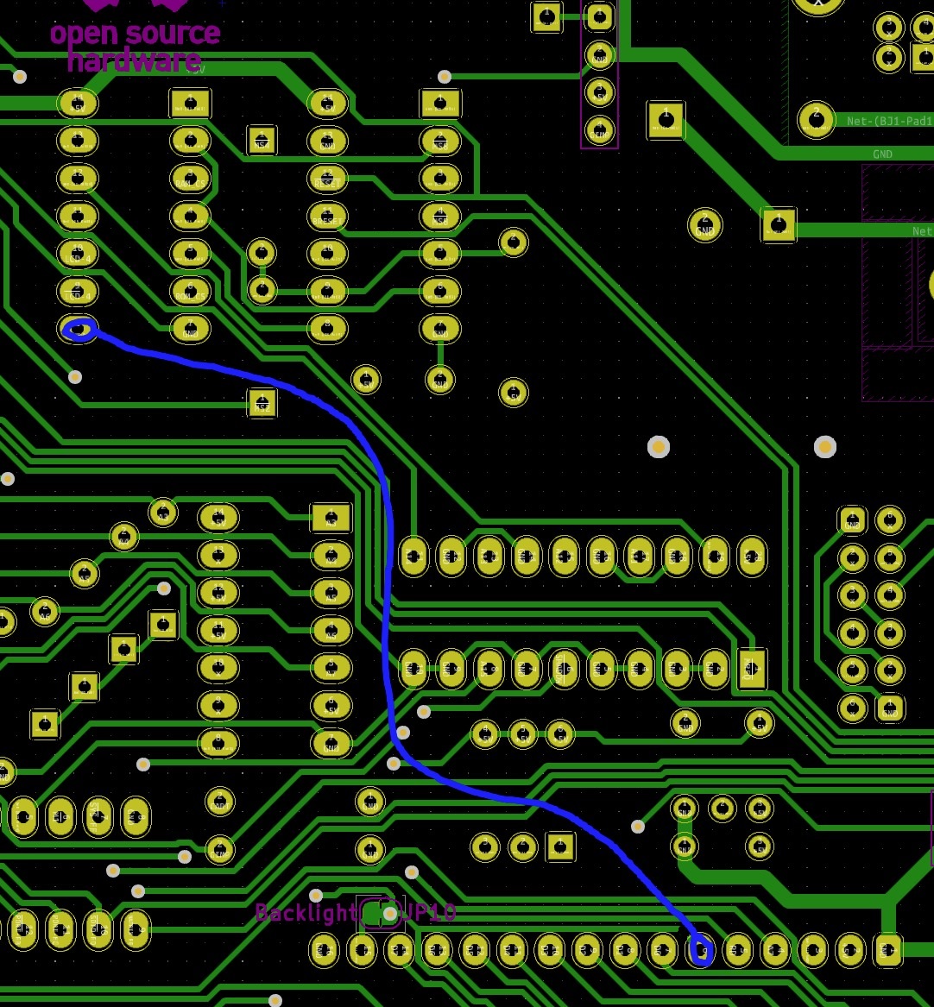
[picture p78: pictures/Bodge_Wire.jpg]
TEC-1G Errata 1 - LCD Enable

<br>
<br>
<br>
## (2) Anniversary (Blue, Purple and Black) & Open Source (v1.01 Green) Editions
2/Nov/2023: The silkscreen at the top left identifying the Probe location has the polarity of the voltages reversed.
GND should be to the right, and +5V is to the left, closer to the USB connector.
Please use a marker to correct this potentially component damaging error.

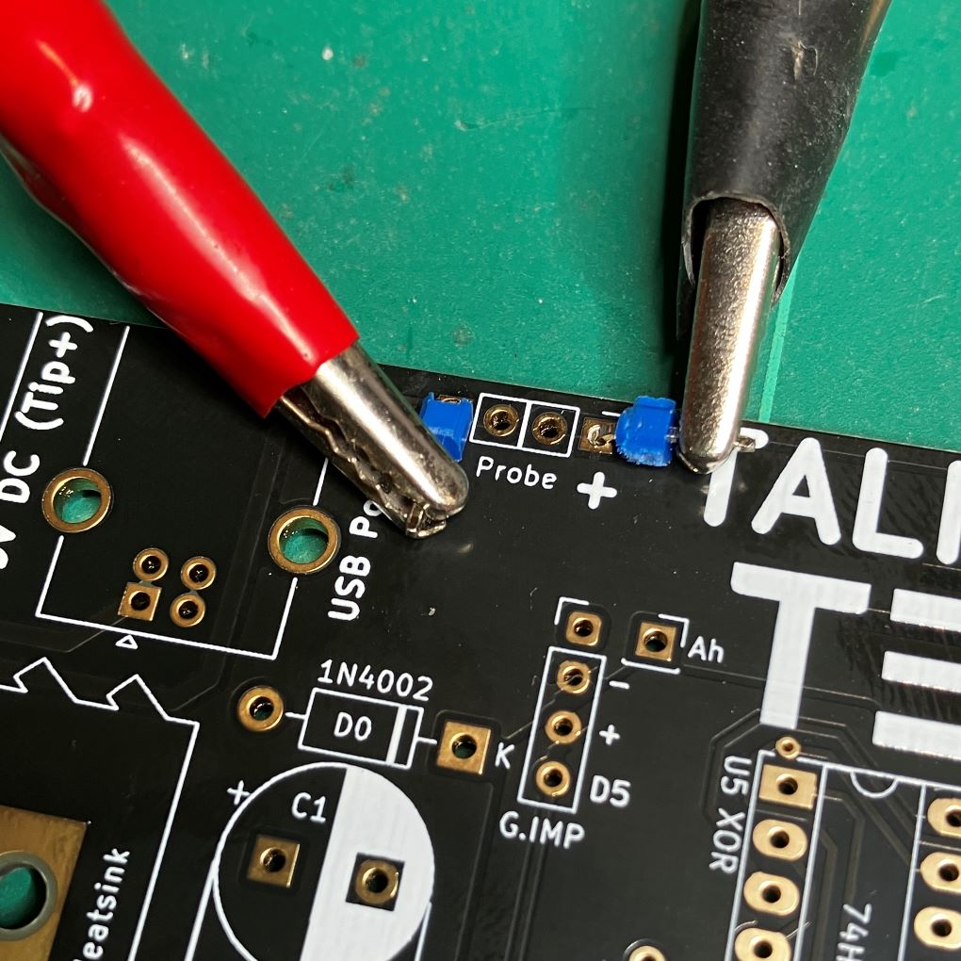
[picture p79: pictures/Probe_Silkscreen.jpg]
TEC-1G Errata 2 - Probe Polarity

<br>
<br>
<br>
## (3) Special Edition (Black) Only
15/Dec/2023: The silkscreen for the <b>bottom</b> Disco LED is reveresed from the correct polarity.
It should read, from top to bottom, R K G B

This means you simply flip the LED around before inserting and soldering it. The cathode (long pin) should be the second pin from the top.

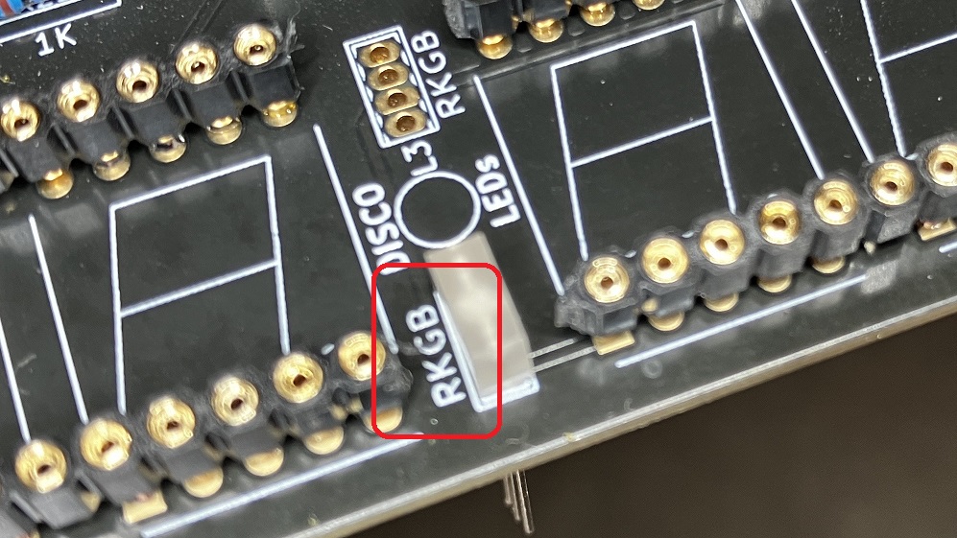
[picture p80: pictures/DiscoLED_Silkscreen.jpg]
TEC-1G Errata 3 - DiscoLED


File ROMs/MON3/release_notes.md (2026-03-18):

# Release Notes

### V1.6
File MON3-1G-BC25-16.bin

- **Feature**
  - Drive Access via the PATA or SD GPIO Add-On Board.  Allows the loading of files from disk to TEC.
  - Save and Restore session feature to save all RAM to disk and load back.
  - Add `loadFromDisk`, `openFile`, `readSector` and `writeSector` drive access API routines.
  - Add GLCD terminal `autoLF`, `underline`, `plotAlways` API routines for character printing.
  - Baud rate is selectable via the Settings menu. Up to 14400 baud rate can be selected.
  - RTC PRAM now includes the saving of Baud Rate, Toggle Key Beep and Toggle Address Increment.
  - Add `RGBScan` API to assist in multiplexing the RGB 8x8 LED Matrix Add-On Board.
- **Bug Fix**
  - Improved GLCD routines to display text faster via `plotAlways` flag.
  - Fixed GLCD inverse character and cursor movement.

### V1.5
File MON3-1G_BC24-15.bin

- **Feature**
  - Upgraded Graphical LCD routines to include `drawGraphic` and Terminal Emulation routines.
  - Display "Running at: nnnn" when `GO` is pressed.  nnnn is the Address where code starts executing.
  - ~~Display welcome banner on Graphical LCD screen on Hard Reset.~~
  - Add `toggleCaps` from API for matrix keyboard.  Sorry, removed at last release.
  - `parseMatrixScan` API called added.  Accepts input from the matrix keyboard and returns equivalent ASCII.  Also handles key bounce, key repeat and Caps lock.
  - Add `LCDConfirm` API call.  Ask user to press `C` to continue.  Usually for serious memory updates.
  - Add `setGLCDTerm` and `getGLCDTerm` API call.  Check and set output to GLCD Terminal.
  - Removed TMON (Terminal Monitor) from the core monitor code. :(
  - Add `Fn-A` Restore from Backup.  Reverse of `Fn-B`
  - Add `Fn-8` Fill a selected portion of memory with NOPs
  - Add `Toggle GLCD Term` option in settings to make the GLCD act as a serial terminal.  This can also but switched on/off with `Fn-5`
  - Tiny Basic will now output to the GLCD and input from the Matrix Keyboard if GLCD is set up as a terminal.
- **Bug Fix**
  - Control Keys now are accepted and returned on Matrix Keyboard using the `matrixScanASCII` API call.  IE: Ctrl-C will return `03H`.
  - Tiny Basic had issues with negating zero.
  - Tiny Basic will display all 256 ASCII characters using PRINT $n.
  - Reset LCD prior to hard reboot check.  This helps when using FRAM.
  - `Reset RTC & PRAM` also resets the Date and Time which puts it in a proper state to be recognised.

### V1.4
File MON3-1G_BC24-14.bin

- **Feature**
  - Real Time Clock Add-On Board Integration.  If RTC Add-On Board is connected to the GPIO socket, the RTC will be automatically detected.  Quick Jump Addresses and From/To/Destination range addresses will be saved to Non Volatile RAM (PRAM).  These values will be retained when the TEC is powered off using the battery backup on the Add-On Board.
  - RTC Configuration added to Setting Menu.  Set the Time/Date and View PRAM data.
  - RTC API routines added.
  - Data Entry Mode now displays 3 lines of 4 bytes on the LCD and three new monitor states, Data or Address mode, Nibbles entered and the current bytes ASCII value.
  - Add `stringToSerial` API routine to send multiple characters to the serial terminal.
  - Add `menuPop` API routine that will remove the current menu and replace it with its Parent menu.  If no Parent menu exist, then the Monitor mode will switch to Data Entry view.  This is equivalent to press the `AD` key on the menu but done is software.
  - If Fn-n is pressed and n isn't assigned to a routine, the message 'NoFn' will appear on the 7 segments.
  - Menus are now nested up to 4 deep.  Pressing 'AD' will return to the previous menu or into Data Entry mode if at the top menu.  Pressing 'GO' will run the routine and return to Menu mode.  This also applies to Parameter data entry.
  - When a menu item is selected, the menu item name and its routine address will be displayed on the LCD.  This will indicate to the user what routine is currently being executed.
  - Break Points can be skipped without removing `RST 30` or `F7h` from the code if a jumper is set on the G.INP headers `+` and `D5`.
  - Display welcome message on Serial Terminal on Power On or Cold Reset.
- **Bug Fix**
  - Fix grammar in main menu.
  - Removed `toggleCaps`, `toggleExpand`, `toggleProtect` and `toggleShadow` from API as the user will firstly want to check status of these flags first before setting or unsetting them.
  - Pressing `GO` on a informational menu item will not do a RESET. but only a softboot.  IE: if press `GO` on the version text in the main menu.
  - Cleaned up how `GO`,`AD` and `Reset` are handled whilst in a menu or parameter entry.
  - Pressing `GO` to run a routine removes removes GO as the last key pressed.

### V1.3
File MON3-1G_BC23-13.bin

- **Feature**
  - Fn-0 Sets a quick jump address.  The Current editing address is stored in 1 of 3 positions.  Default to 4000H
  - Fn-1,2 and 3 will change the current editing address to the defined addresses set by Fn-0
  - Fn-4 is now assigned to the Intel Hex Load routine
- **Bug Fix**
  - `sendToSerial`, `receiveFromSerial`, `sendAssembly` and `sendHex` API routines now use HL = Start Address, DE = Length in Bytes.
  - "Export Z80 Assembly" and "Export Hex Dump" menu items will now append a Line Feed after the Carriage Return.  This will correctly place a new line on more terminals.

### V1.2
File MON3-1G_BC23-12.bin

- **Feature**
  - Terminal Monitor
  - added `setDisStart` API routine
  - added `getDisNext` API routine
  - added `getDisassembly` API routine
  - added `matrixScanASCII` API routine
  - Fn-AD key now returns back to Main Menu from Data Entry mode
  - Remove AD,GO mapping from Up and Down Arrows on the Matrix Keyboard
  - Display Intel Hex Load on LCD when an Intel Hex Load is performed
- **Bug Fix**
  - Remove cursor on LCD if reset performed
  - Unused Fn 0-F slots now return ERROR on the Seven Segments
  - Reset-Fn (Cold boot) works always on the HexPad even if the Matrix Keyboard is active
  - `scanKeys` and `scanKeysWait` key press return value includes function key if pressed.  Bit 5 is set.
  - `getProtect` API call fixed
  - `beep` API call always will sound a beep regardless of Monitor Key Beep settings
  - fixed Caps Lock routines to work properly

### V1.1
File: MON3-1G_BC23-11.bin

- Feature
  -  `random` API routine

### V1.0
File: MON3-1G_BC23-10.bin

- Initial Release

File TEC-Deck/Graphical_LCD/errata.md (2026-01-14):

# Errata - Garbled Screen

If you get a garbled screen similar to this, there is a simple fix. 

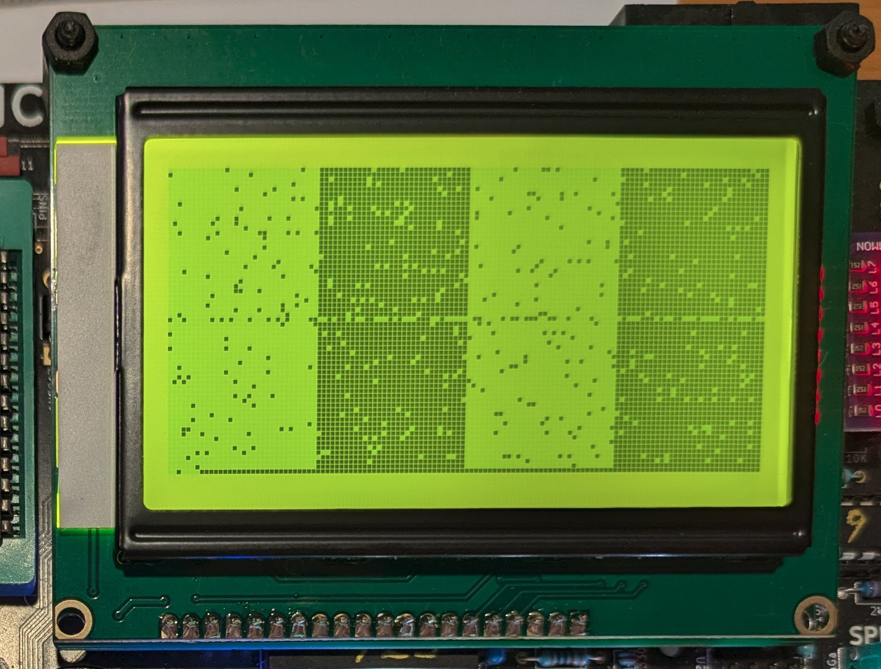
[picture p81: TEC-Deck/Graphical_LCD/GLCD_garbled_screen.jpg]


The older versions of the display did not have a capacitor installed at C6 but for some reason
they are in the latest versions, and this can cause timing ussues for the Z80.

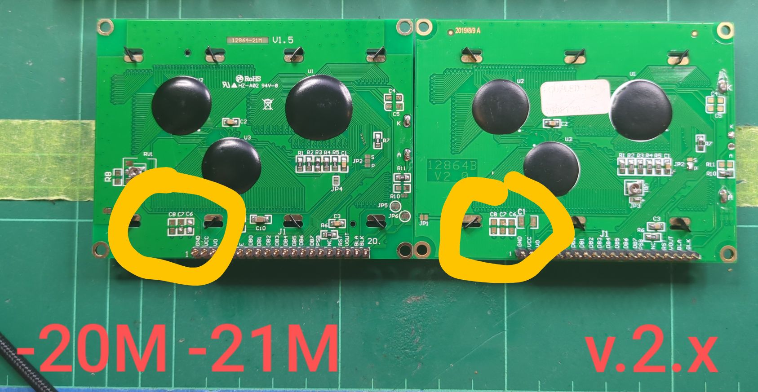
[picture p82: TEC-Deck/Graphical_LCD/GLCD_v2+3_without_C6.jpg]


Check on the back of your 128x64 GLCD module and locate the capacitor marked C6, usually
mounted at the bottom left.

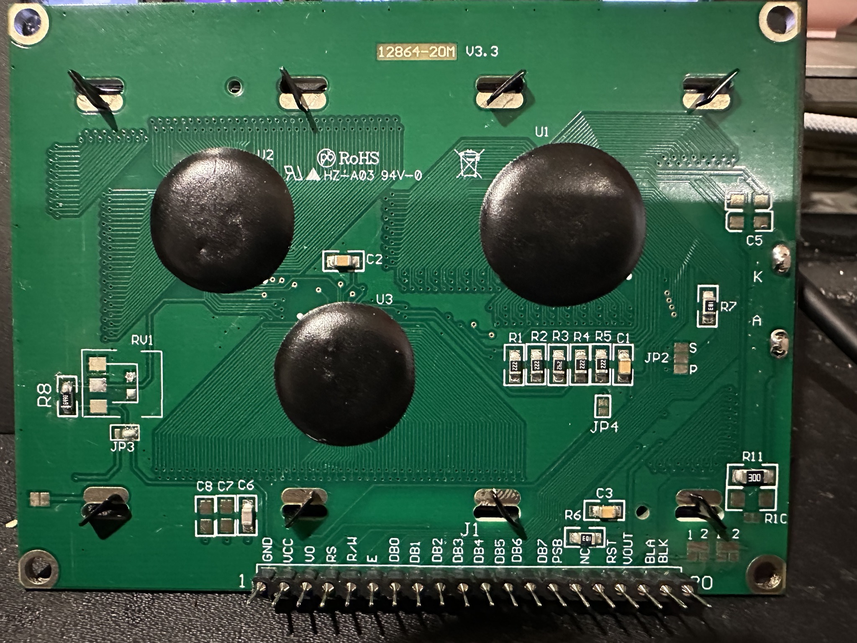
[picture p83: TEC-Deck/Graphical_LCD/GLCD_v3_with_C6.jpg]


Just get a pair of snips and cut the capacitor off. You can try to be tidier and use a soldering
or desoldering iron... But snipping it off is fast and effective.

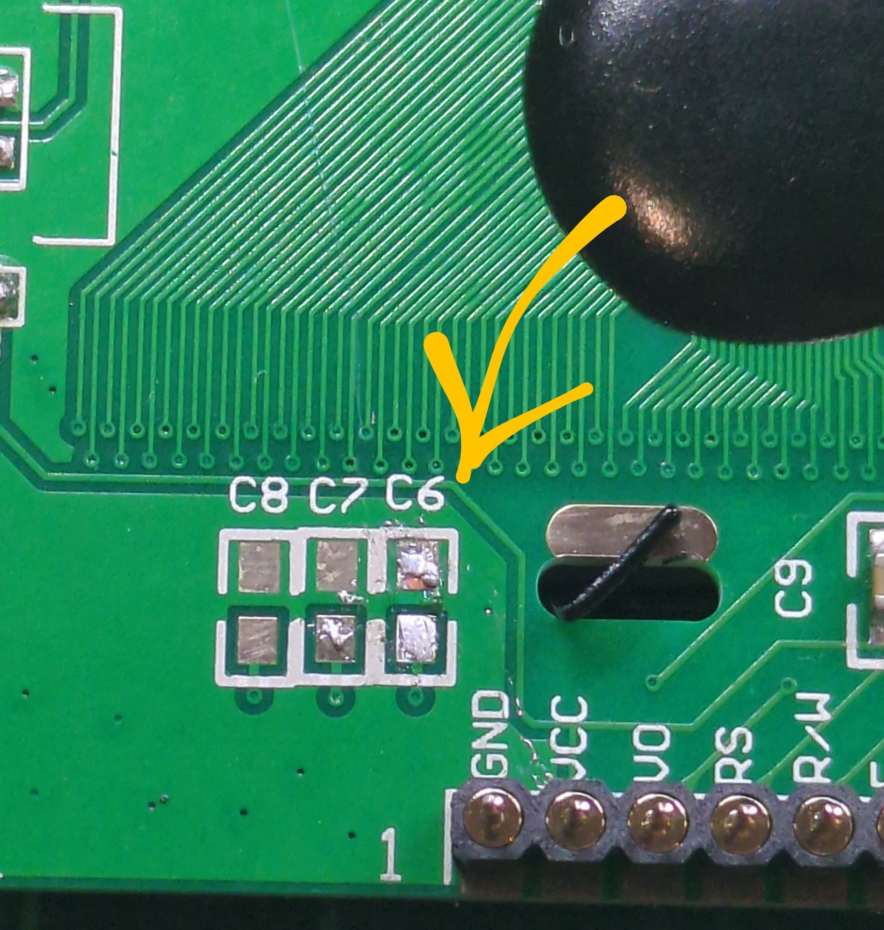
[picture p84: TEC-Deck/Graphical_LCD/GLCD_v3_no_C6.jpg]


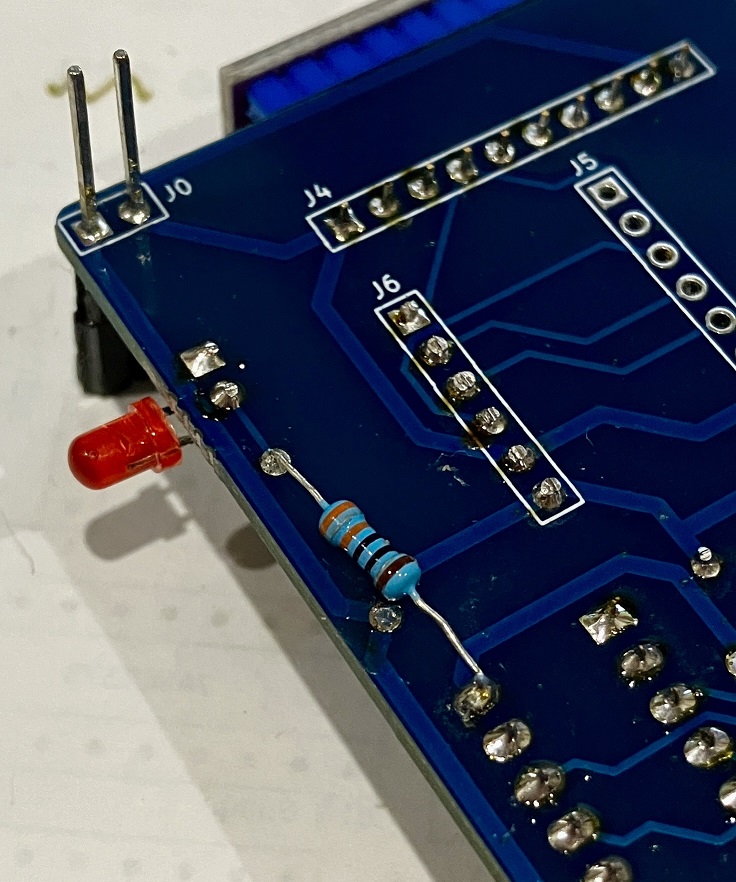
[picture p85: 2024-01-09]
GPIO/SD-Card/pictures/GPIO_SD-Card_v11_Errata.jpg

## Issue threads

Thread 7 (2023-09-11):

8Bar Graph LEDs not wired as expected

MarkJelic, 2023-09-11:
(This was a problem since Beta 1, but nobody that built one, other than MJ, had a 8Bar LED)
This was raised by Ian McLean, worded like this:
The Status LED Bar I have in the BOM does not work. The pinout is incorrect.
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

This is the correct pinout we need (except it is for a 10Bar LED):
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

However, as you can see the correct pinout is on a 10 way led bar. I CANNOT find an 8 way LED bar from any of the major suppliers that have the second pinout, only 10 way. ALL the 8 ways have the first pinout. This is from Mouser, Digikey, and Element 14. (Jaycar doesn't have them at all). If I replace the bar with individual LEDs, they work properly and light when they should.

1971Merlin, 2023-09-11:
I used the 10 bar LED and just snipped off the extra wires.

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

MarkJelic, 2023-09-11:
Where-upon, I replied to him:
Can’t you just flip the whole thing over? If it doesn’t work one way, spin it 180°?
Oh wait... What??... No way!

To say I was dumbfounded that you would wire a bar graph in ANY OTHER WAY, other than from one side to the other...
Yes, I had found a supplier in China that *gasp* didn't follow the dumbest convention ever!

Aaaanyway... So here are a couple of solutions:

1. For people that are getting the Kits (or parts) from me, you are indeed getting an 8 Bar LED module. You have no problem.

2. Apparently 10 Bar LED modules are wired the logical way, As a stop gap measure, you can trim off the left most 4 pins and fit the remaining 16 pins. It might mean you can't have a stand-off under the right corner of the LCD... But I never install those anyway.

3. I will modify the PCB in the next (production) run to allow the fitment of 10 Bar LED modules, and I will run duplicate traces down to it for the SPKR and HALT lines, so they are at least useful. They will be on the outside left and right accordingly, so that owners of 8 Bar LEDs will have it nice and centered to the space.

MarkJelic, 2023-09-11:
> I used the 10 bar LED and just snipped off the extra wires.
>
> 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

Look at those povo tactile switches... I hope you will elevate your final 1G board to the lofty heights of mechanical goodness. :)

MarkJelic, 2023-09-13:
Schematic updated to allow for 10 Bar LEDs:
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

And PCB updated:
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

Closed 2023-09-13.

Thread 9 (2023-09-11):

28pin EEPROMs vs UV EPROMS vs 64k UV EPROMS - Select Switch

MarkJelic, 2023-09-11:
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

OK, so we have a problem since Beta 1 that was discovered by Ian (again - good testing!) relating to the Hi/Lo select switch,

Now, this works perfectly fine for 4K chips, as long as the three jumpers are set to the 2k/4k positions. And there is three of them, keep in mind.

But for the larger 28pin chips, depending on the type of ROM chip you are using. the hi/lo select switch may or may not work!
- If using a 32K EEPROM... No problem.
- If using a 32K (uv) EPROM, the switches do not configure is correctly for these chips to work, so only the upper (hi) half of the ROM can be used.
- Now here is an interesting one: If you use a 27c512, a 64K (uv) EPROM, which much to my surprise is also in a 28 pin package, the hi/lo switch works fine. (But you are actually selecting the 2nd 16k block and the 4th 16k block, so it needs to be loaded correctly to work.
- Oh, also the One Time Programmable (OTP) version of the 27c512 also works as above.

If you check the table above (created by my good friend, Craig Jones) you can see that the pin config of the 32k (uv) EPROM has the pins for A14 and A15 swapped around compared to the other pins. (WTF, amirite?!)

So, to make the 32k (uv) EPROM be able to make use of the hi/lo switch, we would need to add ANOTHER TWO 3-pin jumpers, bringing the total to 5! Kind of annoying.

But there is also another option, to do with the 27c512 (64k) chips... We could add another Hi/Lo switch (maybe change the footprint so you use smaller switches) to allow you to select one of the FOUR banks of 16K. This means you could have MON1, MON2, the new MON3 and the Diagnostics all in one ROM. Now that gets me hard! ;)

So, the question is:
1) Do we add two more jumpers to accommodate 32k (uv) EPROMs? (And do we also add them for the EXPAND socket?)
2) Do we add another smaller slide switch to allow the 27c512 be used for 4 ROM selection? (See pic below of the type I mean. Same size as the Fullisik switcxh)
3) Or we do both?
4) Or we drop the 32k (uv) EPROM dual monitor selection and just make the 64k chip the "official" chip of choice?

Please leave your comments below.
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

MarkJelic, 2023-09-24:
An extra jumper/switch has been added to allow for 4x 16k ROMs to be selected out of 27c512. Adding that switch also enable to proper switching for 27c256.

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

Closed 2023-09-24.

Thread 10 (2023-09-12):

PCB silkscreen adjustments

JamesElphick, 2023-09-12:
Possible areas identified for improvement:

1. U18 is labelled "S.Imp" instead of "S.Inp" (for "Input")
2. U13 "S.Lach" should actually be "S.Latch"
3. U30 might be using an "o" instead of a zero
4. J2 designation is obscured by the pad of R2, could be moved up a bit
5. LCD outline is cutting through multiple resistor designators, it would be good to shift those lines a bit if possible

As noted by Mark, tented vias will improve many locations where silkscreen labels are overlapping vias and being obscured.

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

MarkJelic, 2023-09-30:
1. Easter Egg 1.
2. Renamed to "SysLa"
3. It's actually U3... The via makes it look like a o. Once tented it will look fine
4. Fixed
5. Fixed

Closed 2023-09-30.

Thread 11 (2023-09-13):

PCB perimeter traces

JamesElphick, 2023-09-13:
Recommend increasing trace width for perimeter ground and power traces. Possible board cut inaccuracies during manufacturing could risk reduced yield if cuts impinge on the available trace width.

Some locations are already tight (especially on rear of PCB) so it depends on what is achievable.

PCB corners could be chipped and sever these traces, so recommend routing the traces away (with a margin) similar to this:

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

MarkJelic, 2023-09-18:
To make the perimiter more than 1mm would entail a lot of moving of traces around. So I'll stop that idea for now and look at it again in a future revision, but the flood fills for GND on the bottom and +5v on the top will help with multiple routes of power delivery.

But I did implement the 45 degree corners as you suggested,.

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

Good for now?

JamesElphick, 2023-09-18:
Yes that sounds good, if we're adding copper fill for the ground plane and +5V then that will help. But that's good for now!

MarkJelic, 2023-09-23:
Flood fill done as well.

Closed 2023-09-23.

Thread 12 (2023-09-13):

PCB ground plane

JamesElphick, 2023-09-13:
Raised by Craig Hart, copper fills for ground plane may be beneficial on final board.

Ground plane on Beta 2 currently limited to top-left power section. Possible to do a ground plane elsewhere but may be broken up (or eliminated) too much by large number of signal traces.

EDIT: Probably should have grouped this into issue #11. Whoops....

MarkJelic, 2023-09-23:
Flood fill done on both +5v (top) plane and GND on bottom.

Closed 2023-09-23.

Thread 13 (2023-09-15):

JP4 Backlight Jumper

WhiteElf, 2023-09-15:
Make it clear in the documentation that JP4 is under the board and it is bridged (enabled) by default.

MarkJelic, 2023-09-24:
Fixed in schematic
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

Closed 2023-09-24.

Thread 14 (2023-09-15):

Radio GaGa Clarification

WhiteElf, 2023-09-15:
Make certain that the documentation notes that either:
    SW2 is used (populated)

    OR

    U20, SW11 and R32 is used (populated)

... but not both at once.

MarkJelic, 2023-09-30:
Have removed the SMD and gone with a 8 pin DIP switch. Overlayed the manual switch and the electronic switch so you CAN'T have both.  Documentation will explain.
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

Closed 2023-09-30.

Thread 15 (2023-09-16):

Matrix Keypad holes are too small for 12mm switch leads

1971Merlin, 2023-09-16:
12mm switch leads don't fit into the holes; the holes are too small diameter. 12mm switches have a flat metal lead, not a circular wire.

The matrix keyboard has the correct size holes. Use the matrix keyboard drill hole sizes.

MarkJelic, 2023-09-23:
All 12mm tactile footpads updated to 1.3mm holes.

Closed 2023-09-23.

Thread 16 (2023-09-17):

Speaker enable jumper

JamesElphick, 2023-09-17:
We could add a simple two pin jumper nearby to physically disable speaker connection.

Ideally not directly underneath LCD module when installed so that it won't require removal.

MarkJelic, 2023-09-24:
Added a "Groundwalker" jumper that will be initially hard traced together. (So no jumper actually needed and will not be supplied in the kit.)

But if you want to yell "SILENCE, Groundwalker!" at your TEC-1G, you can cut the trace between the jumper holes, solder in a pair of pins and then install or remove a shunt at your will.
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

MarkJelic, 2023-09-29:
Actually... This works better..
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

MarkJelic, 2023-09-29:
And this is the PCB.  Issue now closed.
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

Closed 2023-09-24.

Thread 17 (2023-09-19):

TEC-1G Schematic v1.7 readability.

tinkerzone, 2023-09-19:
While looking very cool, the TEC-1G v1.7 Schematic isn't readable on a Single A4 Page. While potentially readable on an A3 page, and on a large monitor, I think we need to keep with the TEC's background as stemming from a magazine article and so it needs to be printable on A4. Suggest splitting over 2, 3 or even 4 pages.

MarkJelic, 2023-09-19:
Ooof... That a bit of a job... But yeah, I get why you suggest that. (And yes, It is in fact done on one large A3 page.)

So... Do you have any suggestions of how it should be broken up?

tinkerzone, 2023-09-20:
This could be a schema:
Cpu/clock.
Keyboard and hex pad.
Displays and i/o.
Memory and Memory management.
Power and expansion.

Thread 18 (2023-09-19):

Mechanical Stability Issue - Enhancement - solution.

tinkerzone, 2023-09-19:
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

One of the key issues with the TEC-1 that is mounted using threaded spacers is that using the keyboard can cause the pcb to flex. There's an additional 3mm mounting hole in the centre of the board (good) but additional mechanical stability can be added using existing holes on the Beta 2 board. Instead of mounting the 11mm spacers that provide mechanical stability to the 4x20 lcd using a screw, if you use an 11mm space that has a male extension on the underneath of the pcb you've added 2 more stabilising points. See photo

tinkerzone, 2023-09-20:
Was mainly sent through for documentation.

One above the keyboard to the right would give a nice platform of 4 all around the keyboard. If you can do it without mucking up r2 and the speed control it would be worth it.

MarkJelic, 2023-09-30:
Have added 3 more mounting holes to stiffen up the board when typing and installing chips in sockets.
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

Closed 2023-09-30.

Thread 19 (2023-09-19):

Additional Silkscreen Issues

tinkerzone, 2023-09-19:
MEMBUS - Header
IOBUS - Header
GPI/O  - Header
CONFIG - Switch
STATUS - Bar
JP5 - Header
Z80Bus Female - Socket
Z80Bus RA - Socket

The silkscreen text related to each of these 8 parts are too small and not consistant with the other text on the board.

MEMBUS - Shift Room Size Jumpers, u14, and Chip Size Jumpers down PCB. Increase text size.
IOBUS - Shift header 4mm to the left. Increase size.
STATUS - Increase size with no drawbacks.
GPI/O - Shift GPI/O label down 3mm. Increase text.
CONFIG - Increase text. Break the LCD silkscreen.
JP5 - Bruh?! - Increase text.
Z80Bus Female - Increase text of RD/IORQ/A10/A11.
Z80Bus RA - Increase text of RD/IORQ/A10/A11.

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

MarkJelic, 2023-09-19:
This is not going to be an easy fix... Sure, the labels might be able to be made a smidge bigger, but I really doubt they can get to the same size as the rest of the labels. (And there is a consistency... they are all the same small size :)  And if I can slightly increase the size of some but not others, then there really will be inconsistency.

Another option could be to put the labels on the underside?

tinkerzone, 2023-09-20:
So Config switch and status bar labels need to be viewable by the user. Would suggest increasing the size of these labels is non-negotiable.

I'd be fine if the labels for the headers were kept small on the top but on the bottom side larger.

There is a large amount of space on the bottom side where additional information can be silkscreen. I have seen other boards that have like logic tables that show what memory is selected etc when what jumpers are set. See the N8VEM sbc project board.

MarkJelic, 2023-09-30:
1. None of the headers can be moved. We have cards relying on their position to connect correctly.

Have increased the size of the Config and Status labels slightly. Any bigger and they would either conflict or start to be hidden by components.

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

Have added some labels to the back:
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

Closed 2023-09-30.

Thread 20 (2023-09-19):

Schematic V1.8 - Switch 11/12 Clarity Issue

tinkerzone, 2023-09-19:
Rename Switch 11 and Switch 12 Switch 11a and Switch 11b and/or put a dashed line in-between to indicate they are mechanically connected.

MarkJelic, 2023-09-24:
Changed the switch to something custom, as previous would not have worked anyway.

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

tinkerzone, 2023-09-24:
Hi Mark,
Can I suggest this description goes on the silk screen overlay on the bottom side of the board as well? The N8VEM project puts info about jumpers on their boards and it's very handy.

tinkerzone, 2023-09-24:
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
Mark, this is a more elegant solution to this issue.

MarkJelic, 2023-09-24:
Although I agree that is very elegant (and very space efficient) I think it is too difficult, without exactly those pictograms printed somewhere, for people to easily switch from one to the other.

As for the text on the underside... I think that should be doable.

Is there any other text that needs printing on the underside?

MarkJelic, 2023-09-24:
I'll close this off as somehow its turned into a duplication of Issue #22

Closed 2023-09-24.

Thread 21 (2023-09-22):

Vias too close to pads

MarkJelic, 2023-09-22:
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

MarkJelic, 2023-09-23:
Moved those two and a couple others that were close to pads.

MarkJelic, 2023-09-23:
Moved those two and a couple others that were close to pads.

Closed 2023-09-23.

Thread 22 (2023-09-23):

The decoding for the EXPANSION socket needs confirmation

MarkJelic, 2023-09-23:
Beta 1 did not support 24 pin chips in the EXPANSION socket. It was originally only meant to support a 32k RAM chip, and allow people to play with "paging" and effectively give a full 64k of RAM for the system. But then it was realised that the socket could also be used for large programs distributed in ROMs, or allow the copying of code from ROMs to RAM, etc. including the old TEC-1 2/4K ROMs.

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

So for Beta 2, the jumper setup used for the ROM socket was copied to the EXPANSION socket, with the only difference being that the switch is controlled by the EXPAND system latch bit.

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

But with testing of Beta 1, it was identified that 27c256 EPROMs only allow for the top half of the rom to be allowed to be seen, due to pinout difference of the 27c256 to the 28c256 EEPROM which is what many of us were testing with. Thus it was unlikely that 27c256 worked in the EXPANSION socket properly, either.  Meanwhile, it was discovered that 27c512 (a 64k UV EPROM with only 28pins) could be successfully used in the ROM socket, if it's A15 pin was also allowed to be switched. So an extra switch was added to the v1.8 of the schematic (proposed for the Production run) as below. Conveniently, this ALSO fixes the pinout difference of the 27c256 (we hope) to thus allow you to manually select which half of the 32k EPROM you want to see.

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

So for the production version, it would be good if the EXPANSION socket also was compatible with 32k EPROMS, be they either the UV sort (27c256) or the EEPROM sort (28c256) and be able to be controlled by the EXPAND bit. But the pinout differences would require the SWAPPING of a couple of pins between those two EPROM sorts. Hence, Mark came up with this:

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

But after asking for confirmation, Craig suggested this, but he had in mind support for the 27c512, which is not the intention of this socket. Only a maximum of 32k is to be paged in this socket, and to be frank, it is largely intended for RAM to be installed, not ROMs. The only reason to allow ROMs in this socket is to allow "copying" of any ROM (up to 32k) you may find in the wild, or designing a program that needs 32k of space for its code.  Here is Craig's suggestion... But this, as with Mark's above, needs to be thoroughly thought through, before we go to production, without testing!

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

1971Merlin, 2023-09-23:
Mark, your final design allows for /WR to be jumpered to pin 1. This is incorrect. No device uses pin 1 for WR.

Pin 1 is either A14, no connection, or +5v depending on chip type. Your schematic needs a re-work.

MarkJelic, 2023-09-23:
> No device uses pin 1 for WR.
the 27c256 uses VPP on Pin 1... That's kinda like WR... But obviously not enough to actually program it so I don't think it would do any harm to have WR connected to it.

I've updated the graphic to show it is a DPDT switch that works in unison, basically swapping the connections on Pin 1 and Pin 27 from all other 28 pins chips, to the damn 27c256.

It still looks to me as if my circuit should do the trick.

IanMcLean68, 2023-09-24:
> the 27c256 uses VPP on Pin 1... That's kinda like WR... But obviously not enough to actually program it so I don't think it would do any harm to have WR connected to it.

Probably not. The minimum programming voltage you seem to find on windowed eproms is 12V. It is more conventional though to have Vpp going to ground when not being programmed.

MarkJelic, 2023-09-24:
OK, how about this?  When the DPDT switch is on 2-3/5-6, it is in 27C256 mode. Up for all other chips.
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

MarkJelic, 2023-09-24:
I made a custom footprint for it :)
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

MarkJelic, 2023-09-24:
In circuit
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

tinkerzone, 2023-09-24:
This is my solution to sw5.

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

tinkerzone, 2023-09-24:
Also, as per my comment on issue 20 would be helpful to have the jumper option silkscreened on the bottom of the pcb.

tinkerzone, 2023-09-24:
Actually, this version of sw5 would allow a dpdt switch to be used.
![Uploading 20230924_221002.jpg…]()

tinkerzone, 2023-09-24:
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

MarkJelic, 2023-09-24:
Ooh... I like this solution... Why could nobody else come up with it??  OK, let me try that in the schematic and make sure it makes sense...

(You know I was wracking my brain, over and over, saying to myself "I am SURE there is a way to work with with a dpdt switch, but I just couldn't make it come together!)

tinkerzone, 2023-09-24:
:D

MarkJelic, 2023-09-24:
Yep, I think it works! Well done!! :)
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

tinkerzone, 2023-09-24:
Woohoo!

MarkJelic, 2023-09-24:
OK, and the final setup, that also allows for the use of 6116 (and equivalent NVRAM packages) is this:
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

Wont close this until the PCB is routed.

1971Merlin, 2023-09-25:
I've had a look over the "OK, and the final setup, that also allows for the use of 6116 (and equivalent NVRAM packages) is this:" version, and this seems to work correctly for all chip types.

MarkJelic, 2023-09-25:
>Vpp is usually held at +5v when not programming, however. The following is from the 27c256 datasheet. To meet this, connect SW5A leg 3 to 5V, not GND.

No harm and easy to fix. I'll update the schematic.

MarkJelic, 2023-09-26:
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

Fixed... Now doing the PCB

MarkJelic, 2023-09-30:
So this is the final setup of the Schematic:
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

And this probably wont help, but this is the bit of the PCB as routed:
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

And this is the Render:
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

Closed 2023-09-30.

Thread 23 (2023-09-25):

Dat line pull ups. Mon-2 issues

IanMcLean68, 2023-09-25:
A bug has been discovered during beta testing on the Beta2 board. I was testing older TEC monitors compatibility with the 1G when I discovered a problem with mon-2.

The symptoms are that the keyboard fails to respond properly. So much so that the TEC becomes unuseable.
The symptoms only arise for a very specific set of circumstances. Through testing it has been discovered that the behaviour is similar to if your were to have the shift key permanently pressed, although more intermittent and random.
The numeric keys are particularly affected and the key beeps sound at incorrect pitch and sound distorted.

The specific set of circumstances in which is bug arises are as follows:

1) mon-2 is running in a 2K or 4K eprom with 2k memory addressing enabled.
2) Fast clock speed.
3) The 20x4 LCD is unplugged.

If you switch the clock to slow speed, the problem goes away. If you plug the LCD back in, the problem goes away. This only happens with mon-2. The problem does not occur with mon-1b, bmon, or any of the newer roms in development.

James Elphick was able to duplicate this bug for mon-2, using an 8k EEPROM in 2K addressing mode. This has not been tested with mon-2 programmed into a larger 16k or 32k (e)eprom.

We also have James Elphick to thank for finding a quick fix to get mon-2 working.
Although further testing is needed to verify, it appears that the 47k pullup provided by RN1 is too weak on the D5 data line.
This can be fixed on the beta2 board by placing a resistor in parallel to the D5 point on 47k RN1 and +5V. Suggest a value of 10k to 12k to bring the resistance of the pullup close to 10k. Alternatively, RN1 47k can be replaced with a 10k RN changing the pullups on all datalines to 10k.

My solution was to solder a 12k resistor between the D5 point on RN1 and +5V which is the common pin on RN1. This brings the pull-up resistance on D5 data line to about 9.55k, very close to 10k.

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

To close this issue will require some more stability testing with the changed RN value.
It would be even better if we coud find the reason why this occurs and why it only affects mon-2.

MarkJelic, 2023-09-30:
RN1 changed to 10K in schematic:
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

And label on PCB updated:
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

Closed 2023-09-30.

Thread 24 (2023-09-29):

bmon16k bug

IanMcLean68, 2023-09-29:
There is a known bug in bmon16k. If the GLCD is connected to the Tec Deck, the 40x40 LCD does not display the top two lines, which is the next 8 bytes in memory in hex. It does correctly display the disassembly on the bottom two lines. If the GLCD is disconnected, the probem goes away.

After analysing the bug, Brian Chiha has provided a hot fix:
After boot, go to address 0821H using the Ad key.
Check the byte at that location in memory. If it is not zero that is why the LCD did not boot properly.
If not zero, insert a 00H into 0821H. The LCD is restored. Lasts between resets until power is removed.

The issue has been opened because a patch is needed to fix the bug and render the hotfix unnecessary in bmon16k.

MarkJelic, 2023-09-30:
Moved to the BMON Issues:

https://github.com/bchiha/BMon/issues/1

Closed 2023-09-30.

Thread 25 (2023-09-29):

DIP-8 analogue switch and fast clock redirect

JamesElphick, 2023-09-29:
### **FAST CLOCK REDIRECT**

Beta 2 design for the clock switching circuit relies on the analogue chip (currently TS5A3159DCKR "The Tick") being operational in order to transmit the fast clock. This is because the fast clock is connected to the NO (Normally Open) input of the switch.

Current design:

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

The fast clock will be required for most use cases. So it would be ideal to make the fast clock less reliant on the switch by instead routing to the NC (Normally Closed) input.

Changes to redirect fast clock include:
- Redirecting the Fast clock to NC pin (currently Pin 3) of analogue switch.
- Redirecting the Slow clock to NO pin (currently Pin 1) of analogue switch
- Moving GND to High/Low pin (currently Pin 6) of analogue switch
- Moving +5V and R32 10K resistor to Pin 2 of GaGa switch

With GND normally applied (GaGa switch Open) this will enable the Fast clock by default.

Proposed design (changes highlighted):

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

### **DIP-8 ANALOGUE SWITCH**

The current "Tick" analogue switch has been found to have capacitive coupling or crosstalk issues. A DIP-8 alternative is being considered to allow use of an alternative analogue switch (in DIP-8 package) and other package options for experimentation using an add-on PCB.

Best option right now is the MAX4544 chip with this pinout:

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

ATTiny85 microcontroller also comes in DIP-8 package as an option with +5V and GND on the same pins.

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

However Reset on Pin 1 of the ATTiny85 means that these two chips cannot use the same socket. Reset line would also need to be routed to the chip for this purpose. This option of a microcontroller could be revisited with a future board revision.

Changes for DIP-8 analogue switch include:
- Routing +5V to Pin 8 on MAX4544
- Routing GND to Pin 4 on MAX4544
- Routing Pin 1 of GaGa switch to Pin 7 on MAX4544
- Routing the CLK line to Pin 2 on the MAX4544
- Pin 5 and Pin 6 of MAX4544 will be N.C. (No Connect)

Proposed design for MAX4544 (changes highlighted):

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

MarkJelic, 2023-09-29:
OK, so here is the updated schematic:
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

And I've done something a bit radical... Since you either use the manual switch or you use the Tick, and not both at the same time, I've overlayed one over the other.

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

Thoughts?

JamesElphick, 2023-09-29:
That's an awesome idea with overlaying both footprints!

One change I would make is to move the R32 10K resistor to the +5V side of the GaGa switch. That way Pin 7 of the 4544 is normally GND, and doesn't receive the full power rail current when the switch is on, just a +5V logic signal.

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

MarkJelic, 2023-09-29:
Mmm... That contravenes my understanding of how pull up/down resistors work. In my (amateaur) understanding, that line would never go high. The direct ground link would always pull it low, no matter what the switch is doing.

I'll wait for others input on this.

MarkJelic, 2023-09-30:
PCB routing completed.  Testing will have to be on the production run.  Issue closed.

Closed 2023-09-30.

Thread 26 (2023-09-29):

Disco LEDs have been reported to burn out retinas.

MarkJelic, 2023-09-29:
Apparently a report has been filed to the UN for crimes against humanity because they are so bright. ;)

@1971Merlin has suggested a resistor in line after the output of the tranny, like so. Awaiting confirmation.

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

MarkJelic, 2023-09-30:
PCB updated. Added new R33 to BOM. @Ian

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

Closed 2023-09-30.

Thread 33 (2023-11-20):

Z80 Bus and 40 pin TEC-DECK symbols need updating

bchiha, 2023-11-20:
Can the symbols in the schematic for the J1 and J2 be ordered in ascending pin order and have the pins for GND and 5v labelled with their pin number

Closed 2023-11-30.

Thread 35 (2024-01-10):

Errata update: Beta 1/2 boards don't support 2x256 size memory chip in the EXPANSION socket

1971Merlin, 2024-01-10:
Already fixed in production. just needs to be noted in errata.

MarkJelic, 2024-05-05:
Fixed in production versions

Closed 2024-05-05.

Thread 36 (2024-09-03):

switch SK-22F39 or SK-22F24 impossible to find

mciucci65, 2024-09-03:
Hi great project but I can't find on this type of switch. Do you have some equivalent or other site where I can find ?.

On Aliexpress there are not.

kind regards

MarkJelic, 2024-09-05:
Yes, the power switch we selected initially is now seemingly impossible to source. So I have made a little adapter board which is available for US $1 plus postage. (Best you buy another kit and then save on postage.) Here is a link to the instructions for installing it.
https://github.com/MarkJelic/TEC-1G/blob/main/files/Installing_New_Power_Switch.pdf

The item is still being approved on Tindie, but here is the link to it when it does:
https://www.tindie.com/products/tec1/tec-1g-replacement-power-switch/

mciucci65, 2024-09-05:
thanks for quick replay when will be available the gerber files for this and RTC,SD graphic display module ?

MarkJelic, 2025-03-19:
I'll get the gerber up for this and all the others by the end of the week.

mciucci65, 2025-03-24:
hi Mark,

thank you forcyour great job
do you have ant  news about gerbers upload ?

kind regards

Il giorno mer 19 mar 2025 alle 04:46 Mark Jelic ***@***.***>
ha scritto:

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

mciucci65, 2025-03-24:
Hi Mark,
Thanks for RTC gerber upload can you also upload SD gerber

kind regards

Il giorno lun 24 mar 2025 alle ore 06:01 Massimo Ciucci <
***@***.***> ha scritto:

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

MarkJelic, 2025-03-24:
RTC and SD Gerbers are up.

The new power switch adapter PCB is here:

https://github.com/MarkJelic/TEC-1G/blob/main/files/TEC-1G_Power_Switch_v11.zip

mciucci65, 2025-03-24:
Thank you very much for your great job and for gerbers upload.

kind regards
MC

Il giorno lun 24 mar 2025 alle ore 15:00 Mark Jelic <
***@***.***> ha scritto:

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

mciucci65, 2025-04-05:
Hi Mark,

Thanks again for the gerber uploaded.

I need more information about MON 3 1.6. I see in the Pata document on
github that you mention it but i cannot find it.

Where I can download it.

kind regards
MC

Il giorno lun 24 mar 2025 alle ore 15:00 Mark Jelic <
***@***.***> ha scritto:

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

MarkJelic, 2025-04-05:
This has not yet been officially released but I believe you can get it from Brian Chiha who is working on it.

https://github.com/bchiha/Ready-Z80/tree/main/26-PATA_FAT32

mciucci65, 2025-04-05:
thanks !!!
I checked the sd gerber  and you forgot to upload the 2 mini pcb output
display and input selector.

Can you upload also these pcb ?

kind regards

Il giorno sab 5 apr 2025 alle ore 05:23 Mark Jelic ***@***.***>
ha scritto:

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

bchiha, 2025-04-05:
Hi,

Mon3 v1.6 hasn't been released yet, I still have a few things to add.  The PATA code to read a disk can be found in the link Mark provided.  But, if you contact me, I can provide you with the current Mon3 1.6 with the PATA code.  However, it's only useful if you have the PATA PCB installed.

I do plan to add the functionality for disk reads for the Micro SD Add-on too.

mciucci65, 2025-04-05:
hi,
thanks for quick response i will wait for sd support in new mon 1.6.

thank again for your great project.

kind regards
MC

Il giorno sab 5 apr 2025 alle 13:02 bchiha ***@***.***> ha
scritto:

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

MarkJelic, 2025-04-05:
I have uploaded the Input Tester Gerber. I never had a separate Output tester on it's own. I originally had it as part of the SD car to test PCB printing with separate snap-off PCBs. But the PCB printers charge some stupid extra amount for this option so I quickly dropped it for separate little boards like the Input tester. However, but then I had also found on Tindie a very capable and cheap output tester board that was cheaper than I could put it all together and so that is what I have been supplying for a while now. This is what I found

https://www.aliexpress.com/item/1005004567063273.html

Now... About this adding comments to already closed Issues and even Issues that are totally unrelated.
For example, what has MON3 v1.6 got ANYTHING to do with the old power switch not being able to be found??
It is not fair anyone having to find which subject you randomly decided to add a comment to.

Please, no more. Stick to the topic of the Issue, at a very minimum. And ideally, if it is a NEW Issue, then please create it as a NEW Issue.  I don't close Issues off until I think they are in fact completely dealt with. In the case of these testers, yes would have been appropriate to tack it onto the end of the issue you raised about the Gerbers for the RTC and SD... Not in this one.  And certainly not throwing in MON3 1.6 questions. That is inappropriate because NOBODY else except you and Brian/Me would find this question!  Please start a NEW Issue any questions regarding MON 1.6. Any future breaks in this common sense approach will be deleted and ignored.

Closed 2025-03-24.

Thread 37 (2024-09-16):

Gerber Files for RTC and SD

mciucci65, 2024-09-16:
When will be available these gerber files for RTC e SD module ?

MarkJelic, 2025-03-19:
I just need to update them with the new 2x10pin header and then I will put them up on here. Give me till the weekend.

(Sorry, I don't get any notifications about Issues being raised, so I didn't see this until now. I'll make sure to keep an eye on this from now on.)

mciucci65, 2025-03-19:
Hi Mark great news,

thank for update and wait weekend for gerber upload.

kind regards

MarkJelic, 2025-03-24:
Done.

MarkJelic, 2025-04-05:
I have uploaded the Input Tester Gerber. I never had a separate Output tester on it's own. I originally had it as part of the SD car to test PCB printing with separate snap-off PCBs. But the PCB printers charge some stupid extra amount for this option so I quickly dropped it for separate little boards like the Input tester. However, but then I had also found on Tindie a very capable and cheap output tester board that was cheaper than I could put it all together and so that is what I have been supplying for a while now. This is what I found

https://www.aliexpress.com/item/1005004567063273.html

Closed 2025-03-24.

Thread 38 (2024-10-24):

FTDI ISSUE PCB 1.5 and rom TEC-1G_ROM-64-15.bin

mciucci65, 2024-10-24:
I built your best pc everithing works excpet serial port not working which is the correct setting ? I tryed with different ftdi problem but nothing.

I see only strange character with 4800-8-n-2

I'm using pcb 1.5 and sw [TEC-1G_ROM-64-15.bin](https://github.com/MarkJelic/TEC-1G/blob/main/ROMs/TEC-1G_ROM-64-15.bin)

mciucci65, 2024-10-25:
Resolve!!

i forget to solder bridge r34 0ohm before all board works except serial.
Close issue please.

MarkJelic, 2025-03-19:
Yes, that annoying little jumper has been removed in the latest version of the board. :)

Closed 2025-03-19.

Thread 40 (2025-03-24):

New GPIO Board - What could it be??

MarkJelic, 2025-03-24:
A new GPIO Board is being designed by James Elphick and it's going to be a banger!

But what is it going to be? Be the first to guess correctly and you win the Kit when it becomes available. Runner up with get a free PCB.

The only hint we will give you is:  What has changed with the GPIO Connector in version 1.3?

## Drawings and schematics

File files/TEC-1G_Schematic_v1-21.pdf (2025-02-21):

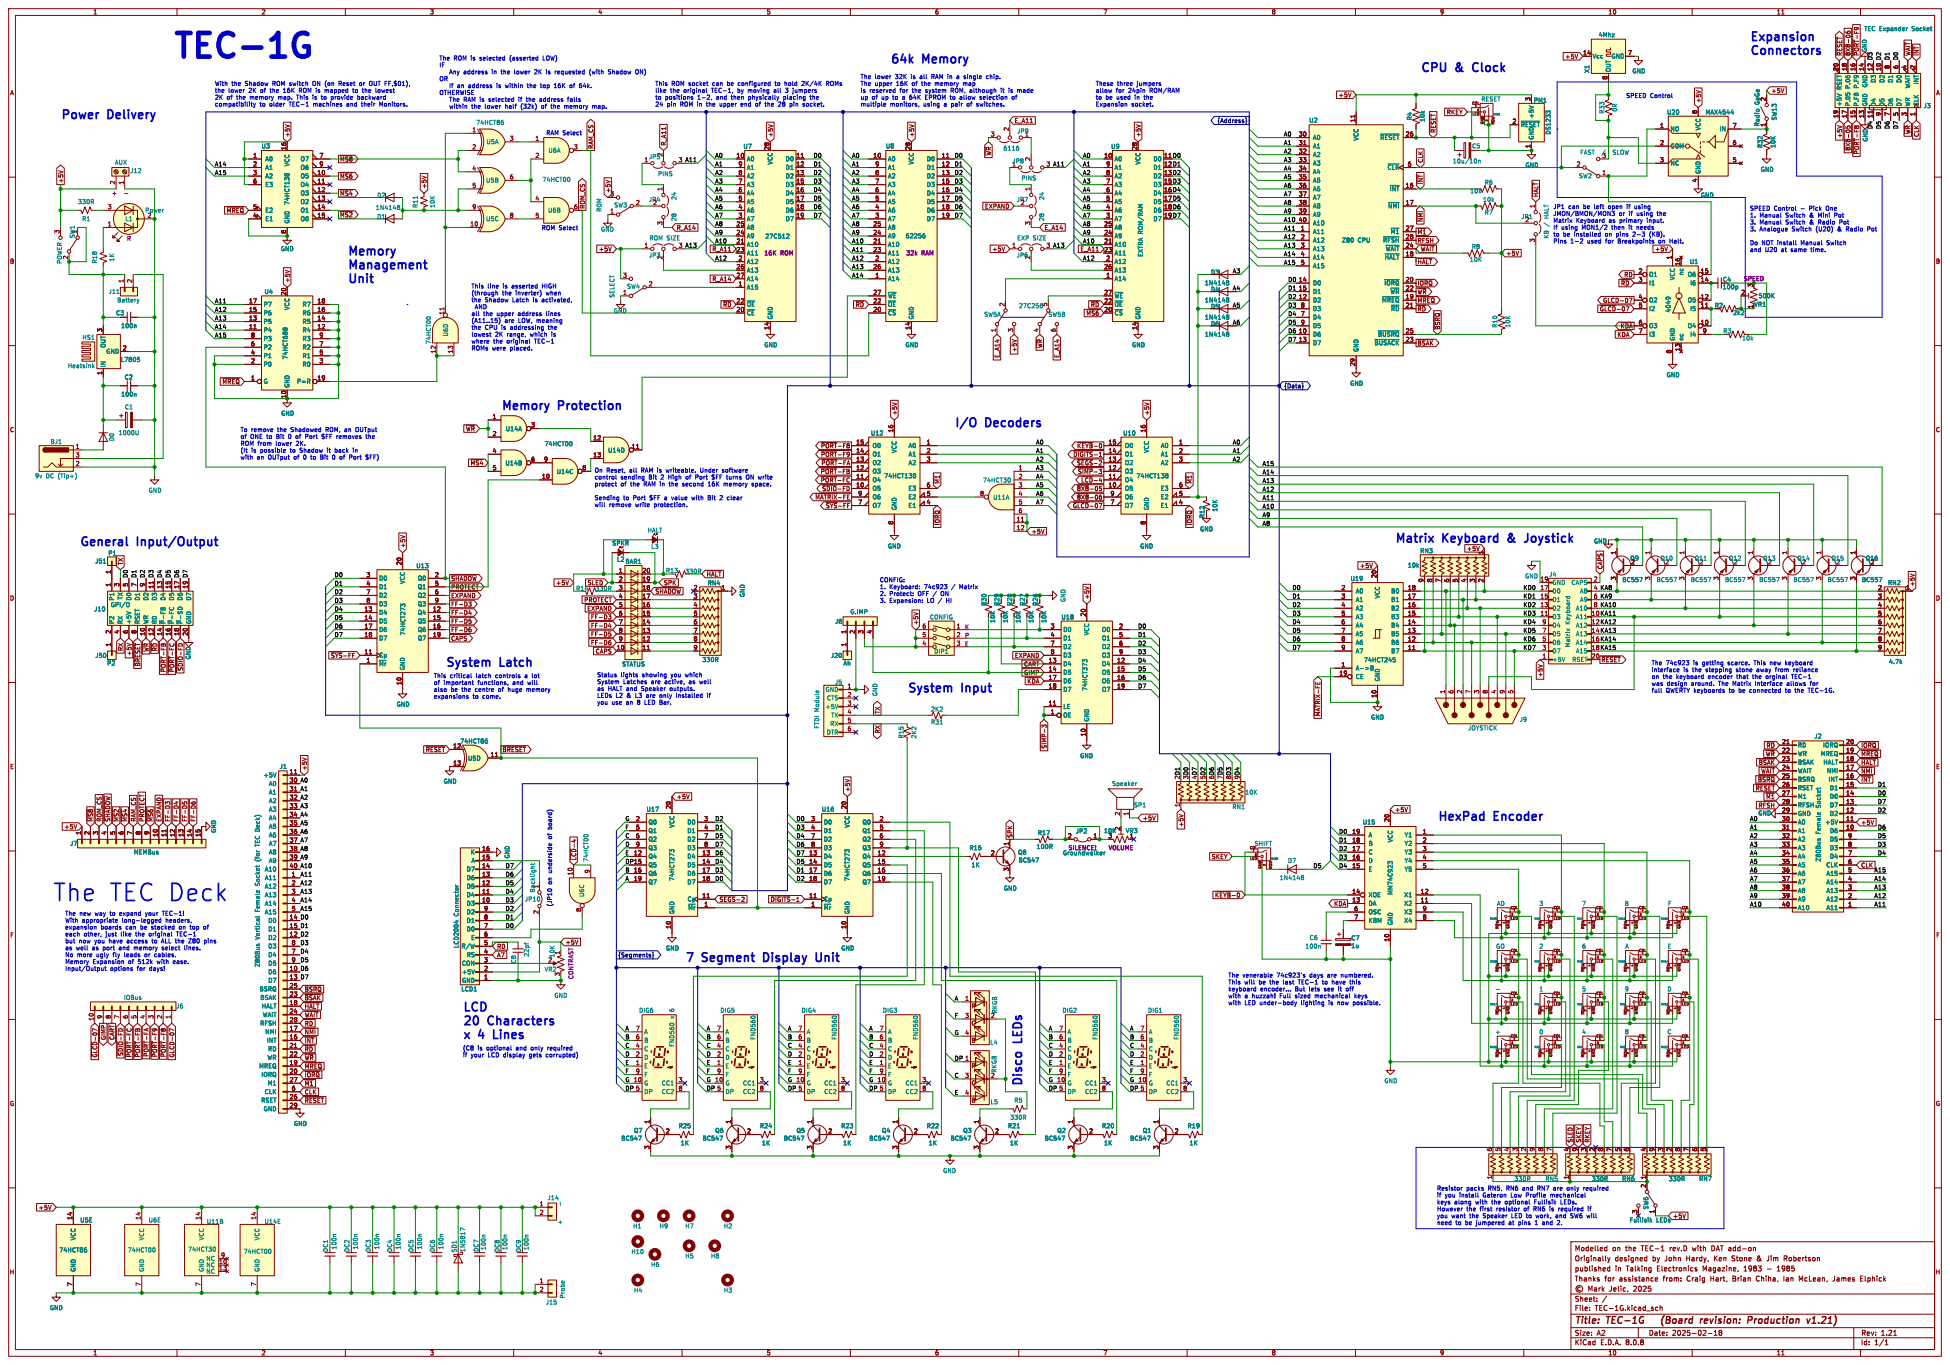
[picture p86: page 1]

J3 TEC Expander Socket CLK

24 pin ROM in the upper end of the 28 pin socket. TEC-1G

and U20 at same time. 64k Memory

The lower 32K is all RAM in a single chip. The upper 16K of the memory map

With the Shadow ROM switch ON (on Reset or OUT FF,$01),
the lower 2K of the 16K ROM is mapped to the lowest 2K of the memory map. This is to provide backward

If an address is within the top 16K of 64k. OTHERWISE

These three jumpers allow for 24pin ROM/RAM
~{RD} E_A11 ~{WR} ~{IORQ}

SPEED Control System Input

to be used in the Expansion socket.

JP1 can be left open if using

SPEED Control - Pick One

If using MON1/2 then it needs

This line is asserted HIGH
the Shadow Latch is activated, AND

all the upper address lines

protect of the RAM in the second 16K memory space. Sending to Port $FF a value with Bit 2 clear will remove write protection.

J2 Z80Bus Female Socket VCC 14 GND

but now you have access to ALL the Z80 pins as well as port and memory select lines. No more ugly fly leads or cables. Memory Expansion of 512k with ease.

if your LCD display gets corrupted)

Resistor packs RN5, RN6 and RN7 are only required

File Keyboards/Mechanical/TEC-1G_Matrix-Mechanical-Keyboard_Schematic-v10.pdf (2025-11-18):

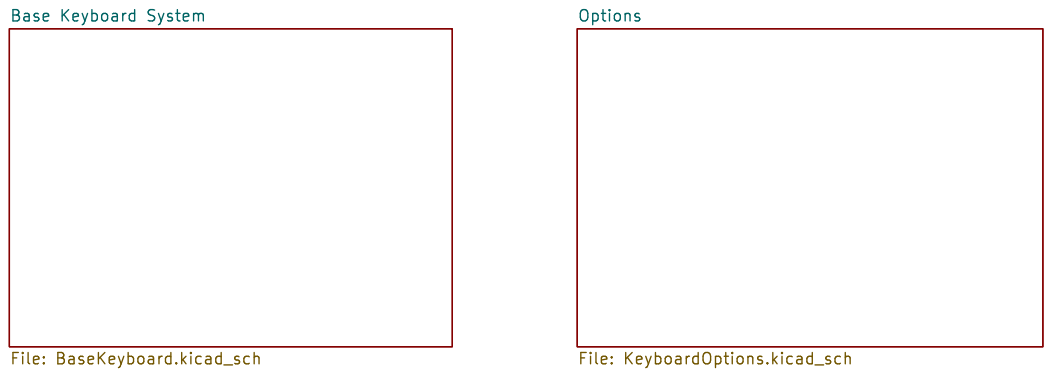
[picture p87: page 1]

Id: 1/3 Title: TEC-1G Mechanical Matrix Keyboard

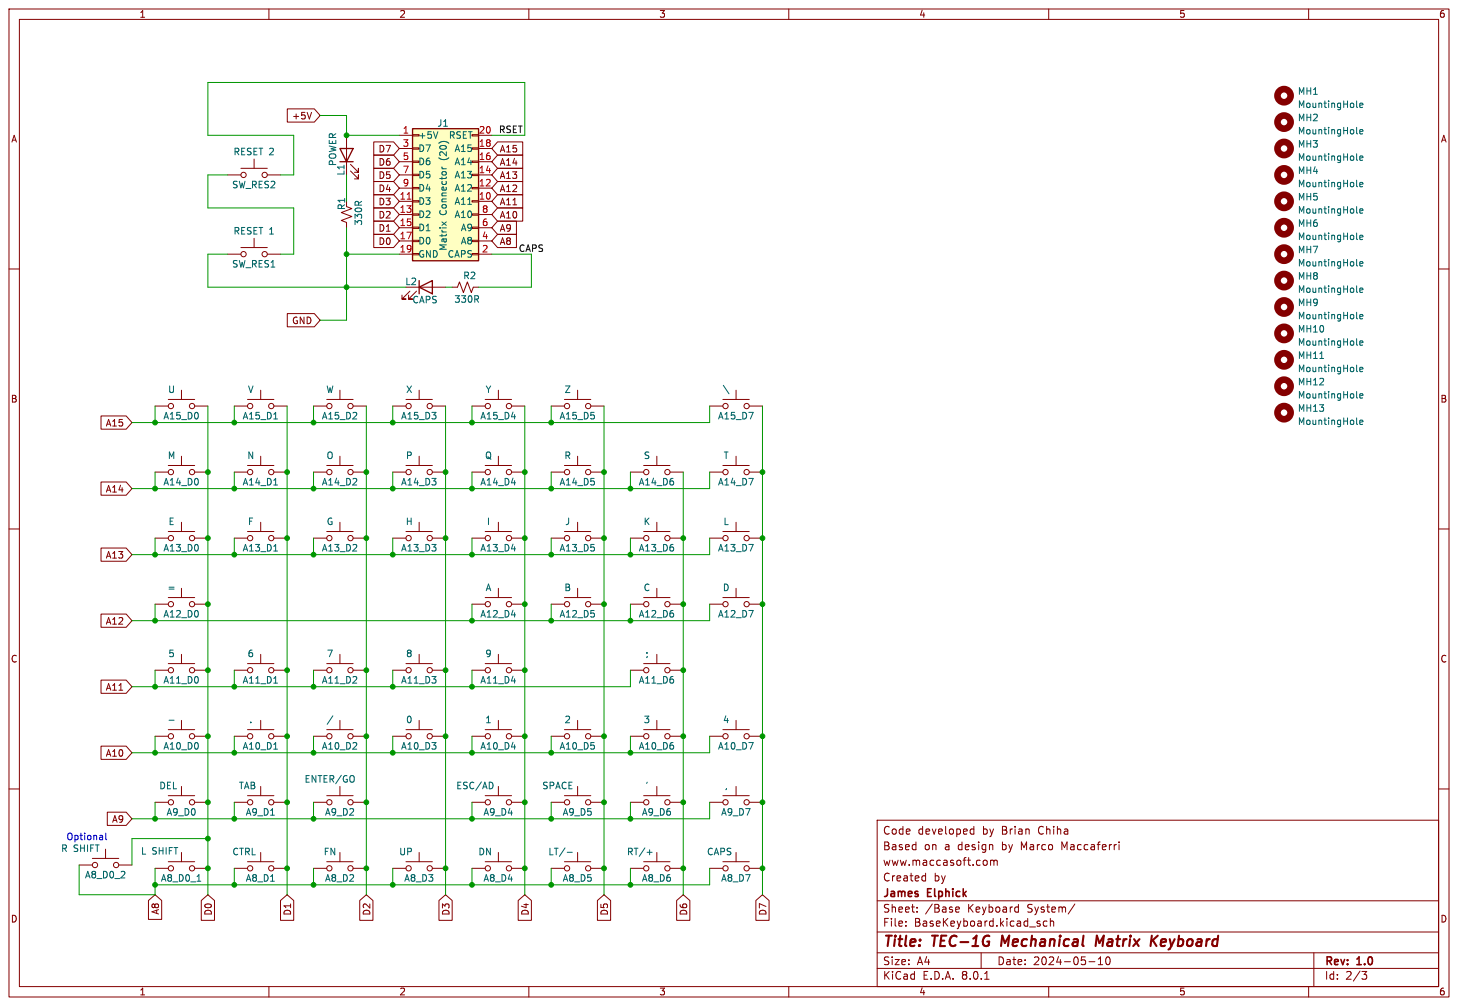
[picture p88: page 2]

Id: 2/3 Title: TEC-1G Mechanical Matrix Keyboard

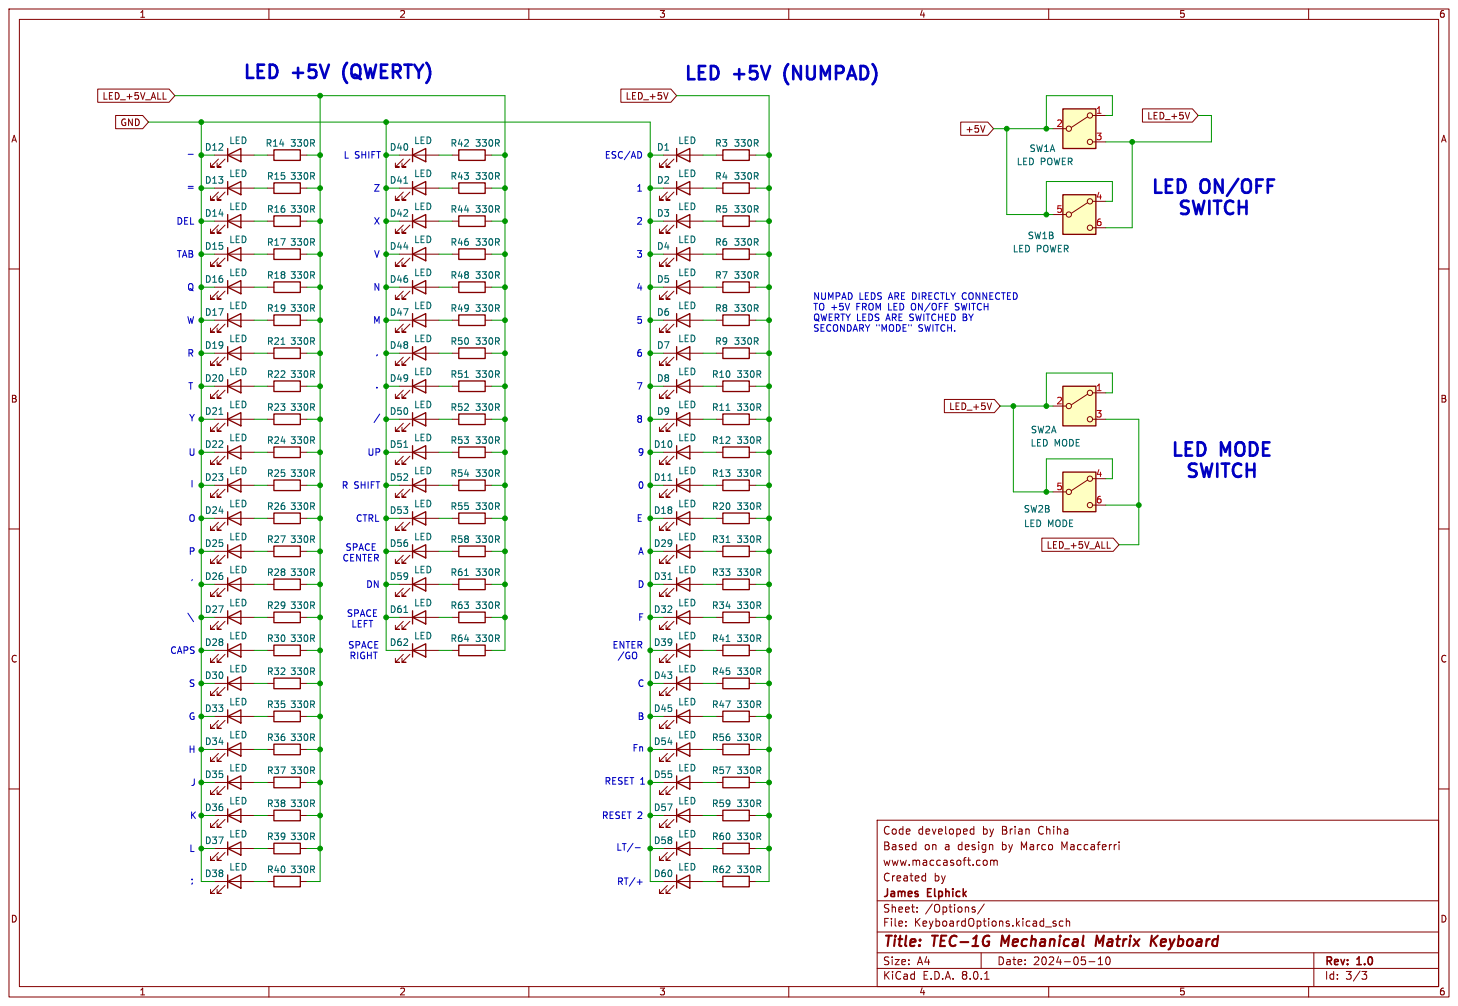
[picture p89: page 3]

D16 LED
SECONDARY "MODE" SWITCH. WRQ
D17 LED

TO +5V FROM LED ON/OFF SWITCH QWERTY LEDS ARE SWITCHED BY

Id: 3/3 Title: TEC-1G Mechanical Matrix Keyboard

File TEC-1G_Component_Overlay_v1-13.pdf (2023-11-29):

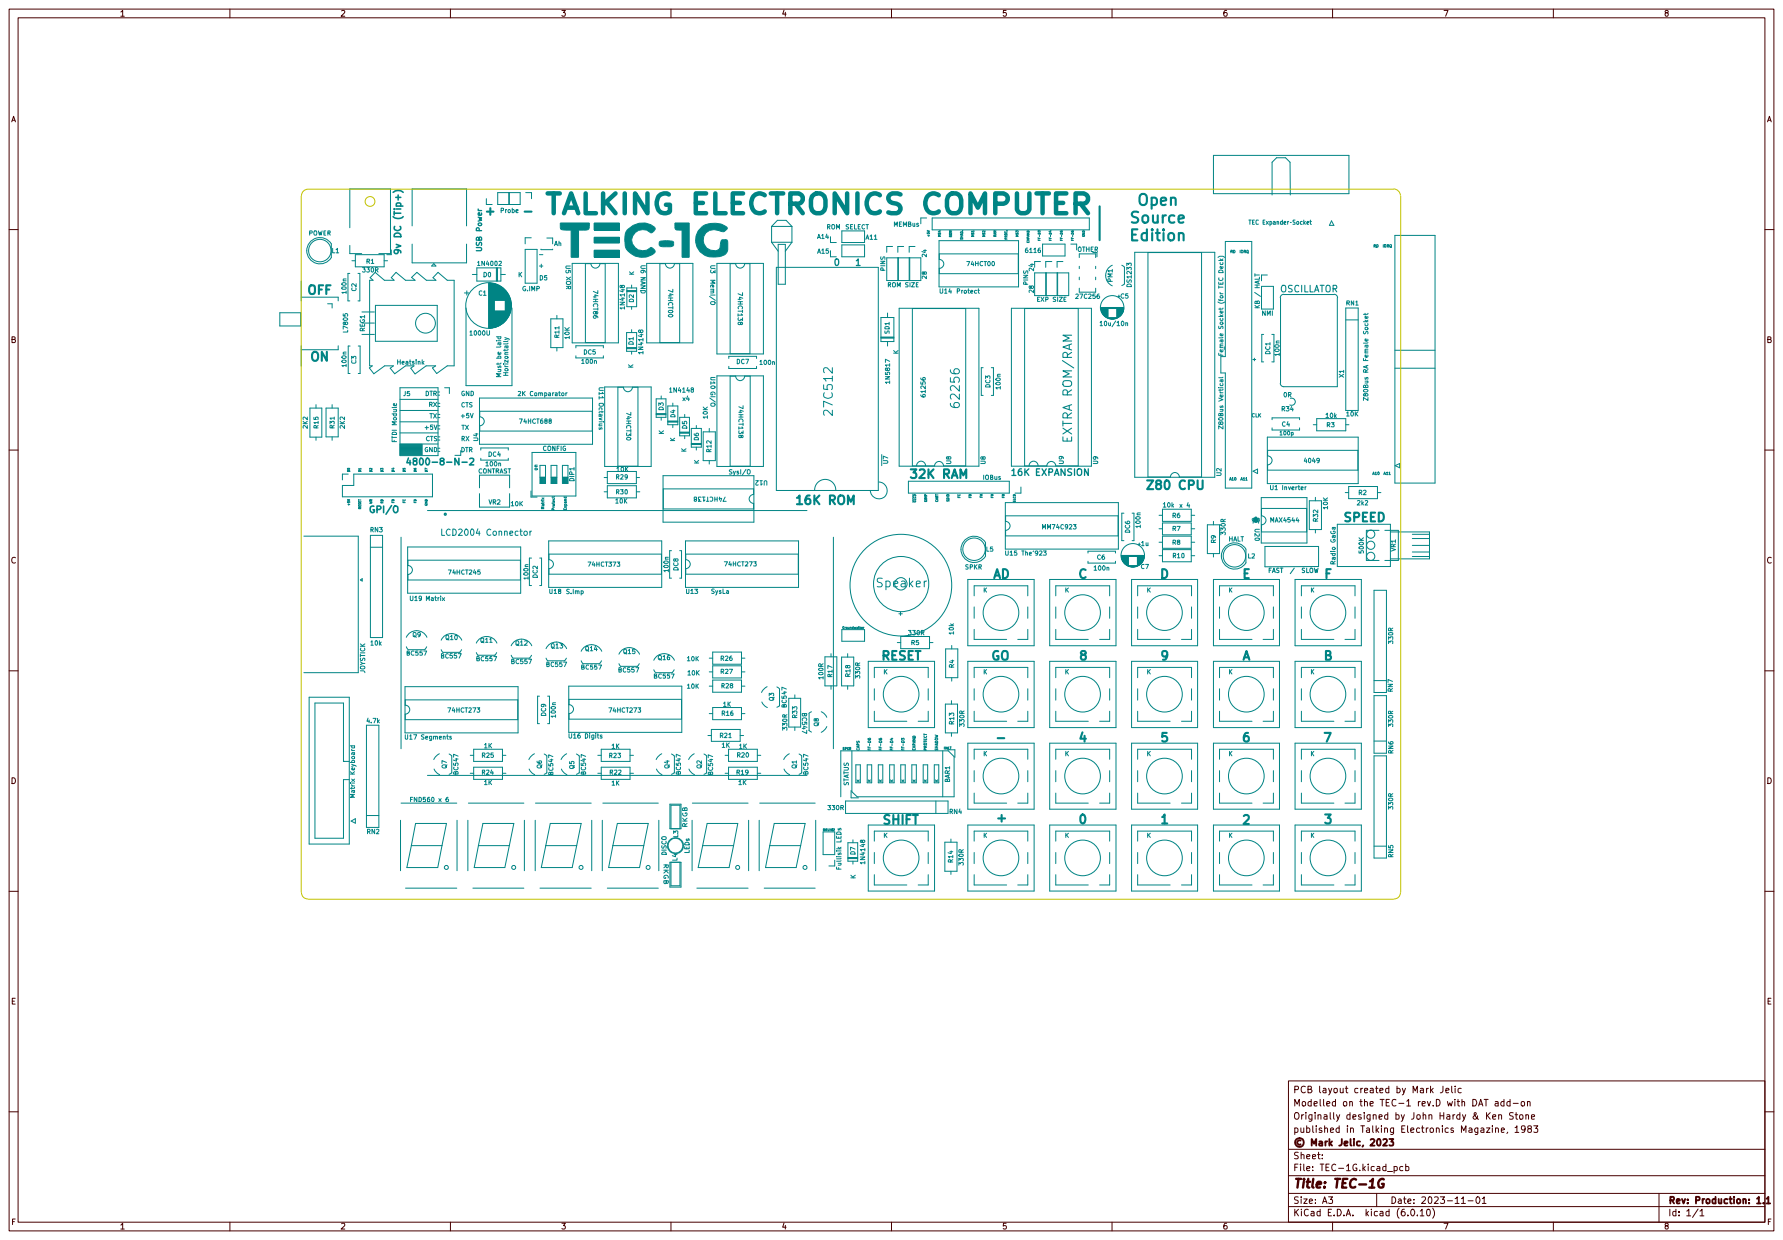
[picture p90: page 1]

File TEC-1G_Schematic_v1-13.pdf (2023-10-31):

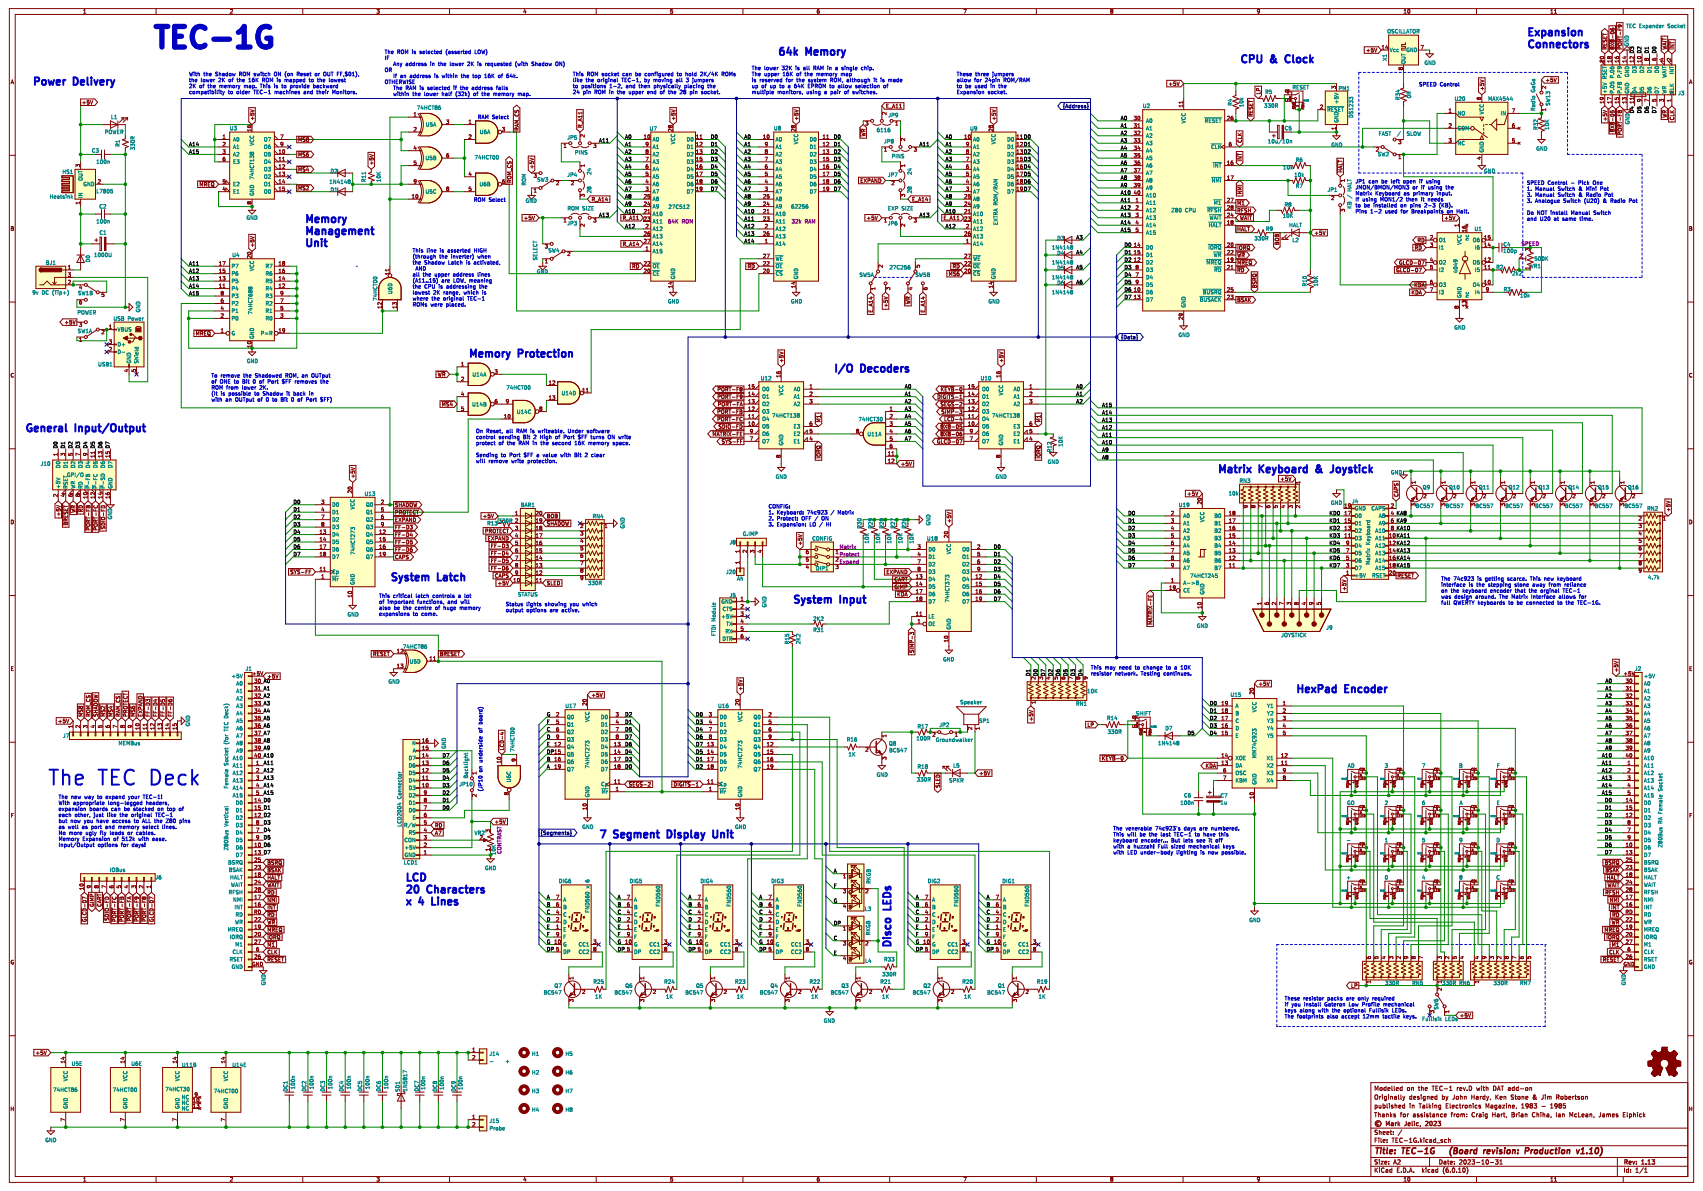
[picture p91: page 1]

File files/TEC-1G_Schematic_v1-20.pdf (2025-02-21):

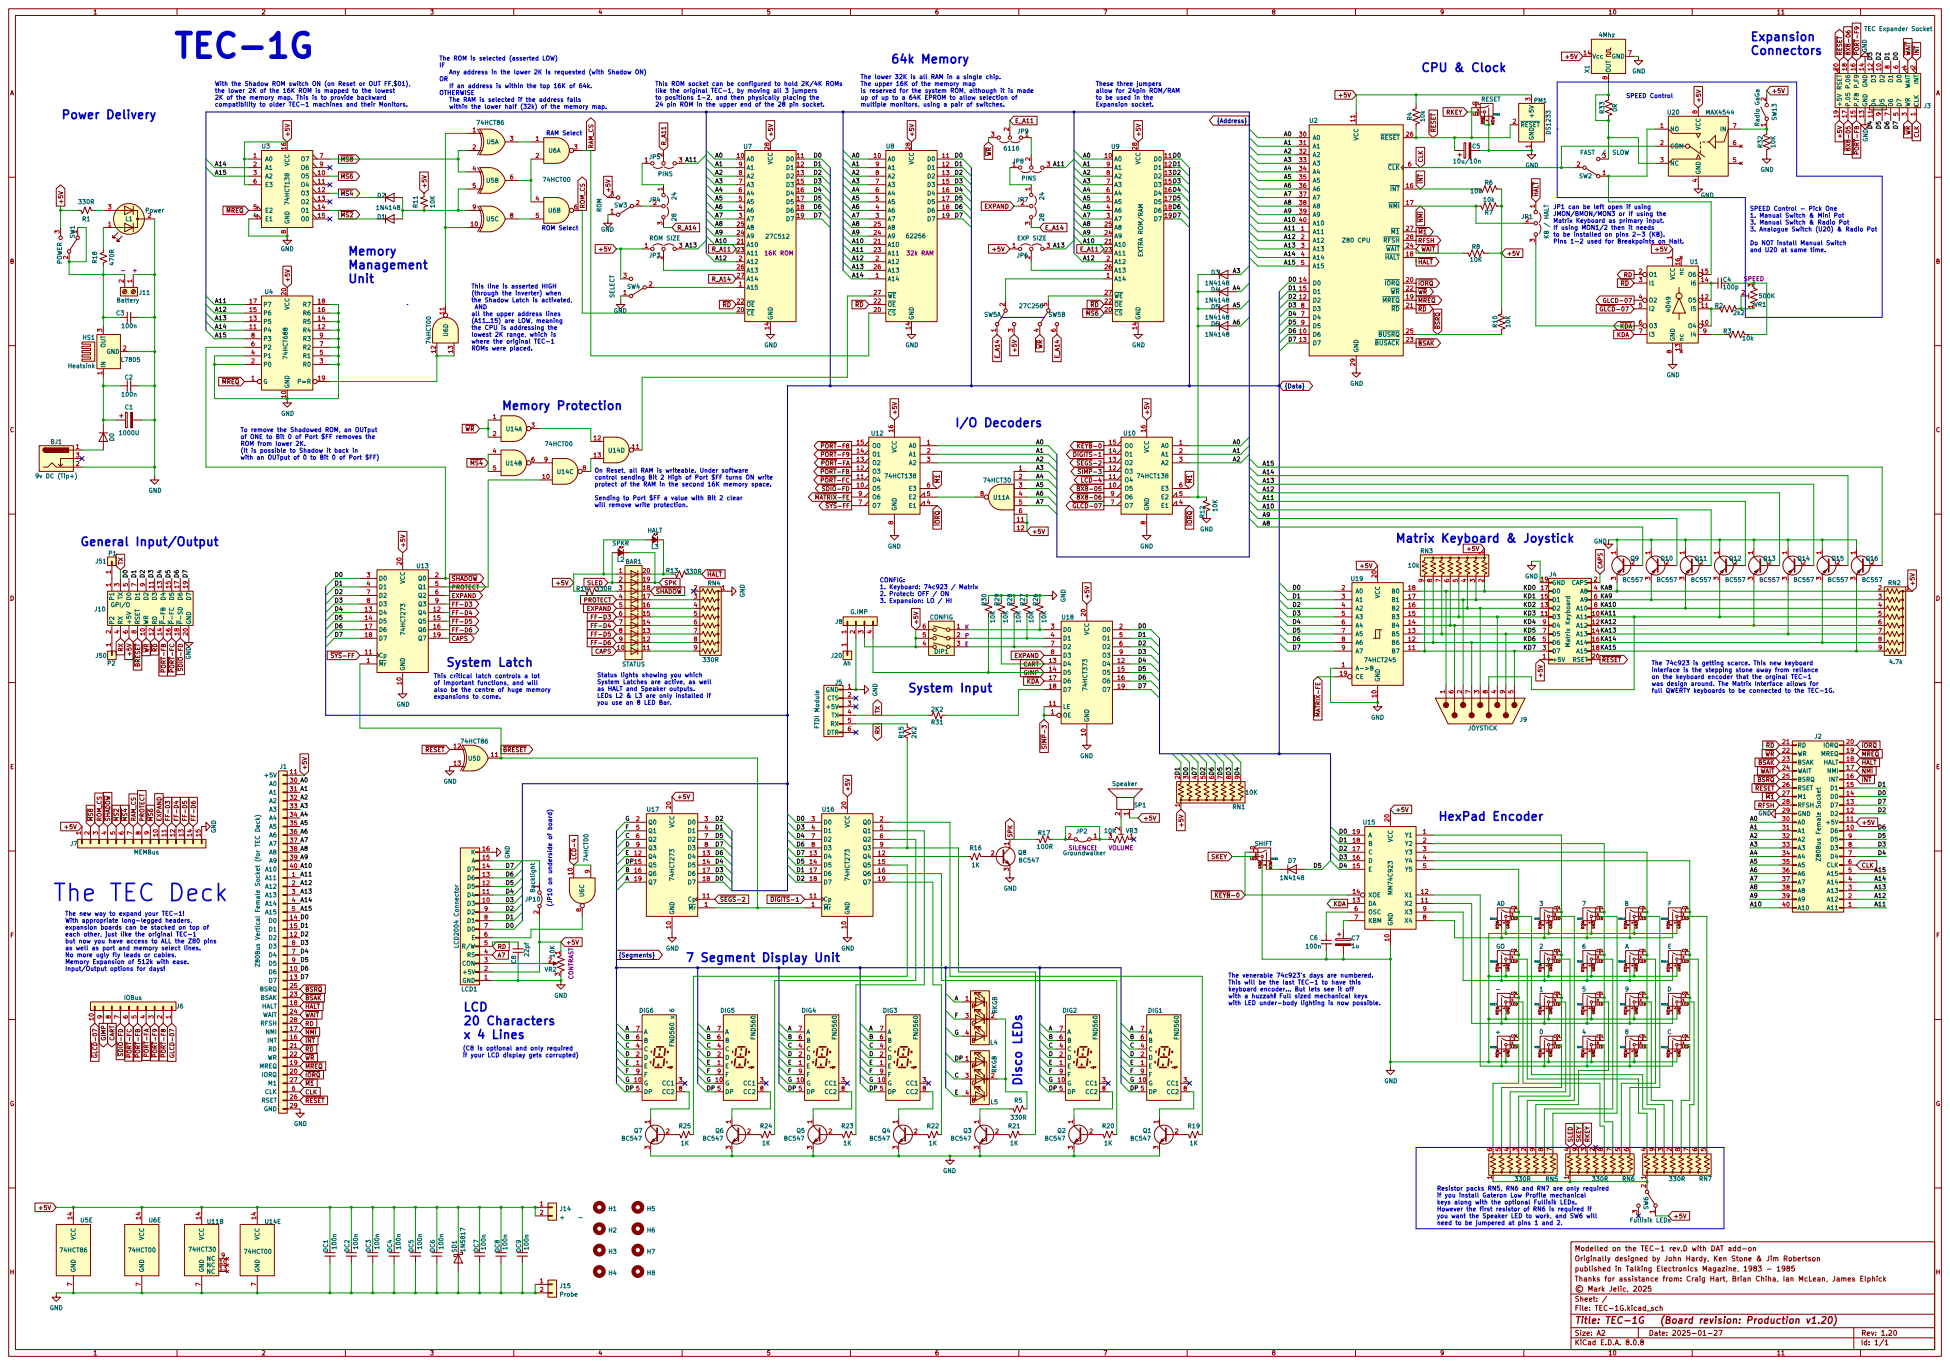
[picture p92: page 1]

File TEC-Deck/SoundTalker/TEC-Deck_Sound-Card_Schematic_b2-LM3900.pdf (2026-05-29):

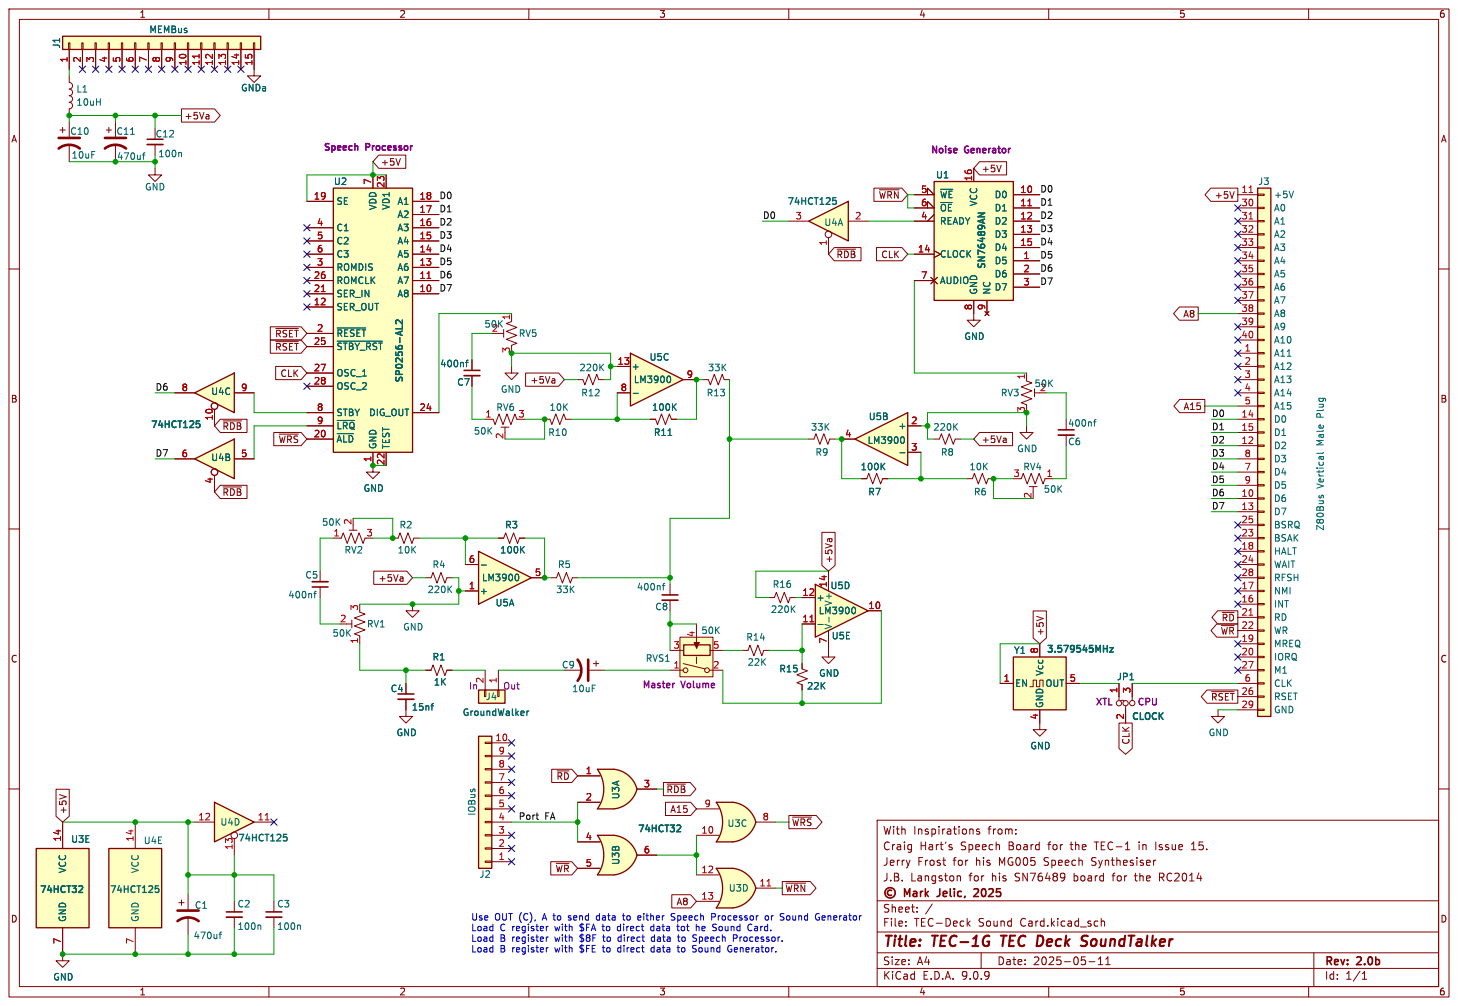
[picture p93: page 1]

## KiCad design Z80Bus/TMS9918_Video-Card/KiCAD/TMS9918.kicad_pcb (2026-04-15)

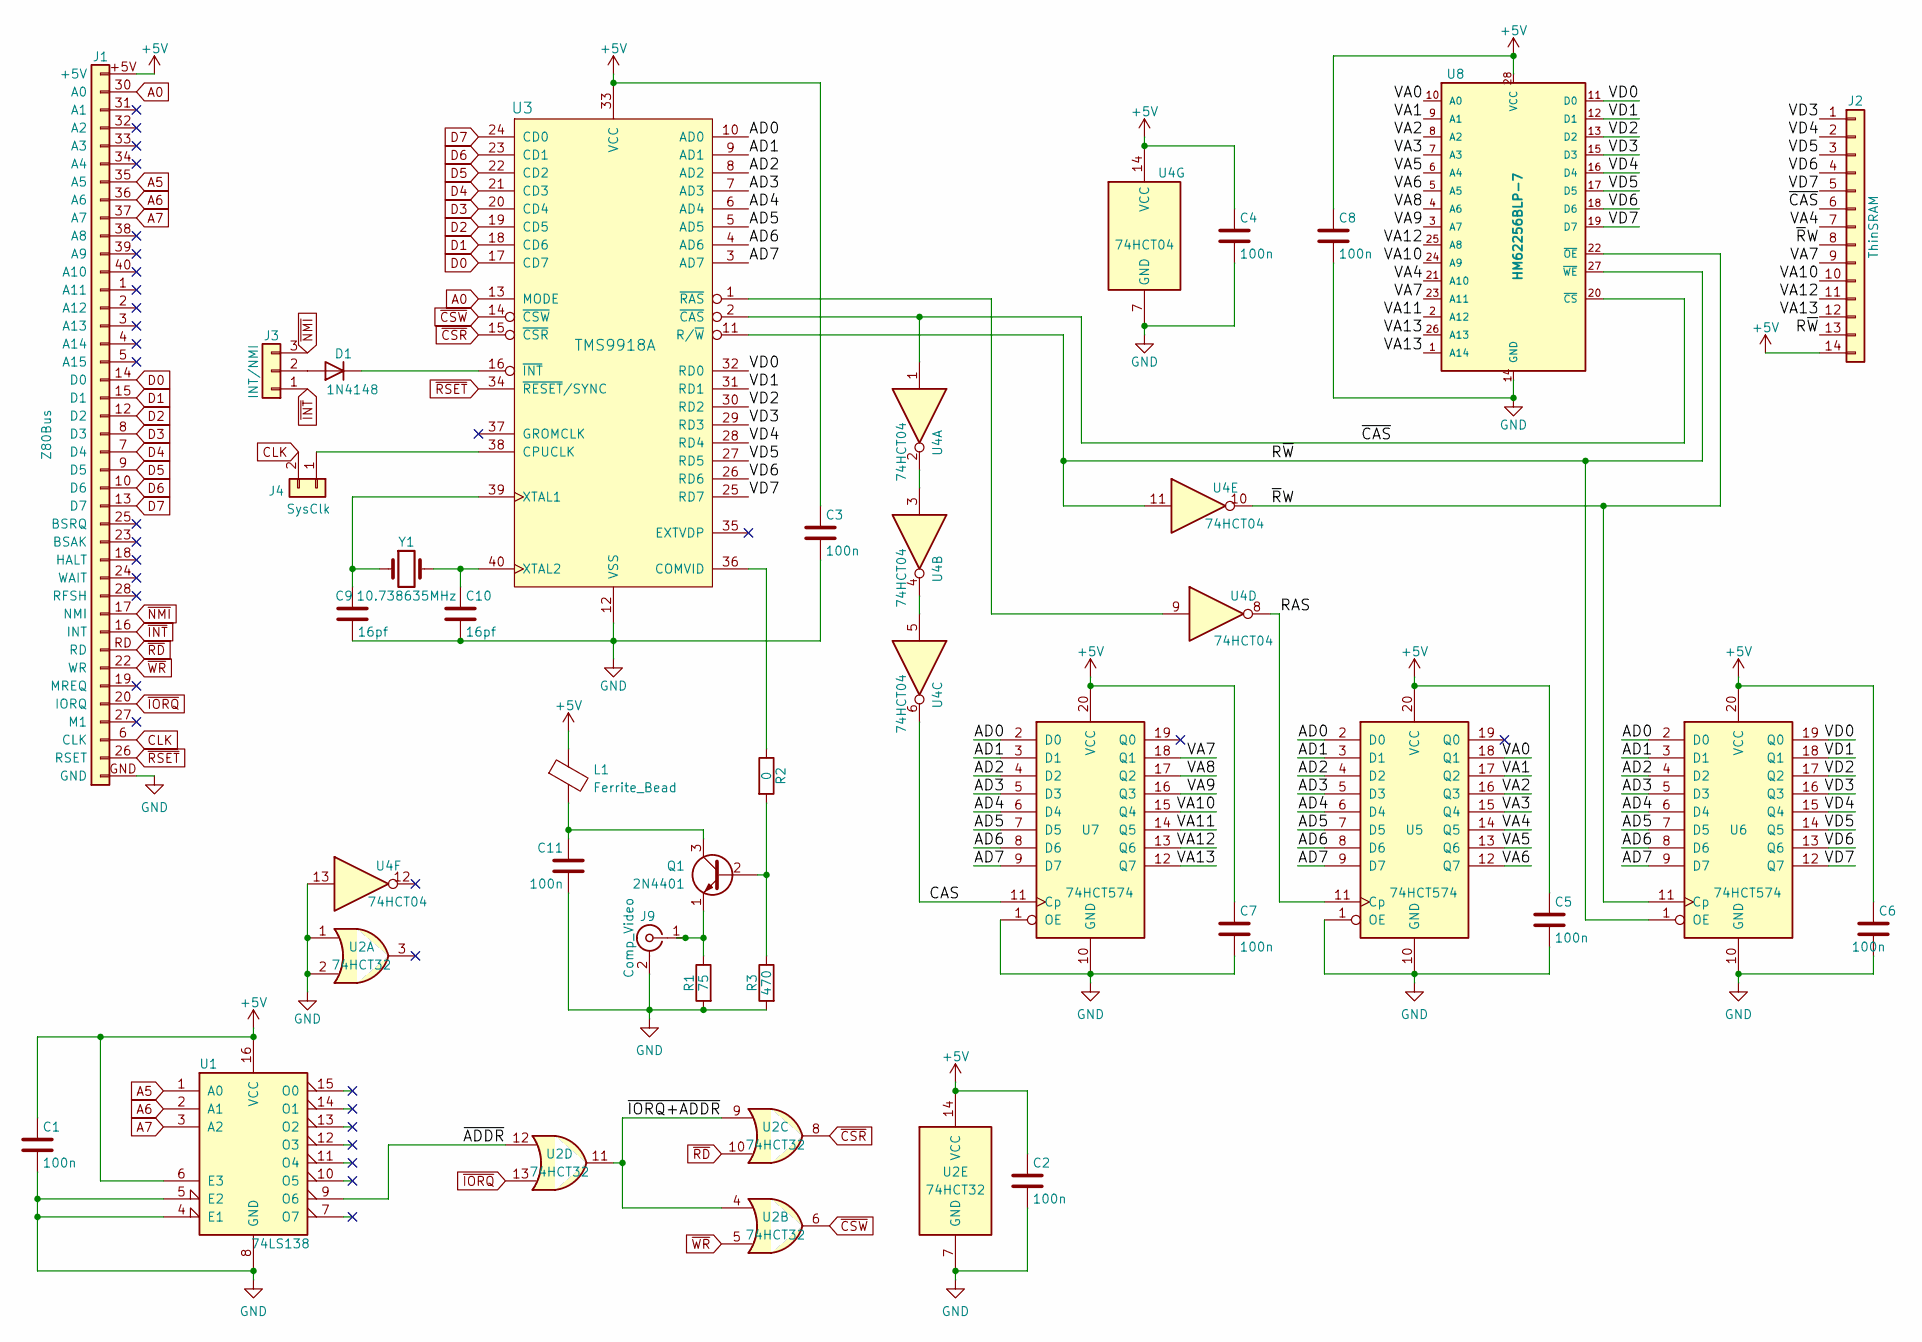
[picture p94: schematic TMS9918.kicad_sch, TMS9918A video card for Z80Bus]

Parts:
C1, C2, C3, C4, C5, C6, C7, C8, C11: 100n; C_Disc_D4.3mm_W1.9mm_P5.00mm
C9, C10: 16pf; C_Disc_D3.0mm_W1.6mm_P2.50mm
D1: 1N4148; D_DO-35_SOD27_P7.62mm_Horizontal
J1: Z80Bus; Z80Bus-Header_V+H_Plug
J2: ThinSRAM; PinHeader_1x14_P2.54mm_Vertical
J3: INT/NMI; PinHeader_1x03_P2.54mm_Vertical
J4: SysClk; PinHeader_1x02_P2.54mm_Vertical
J9: Comp_Video; RCA_Jack_RA
L1: Ferrite_Bead; R_Axial_DIN0207_L6.3mm_D2.5mm_P7.62mm_Horizontal
Q1: 2N4401; TO-92
R1: 75; R_Axial_DIN0207_L6.3mm_D2.5mm_P7.62mm_Horizontal
R2: 0; R_Axial_DIN0207_L6.3mm_D2.5mm_P7.62mm_Horizontal
R3: 470; R_Axial_DIN0207_L6.3mm_D2.5mm_P7.62mm_Horizontal
U1: 74LS138; DIP-16_W7.62mm_LongPads
U2: 74HCT32; DIP-14_W7.62mm_LongPads
U3: TMS9918A; DIP-40_W15.24mm_LongPads
U4: 74HCT04; DIP-14_W7.62mm_LongPads
U5, U6, U7: 74HCT574; DIP-20_W7.62mm_LongPads
U8: HM62256BLP-7; DIP-28_W15.24mm_LongPads
Y1: 10.738635MHz; Crystal_HC49-4H_Vertical

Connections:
+5V: C1.1, C2.1, C3.1, C4.1, C5.1, C6.1, C7.1, C8.1, J1.+5V, J2.14, L1.1, U1.6 (E3), U1.16 (VCC), U2.14 (VCC), U3.33 (VCC), U4.14 (VCC), U5.20 (VCC), U6.20 (VCC), U7.20 (VCC), U8.28 (VCC)
/AD0: U3.10 (AD0), U5.2 (D0), U6.2 (D0), U7.2 (D0)
/AD1: U3.9 (AD1), U5.3 (D1), U6.3 (D1), U7.3 (D1)
/AD2: U3.8 (AD2), U5.4 (D2), U6.4 (D2), U7.4 (D2)
/AD3: U3.7 (AD3), U5.5 (D3), U6.5 (D3), U7.5 (D3)
/AD4: U3.6 (AD4), U5.6 (D4), U6.6 (D4), U7.6 (D4)
/AD5: U3.5 (AD5), U5.7 (D5), U6.7 (D5), U7.7 (D5)
/AD6: U3.4 (AD6), U5.8 (D6), U6.8 (D6), U7.8 (D6)
/AD7: U3.3 (AD7), U5.9 (D7), U6.9 (D7), U7.9 (D7)
/CAS: U4.6, U7.11 (Cp)
/RAS: U4.8, U5.11 (Cp)
/R~W: J2.13, U3.11 (R/~W), U4.11, U6.1 (OE), U8.27 (~WE)
/VA0: U5.18 (Q1), U8.10 (A0)
/VA1: U5.17 (Q2), U8.9 (A1)
/VA2: U5.16 (Q3), U8.8 (A2)
/VA3: U5.15 (Q4), U8.7 (A3)
/VA4: J2.7, U5.14 (Q5), U8.21 (A10)
/VA5: U5.13 (Q6), U8.6 (A4)
/VA6: U5.12 (Q7), U8.5 (A5)
/VA7: J2.9, U7.18 (Q1), U8.23 (A11)
/VA8: U7.17 (Q2), U8.4 (A6)
/VA9: U7.16 (Q3), U8.3 (A7)
/VA10: J2.10, U7.15 (Q4), U8.24 (A9)
/VA11: U7.14 (Q5), U8.2 (A12)
/VA12: J2.11, U7.13 (Q6), U8.25 (A8)
/VA13: J2.12, U7.12 (Q7), U8.1 (A14), U8.26 (A13)
/VD0: U3.32 (RD0), U6.19 (Q0), U8.11 (D0)
/VD1: U3.31 (RD1), U6.18 (Q1), U8.12 (D1)
/VD2: U3.30 (RD2), U6.17 (Q2), U8.13 (D2)
/VD3: J2.1, U3.29 (RD3), U6.16 (Q3), U8.15 (D3)
/VD4: J2.2, U3.28 (RD4), U6.15 (Q4), U8.16 (D4)
/VD5: J2.3, U3.27 (RD5), U6.14 (Q5), U8.17 (D5)
/VD6: J2.4, U3.26 (RD6), U6.13 (Q6), U8.18 (D6)
/VD7: J2.5, U3.25 (RD7), U6.12 (Q7), U8.19 (D7)
/~ADDR: U1.9 (O6), U2.12
/~CAS: J2.6, U3.2 (~CAS), U4.1, U8.20 (~CS)
/~IORQ+ADDR: U2.4, U2.9, U2.11
/~RW: J2.8, U4.10, U6.11 (Cp), U8.22 (~OE)
A0: J1.30 (A0), U3.13 (MODE)
A5: J1.35 (A5), U1.1 (A0)
A6: J1.36 (A6), U1.2 (A1)
A7: J1.37 (A7), U1.3 (A2)
CLK: J1.6 (CLK), J4.2
D0: J1.14 (D0), U3.17 (CD7)
D1: J1.15 (D1), U3.18 (CD6)
D2: J1.12 (D2), U3.19 (CD5)
D3: J1.8 (D3), U3.20 (CD4)
D4: J1.7 (D4), U3.21 (CD3)
D5: J1.9 (D5), U3.22 (CD2)
D6: J1.10 (D6), U3.23 (CD1)
D7: J1.13 (D7), U3.24 (CD0)
GND: C1.2, C2.2, C3.2, C4.2, C5.2, C6.2, C7.2, C8.2, C9.2, C10.2, C11.2, J1.GND, J9.2 (Ext), R1.2, R3.2, U1.4 (E1), U1.5 (E2), U1.8 (GND), U2.1, U2.2, U2.7 (GND), U3.12 (VSS), U4.7 (GND), U4.13, U5.1 (OE), U5.10 (GND), U6.10 (GND), U7.1 (OE), U7.10 (GND), U8.14 (GND)
unnamed: C9.1, U3.39 (XTAL1), Y1.1
unnamed: C10.1, U3.40 (XTAL2), Y1.2
unnamed: C11.1, L1.2, Q1.3 (C)
unnamed: D1.1 (K), U3.16 (~INT)
unnamed: D1.2 (A), J3.2
unnamed: J4.1, U3.38 (CPUCLK)
unnamed: J9.1 (In), Q1.1 (E), R1.1
unnamed: Q1.2 (B), R2.2, R3.1
unnamed: R2.1, U3.36 (COMVID)
unnamed: U3.1 (~RAS), U4.9
unnamed: U4.2, U4.3
unnamed: U4.4, U4.5
~CSR: U2.8, U3.15 (~CSR)
~CSW: U2.6, U3.14 (~CSW)
~INT: J1.16 (INT), J3.1
~IORQ: J1.20 (IORQ), U2.13
~NMI: J1.17 (NMI), J3.3
~RD: J1.RD, U2.10
~RSET: J1.26 (RSET), U3.34 (~RESET/SYNC)
~WR: J1.22 (WR), U2.5

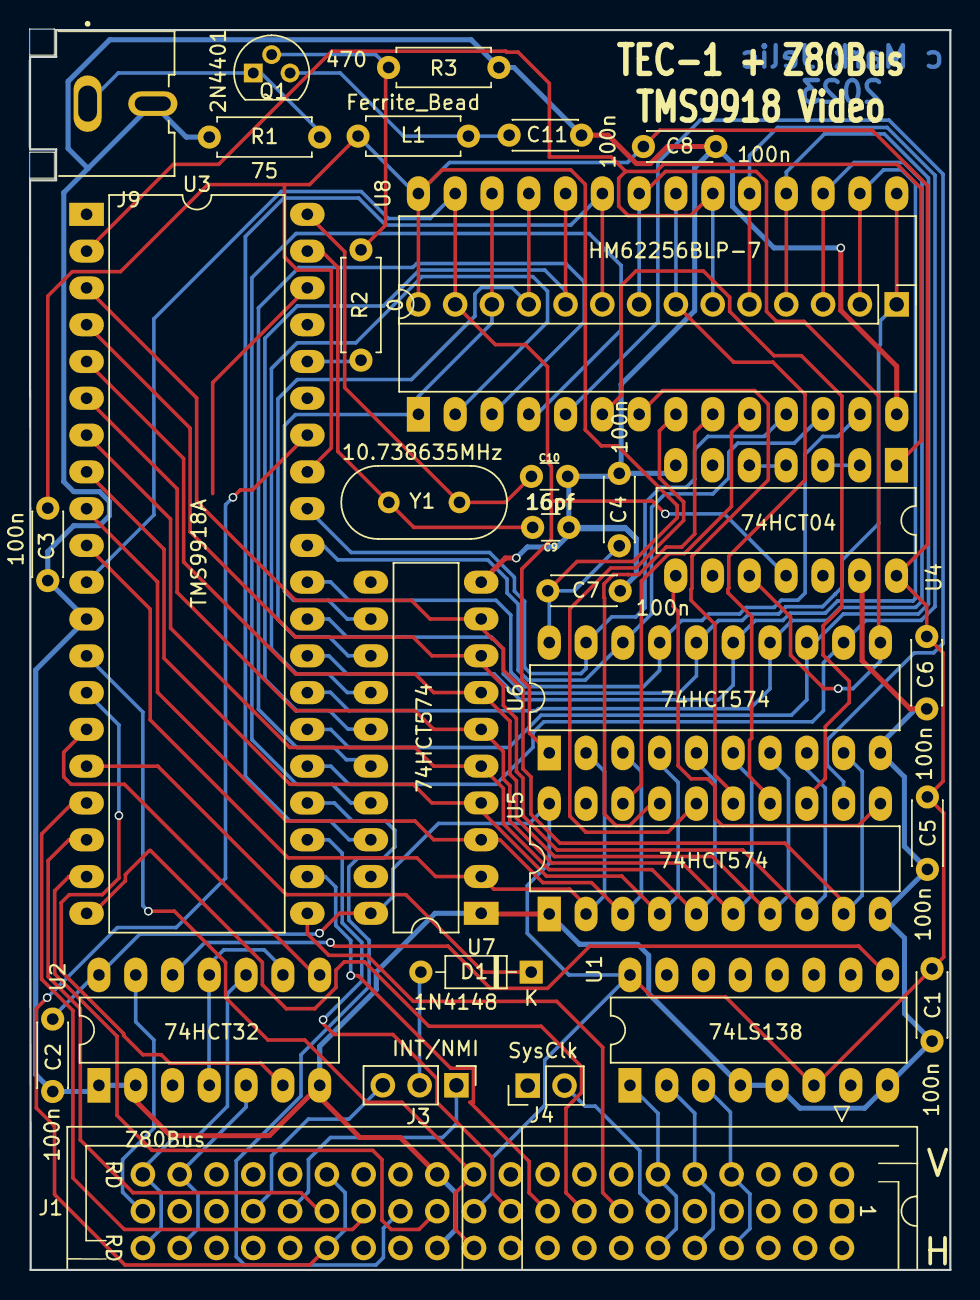
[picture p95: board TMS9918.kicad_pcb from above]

Board: 2 copper layers, 63.5 x 85.6 mm, 31 parts (0 on the bottom side), 72 nets.

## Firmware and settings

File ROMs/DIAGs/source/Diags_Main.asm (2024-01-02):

; ----------------------------------------------------------------------------
;	TEC-1G Diagnostics
;
;	Copyright (C) 2023, Craig Hart. Distributed under the GPLv3 license
;
;	This portion of the code runs from C300h. Shadow is disabled partway
; ----------------------------------------------------------------------------

#include "Diags_includes.asm"
#include "Diags_shadow.asm"

	.ORG HIROM+HIBASE

; program counter display

	call savesp		; save PC for later (not really a call)

savesp:	ld a,(SEGMNT+9)		; High ROM jump passed - Checkpoint 9
	out (SEGS),a

	ld c,lcdCls		; clear the LCD
	call lcdCommand

	ld hl,pcmsg		; display program counter msg
	call lcdStr

	pop bc			; recover PC from earlier 'call'
	ld hl,pcBuff
	call wordToBuff
	ld hl,pcBuff
	call lcdStr

	call delay

; OK done with POST codes now - tun off 7seg

	xor a			; clear 7-seg
	out (SEGS),a

; check config register test

	ld c,lcdRow2
	call lcdCommand
	call readCfgReg

; setup defaults as selected from the config register

	in a,(SIMP3)		; set extend desired default
	and EXPAND
	ld (cfgMode),a
	out (SYSCTRL),a

; turn off shadowing test

	ld c,lcdRow3
	call lcdCommand
	ld hl,shad		; display the name of this test
	call lcdStr

	di			; no interupts while we do critical things
	ld a,(cfgMode)		; shadow off command to port ffh
	or SHADOW		; set shadow off
	ld (cfgMode),a
	out (SYSCTRL),a

; store all FF's on purpose
	ld hl,0000h
	ld de,0001h
	ld bc,00ffh		; n-1
	ld a,0ffh
	ld (hl),a
	ldir			; fill first 100h bytes with FF

; we verify this is RAM first, by reading it back and verifing the result

	ld ix,0000h
	ld de,0100h
	call crc16

	ld de,5B2Fh		; ALL FF's  -> 5B2Fh

	or a			; HL (computed) == DE (expected)?
	sbc hl,de
	add hl,de
	jr z,copyBase

	halt			; shadow fail

; if we get here, shadow works theres realy ram there
; copy base 100h bytes - so the interrupt vectors work

copyBase:
	ld hl,0c000h		; copy bottom 256 bytes of ROM to RAM at 0000
	ld de,0000h
	ld bc,0100h
	ldir
	ei			; done with critical stuff

; now check it to make sure that worked

	ld ix,0c000h		; get CRC of ROM
	ld de,0100h
	call crc16
	ld (ROMCRC),hl

	ld ix,0000h		; get CRC of RAM - should match
	ld de,0100h
	call crc16
	ld (RAMCRC),hl

	ld de,(ROMCRC)

; 16-bit compare
; IF HL equals DE, Z=1,C=0
; IF HL is less than DE, Z=0,C=1
; IF HL is more than DE, Z=0,C=0

	or a			; HL (computed) == DE (expected)?
	sbc hl,de
	add hl,de

	ld hl,pass
	jr z,shres

	ld hl,fail

; did we pass or fail?

shres:	call lcdStr
	call delay

; write protection of RAM bank 1 check

	ld c,lcdRow4
	call lcdCommand
	call wrprot

; setup menu & system state

menuInit:
	xor a
	ld (menuPos),a		; menu draw from first slot
	ld (menuSel),a		; menu selected first item
	ld hl,menuTable
	ld (menuMenu),hl	; default menu
	ld (menuNest),a		; top level
	ld a,menuLen
	ld (menuLength),a
	ld hl,menutitle
	ld (menuTitl),hl

	ld (capsval),a		; capslock off


	ld a,40h
	ld (kState),a		; no HexPad key pressed

	ld a,0ffh
	ld (kFlag),a		; hexpad key not pressed
	ld (kdelayval),a	; matrix delay on keypress


; --------------------------------------------------
;
;  MAIN MENU
;
; --------------------------------------------------

menu:	ld c,lcdCls
	call lcdCommand

	ld hl,(menuTitl)
	call lcdStr

	call drawMenu
	call getKey

	and 1fh				; Mask off Shift
	bit 4,a				; ignore keys <10h
	jr z,menu

; work out which routine to go to

	sub 10h				; make it 0, 1, 2 or 3
	rla				; *2 - 2 bytes per entry

	ld hl,menu			; save RET address on stack
	push hl

	ld hl,menuJP
	ld b,0
	ld c,a
	add hl,bc

	ld a,(hl)			; look  up hl string location in the table
	inc hl
	ld h,(hl)
	ld l,a

	jp (hl)

menuJP:	.dw isPlus, isMinus, isGo, isAddr	; JP table

;------------

isPlus:
	ld a,(menuLength)
	ld b,a
	ld a,(menuSel)
	cp b				; at max already ?
	ret z				; if max, bail
	inc a				; otherwise update
	ld (menuSel),a			; save new selection
	ld c,a				; copy A to C
	ld a,(menuPos)			; get menu display position
	add a,03			; for coming up CP
	ld b,a				; b = menu pos
	ld a,c				; a = menu sel
	cp b				; if (b+3)>a then no change
	ret c				; return if >
	ld a,(menuPos)			; update menuPos
	inc a
	ld (menuPos),a
	ret

isMinus:
	ld a,(menuSel)			; get current
	dec a				; decrease by 1
	ret m				; if result <0, exit as we aready at top
	ld (menuSel),a			; save new position
	ld c,a				; store new pos in c
	ld a,(menuPos)			; do we need to scroll the list?
	ld b,a				; b = menu pos
	ld a,c				; a = sel pos
	cp b				; compare
	ret nc				; no action if in range
	ld (menuPos),a			; otherwise update menu pos
	ret

isGo:
	ld c,lcdCls			; setup LCD
	call lcdCommand
	ld c,lcdRow2
	call lcdCommand

	ld a,(menuSel)			; display selected test name
	ld hl,(menuMenu)
	call setMenuPtr
	call lcdStr

	ld e,c				; C => E for use in a moment
	ld c,lcdRow3			; select outpout row
	call lcdCommand

	ld hl,menuRet			; save RET address on stack
	push hl
	ld h,b				; BE => HL. That's not a typo
	ld l,e
	jp (hl)				; 'call' the routine

	halt				; should never run (returns to menu)

menuRet:
	call getKeyNoScan		; no beep if no key
	jp nz,menu

keyUp:	call getKeyNoScan		; wait for release
	jp z,keyUp
	call tone			; and beep
	jp menu


isAddr:
	ld a,(menuNest)
	cp 0
	ret z				; exit if already at top level

	ld hl,menutitle			; reset title
	ld (menuTitl),hl

	ld hl,(parentMenu)		; return to top level
	ld (menuMenu),hl

	ld a,(oldMenuLen)		; reset menu length
	ld (menuLength),a

	ld a,(oldMenuPos)
	ld (menuPos),a

	ld a,(oldMenuSel)
	ld (menuSel),a

	xor a
	ld (menuNest),a
	ret
	
; -----------------------------------
;  Draw the menu
; -----------------------------------

drawMenu:
	ld hl,menuLength		; setup B
	ld a,(hl)
	ld e,a
	inc e

	ld c,lcdRow2+1
	call lcdCommand
	ld a,(menuPos)
	cp e
	jr nc,putPtr

	ld hl,(menuMenu)
	call setMenuPtr
	call lcdStr

	ld c,lcdRow3+1
	call lcdCommand
	inc a
	cp e
	jr nc,putPtr
	ld hl,(menuMenu)
	call setMenuPtr
	call lcdStr

	ld c,lcdRow4+1
	call lcdCommand
	inc a
	cp e
	jr nc,putPtr
	ld hl,(menuMenu)
	call setMenuPtr
	call lcdStr

; position pointer

putPtr:	ld a,(menuPos)
	ld b,a
	ld a,(menuSel)
	sub b

; a = 0 , 1 or 2. Which row to put pointer ?
	jr nz,try3

	ld c,lcdRow2
	jr drawPointer

try3:	cp 1
	jr nz,try4

	ld c,lcdRow3
	jr drawPointer

try4:	ld c,lcdRow4

drawPointer:
	call lcdCommand

	call lcdReady
	ld a,0a5h			; pointer ASCII code (square block)
	out (LCDDATA),a

	ret

; -----------------------------------------------------
; setMenuPtr
;  call:
; A: location in menu required
; HL: menu table (4 bytes per)
;  returns :
; BC: points to jp offset
; HL: points to start of menuTable Entry currently selected
; -----------------------------------------------------

setMenuPtr:
	push af
	push de

	add a,a				; a = a *4 because 4 bytes per entry
	add a,a
	add a,2				; + 2 to get the JP first

	ld d,0
	ld e,a
	add hl,de			; add offset to find the table position we need

	ld a,(hl)			; lookup bc jp location
	inc hl
	ld b,(hl)
	ld c,a

	dec hl				; go back 3 bytes
	dec hl
	dec hl

	ld a,(hl)			; look  up hl string location in the table
	inc hl
	ld h,(hl)
	ld l,a
	pop de
	pop af
	ret

; -----------------------------------------------------
; doGPIOMenu Sets up the GPIO sub-menu
; -----------------------------------------------------

doGPIOMenu:
	ld hl,GPIOtitle
	ld (menuTitl),hl

	ld hl,(menuMenu)
	ld (parentMenu),hl
	ld hl,GPIOMenu
	ld (menuMenu),hl

	ld a,(menuLength)
	ld (oldMenuLen),a

	ld a,GPIOmenuLen
	ld (menuLength),a

	ld a,(menuPos)
	ld (oldMenuPos),a
	ld a,(menuSel)
	ld (oldMenuSel),a
	xor a
	ld (menuPos),a		; menu draw from first slot
	ld (menuSel),a		; menu selected first item

	inc a
	ld (menuNest),a		; not top level

	ret

; -----------------------------------------------------
;  LCD stuff
; -----------------------------------------------------

lcdTest:
	ld c,01
	call lcdCommand
	ld a,20h
	
lcdLoop1:
	call lcdFillChar		; cycle chars demo
	call lcdDelay
	inc a
	cp 80h
	jr nz, lcdLoop1

	ld a,0ffh		; solid block
	call lcdFillChar
	call delay

; ------
	ld c,40h		; load custom characters
	call lcdCommand

	ld b,8*8
	ld hl,lcdCustom
fillCustom:
	call lcdReady
	ld a,(hl)
	out (LCDDATA),a
	inc hl
	djnz fillCustom

	ld c,01			; draw custom screen demo
	call lcdCommand
	ld hl,lcdText
	call lcdFillBuff
	call delay
; ----
	ld b,08			; how many times

lcdAnimSq:
	ld a,0dbh		; open squares
	ld c,80h
	call lcdChar
	ld c,93h
	call lcdChar
	ld c,0d4h
	call lcdChar
	ld c,0e7h
	call lcdChar
	call lcdDelay
	call lcdDelay

	ld a,0a5h		; closed squares
	ld c,80h
	call lcdChar
	ld c,93h
	call lcdChar
	ld c,0d4h
	call lcdChar
	ld c,0e7h
	call lcdChar
	call lcdDelay
	call lcdDelay

	djnz lcdAnimSq
	call delay
; -----
	ld a,20h		; wipe effect
	ld b,40
	ld d,80h
	ld e,0e7h

wipeLoop:
	ld c,d
	call lcdChar
	ld c,e
	call lcdChar
	inc d
	dec e
	call lcdDelay
	djnz wipeLoop
	ret

; ------
lcdDelay:
	push bc
	ld c,060h
lcdDly2:
	ld b,0ffh
lcdDly:	djnz lcdDly
	dec c
	jr nz, lcdDly2
	pop bc
	ret
; ------
lcdChar:
	call lcdCommand
	call lcdReady
	out (LCDDATA),a
	ret	
; ------
lcdFillChar:
	ld b,40			; how many bytes
	ld c,80h		; postion memory
	call lcdCommand
	call lcdFill1

	ld b,40			; how many bytes
	ld c,0C0h		; postion memory
	call lcdCommand

lcdFill1:
	call lcdReady
	out (LCDDATA),a
	djnz lcdFill1
	ret
;------
lcdFillBuff:
	ld b,40
	ld c,80h		; postion memory
	call lcdCommand
	call lcdFill2

	ld b,40
	ld c,0C0h		; postion memory
	call lcdCommand

lcdFill2:
	call lcdReady
	ld a,(hl)
	out (LCDDATA),a
	inc hl
	djnz lcdFill2
	ret

; -----------------------------------------------------
;  do diag BAR LEDs actions
; -----------------------------------------------------

ledBar:
	ld b,03h		; do 3 full cycles

plp:	ld c,01h
	ld d,0a1h		; for lcd

stlp:	ld a,c			; send it up
	xor 1
	out (SYSCTRL),a
	call updateLcdBar
	call barDly
	call barDly
	sla c
	dec d
	jr nc, stlp
	ld c,40h
	ld d,09bh

strp:	ld a,c			; send it down
	xor 1
	out (SYSCTRL),a
	call updateLcdBar
	call barDly
	call barDly
	srl c
	inc d
	ld a,c
	cp 01h
	jr nz,strp

	djnz plp		; next full cycle

	xor 1
	out (SYSCTRL),a		; final segment to light
	call updateLcdBar
	call barDly
	call barDly

	ld a,(cfgMode)		; reset to normal
	out (SYSCTRL),a
	ret

barDly:	push af
	push de
	ld de,BDELAY

bDly:	dec de
	ld a,d
	or e
	jr nz,bDly
	pop de
	pop af
	ret

;------
updateLcdBar:
	push af
	push bc
	ld c,099h
	call lcdCommand
	ld hl,barText
	call lcdStr
	ld c,d
	call lcdCommand
	call lcdReady
	ld a,0ffh
	out (LCDDATA),a
	pop bc
	pop af
	ret

; -----------------------------------------------------
;  do some 7-seg scrolling text stuff
; -----------------------------------------------------

segs:	xor a			; setup starting location
	ld (segptr),a


scrol:	ld hl,SCRSEG		; set message location

	ld a,(segptr)		; add start char offset
	ld c,a
	ld b,0
	add hl,bc

	ld de,segbuf		; load display buffer
	ld bc,6			; 6 bytes
	ldir

	ld de,0100h		; how many scans / how long

scllp2:	call scan7Seg		; light the segs
	dec de
	ld a,d
	or e
	jr nz, scllp2

	ld a,(segptr)		; 'scroll' the message
	inc a
	ld (segptr),a
	cp 016h			; message done ?
	jr nz, scrol
	ret

; -----------------------------------------------------
;  do 7-seg lamp test
; -----------------------------------------------------

segs2:	ld a,0ffh		; load display buffer all on
	ld hl,segbuf
	ld b,6

sfill1:	ld (hl),a
	inc hl
	djnz sfill1

	ld hl,burnScan
	call lcdStr

	ld de,0600h		; how many scans / how long

scllp3:	call scan7Seg

	dec de
	ld a,d
	or e
	jr nz, scllp3

	ld a,00h		; load display buffer all off
	ld hl,segbuf
	ld b,6

sfill2:	ld (hl),a
	inc hl
	djnz sfill2

	ld c,lcdRow3
	call lcdCommand
	ld hl,blankString
	call lcdStr

	ld de,0200h		; how many scans / how long

scllp1:	call scan7Seg

	dec de
	ld a,d
	or e
	jr nz, scllp1

	ld c,lcdRow3
	call lcdCommand
	ld hl,burnLatch
	call lcdStr

; hard on

	ld a,03fh
	out (DIGITS),a

	ld a,0ffh
	out (SEGS),a

	call delay
	call delay

	xor a
	out (DIGITS),a
	out (SEGS),a

	ld c,lcdRow3
	call lcdCommand
	ld hl,blankString
	call lcdStr
	call delay
	ret

; ----------------------------------------------------------------
;  Bank 1 write protection test
; ----------------------------------------------------------------

; out: rTestResult: 0=pass, 1 = fail

wrprot:
	ld hl,wpchk		; test name
	call lcdStr

; 0 fill - needed to make sure initial ram contents is not conflicting junk

	ld a,01h
	out (SYSCTRL),a
	ld a,00h
	ld hl,RAMBL1
	ld (hl),a
	ld de,RAMBL1+1
	ld bc,3FFFh		; 16k-1 byte
	ldir			; fill
	ld a,(cfgMode)		; return to normal
	out (SYSCTRL),a

; fill with 55h and read back

	ld hl,RAMBL1		; should be RW to begin with
	ld a,55h
	ld (rTestByte),a
	ld (rTestLoc),hl
	call rBlockTest
	ld a,(rTestResult)
	cp 1			; this test should pass. if 1, we failed
	jr z,wFail

	ld a,(cfgMode)		; PROTECT on
	or PROTECT
	out (SYSCTRL),a

; fill with aah and read back. Should return 00h == fail

	ld hl,RAMBL1		; should fail now
	ld a,0aah
	ld (rTestByte),a
	ld (rTestLoc),hl
	call rBlockTest
	ld a,(rTestResult)
	cp 1			; this test should fail. if 0, we failed
	jr nz,wFail

	ld hl,pass
	jr wpres

wFail:	ld hl,fail

wpres:	ld a,(cfgMode)		; return to normal
	out (SYSCTRL),a

	call lcdStr
	call delay
	ret

; ----------------------------------------------------------------
;  Read config register test
; ----------------------------------------------------------------

readCfgReg:
	ld hl,cfgst
	call lcdStr
	ld hl,cfgst2
	in a,(SIMP3)		; read CFG register
	call toAscii
	ld a,'h'		; put rest of string into RAM
	ld (hl),a
	inc hl
	ld a,0
	ld (hl),a
	ld hl,cfgst2
	call lcdStr
	call delay
	ret

; ----------------------------------------------------------------
;  Read general input bit test
; ----------------------------------------------------------------

readGinput:
	ld hl,ginpStr
	call lcdStr
	ld hl,lo
	in a,(SIMP3)		; read CFG register
	and 20h
	jr z,inpMsg
	ld hl,hi

inpMsg:	call lcdStr
	call delay
	ret

; ----------------------------------------------------------------
;  Test the speaker
; ----------------------------------------------------------------

speaker:
	call musicRoutine
	ret

; ----------------------------------------------------------------
;  Beep sounds
; no registers needed or altered
; ----------------------------------------------------------------

pip:	push af
	push bc
	push hl

	ld c,0c0h		; pitch
	ld l,021h		; length
	xor a
	jr tlp2

tone:
	push af
	push bc
	push hl

	ld c,0c0h		; pitch
	ld l,081h		; length
	xor a
tlp2:	out (DIGITS),a
	ld b,c
tone2:	djnz tone2
	xor 80h
	dec l
	jr nz,tlp2

	ld b,0ffh
dly2:	djnz dly2

	pop hl
	pop bc
	pop af
	ret

; ----------------------------------------------------------------
;  Burn in
; ----------------------------------------------------------------

burn:	ld hl,0000h
	ld (burnLoops),hl

; setup key to exit by vectoring NMI back to cold start
; burn in always runs with shadow disabled

	ld a,(cfgMode)		; shadow off
	or SHADOW
	out (SYSCTRL),a

	ld a,0c3h		; setup JP instr for NMI
	ld (0066h),a
	ld hl,0000h
	ld (067h),hl

bloop:	xor a
	ld (menuSel),a

bloopIn:
	call bfsh

	ld a,(menuSel)
	ld hl,burnTable
	call setMenuPtr

	ld a,h			; look for 0000 to end a pass
	or l
	jr z,blDone

	ld h,b
	ld l,c

	ld bc,bptr		; set return address on stack
	push bc
	jp (hl)			; this is really a call to the test


bptr:	ld hl,menuSel		; step through the tests
	inc (hl)
;	ld (menuSel),a
	jr bloopIn


blDone:	ld hl,(burnLoops)	; step through the loops (forever)
	inc hl
	ld (burnLoops),hl

	jr bloop



bfsh:	ld c,lcdCls		; clear the LCD
	call lcdCommand

	ld hl,burnst
	call lcdStr

	ld hl,pcBuff		; loop counter display
	ld bc,(burnLoops)
	call wordToBuff

	dec hl			; mask off the 'h'
	xor a
	ld (hl),a

	ld hl,pcBuff
	call lcdStr

	ld c,lcdRow2
	call lcdCommand

	ld a,(menuSel)
	ld hl,burnTable
	Call setMenuPtr
	call lcdStr

	ld c,lcdRow3
	call lcdCommand

	ret

; ----------------------------------------------------------------
;  HexPad Check; shift-ADDR exits
; ----------------------------------------------------------------

hexPad:
	ld a,' '		; setup the blank line
	ld b,20
	ld hl,hexPadBuff

fLoop:	ld (hl),a
	inc hl
	djnz fLoop
	xor a
	ld (hl),a		; 21st byte null terminated

	ld c,lcdRow1
	call lcdCommand
	ld hl,hexExit
	call lcdStr

	ld c,lcdRow3
	call lcdCommand
	ld hl,hexMsg
	call lcdStr

	call getKey

	xor 20h			; flip bit 5
	cp 033h
	ret z

	ld e,a
	ld hl,pcBuff
	call toAscii

	xor a			; null terminate it
	ld (hl),a

	ld hl,pcBuff
	call lcdStr

	ld c,lcdRow4		; goto row 4 and blank it
	call lcdCommand

	ld hl,hexPadBuff
	call lcdStr

	ld c,lcdRow4
	call lcdCommand

	ld a,e
	bit 5,a
	jr z,noSh

	ld hl,fnMsg
	call lcdStr

noSh:	ld a,e
	and 01fh		; mask shift
	cp 10h
	jr c, notFunc

	sub 10h			; make it 0..3

	ld b,a			; multiply by 6
	sla a
	sla a
	add a,b
	add a,b

	ld c,a
	ld b,0

	ld hl,plusMsg		; find our string
	add hl,bc

	call lcdStr
	jp hexPad

notFunc:
	ld hl,cfgst2		; 0-F
	call toAscii
	ld (hl),0

	ld hl,cfgst2+1
	call lcdStr

	jp hexPad

; ----------------------------------------------------------------
;  FTDI Check; ESC or ADDR exits
; ----------------------------------------------------------------

FTDI:
	call setupBuff
	call buffToLcd
	ld a,40h
	out (DIGITS),a		; init serial
	ld a,44h
	out (SEGS),a		; disco blue = FTDI active

ftdiLoop:
	call rxByte		; FTDI in
	jr nc,outRx

	call getKeyNoScan	; HexPad Key ?
	jr nc, ftdiLoop		; ignore key held down
	jr z, hexKey		; process if key pressed

;including mtrix makes the serial too slow, and drops bits
;mat:	call KEYSCAN		; Matrix Key ?
;	ld a,e			; was there a keypress ?
;	cp 0ffh
;	jr z,ftdiLoop
;	cp 01bh			; exit if ESC pressed
;	ret z
;	call txByte		; send it

	jr ftdiLoop

hexKey:
	cp 13h			; exit if ADDR pressed
	ret z
	and 0fh			; convert to 0..F
	add a,90h
	daa
	adc a,40h
	daa
	call txByte		; send it
	jr ftdiLoop

outRx:	call buffAddChar
	call buffToLcd
	jr ftdiLoop


; ----------------------------------------------------------------
;  disco tests - non-interactive
; ----------------------------------------------------------------

disco:	ld b,8
	ld c,01h		; led segment
	ld d,03h		; how many full loops
	ld e,0			; string pointer 0..8..16..24

	ld a,40h
	out (DIGITS),a

disco1:
	push bc

	ld b,0			; setup string pointer
	ld c,e
	ld hl,red
	add hl,bc

	ld a,e			; move string pointer
	add a,8
	and 1fh
	ld e,a

	ld c,lcdRow3
	call lcdCommand
	call lcdStr

	pop bc

	ld a,c
	out (SEGS),a

	call barDly
	call barDly
	call barDly
	call barDly

	sla c
	djnz disco1

	ld c,01h
	ld b,8
	dec d
	jr nz,disco1

;-----------------

fadeIn:
	ld e,3

pwmRepeatLoop:
	xor a
	ld (rVal),a
	ld (gVal),a
	ld (bVal),a

	ld d,55h

pwmOuterLoop:
	call pwmDisco

	ld h,020h
shDely:	dec h
	jr nz, shDely

incDiscoValues:
	ld a,(rVal)
	inc a
	ld (rVal),a

	ld a,(gVal)
	inc a
	inc a
	ld (gVal),a

	ld a,(bVal)
	inc a
	inc a
	inc a
	ld (bVal),a

	dec d				; full range of brightness
	jr nz,pwmOuterLoop

	dec e				; repeat thw whole thing e times
	jr nz,pwmRepeatLoop

	xor a				; turn them off
	out (DIGITS),a
	out (SEGS),a
	ret

; ----------------------------------------------------------------
;  disco tests - interactive for user
; ----------------------------------------------------------------

discoInteractive:
	xor a
	out (SEGS),a
	ld (rVal),a
	ld (gVal),a
	ld (bVal),a
	ld a,40h
	out (DIGITS),a

	ld hl,discoInt
	call lcdStr

pwmInteractiveLoop:
	call pwmDisco
	call getKeyNoScan
	jr nz, pwmInteractiveLoop

	and 01fh
	cp 13h
	jr z,pwmInteractiveExit

	cp 7			; ignore unwanted keys
	jr nc,pwmInteractiveLoop
	cp 3
	jr z,pwmInteractiveLoop

	call pip		; key beep

	bit 2,a			; up?
	jr nz, upPwm

dnPwm:	ld d,0ffh		; + ff same as as - 1
	jr setHL

upPwm:	and 03h
	ld d,01h

setHL:	ld hl,rVal
	ld c,a
	ld b,0
	add hl,bc

updateVal:
	ld a,(hl)
	add a,d
	ld (hl),a

	ld hl,decimalBuff
	ld a,(rVal)
	call toAscii
	ld a,(gVal)
	call toAscii	
	ld a,(bVal)
	call toAscii

	ld hl,decimalBuff
	ld c,96h
	call digUpdate
	ld c,9bh
	call digUpdate
	ld c,0a1h
	call digUpdate

	jp pwmInteractiveLoop

pwmInteractiveExit:
	xor a
	out (DIGITS),a
	out (SEGS),a
	ret

digUpdate:
	call lcdCommand
	call lcdReady
	ld a,(hl)
	out (LCDDATA),a
	inc hl
	call lcdReady
	ld a,(hl)
	out (LCDDATA),a
	inc hl
	ret

;--------------------

pwmDisco:
	xor a
	out (SEGS),a
	ld a,40h
	out (DIGITS),a
	ld b,0ffh

pwmInnerLoop:
	ld c,0

setR:
	ld a,(rVal)
	cp b
	jr c,setG
	ld c,11h

setG:	ld a,(gVal)
	cp b
	jr c,setB
	ld a,c
	add a,22h
	ld c,a

setB:	ld a,(bVal)
	cp b
	jr c,setDisco
	ld a,c
	add a,44h
	ld c,a

setDisco:
	ld a,c
	out (SEGS),a
	djnz pwmInnerLoop
	ret

; ----------------------------------------------------------------
;  Matrix Keyboard Check; ESC or ADDR exits
; ----------------------------------------------------------------

matrix:
	ld c,0fh		; LCD cursor on + blink on
	call lcdCommand
	call setupBuff
	call buffToLcd

matrixLoop:
	call getKeyNoScan
	jr nz, ks
	cp 13h			; exit if ADDR pressed
	jr z,mExit

ks:	call KEYSCAN

	ld a,e			; was there a keypress ?
	cp 0ffh
	jr z,matrixLoop

	call pip

	cp 01bh			; ESC = quit
	jr z,mExit

	call buffAddChar
	call buffToLcd

	jp matrixLoop

mExit:
	ld c,0ch		; LCD Cursor off + blink off
	call lcdCommand
	ret

; ---------------------------------------------------------------------------

setupBuff:
	ld hl,tBuff
	ld b,tBuffSize
	ld a,20h
fillSpace:
	ld (hl),a
	inc hl
	djnz fillSpace
	xor a
	ld (tBuffPtr),a
	ret
;----
buffAddChar:
	cp 0dh			; enter
	jr z,enter
	cp 07h
	cp 07h			; bell
	jr z,ascii7
	cp 09h			; tab
	jr z,tab
	cp 7fh			; backspace
	jr z,bksp
	jr normalChar

;special characters handling here
; enter
enter:	ld a,(tBuffPtr)
	cp 20
	jr c,noScroll		; is row 4 already

	ld de,tBuff		; 4 => 3
	ld hl,tBuff+20
	ld bc,20
	ldir

	ld hl,tBuff+20		; blank out 4
	ld a,20h
	ld b,20
fillSpace2:
	ld (hl),a
	inc hl
	djnz fillSpace2

noScroll:
	ld a,20
	ld (tBuffPtr),a
	ret
; bell
ascii7:	call tone
	ret
; tab
tab:	ld a,20h
	call normalChar
	call normalChar
	call normalChar
	call normalChar
	ret
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

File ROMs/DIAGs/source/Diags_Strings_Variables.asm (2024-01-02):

; ----------------------------------------------------------------
; strings, constants
; ----------------------------------------------------------------

;		     12345678901234567890
pcmsg:		.db "Program Ctr: ",0
cfgst:		.db "Config Register: ",0
shad:		.db "Shadow ROM Off ",0
wpchk:		.db "Bank 1 WrProt ",0
ptst:		.db "Page Tst",0
ginpStr:	.db "INPUT bit : ",0
p0chk		.db "Page 0 :",0
p1chk		.db "Page 1 :",0
ram:		.db "RAM",0
rom:		.db "ROM or Empty",0
fail:		.db "Fail",0
pass:		.db "Pass",0
hi:		.db "High",0
lo:		.db "Low",0
hexMsg:		.db "Scan Code : ",0
hexExit:	.db " (Fn Addr to Exit)",0
ramMsg:		.db "RAM Found ",0
byteMsg:	.db " bytes   ",0		; extra padding for short strings
fnMsg:		.db "Fn ",0
plusMsg:	.db "Plus ",0
negMsg:		.db "Minus",0
goMsg:		.db "Go   ",0
addrMsg:	.db "Addr ",0
burnScan:	.db "Scanning",0
burnLatch:	.db "Latched ",0
menutitle:	.db "  Diags Main Menu",0
GPIOtitle:	.db "  GPIO Diags Menu",0
t1GMsg:		.db 0c6h,0c7h,0c3h,04h,28h,0e3h	; 7-seg hexbytes
segScr		.db "7-Seg Scroll",0
segLamp		.db "7-Seg Lamp Test",0
ledBt		.db "LED BAR Test",0
cfgReg		.db "Config Reg Value",0
gInp		.db "General Input Bit",0
bk1Wp		.db "Bank 1 WrProt Chk",0
spk		.db "Speaker Test",0
ramTst		.db "RAM Test",0
expTst		.db "EXPAND Page Test",0
togSh		.db "Toggle SHADOW",0
togPr		.db "Toggle PROTECT",0
togEx		.db "Toggle EXPAND",0
burnst:		.db "Burn-in Mode ",0
hex:		.db "HexPad Test",0
matrixScr	.db "Matrix Keypad Test",0
joyScr		.db "Joystick Port Test",0
diagVer		.db "Diags Version Info",0
ftdiScr		.db "FTDI Loopback Test",0
piCalc		.db "Calculate Pi ",0f7h,0
GPIOMenuStr	.db "=> GPIO Boards",0
GPIO8bit	.db "GPIO 8 bit I/O Test",0
GPIOClock	.db "GPIO RTC Test",0
GPIOSdCard	.db "GPIO SD Card Test",0
GLCDMenuStr	.db "GLCD Test",0
ex8msg		.db "8x8 Display Test",0
ftdiMsg		.db "FTDI Tx Rx Tests",0
discoMsg	.db "Disco LEDs Tests",0
discoMsg2	.db "Disco Interactive",0
discoInt:	.db "R=00 G=00h B=00h",0
red:		.db "Red    ",0			; R,G,B,blank strings must be in sequence
green:		.db "Green  ",0
blue:		.db "Blue   ",0
blankString:	.db "                   ",0	; must come after blue
lcdMsg:		.db "20x4 LCD Tests",0
barText:	.db "|76543210|",0

; 2 bytes ptr to string, 2 bytes ptr to routine to execute

menuTable:	.dw lcdMsg, lcdTest
		.dw segScr, segs, segLamp, segs2, discoMsg, disco, discoMsg2, discoInteractive	; outputs
		.dw ledBt, ledBar, ex8msg, ex8, spk, speaker			; outputs
		.dw cfgReg, readCfgReg, gInp, readGinput			; inputs
		.dw ramTst, ramFind, bk1Wp, wrprot, expTst, expandTest		; memory
		.dw togSh, tShadow, togPr, tProtect, togEx, tExpand		; system control
		.dw ftdiMsg, FTDI, ftdiScr, ftdiLoopback			; serial
		.dw hex, hexPad, matrixScr, matrix, joyScr, joy			; keyboard/joystick
		.dw piCalc, pi							; misc
		.dw GPIOMenuStr, doGPIOMenu					; GPIO peripherals
		.dw GLCDMenuStr, GLCDtest					; GLCD
		.dw burnst, burn, diagVer, diagsVer				; burnin & version

menuLen:	.equ (($-menuTable)/4)-1		; menu entries-1

GPIOMenu:	.dw GPIO8bit, GPIO8bitio
		.dw GPIOClock, clock
		.dw GPIOSdCard, sd_test
GPIOmenuLen:	.equ (($-GPIOMenu)/4)-1			; menu entries-1

burnTable:	.dw diagVer, diagsVer
		.dw lcdMsg, lcdTest
		.dw segScr, segs, segLamp, segs2, discoMsg, disco
		.dw ledBt, ledBar, ex8msg, ex8, spk, speaker
		.dw cfgReg, readCfgReg, gInp, readGinput
		.dw ramTst, ramFind, bk1Wp, wrprot, expTst, expandTest
		.dw ftdiScr, ftdiLoopback
		.dw piCalc, pi
		.dw 0000

pacTable:	.db 0feh,0feh,38h,38h,38h,38h,38h,38h		; T
		.db 0feh,0feh,0e0h,0f8h,0f8h,0e0h,0feh,0feh	; E
		.db 3ch,0feh,0eeh,0e0h,0e0h,0eeh,0feh,07ch	; C
		.db 00h,00h,00h,7eh,7eh,00h,00h,00h		; -
		.db 38h,78h,0f8h,38h,38h,38h,38h,38h		; 1
		.db 3ch,0feh,0e6h,0e0h,0eeh,0e6h,0feh,07ch	; G
		.db 0,0,0,0,0,0,0,0

lcdCustom:	.db 0,0,0,7,4,4,4,4	; topleft
		.db 0,0,0,1ch,4,4,4,4	; topright
		.db 4,4,4,7,0,0,0,0	; bottomleft
		.db 4,4,4,1ch,0,0,0,0	; bottomright
		.db 0,0,0,1fh,0,0,0,0	; horizontal
		.db 4,4,4,4,4,4,4,4	; vertical
		.db 0,0,1fh,0,1fh,0,0,0 ; 2 line horizontal
		.db 0,1fh,0,1fh,0,1fh,0,0 ; 3 line vertical


lcdText:	.db 0,4,4,4,4,4,4,6,6,7,7,6,6,4,4,4,4,4,4,1
		.db 5," TEC-1G Computer  ",5
		.db 5,"   Open Source!   ",5
		.db 2,4,4,4,4,4,4,6,6,7,7,6,6,4,4,4,4,4,4,3

; for GLCD

INIT_BASIC:
        .db      30H             ;8 Bit interface, basic instruction
        .db      0CH             ;display on, cursor & blink off
        .db      06H             ;cursor move to right ,no shift
        .db      01H             ;clear RAM
ROWS:   .db      80H,90H,88H,98H ;Text Row start position

; for RTC

days:		.db "Monday",0
		.db "Tuesday",0
		.db "Wednesday",0
		.db "Thursday",0
		.db "Friday",0
		.db "Saturday",0
		.db "Sunday",0
 
; for SD

spiCMD0:	.db 40h,0,0,0,0,95h		; reset			R1
spiCMD8:	.db 48h,0,0,1,0aah,87h		; send_if_cond		R7
spiCMD9:	.db 49h,0,0,1,0aah,87h		; send_CSD		R1
spiCMD10:	.db 4ah,0,0,0,0,1h		; send_CSD		R1
spiCMD55:	.db 77h,0,0,0,0,1		; APP_CMD		R1
spiACMD41:	.db 69h,40h,0,0,0,1		; send_OP_COND		R1
cmd8Str:	.db "CMD8: ",0
noCardStr:	.db "SD Card not Found",0
sdErrorStr:	.db "SD Card Error "
sdErrorStrNum:	.db "XX",0
megaBytes	.db "MB",0
cardTypeStr:	.db "SD Card type ",0


; ----------------------------------------------------------------
; RAM variables
; ----------------------------------------------------------------

	.ORG RAMST

pcBuff:		.block 6
cfgst2:		.block 4
segbuf:		.block 6
segptr:		.block 1
burnLoops:	.block 2
menuPos:	.block 1
menuSel:	.block 1
oldMenuPos:	.block 1
oldMenuSel:	.block 1
menuMenu:	.block 2
parentMenu	.block 2
menuNest:	.block 1
menuLength:	.block 1
oldMenuLen:	.block 1
menuTitl:	.block 2
RAMCRC:		.block 2
ROMCRC:		.block 2
ramst:		.block 2
ramtst:		.block 2
ramend:		.block 2
ramflag:	.block 1
decimalBuff:	.block 6
cfgMode:	.block 1
pageRam:	.block 1
hexPadBuff:	.block 21	; holds usr typing
kFlag:		.block 1	; FF = no key pressed
oldcaps:	.block 1
oldkey:		.block 1
capsval:	.block 1	; 1 = capslock on
kdelayval:	.block 1	; counter for delay betwen key repeats
kState:		.block 1
joyX:		.block 1
joyY:		.block 1
joyChar:	.block 1
e8x8Buff:	.block 8
scBit:		.block 1
scByte:		.block 1
tBuff:		.block 40
tBuffSize:	.equ $-tBuff
tBuffPtr:	.block 1
rVal:		.block 1
gVal:		.block 1
bVal:		.block 1

;	.ORG (($ + 0FH) & 0FFF0H) +1	; align to next 16 byte boundary +1 byte
; the rtest bytes need to be outside the tested block
; presently placing them here does that -- but its a hack

		.ORG (($ + 0FFH) & 0FF00H) + RTBLK

rTestLoc:	.block 2
rTestByte:	.block 1
rTestResult:	.block 1
rTestBuff:	.block RTBLK
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

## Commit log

2023-08-24 Added bus pinouts per schematic rev: 1.6
2023-09-24 New verison of Schematic
    - Added "Groundwalker" jumper for Speaker SILENCE!
    - Fixed decoding switches around EXPANSION socket.
2023-10-23 update GLCD gerber
2023-11-01 Gerber WITHOUT the flood fills.
    No difference between v1.10, other than the GND (back) and the +5v (front) floods have been removed.
2023-11-01 Photos of Trace Cut Locations
    Photos showing the 6 locations of the cuts required to the traces on the PCB.
2023-11-03 Assembly - Fullisik Keyboard
2023-11-04 Assembly Instructions Added
2023-11-13 First draft of Power Delivery instructions
    First draft of Power Delivery instructions
2023-11-14 Add power_delivery_schematic
2023-12-14 PCBWay Sponsorship
2024-01-23 Update and rename JamesE_TEC-1G-Stands_v10.step to JamesE_TEC-1G-Stands_v1.step
    [JamesE_TEC-1G-Stands_v1.step]
2024-01-29 Tactile matrix keyboard frame
    [Tactile_Kbd_Frame.stl]
2024-05-05 FTDI Module - Defaults to 3.3v
2024-05-06 FRAM Gerber Files
2024-06-01 Update Errata - Z80Bus Headers
    Z80Bus Headers supplied in the full kit. Silkscreen misleading.
2024-06-08 Corrected the ROM version number
    The format needs to be:
    NNNN.XX AAYY.VV
    NNNN is the name of the ROM. In this case, it is MON3
    XX is the target hardware. In this case, it is the 1G
    AA is the initials of the Author or Publisher. In this case, it is Brian Chiha, BC
    YY is the year of release. In this case it is 24
    VV is the version number. In this case, it is 1.5
2024-08-24 Fitting the New Power Switch
2025-02-11 Add PATA TEC-Deck and 3D Case
    [BOM.csv, TEC-1G_Box_Full.stl, TEC-1G_Box_Half.stl]
2025-02-21 Schematic v1.2
2025-02-21 TEC-1G Schematic v1.21
2025-11-18 Schematic and Gerbers
2026-02-09 v1.5 of the PCB
2026-02-09 Gerber backups
2026-04-15 KiCAD Design Files
    *** UNFINISHED ***
    Still needs 3 traces routed. Updates to come.
    [TMS9918.kicad_pcb, TMS9918.kicad_sch]
2026-06-17 Add readme.md for sample code and demos
